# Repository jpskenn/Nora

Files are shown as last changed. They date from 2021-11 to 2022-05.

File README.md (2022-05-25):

# Nora（ノラ）

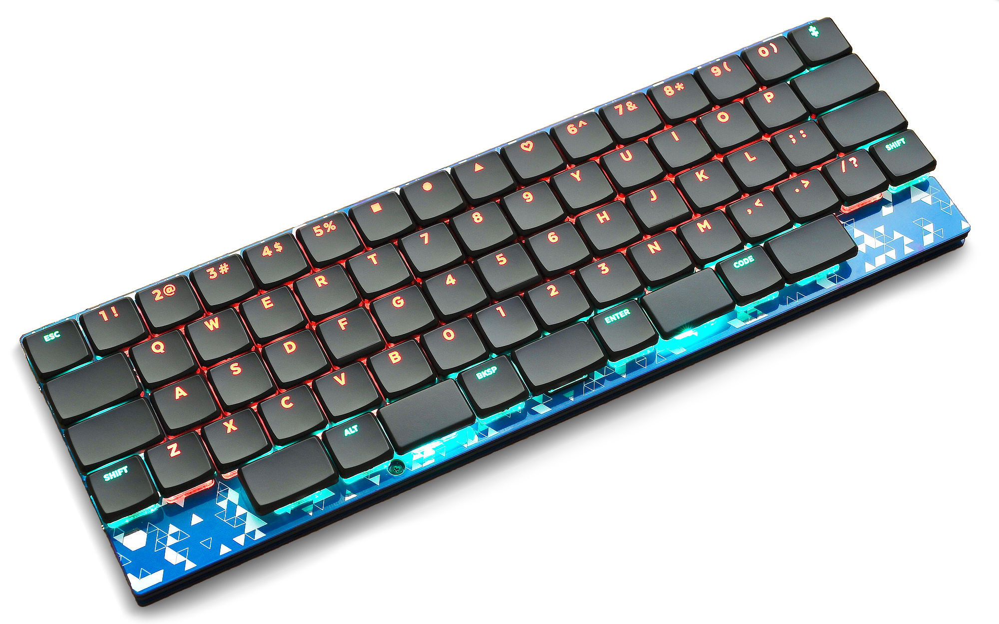
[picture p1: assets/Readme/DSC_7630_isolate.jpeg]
Nora Keyboard


Nora（ノラ）は、Choc v1 ロープロファイルスイッチを使用する、狭ピッチの一体型キーボードです。  
姉妹機[Jones（ジョーンズ）](https://github.com/jpskenn/Jones)と同様の、2行目と3行目にずれのない左右対称の配列が特徴です。  
専用のボトムプレートや、GH60型，Poker型のロープロファイルケースと組み合わせて使用できます。

名前の由来は、”狭ピッチのJonesキーボード”からの連想で…

``` text
狭ピッチのJones → ナロー・ジョーンズ → ノラ・ジョーンズ → ノラ

Narrow Jones --> Norah Jones --> Norah --> Nora
```

という具合の言葉遊びで、Nora（ノラ）に決まりました。

Nora is a narrow pitch keyboard with Choc v1 low profile switches.  
It has symmetrical gapless R2-R3 row, like [Jones](https://github.com/jpskenn/Jones).  
Original bottom plate and GH60/Poker compatible low profile cases are supported.

---

<!-- @import "[TOC]" {cmd="toc" depthFrom=2 depthTo=2 orderedList=false} -->

<!-- code_chunk_output -->

- [対象とするユーザー](#対象とするユーザー)
- [コンセプト](#コンセプト)
- [特徴](#特徴)
- [機能](#機能)
- [ビルドガイド](#ビルドガイド)
- [ビルド例](#ビルド例)
- [製作歴](#製作歴)

<!-- /code_chunk_output -->

---

## 対象とするユーザー

このNoraキーボードは、  
*”一般的なキーボードのキー配列に不満があり、より良いタイピングポジションを求めている方”*  
を対象に作られています。

特に、  
*”一般的なキーボードと違いすぎないキーボードを求めている方”*  
におすすめします。

## コンセプト

- 「Chocスイッチの狭ピッチを60%ケースに入れたら、1列増えて65%キーボードができちゃうのでは？」という思いつき。
- 一般的なキーピッチの19.05mmで打鍵がつらいのを、狭ピッチで楽にしたい。
- 「狭ピッチは浅いストロークの方が打鍵しやすい」という経験から、Chocスイッチを採用。
- MBKキーキャップって格好良いじゃんか。
- Jonesの横方向（行方向）のずれかたや、左右対称のアルファ部に満足している。
- 一般的なキーボードのレイアウトから大きく変えずに、打鍵しやすくする。
- キー数は60%くらいで、数字行がついているものが使いたい。
- GH60型のケースに対応させ、ケース設計をメイン作業に含めない。
- これくらいの狭ピッチなら、通常のキーボードと何ら変わらず打鍵できることを伝えたい。

## 特徴

### 狭ピッチ

Kailh Chocスイッチとそれに対応するキーキャップを使用することで、一般的なキーボードよりもキーピッチが狭くなっています。

60%キーボードのサイズに16列を配置するため、Choc用キーキャップのキーピッチ（たて17mm×よこ18mm）よりも横方向を少し狭く（たて17mm×よこ約17.86mm）しています。  
横方向のキーピッチは、MBKまたはそれ以下のサイズのChoc用キーキャップの使用を前提とした設計です。

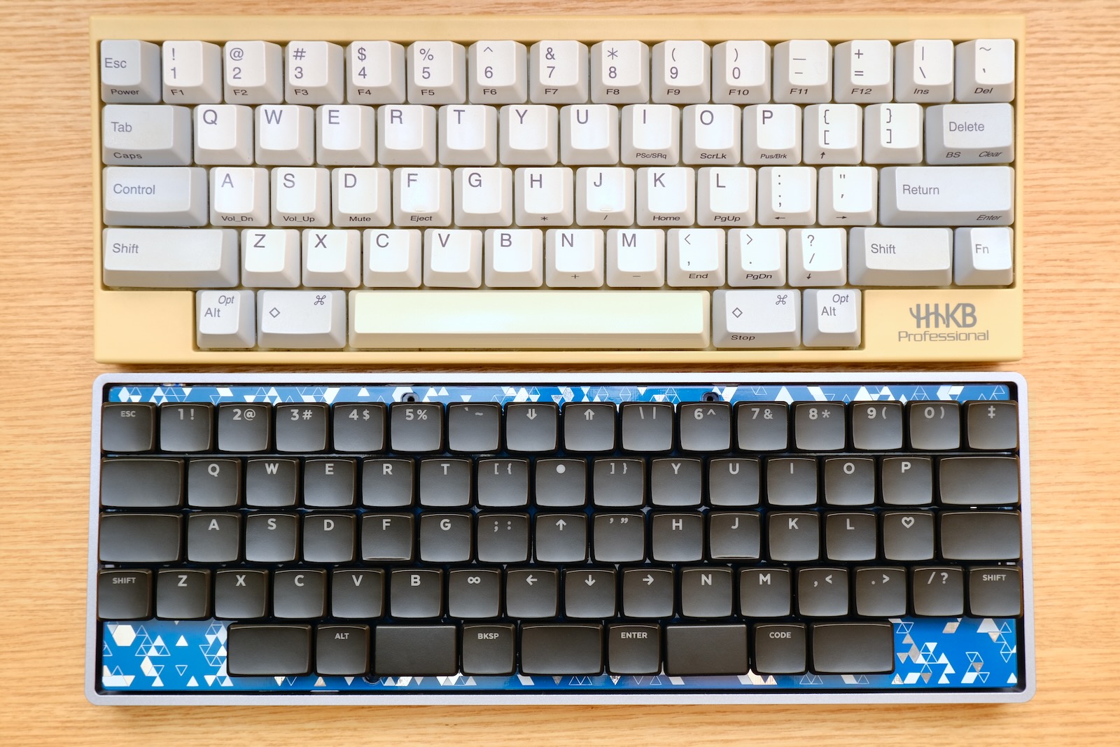
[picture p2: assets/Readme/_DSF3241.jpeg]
Comparison of key pitch
  
キーピッチの比較  
上：一般的なキーピッチの60%キーボード、HHKB Professional。5行15列。  
下：狭ピッチ設計のNora。5行**16列**（1列多い）。

### 左右対称のキーレイアウト

キーレイアウトは[Jones](https://github.com/jpskenn/Jones)のレイアウトを元に設計しており、2行目と3行目にずれのない左右対称のキーレイアウトです。  

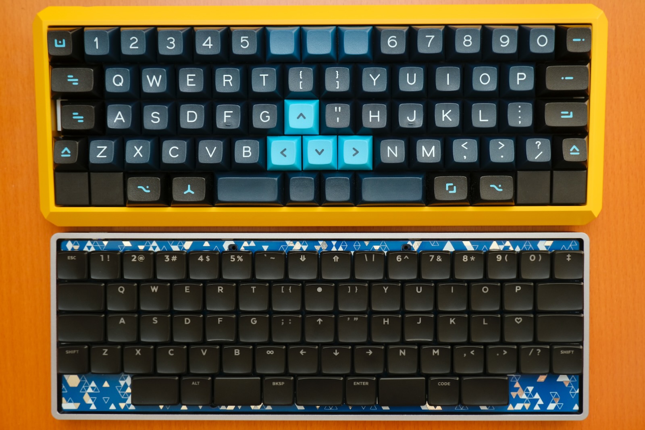
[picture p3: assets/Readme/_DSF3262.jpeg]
gapless R2-R3 row
  
Jones（上）とNora（下）。  
どちらも2行目と3行目にずれがなく、左右対称。

詳しくは次の項目を参照してください。

- [Jones#独自のずれ幅をもつ左右対象のアルファ部](https://github.com/jpskenn/Jones#独自のずれ幅をもつ左右対象のアルファ部)

### レイアウトのスタイル、バリエーション

狭ピッチの一体型キーボードというコンセプトを元に、ふたつのレイアウトスタイルを作成しました。

- Nora, Fearless Wings
- Nora, 1.8k

各スタイルの特徴は以下の通りです。

#### Nora, Fearless Wings

左右に大きく離れたアルファ部が特徴のレイアウトスタイルです。  
[Keyboard Layout Editor: Nora, Fearless Wings family](http://www.keyboard-layout-editor.com/#/gists/568990362f215776aa93e3b90064f241)

アルファ部を左右へ大きく離すことで打鍵時の肘・腕・手首・指先の位置を最適化し、快適な運指と、肩や腕への負担軽減を目指しています。  
手首をあまり持ち上げないスタイルでも快適に打鍵できるように、最下行の左右の端にはキーを配置せず、手のひらにキーが当たる不快感を無くしています。  
`Z`キーを外側へずらして、[SemiErgo](https://github.com/mtei/SemiErgo_Layout)のような完全に左右対称のレイアウトも構成できます。

キー配置とロータリーエンコーダの有無により、3つのバリエーションがあります。

- Fullレイアウト

    左右に離れたアルファ部の間を、すべて埋めたレイアウトです。  
    65〜70%キーボードに相当する71個のキーは、多くのキーを必要とする方に適しています。  
    中央部に記号キーやカーソルを配置したり、テンキーやマクロキーを配置したりできます。

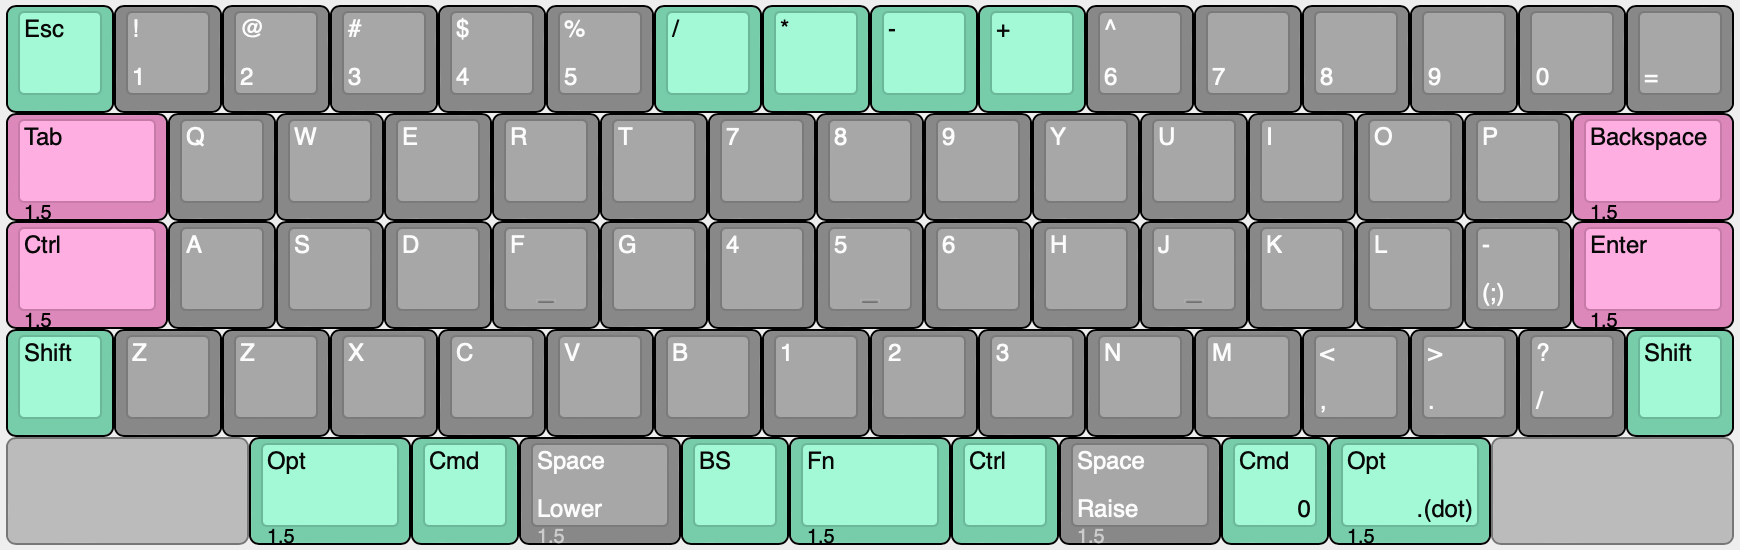
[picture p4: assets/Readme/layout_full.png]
Layout, Nora, Full
    

- FWレイアウト

    Fullレイアウトから中央部の7キーを取り除き、真ん中に隙間のあるレイアウトです。  
    60%キーボードに相当する64キーをもち、必要十分なキー数を確保しています。  
    ホームポジションから手を移動させず、レイヤー内のキーを打鍵するのが快適な方に適しています。  

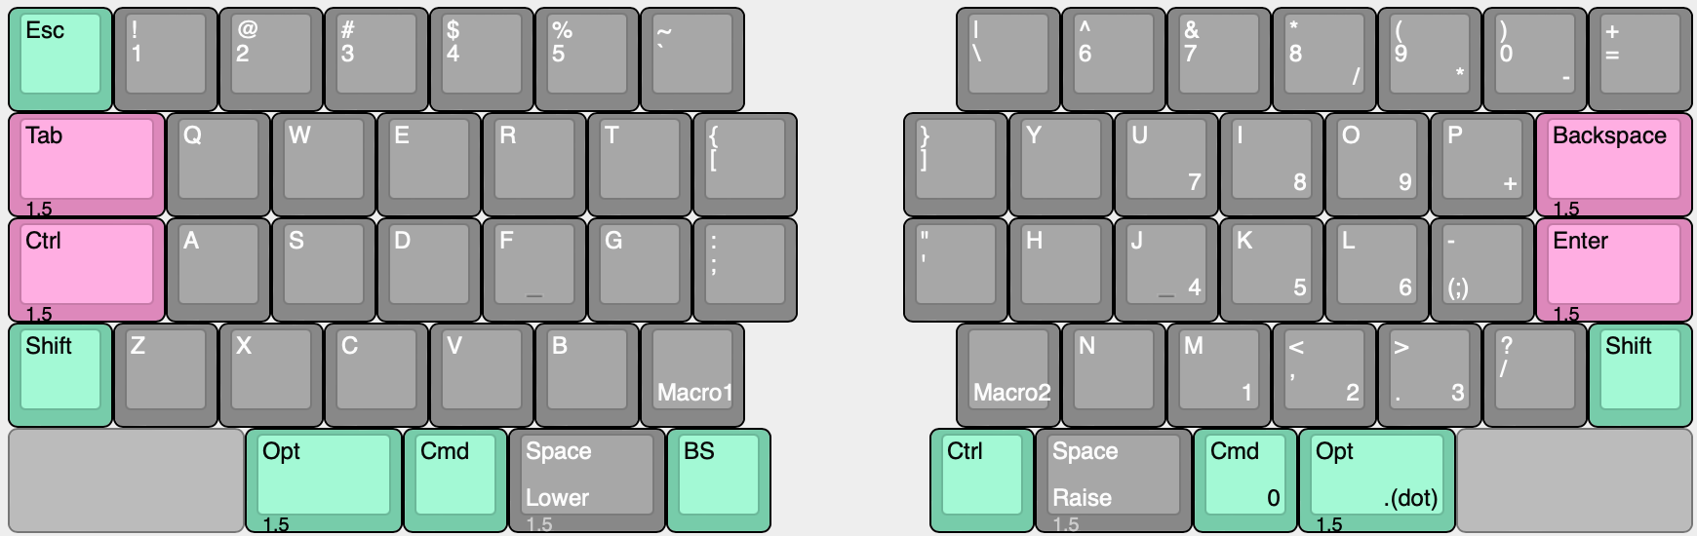
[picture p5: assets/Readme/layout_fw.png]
Layout, Nora, FW
    

- REレイアウト

    FWレイアウトの中央にロータリーエンコーダを配置したレイアウトです。  
    4行目の中央をFWレイアウトから2キー減らし、直径35ｍｍまでのノブに対応しています。

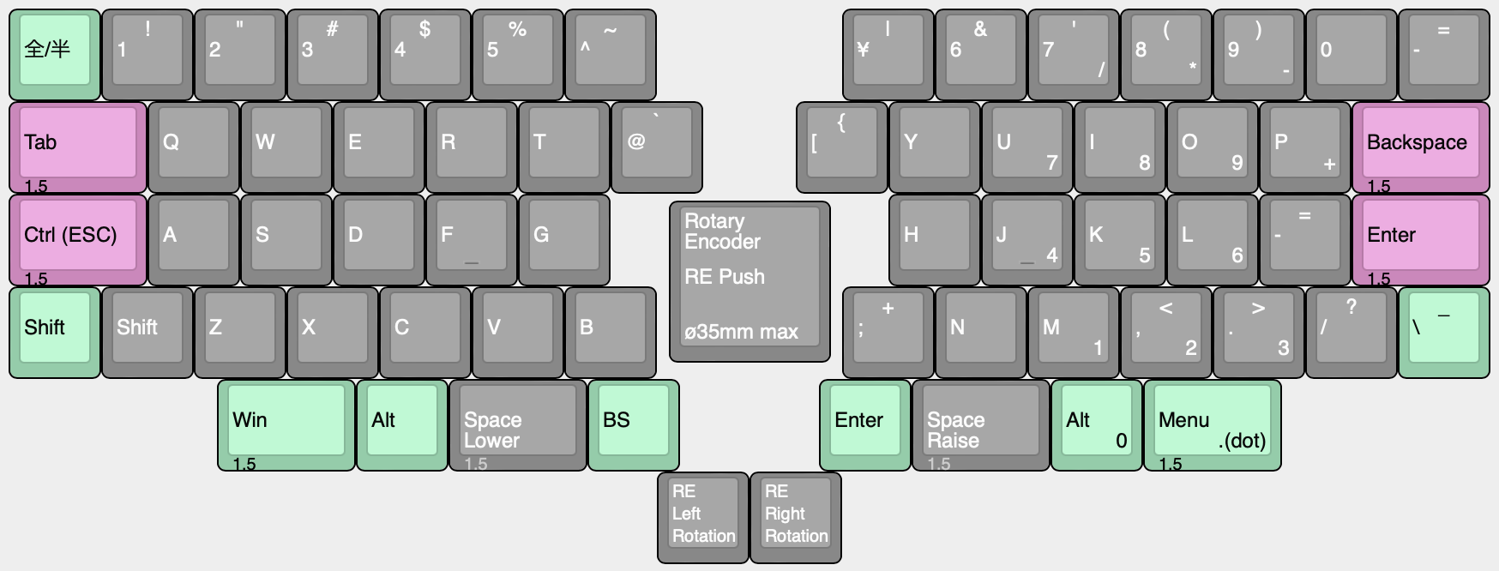
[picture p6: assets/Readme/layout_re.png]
Layout, Nora, RE
    

#### Nora, 1.8k

アルファ部の右側にテンキーを配置し、少し下へ飛びだしたカーソルキーが特徴のレイアウトスタイルです。  
[Keyboard Layout Editor: Nora](http://www.keyboard-layout-editor.com/#/gists/f8d08df6aa77dcdd6d3cb7350a545df7)

一般的なキーボードをコンパクトにまとめたようなキー配置になっています。  
キー数が多く、記号やカーソルなどを物理的に配置することができます。

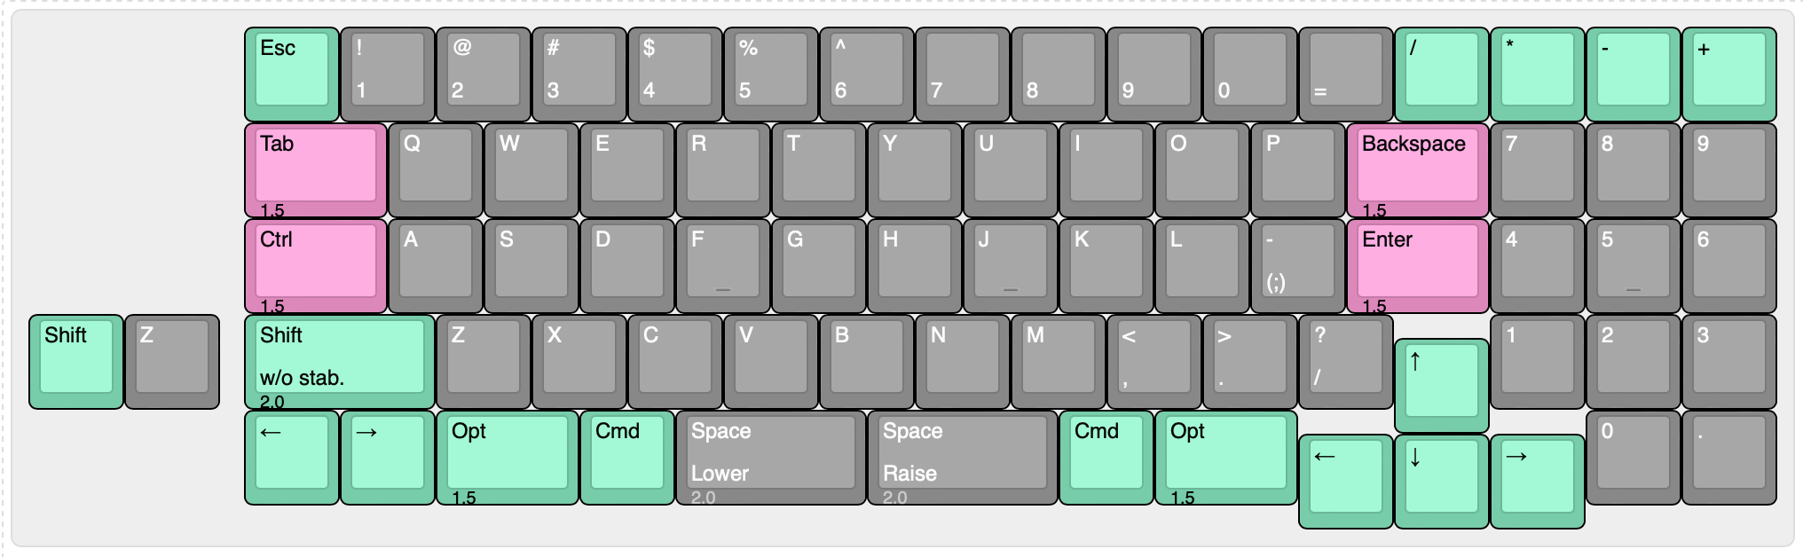
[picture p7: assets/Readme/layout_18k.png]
Layout, Nora, 1.8k


試作版でロードテストをおこなった結果、狭ピッチで左右の手が中央へ近づいて肩や腕、親指まわりが窮屈になり、長時間の使用には向かないことがわかりました。  
日常的に使用する上での快適さを満たせないため、1.8kは開発を停止しています。

## 機能

### QMKファームウェアによる動作

MCUにATmega32u4を採用し、[QMKファームウェア](https://github.com/qmk/qmk_firmware)によって動作します。

### RemapやVIAなどのキーマップ書き換えツールに対応

[Remap](https://remap-keys.app)や[VIA](https://caniusevia.com)などのキーマップ書き換えツールに対応しており、ファームウェアを書き換えることなく、キーの割り当てを変更することができます。  

### EEPROM搭載により、多くのレイヤーを使用可能

外部EEPROMを搭載したことで、RemapやVIA使用時にも多くのレイヤーを使用することができます。  
出荷時に書き込まれている初期ファームウェアでは、10個のレイヤーを使用可能です。  

### ケース

キット同梱のボトムプレートと組み合わせれば、ケースレスで使用できます。  
ケースを使用する場合に比べてキーボードの高さを低く抑えることができ、手首の負担軽減などに有効です。

また、GH60型やPoker型に互換性のある、ロープロファイルケースと組み合わせて使用することもできます。  
→[ビルド例](#ビルド例)  

### フルキーバックライトLED

レイヤーの状態を表示するインジケータや、イルミネーションとして使用できるキーバックライトLEDを、すべてのキーへ取り付けできます。

### Raspberry Pi PICOによる動作（実験的機能）

実験的機能として、Raspberry Pi PICOで動作させることができます。  
キーマトリクス、LED、I2Cに配線をつないであるので、DIYで楽しんでください。

[PRK Firmware](https://github.com/picoruby/prk_firmware)を使用して、キー入力とLEDの点灯を確認済みです。

## ビルドガイド

- 最新版
  - [Nora, Fearless Wings v.1(DN0032) ビルドガイド](./docs/BuildGuide_DN0032_JA.md)

- 過去版
  - [Nora, Fearless Wings DN0031 ビルドガイド](./docs/BuildGuide_DN0031_JA.md)
  - [Nora, Fearless Wings DN0030 ビルドガイド](./docs/BuildGuide_DN0030_JA.md)
  - [Nora, 1.8k v.0.1 ビルドガイド](./docs/BuildGuide_v.0.1_JA.md)

</details>

## ビルド例

| ビルド例 | 詳細 |
| --- | :-- |
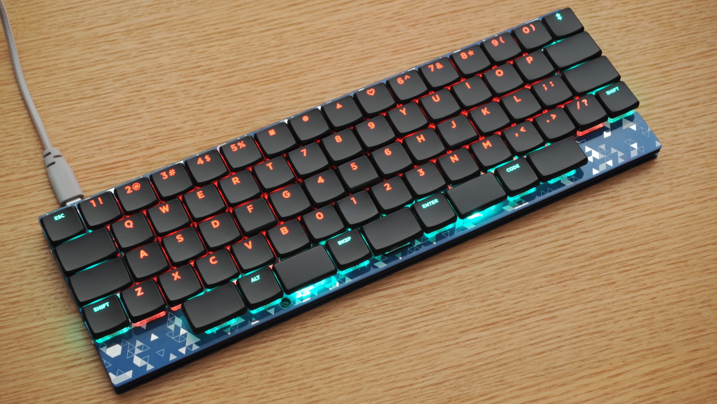
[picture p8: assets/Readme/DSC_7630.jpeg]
| [](./assets/Readme/DSC_7630.jpeg) | v.1(DN0032)<br>layout: Full<br>keycaps: MBK Legend‡ Glow<br>case: Bottom plate |
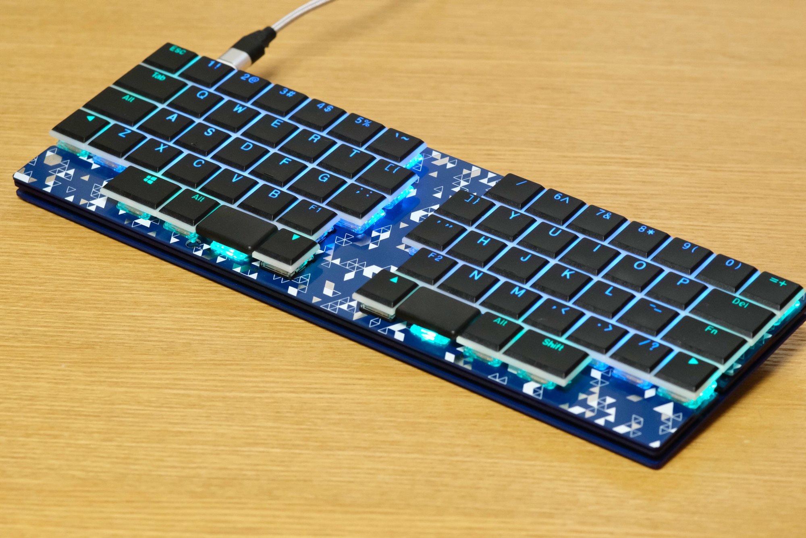
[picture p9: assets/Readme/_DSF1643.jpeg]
| [](./assets/Readme/_DSF1643.jpeg) | DN0031<br>layout: FW<br>keycaps: Kailh low profile + MBK<br>case: Bottom plate |
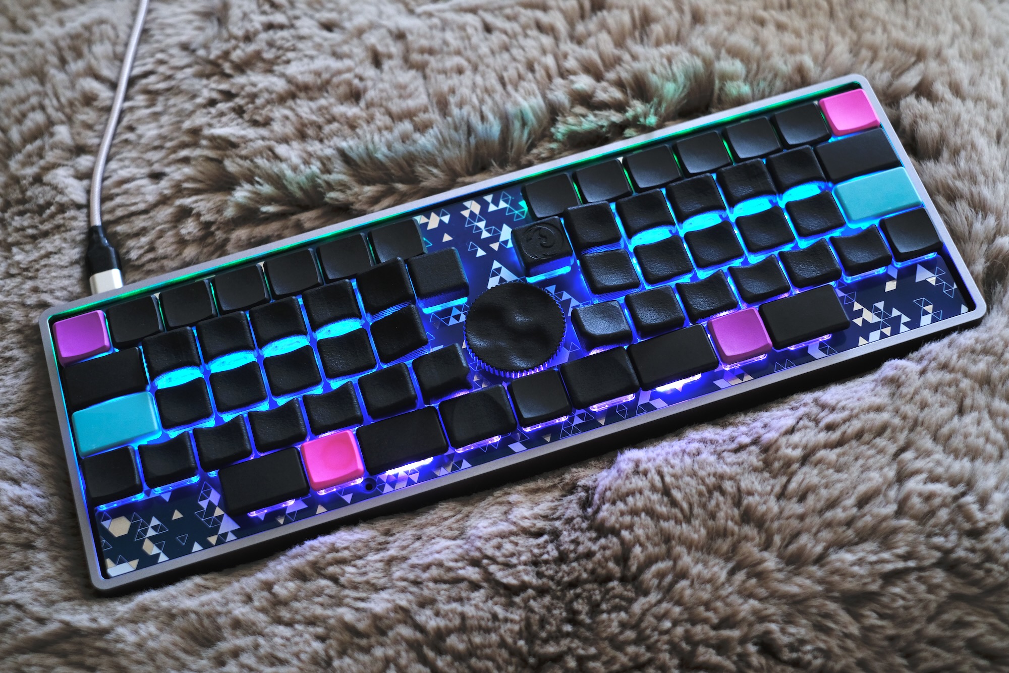
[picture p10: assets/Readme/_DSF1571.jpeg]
| [](./assets/Readme/_DSF1571.jpeg) | DN0031<br>layout: RE<br>keycaps: Gravity Keycaps + MBK<br>case: KBDfans 60% Aluminum Low Profile, Gray |
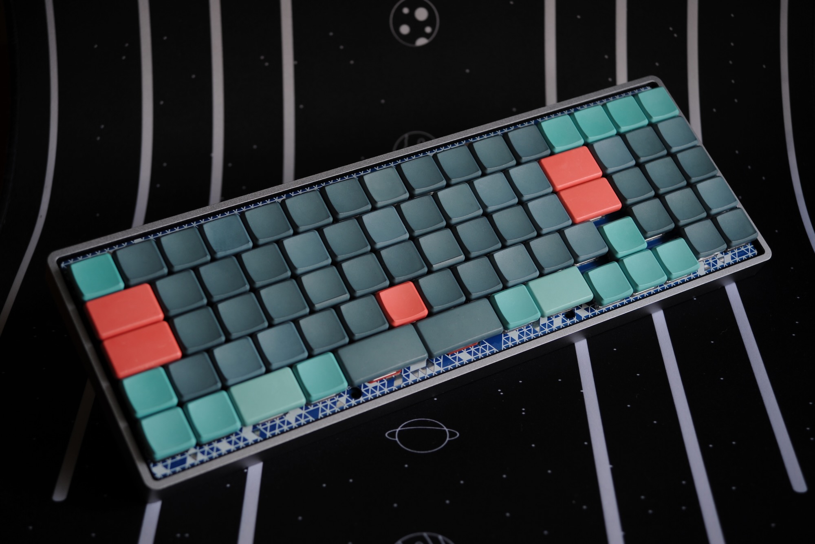
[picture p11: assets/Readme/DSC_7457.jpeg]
| [](./assets/Readme/DSC_7457.jpeg) | DN0020<br>layout: 1.8k<br>keycaps: MBK Colors & Self Dye<br>case: KBDfans 60% Aluminum Low Profile, Gray |
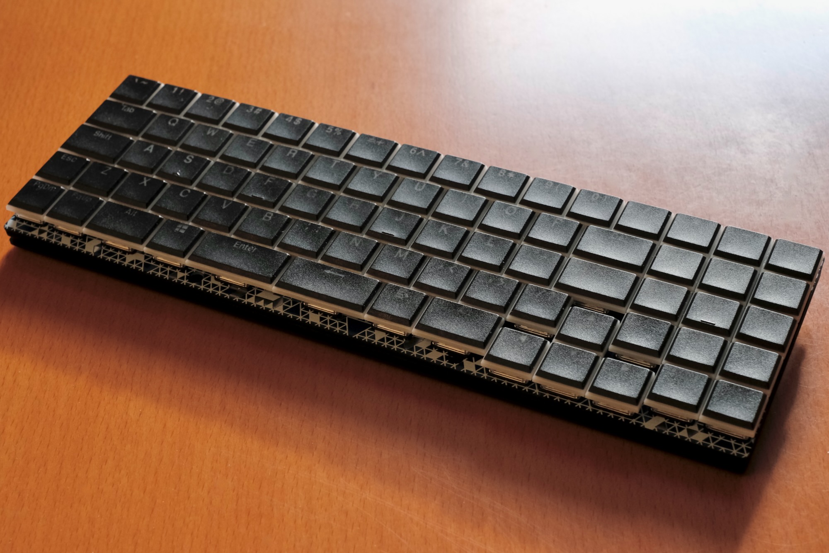
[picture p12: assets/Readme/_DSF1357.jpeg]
| [](./assets/Readme/_DSF1357.jpeg) | DN0010<br>layout: 1.8k<br>keycaps: Kailh low profile<br>case: Bottom plate |

## 製作歴

- Fearless Wings v.1(DN0032), 2022年3月中旬

    組み立てやすさを向上。  
    ロータリーエンコーダのノブサイズ拡大のため、REレイアウトの最下行中央のキーを削除。  
    細部を調整。  
    DN0031組み立てアンケートの内容を反映。

- Fearless Wings DN0031, 2022年1月下旬

    スペースキーより内側のキーに親指が届きやすいように、最下行を外側へ0.25u移動。  
    ロータリーエンコーダ付きのレイアウトを追加。  
    組み立てやすさを向上。
    少数頒布。

- Fearless Wings DN0030, 2022年1月上旬

    DN0020を元にレイアウトを変更。  
    全キーへLEDを配置。  
    Jonesとの共用ボトムプレートを、PICOの取り付けに対応する切り欠きをつけて更新。

- 1.8k DN0020, 2021年12月中旬

    1.8k v.0.1の試作結果を反映。  
    全キーをKailhソケットに変更。  
    現在のところ基板設計のみ。未製造。

- 1.8k v.0.1, 2021年12月上旬

    試作1号機、完成。

- 1.8k v.0, 2021年11月上旬

    60%ケースにChocスイッチを配置して、65%キーボードにするアイデアを思いつく。

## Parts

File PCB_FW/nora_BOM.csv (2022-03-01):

Comment | Designator | Footprint | LCSC
10uF | C1 | Capacitor_SMD:C_0805_2012Metric_Pad1.18x1.45mm_HandSolder | C15850
22pF | C2,C3 | Capacitor_SMD:C_0805_2012Metric_Pad1.18x1.45mm_HandSolder | C1804
0.1uF | C4,C5,C7 | Capacitor_SMD:C_0805_2012Metric_Pad1.18x1.45mm_HandSolder | C49678
1uF | C6 | Capacitor_SMD:C_0805_2012Metric_Pad1.18x1.45mm_HandSolder | C28323
D_Small | D1,D2,D4,D5,D6,D7,D9,D11,D12,D13,D14,D15,D16,D17,D18,D19,D20,D21,D22,D23,D25,D26,D27,D28,D29,D30,D31,D32,D33,D35,D36,D37,D38,D39,D40,D41,D42,D43,D44,D45,D46,D47,D48,D49,D50,D51,D52,D53,D54,D55,D56,D57,D58,D59,D60,D61,D62,D63,D64,D65,D66,D67,D68,D70,D71,D72,D73,D75,D76,D77,D78,D99 | locallib:D_SOD-123-Pretty_No_Reference | C81598
PRTR5V0U2X | D10 | Package_TO_SOT_SMD:SOT-143 | C12333
Conn_01x01 | EXT_C0,EXT_R0,EXT_C1,EXT_R1,EXT_C2,EXT_R2,EXT_C3,EXT_R3,EXT_C4,EXT_R4,EXT_C5,EXT_R5,EXT_C6,EXT_R6,EXT_C7,EXT_R7,EXT_R8,EXT_R9 | TestPoint:TestPoint_THTPad_D1.5mm_Drill0.7mm
Conn_01x01 | Ext_AUDIO_PC6 | TestPoint:TestPoint_THTPad_D1.0mm_Drill0.5mm
500mA | F1 | Fuse:Fuse_1206_3216Metric_Pad1.42x1.75mm_HandSolder | C70076
MountingHole | H1,H2,H3 | MountingHole:MountingHole_2.2mm_M2
USB_C_Receptacle_USB2.0 | J1 | Connector_USB:USB_C_Receptacle_GCT_USB4085
Conn_01x04 | J2 | Connector_PinHeader_2.54mm:PinHeader_1x04_P2.54mm_Vertical
Conn_01x02 | J3,J4 | Connector_PinHeader_2.54mm:PinHeader_1x02_P2.54mm_Vertical
Conn_02x03_Odd_Even | J5 | Connector_PinHeader_2.54mm:PinHeader_2x03_P2.54mm_Vertical
SolderJumper_2_Open | JP1,JP2,JP4,JP5,JP6,JP7,JP8,JP9 | Jumper:SolderJumper-2_P1.3mm_Open_RoundedPad1.0x1.5mm
SolderJumper_3_Open | JP3 | Jumper:SolderJumper-3_P1.3mm_Open_RoundedPad1.0x1.5mm
SK6812MINI-E | L1,L2,L3,L4,L5,L6,L7,L10,L11,L12,L13,L14,L15,L16,L17,L18,L19,L20,L21,L22,L23,L25,L26,L27,L28,L29,L30,L31,L32,L33,L34,L35,L36,L37,L41,L42,L43,L44,L45,L46,L47,L48,L49,L50,L51,L52,L53,L56,L57,L58,L59,L60,L61,L62,L63,L64,L65,L66,L68,L69,L70,L71 | Jones.local:YS-SK6812MINI-E_middle_hole_with_small_pad
SK6812MINI-E | L8,L9,L24,L38,L39,L40,L54,L55,L67 | Jones.local:YS-SK6812MINI-E_middle_hole_with_small_pad_reserved
Speaker | LS1 | Buzzer_Beeper:Buzzer_Murata_PKMCS0909E4000-R1
5.1k | R1,R2 | Resistor_SMD:R_0805_2012Metric_Pad1.20x1.40mm_HandSolder | C27834
22 | R3,R4 | Resistor_SMD:R_0805_2012Metric_Pad1.20x1.40mm_HandSolder | C17561
10k | R5,R6 | Resistor_SMD:R_0805_2012Metric_Pad1.20x1.40mm_HandSolder | C17414
1k | R7 | Resistor_SMD:R_0805_2012Metric_Pad1.20x1.40mm_HandSolder | C17513
4.7k | R8,R9 | Resistor_SMD:R_0805_2012Metric_Pad1.20x1.40mm_HandSolder | C17673
RotaryEncoder_Switch | RE_42 | Rotary_Encoder:RotaryEncoder_Alps_EC11E-Switch_Vertical_H20mm
5.2x5.2mm | ResetSW1 | Button_Switch_SMD:SW_SPST_TL3342
ESC | SW_1 | Keebio-Parts:Kailh-PG1350-1u-MBK-WithKeyName-Socket-ForLeftEdge-1.8mm-hole-reflection
2 | SW_10 | Keebio-Parts:Kailh-PG1350-1u-MBK-WithKeyName-Socket-1.8mm-hole-reflection
Q | SW_11 | Keebio-Parts:Kailh-PG1350-1u-MBK-WithKeyName-Socket-1.8mm-hole-reflection
A | SW_12 | Keebio-Parts:Kailh-PG1350-1u-MBK-WithKeyName-Socket-1.8mm-hole-reflection
X | SW_13 | Keebio-Parts:Kailh-PG1350-1u-MBK-WithKeyName-Socket-1.8mm-hole-reflection
3 | SW_15 | Keebio-Parts:Kailh-PG1350-1u-MBK-WithKeyName-Socket-1.8mm-hole-reflection
W | SW_16 | Keebio-Parts:Kailh-PG1350-1u-MBK-WithKeyName-Socket-1.8mm-hole-reflection
S | SW_17 | Keebio-Parts:Kailh-PG1350-1u-MBK-WithKeyName-Socket-1.8mm-hole-reflection
C | SW_18 | Keebio-Parts:Kailh-PG1350-1u-MBK-WithKeyName-Socket-1.8mm-hole-reflection
LGUI 1.5u | SW_19 | Keebio-Parts:Kailh-PG1350-1.5u-MBK-WithKeyName-Socket-1.8mm-hole-reflection
4 | SW_20 | Keebio-Parts:Kailh-PG1350-1u-MBK-WithKeyName-Socket-1.8mm-hole-reflection
E | SW_21 | Keebio-Parts:Kailh-PG1350-1u-MBK-WithKeyName-Socket-1.8mm-hole-reflection
D | SW_22 | Keebio-Parts:Kailh-PG1350-1u-MBK-WithKeyName-Socket-1.8mm-hole-reflection
V | SW_23 | Keebio-Parts:Kailh-PG1350-1u-MBK-WithKeyName-Socket-1.8mm-hole-reflection
LALT | SW_24 | Keebio-Parts:Kailh-PG1350-1u-MBK-WithKeyName-Socket-1.8mm-hole-reflection
5 | SW_25 | Keebio-Parts:Kailh-PG1350-1u-MBK-WithKeyName-Socket-1.8mm-hole-reflection
R | SW_26 | Keebio-Parts:Kailh-PG1350-1u-MBK-WithKeyName-Socket-1.8mm-hole-reflection
F | SW_27 | Keebio-Parts:Kailh-PG1350-1u-MBK-WithKeyName-Socket-1.8mm-hole-reflection
B | SW_28 | Keebio-Parts:Kailh-PG1350-1u-MBK-WithKeyName-Socket-1.8mm-hole-reflection
LSPC 1.5u | SW_29 | Keebio-Parts:Kailh-PG1350-1.5u-MBK-WithKeyName-Socket-1.8mm-hole-reflection
LSFT | SW_3 | Keebio-Parts:Kailh-PG1350-1u-MBK-WithKeyName-Socket-ForLeftEdge-1.8mm-hole-reflection
`~ | SW_30 | Keebio-Parts:Kailh-PG1350-1u-MBK-WithKeyName-Socket-1.8mm-hole-reflection
T | SW_31 | Keebio-Parts:Kailh-PG1350-1u-MBK-WithKeyName-Socket-1.8mm-hole-reflection
G | SW_32 | Keebio-Parts:Kailh-PG1350-1u-MBK-WithKeyName-Socket-1.8mm-hole-reflection
L-Macro | SW_33 | Keebio-Parts:Kailh-PG1350-1u-MBK-WithKeyName-Socket-1.8mm-hole-reflection
R1L | SW_35 | Keebio-Parts:Kailh-PG1350-1u-MBK-WithKeyName-Socket-1.8mm-hole-reflection-frame-only
[{ | SW_36 | Keebio-Parts:Kailh-PG1350-1u-MBK-WithKeyName-Socket-1.8mm-hole-reflection
;: | SW_37 | Keebio-Parts:Kailh-PG1350-1u-MBK-WithKeyName-Socket-1.8mm-hole-reflection-cross-paint
R4L | SW_38 | Keebio-Parts:Kailh-PG1350-1u-MBK-WithKeyName-Socket-1.8mm-hole-reflection-frame-only
Center L | SW_39 | Keebio-Parts:Kailh-PG1350-1u-MBK-WithKeyName-Socket-1.8mm-hole-reflection
R1R | SW_40 | Keebio-Parts:Kailh-PG1350-1u-MBK-WithKeyName-Socket-1.8mm-hole-reflection-frame-only
R2C | SW_41 | Keebio-Parts:Kailh-PG1350-1u-MBK-WithKeyName-Socket-1.8mm-hole-reflection-frame-only
R3C | SW_42 | Keebio-Parts:Kailh-PG1350-1u-MBK-WithKeyName-Socket-1.8mm-hole-reflection-frame-only
R4R | SW_43 | Keebio-Parts:Kailh-PG1350-1u-MBK-WithKeyName-Socket-1.8mm-hole-reflection-frame-only
Center 1.5u | SW_44 | Keebio-Parts:Kailh-PG1350-1.5u-MBK-WithKeyName-Socket-1.8mm-hole-reflection-frame-only
\| | SW_45 | Keebio-Parts:Kailh-PG1350-1u-MBK-WithKeyName-Socket-1.8mm-hole-reflection
]} | SW_46 | Keebio-Parts:Kailh-PG1350-1u-MBK-WithKeyName-Socket-1.8mm-hole-reflection
'",SW_47" | Keebio-Parts:Kailh-PG1350-1u-MBK-WithKeyName-Socket-1.8mm-hole-reflection-cross-paint
R-Macro | SW_48 | Keebio-Parts:Kailh-PG1350-1u-MBK-WithKeyName-Socket-1.8mm-hole-reflection
Center R | SW_49 | Keebio-Parts:Kailh-PG1350-1u-MBK-WithKeyName-Socket-1.8mm-hole-reflection
1 | SW_5 | Keebio-Parts:Kailh-PG1350-1u-MBK-WithKeyName-Socket-1.8mm-hole-reflection
6 | SW_50 | Keebio-Parts:Kailh-PG1350-1u-MBK-WithKeyName-Socket-1.8mm-hole-reflection
Y | SW_51 | Keebio-Parts:Kailh-PG1350-1u-MBK-WithKeyName-Socket-1.8mm-hole-reflection
H | SW_52 | Keebio-Parts:Kailh-PG1350-1u-MBK-WithKeyName-Socket-1.8mm-hole-reflection
N | SW_53 | Keebio-Parts:Kailh-PG1350-1u-MBK-WithKeyName-Socket-1.8mm-hole-reflection
RSPC 1.5u | SW_54 | Keebio-Parts:Kailh-PG1350-1.5u-MBK-WithKeyName-Socket-1.8mm-hole-reflection
7 | SW_55 | Keebio-Parts:Kailh-PG1350-1u-MBK-WithKeyName-Socket-1.8mm-hole-reflection
U | SW_56 | Keebio-Parts:Kailh-PG1350-1u-MBK-WithKeyName-Socket-1.8mm-hole-reflection
J | SW_57 | Keebio-Parts:Kailh-PG1350-1u-MBK-WithKeyName-Socket-1.8mm-hole-reflection
M | SW_58 | Keebio-Parts:Kailh-PG1350-1u-MBK-WithKeyName-Socket-1.8mm-hole-reflection
RALT | SW_59 | Keebio-Parts:Kailh-PG1350-1u-MBK-WithKeyName-Socket-1.8mm-hole-reflection
TAB 1.5u | SW_6 | Keebio-Parts:Kailh-PG1350-1.5u-MBK-WithKeyName-Socket-1.8mm-hole-reflection
8 | SW_60 | Keebio-Parts:Kailh-PG1350-1u-MBK-WithKeyName-Socket-1.8mm-hole-reflection
I | SW_61 | Keebio-Parts:Kailh-PG1350-1u-MBK-WithKeyName-Socket-1.8mm-hole-reflection
K | SW_62 | Keebio-Parts:Kailh-PG1350-1u-MBK-WithKeyName-Socket-1.8mm-hole-reflection
< | SW_63 | Keebio-Parts:Kailh-PG1350-1u-MBK-WithKeyName-Socket-1.8mm-hole-reflection
RGUI 1.5u | SW_64 | Keebio-Parts:Kailh-PG1350-1.5u-MBK-WithKeyName-Socket-1.8mm-hole-reflection
9 | SW_65 | Keebio-Parts:Kailh-PG1350-1u-MBK-WithKeyName-Socket-1.8mm-hole-reflection
O | SW_66 | Keebio-Parts:Kailh-PG1350-1u-MBK-WithKeyName-Socket-1.8mm-hole-reflection
L | SW_67 | Keebio-Parts:Kailh-PG1350-1u-MBK-WithKeyName-Socket-1.8mm-hole-reflection
> | SW_68 | Keebio-Parts:Kailh-PG1350-1u-MBK-WithKeyName-Socket-1.8mm-hole-reflection
LCTL 1.5u | SW_7 | Keebio-Parts:Kailh-PG1350-1.5u-MBK-WithKeyName-Socket-1.8mm-hole-reflection
0 | SW_70 | Keebio-Parts:Kailh-PG1350-1u-MBK-WithKeyName-Socket-1.8mm-hole-reflection
P | SW_71 | Keebio-Parts:Kailh-PG1350-1u-MBK-WithKeyName-Socket-1.8mm-hole-reflection
- | SW_72 | Keebio-Parts:Kailh-PG1350-1u-MBK-WithKeyName-Socket-1.8mm-hole-reflection
/ | SW_73 | Keebio-Parts:Kailh-PG1350-1u-MBK-WithKeyName-Socket-1.8mm-hole-reflection
= | SW_75 | Keebio-Parts:Kailh-PG1350-1u-MBK-WithKeyName-Socket-1.8mm-hole-reflection
BS 1.5u | SW_76 | Keebio-Parts:Kailh-PG1350-1.5u-MBK-WithKeyName-Socket-1.8mm-hole-reflection
Enter 1.5u | SW_77 | Keebio-Parts:Kailh-PG1350-1.5u-MBK-WithKeyName-Socket-1.8mm-hole-reflection
RSFT | SW_78 | Keebio-Parts:Kailh-PG1350-1u-MBK-WithKeyName-Socket-1.8mm-hole-reflection
Z | SW_8 | Keebio-Parts:Kailh-PG1350-1u-MBK-WithKeyName-Socket-1.8mm-hole-reflection
ATmega32U4-MU | U1 | Package_DFN_QFN:QFN-44-1EP_7x7mm_P0.5mm_EP5.15x5.15mm | C112161
24LC64 | U2 | Package_SO:SO-8_3.9x4.9mm_P1.27mm | C79988
Pico | U4 | MCU_RaspberryPi_and_Boards:RPi_Pico_TH_no_NPTH_SWD_less_Silk_NoCrtYd
16MHz | Y1 | Crystal:Crystal_SMD_3225-4Pin_3.2x2.5mm_HandSoldering | C13738

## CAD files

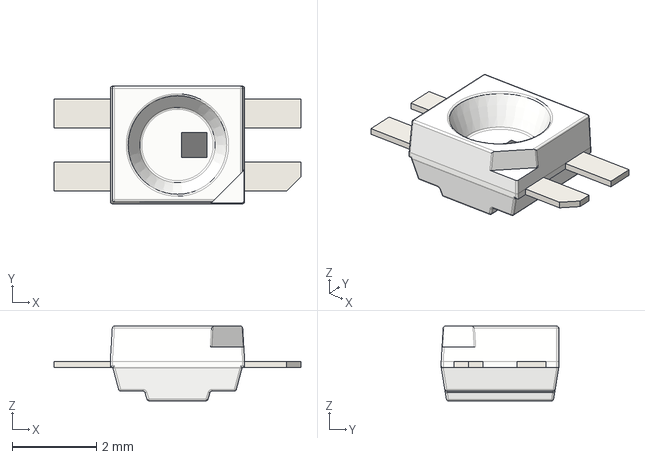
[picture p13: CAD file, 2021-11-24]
PCB_FW/lib_LED/LED_SK6812MINI-E.step
5.88 x 2.80 x 1.78 mm

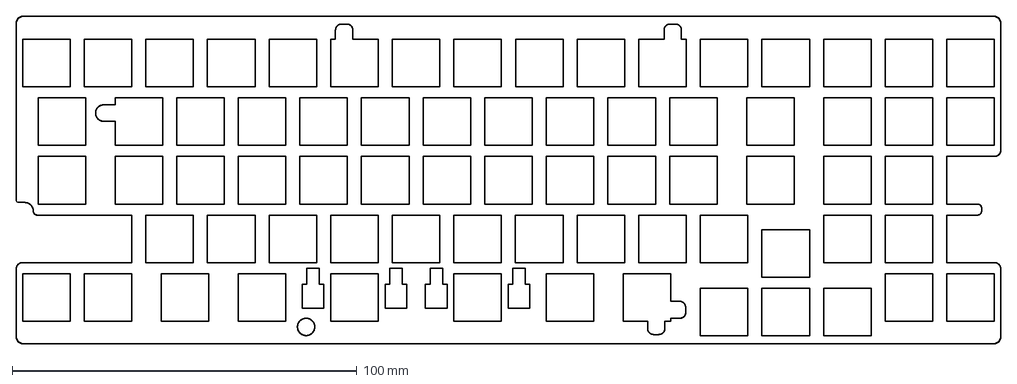
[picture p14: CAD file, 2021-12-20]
Plate/plate.dxf
285.4 x 94.9 mm

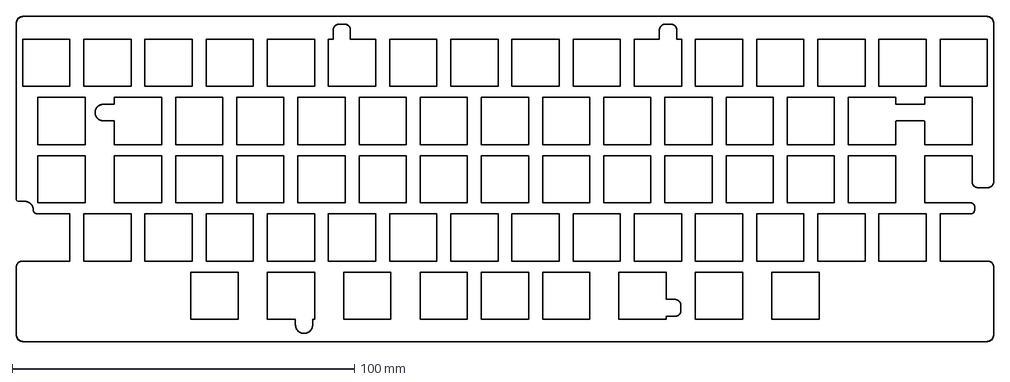
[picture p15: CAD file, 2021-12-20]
Plate_FW/plate.dxf
285.4 x 94.9 mm

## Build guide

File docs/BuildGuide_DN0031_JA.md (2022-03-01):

# ”Nora, Fearless Wings (DN0031) 試作版”ビルドガイド

購入していただいた方、リポジトリから製造していただいた方、その他の皆様、Noraに興味を持っていただきありがとうございます。

このドキュメントは、”Nora, Fearless Wings (DN0031) 試作版”を組み立てるためのビルドガイドです。  
以下に示す、ふたつレイアウトの組み立て方法について説明します。  
参考： [Nora, Kyboard Layout Editor](http://www.keyboard-layout-editor.com/#/gists/568990362f215776aa93e3b90064f241)

- `FWレイアウト`

  ロータリーエンコーダを配置せず、中央部分に隙間のあるレイアウト
  
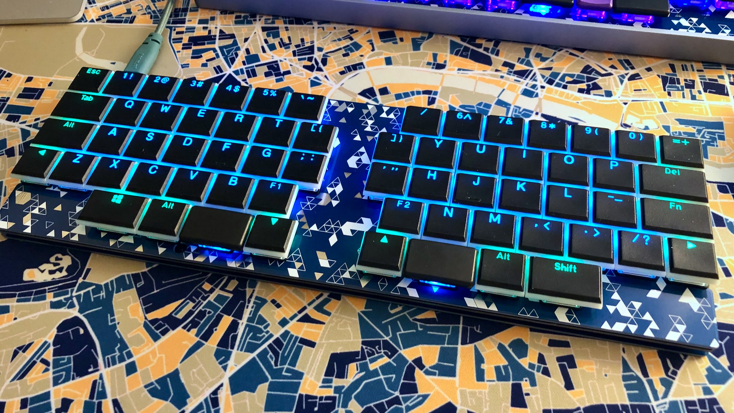
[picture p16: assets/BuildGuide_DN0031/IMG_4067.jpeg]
FWレイアウト
    
  Keycaps: Kailhロープロファイルキーキャップ  
  Case: 専用ボトムプレート

- `REレイアウト`

  中央にロータリーエンコーダを配置したレイアウト
  
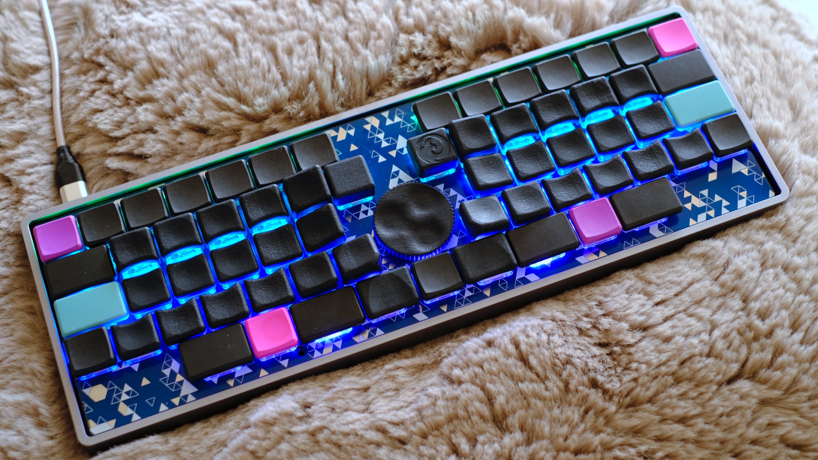
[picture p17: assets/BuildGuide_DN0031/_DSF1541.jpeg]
REレイアウト
    
  Keycaps: Gravity Keycaps + MBK  
  Case: KBDfans 60% ALUMINUM LOW PROFILE CASE, Gray  
  Rotary Encoder: ALPS EC12E2440301（貫通軸タイプ）  
  Knob: Daily Craft Keyboard ロープロ FLAT 33mm

Noraのコンセプトや特徴、ビルド例などについては、[README](https://github.com/jpskenn/Nora/blob/main/README.md)をご覧ください。

ビルドガイド全体に目を通して作業手順を把握しておくとミスの防止につながりますので、ぜひ、一度お読みになってから組み立て作業を始めてください。

作業手順をしっかりと確認しながら組み立てたい方は、

<details>
<summary>《詳しい説明》</summary>

ここに追加の説明を表示します。
</details>

と書かれたところをクリックすると、追加の説明が表示されます。

---

## 目次

<!-- @import "[TOC]" {cmd="toc" depthFrom=2 depthTo=3 orderedList=false} -->

<!-- code_chunk_output -->

- [目次](#目次)
- [Nora, Fearless Wings (DN0031)の特徴, 機能](#nora-fearless-wings-dn0031の特徴-機能)
- [注意事項、制限など](#注意事項-制限など)
- [試作版，試作版キットに関する注意事項](#試作版試作版キットに関する注意事項)
- [部品リスト](#部品リスト)
  - [キット内容](#キット内容)
  - [別途用意が必要な部品](#別途用意が必要な部品)
  - [オプション部品](#オプション部品)
- [組み立てに必要な工具](#組み立てに必要な工具)
- [組み立て前の確認](#組み立て前の確認)
  - [同梱物の確認](#同梱物の確認)
  - [接続の確認](#接続の確認)
  - [ソケット用パッドの確認](#ソケット用パッドの確認)
- [組み立て手順](#組み立て手順)
  - [組み立てるレイアウトを決める](#組み立てるレイアウトを決める)
  - [（該当者のみ）`REレイアウト`用ファームウェアへの書き換え](#該当者のみreレイアウト用ファームウェアへの書き換え)
  - [（オプション）基板、スイッチプレート、ボトムプレートの側面を塗る](#オプション基板-スイッチプレート-ボトムプレートの側面を塗る)
  - [（オプション）LEDを取り付ける](#オプションledを取り付ける)
  - [Kailh Choc用ソケットを取り付ける](#kailh-choc用ソケットを取り付ける)
  - [（該当者のみ）ロータリーエンコーダを取り付ける](#該当者のみロータリーエンコーダを取り付ける)
  - [スイッチプレートにスペーサーシートを貼り付ける](#スイッチプレートにスペーサーシートを貼り付ける)
  - [スイッチとスイッチプレートを基板へ取り付ける](#スイッチとスイッチプレートを基板へ取り付ける)
  - [スイッチの動作確認をおこなう](#スイッチの動作確認をおこなう)
  - [基板をケース、またはボトムプレートへ取り付ける](#基板をケース-またはボトムプレートへ取り付ける)
  - [スイッチの最終動作確認をおこなう](#スイッチの最終動作確認をおこなう)
  - [仕上げ](#仕上げ)
- [参考](#参考)
  - [打鍵感向上：ケース内部の制振と静音化](#打鍵感向上ケース内部の制振と静音化)
  - [トラブル対応：正常に入力できないスイッチの原因調査](#トラブル対応正常に入力できないスイッチの原因調査)
  - [トラブル対応：LEDの取り付け不良調査](#トラブル対応ledの取り付け不良調査)
  - [資料：ファームウェアの書き込み方法](#資料ファームウェアの書き込み方法)
  - [資料：初期ファームウェアの機能と設定値](#資料初期ファームウェアの機能と設定値)
  - [資料：EEPROMを消去して、初期状態に戻す方法](#資料eepromを消去して-初期状態に戻す方法)
  - [資料：Nora, Fearless Wings (DN0031)関連ファイル](#資料nora-fearless-wings-dn0031関連ファイル)
  - [資料：Raspberry Pi PICOによる動作（実験的機能）](#資料raspberry-pi-picoによる動作実験的機能)
- [サービスマニュアル](#サービスマニュアル)
  - [パーツリスト](#パーツリスト)
  - [基板セットアップ](#基板セットアップ)

<!-- /code_chunk_output -->

---

## Nora, Fearless Wings (DN0031)の特徴, 機能

- 狭ピッチ
- Jonesゆずりのキーレイアウト
- 左右に離れたアルファ部
- Choc v1スイッチと、MBK以下のサイズのキーキャップに合わせた専用設計
- RemapやVIAなどのキーマップ書き換えツールに対応
- 外部EEPROM（8KB）を搭載し、十分な数のレイヤーを使用できる
- 専用ボトムプレート以外にも、GH60型，Poker型のロープロファイルケースに取り付けできる
- ファームウェア書き込み済み  
  試作版では、`REレイアウト`を使用する場合はファームウェアの書き換えが必要です。
- 細かな部品を実装済み
- オプションとして、以下のハードウェア機能を使用可能
  - レイヤーインジケータ／イルミネーションLED（全キー）
  - Raspberry Pi PICOによる動作（実験的機能）

## 注意事項、制限など

- キーキャップ

  MBK以下のサイズのキーキャップに合わせて設計されており、Choc用のキーピッチよりも横方向がほんの少し狭くなっています。  
  17 × 17.8594mm（[基板上の寸法図](../assets/BuildGuide_DN0031/PCB_key_pitch.png)）

  - 取り付け確認済みキーキャップ

    - MBK

    - MCC

    - Gravity Keycaps

    - Kailh製のロープロファイルキーキャップ（※注意）  

      ※注意  
      Kailh製のロープロファイルキーキャップは、MBKなどに比べてキーの寸法が少し大きいため、隣同士のキーが当たる場合があります。  
      ソケットを傾かないように取り付けたり、キーキャップの成形バリを取り除いたり、干渉する箇所を少し削る必要があるかもしれません。  

  - 取り付けできないキーキャップ

    - WRK

      MXスイッチ用のキーピッチ（19.05 × 19.05mm）のため

- スイッチの取り付け

  最下行の親指部分、左右のスペースキーとして使用するスイッチは、上下逆向きに取り付けます。  
  キーキャップは特に問題なく取り付けることができます。  
  透過タイプのキーキャップを使用する場合は、LEDも上下逆向きに取り付けるため、光がほとんど透過しません。

  スイッチの手前側が眩しく感じられる場合は、スイッチのLED穴側面にマスキングテープなどを貼るなどして減光してください。

- スイッチの加工

  `FWレイアウト`をGH60型，Poker型ケースへ取り付ける場合は、ケース中央のネジ穴に重なるスイッチの足を加工（切断）して取り付けます。

- ソケットの取り付け

  1行目と4行目の左端のソケット2個は、ソケットの端子部分が基板から約0.5mm飛び出した状態で取り付けます。

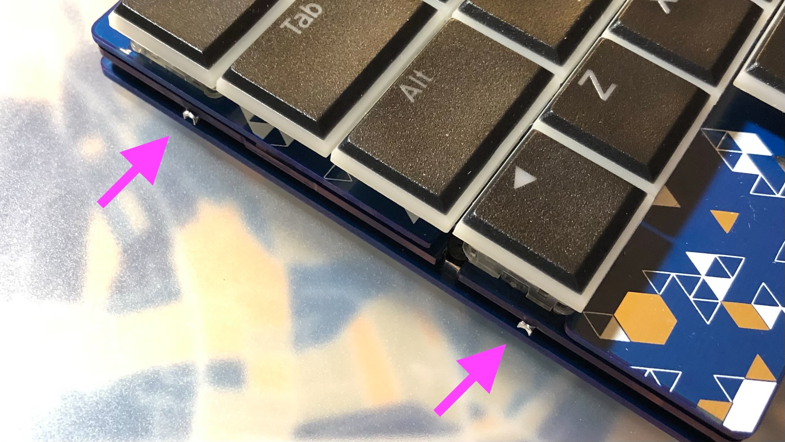
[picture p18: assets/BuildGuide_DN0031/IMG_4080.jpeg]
飛び出したソケット端子
  

  GH60型，Poker型のロープロファイルケースへの取り付けなども含め、実用上の問題がないことを確認していますが、怪我などしないようご留意ください。

- GH60型，Poker型のロープロファイルケースへの取り付け

  ケースの構造によっては、取り付けが難しかったり取り付けできない場合があるかもしれません。  
  ここに記載していないケースへの取り付けの成功／失敗の報告を、随時募集しています。

  取り付け確認済みのケースは次の通りです。  
  - [KBDfans 60% ALUMINUM LOW PROFILE CASE](https://kbdfans.com/collections/60-layout-case/products/customized-gh60-aluminum-case)

  ”TOFU”や”60%プラスチックケース”などのハイプロファイルタイプのケースにも取り付けできますが、キーキャップの天面がケースのフレームよりも低くなるため、実用に向きません。  
  よって、取り付けの対象外としています。  
  参考：[TOFUケースへの装着例](https://twitter.com/jpskenn/status/1466729696713142277)

## 試作版，試作版キットに関する注意事項

- ファームウェア

  試作版の提供形態（`FWレイアウト`と`REレイアアウト`の両方のスイッチプレートを同梱し、どちらでも製作できるキット内容）の都合上、`REレイアウト`を使用する場合はファームウェアを書き換える必要があります。  
  正式版では、`FWレイアウト`と`REレイアアウト`をそれぞれ別のキットとして提供する予定で、その際はファームウェアの書き換えは不要となります。

  ビルド済みのファームウェアを用意していますので、[QMK Toolbox](https://github.com/qmk/qmk_toolbox)などを使用して、書き換えてください。  
  詳しくは、組み立て手順の[（該当者のみ）`REレイアウト`用ファームウェアへの書き換え](#該当者のみreレイアウト用ファームウェアへの書き換え)をご覧ください。

## 部品リスト

このキットを組み立てるためには、”キット内容”に加え、”別途用意が必要な部品”が必要です。  
好みに合わせて、必要な数をお買い求めください。

”オプション部品”は、使いたい機能などに応じて用意してください。  

部品の購入先は、Self-Made Keyboards in Japanの[ショップリスト](https://scrapbox.io/self-made-kbds-ja/ショップリスト)などを参考にしてください。

### キット内容

| 部品名 | 個数 | 備考 |
| ----- | :-----: | ----- |
| ご案内リーフレット | 1 | |
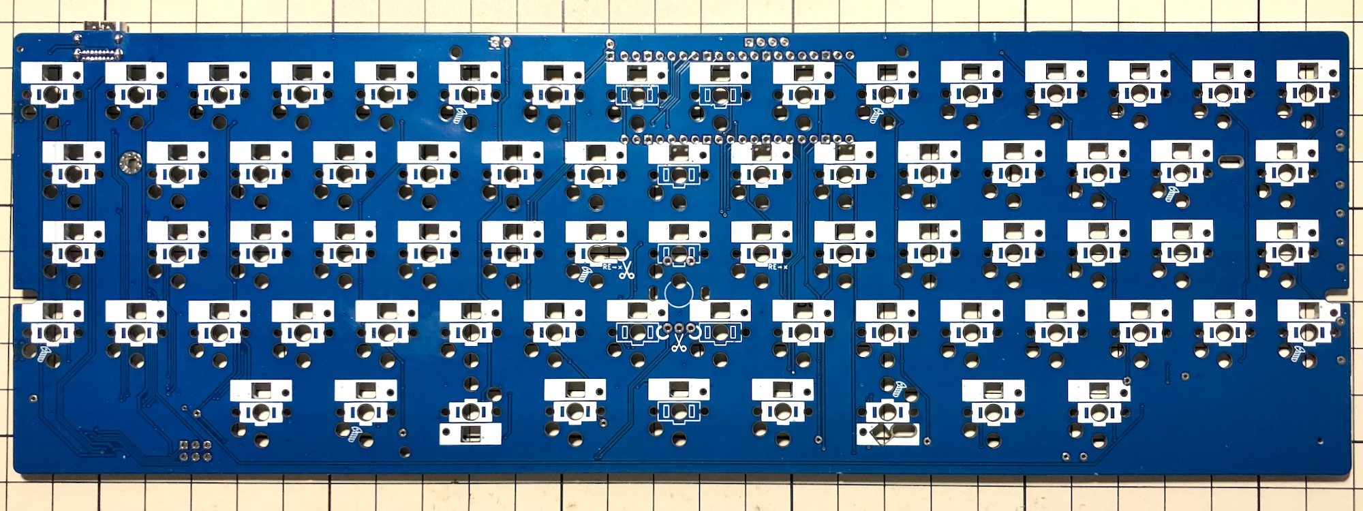
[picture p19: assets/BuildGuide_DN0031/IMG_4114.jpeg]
基板おもて側
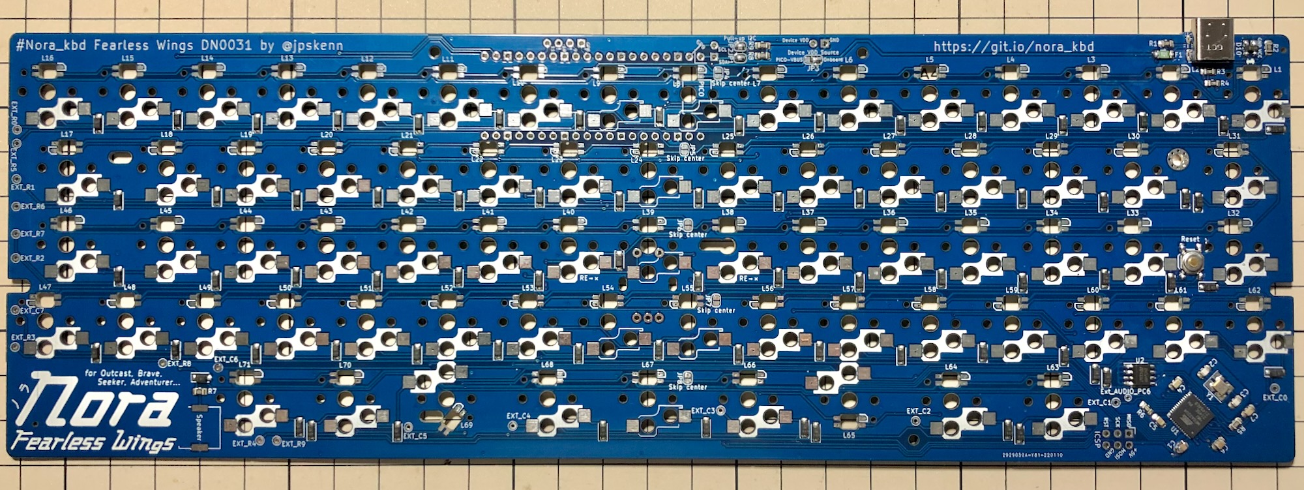
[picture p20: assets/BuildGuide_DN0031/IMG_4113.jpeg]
基板裏側
| 基板 | 1 | [おもて側<br>](../assets/BuildGuide_DN0031/IMG_4114.jpeg)<br>[裏側<br>](../assets/BuildGuide_DN0031/IMG_4113.jpeg) |
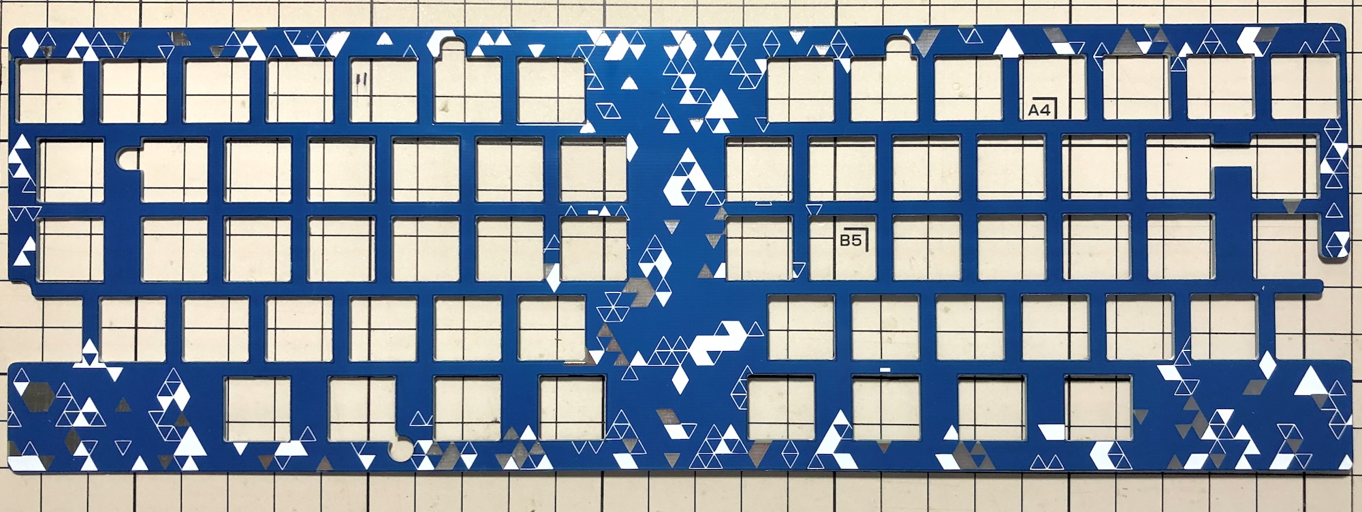
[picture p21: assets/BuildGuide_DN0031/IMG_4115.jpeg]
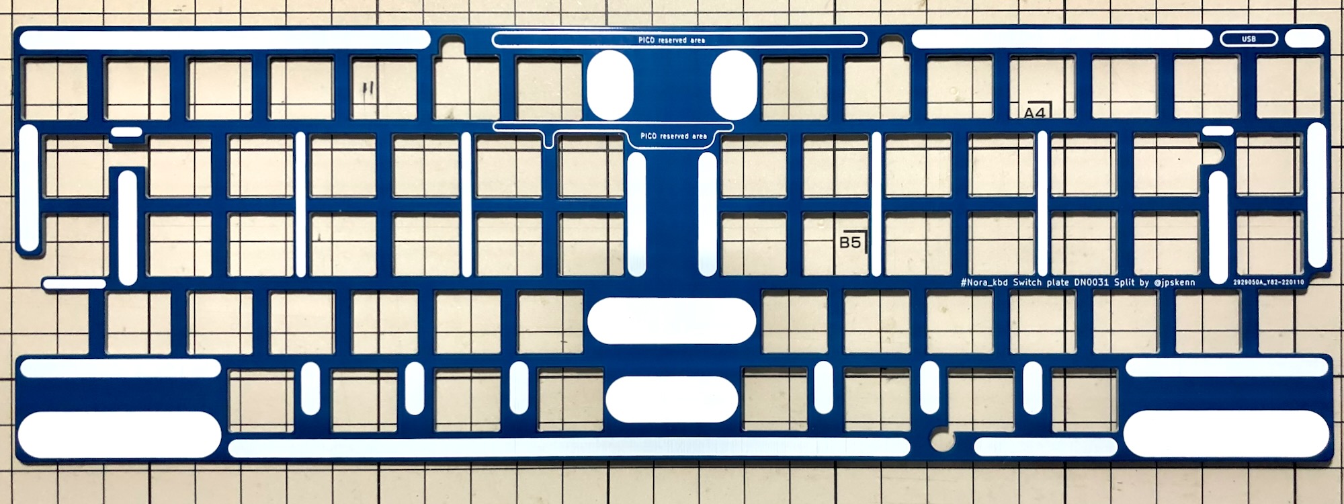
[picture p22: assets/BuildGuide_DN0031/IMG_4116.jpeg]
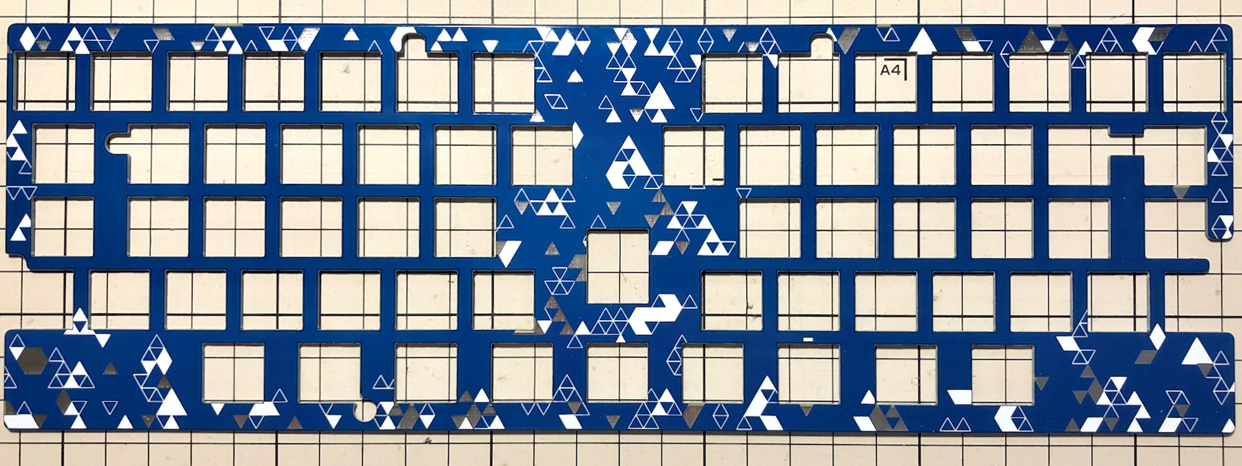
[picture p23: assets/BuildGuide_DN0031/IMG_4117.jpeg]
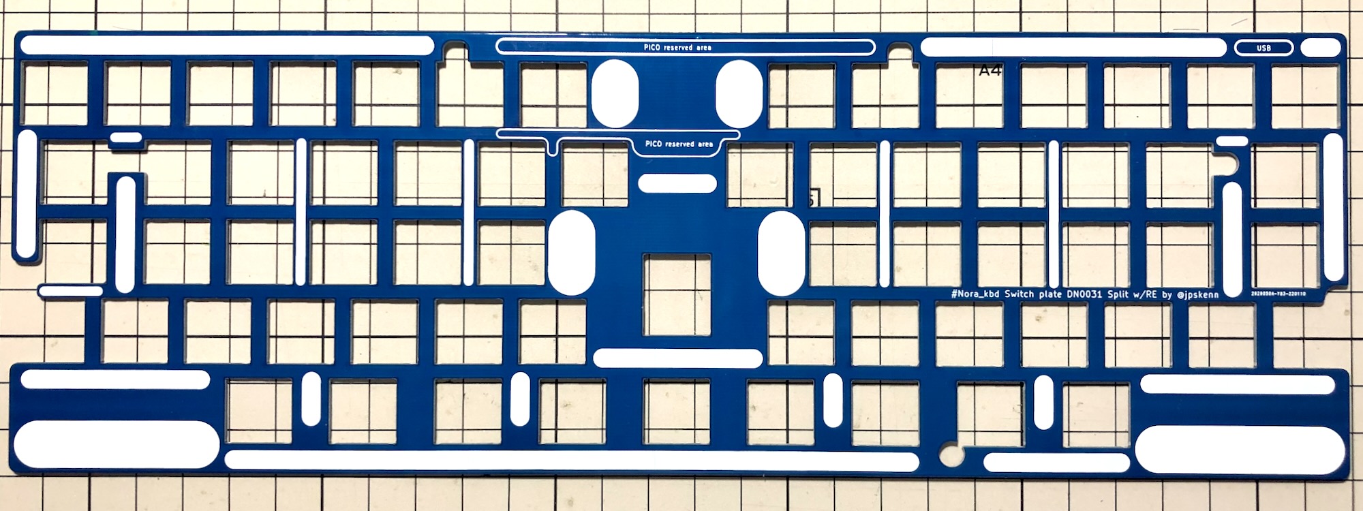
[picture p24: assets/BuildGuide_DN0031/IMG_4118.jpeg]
| スイッチプレート<br>`FWレイアウト`と`REレイアウト` | 各1 | `FWレイアウト`<br>[おもて側<br>](../assets/BuildGuide_DN0031/IMG_4115.jpeg)<br>[裏側<br>](../assets/BuildGuide_DN0031/IMG_4116.jpeg)<br>`REレイアウト`<br>[おもて側<br>](../assets/BuildGuide_DN0031/IMG_4117.jpeg)<br>[裏側<br>](../assets/BuildGuide_DN0031/IMG_4118.jpeg) |
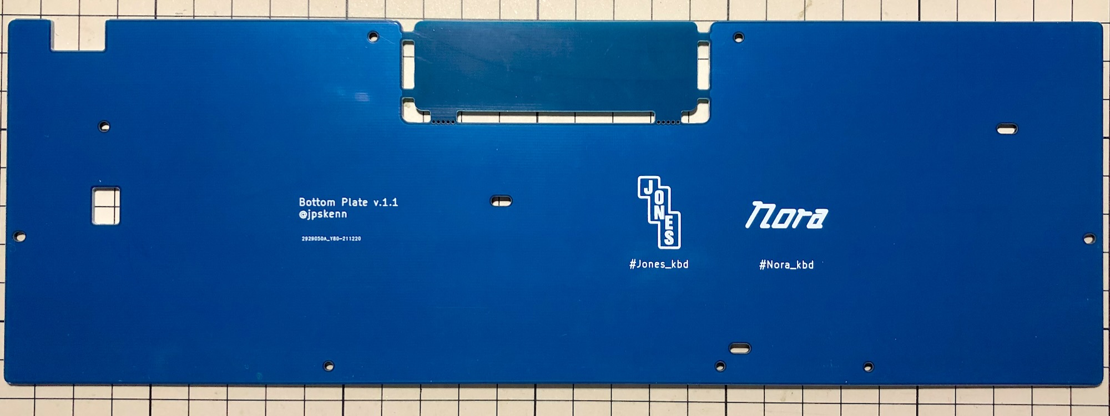
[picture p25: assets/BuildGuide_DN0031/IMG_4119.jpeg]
ボトムプレートおもて側
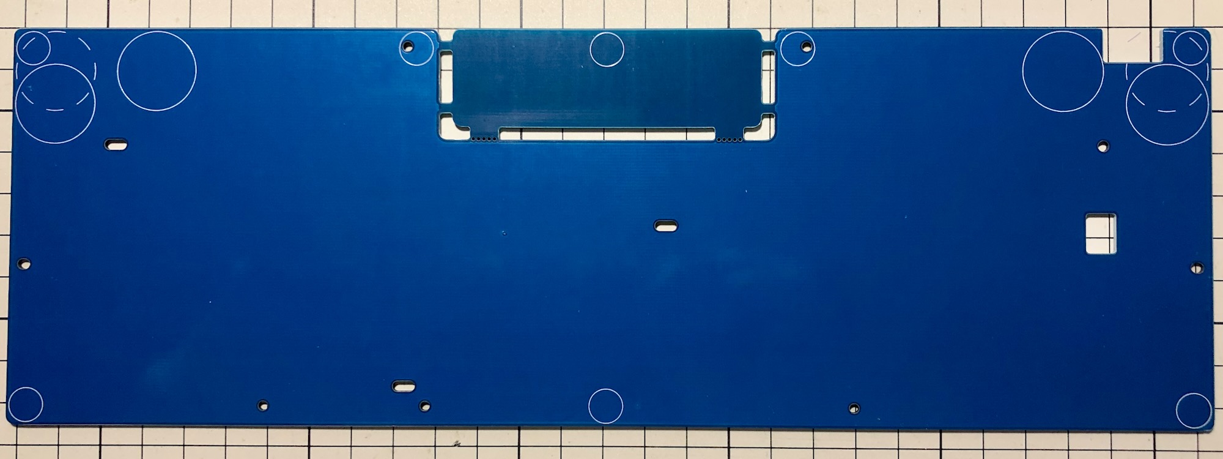
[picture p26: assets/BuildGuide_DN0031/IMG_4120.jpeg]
ボトムプレート裏側
| ボトムプレート | 1 | [おもて側<br>](../assets/BuildGuide_DN0031/IMG_4119.jpeg)<br>[裏側<br>](../assets/BuildGuide_DN0031/IMG_4120.jpeg) |
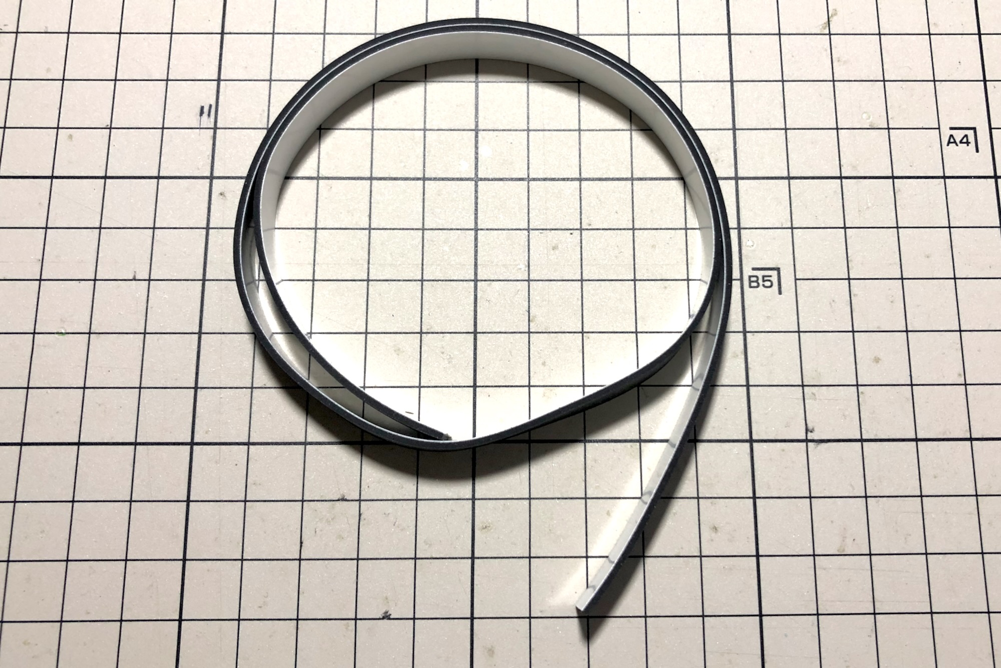
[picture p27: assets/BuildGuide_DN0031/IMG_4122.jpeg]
| スペーサーシート<br> シール付き, 1mm厚, 500mm * 10mm<br>[低弾性ゴムシート－ハネナイトＲ－ (UNLEA1-10)](https://jp.misumi-ec.com/vona2/detail/110300277050/?HissuCode=UNLEA1-10) | 1 | [](../assets/BuildGuide_DN0031/IMG_4122.jpeg) |
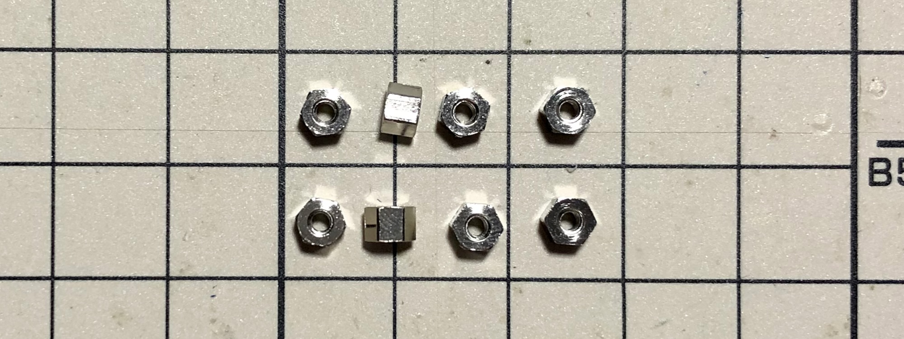
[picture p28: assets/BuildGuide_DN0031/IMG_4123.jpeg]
| スペーサー, M2 3mm<br>[黄銅 スペーサー(六角) / ASB-E](https://hirosugi.co.jp/products/B/ASB-E.html) | 8 | [](../assets/BuildGuide_DN0031/IMG_4123.jpeg) |
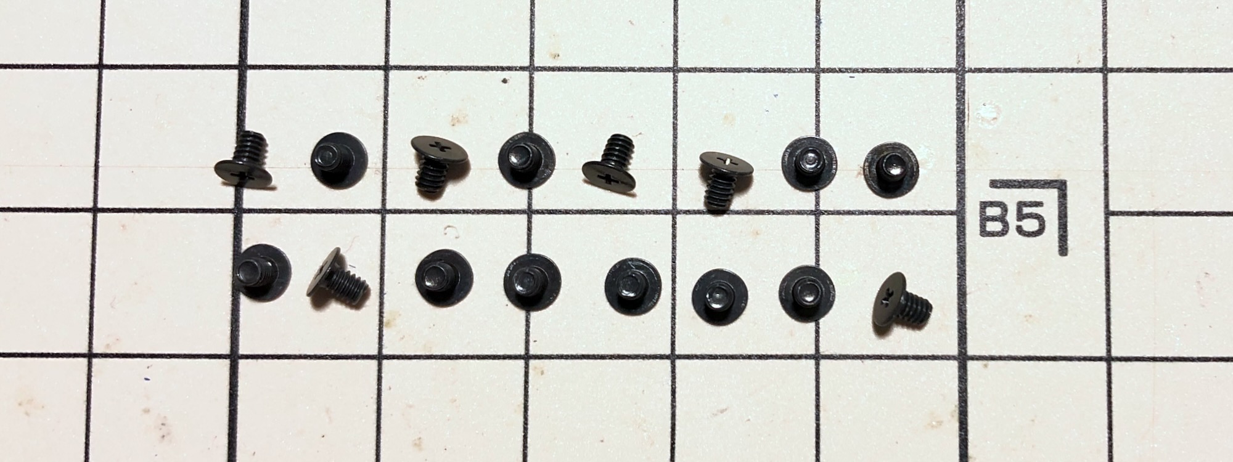
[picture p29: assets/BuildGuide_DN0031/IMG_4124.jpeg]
| ネジ, M2 3mm, 低頭<br>[低頭精密小ねじ(ラミクス)](https://wilco.jp/products/F/FX-EB.html) | 16 | [](../assets/BuildGuide_DN0031/IMG_4124.jpeg) |
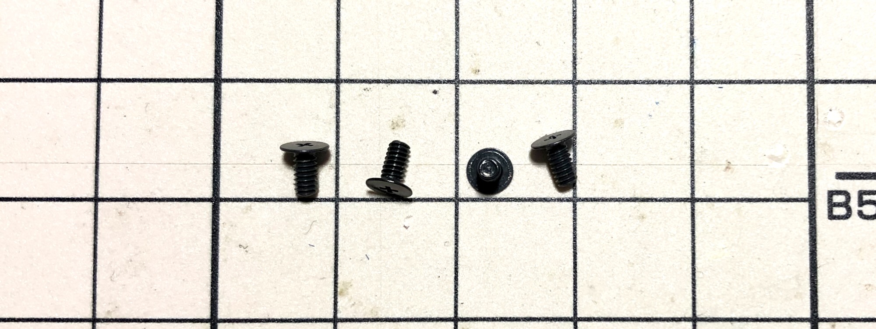
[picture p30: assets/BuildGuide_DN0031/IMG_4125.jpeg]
| ネジ, M2 4mm, 低頭<br>[低頭精密小ねじ(ラミクス)](https://wilco.jp/products/F/FX-EB.html) | 4 | [](../assets/BuildGuide_DN0031/IMG_4125.jpeg) |
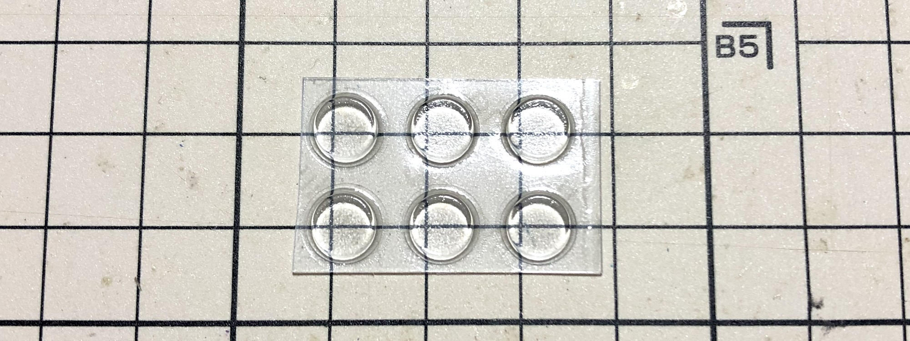
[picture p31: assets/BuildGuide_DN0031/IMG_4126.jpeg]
| ゴム足 小<br>[しっかりつくクッションゴム CS-102, 透明, 8 φ x 2 mm](https://www.3mcompany.jp/3M/ja_JP/p/d/v000453068/) | 6 | [](../assets/BuildGuide_DN0031/IMG_4126.jpeg) |

※出荷時期によってメーカーや品番などが変わることがあります

### 別途用意が必要な部品

| 部品名 | 個数 | 備考 |
| ----- | :-----: | ----- |
| ソケット<br>Kailh Chocロープロファイル用 | 63〜64 | `FWレイアウト`：64個<br>`REレイアウト`：63個 |
| スイッチ<br>Kailh Choc v1 | 63〜64 | `FWレイアウト`：64個<br>`REレイアウト`：63個 |
| キーキャップ<br>Choc用<br>17mm × 17.8594mm以下のサイズのもの<br>おおむねMBK以下のサイズ | 63〜64 | `FWレイアウト`：64個<br>1u × 56個<br>1.5u × 8個<br>`REレイアウト`：63個<br>1u × 54個<br>1.5u × 8個<br>1u, 1.25u, 1.5uのうち、いずれか1個 |
| ロータリーエンコーダ<br>ALPS EC11, EC12または同等品 | 1 | `REレイアウト`を組み立てる場合のみ必要 |
| ロータリーエンコーダ用ノブ<br>（つまみ） | 1 | `REレイアウト`を組み立てる場合のみ必要<br>ロータリーエンコーダの軸の形状に合ったもの。<br>最大径33mm（使用するキーキャップのサイズによる） |
| USBケーブル （Type-C） | 1 | |

### オプション部品

| 部品名 | 個数 | 備考 |
| ----- | :-----: | ----- |
| LED<br>SK6812MINI-E | 64〜65 | LEDを取り付ける場合<br>`FWレイアウト`：64個<br>`REレイアウト`：65個<br>（試作版`REレイアウト`では見えない箇所にもLEDを取り付けます） |
| GH60型，Poker型ロープロファイルケース | 1 | ケースへ取り付ける場合 |
| Raspberry Pi PICO | 1 | 実験的機能をDIYで楽しむ場合 |
| ゴム足 | 必要数 | ボトムプレート裏側へ貼り付け、角度を変えたりする場合<br>例：[大きなゴム足](https://www.yodobashi.com/product/100000001001980663/) |

## 組み立てに必要な工具

- 先の細いドライバー（M2ネジに対応するもの）
- ピンセット
- はんだ付け関連用品
- はさみ
- ニッパー

フラックスやハンダ吸い取り線を用意しておくと、ちょっとした修正などがやりやすくなります。
[遊舎工房の工具セット](https://yushakobo.jp/shop/a9900to/)を参考に用意してください。

なお、無くても組み立てはできますが、何か不具合があった場合の原因調査ではテスターがあると便利です。

## 組み立て前の確認

組み立てを開始する前に、同梱物と基板についての基本的な確認をおこないます。  

**何か問題があった場合は作業を中止し、リーフレットに記載された連絡先へ問い合わせてください。**  
**組み立ての開始後は、初期不良として対応できかねる場合があります。**

### 同梱物の確認

リーフレットに記載された部品が、不足なく入っていることを確認します。

### 接続の確認

基板をUSBケーブルでMacやPCに接続して、キーボードとして認識されることを確認します。

充電用ではないUSBケーブルを使用します。
他の機器を接続して使用した実績のあるケーブルを使うと、無用のトラブルを防げます。

下記のOS別の確認方法を参考に、確認してください。

<details>
<summary>確認方法：《Mac, macOS Monterey 12.0.1》</summary>

1. 基板とMacをUSBケーブルで接続します。

    接続した際に`キーボード設定アシスタント`が表示された場合は、`終了`ボタンを押して閉じます。

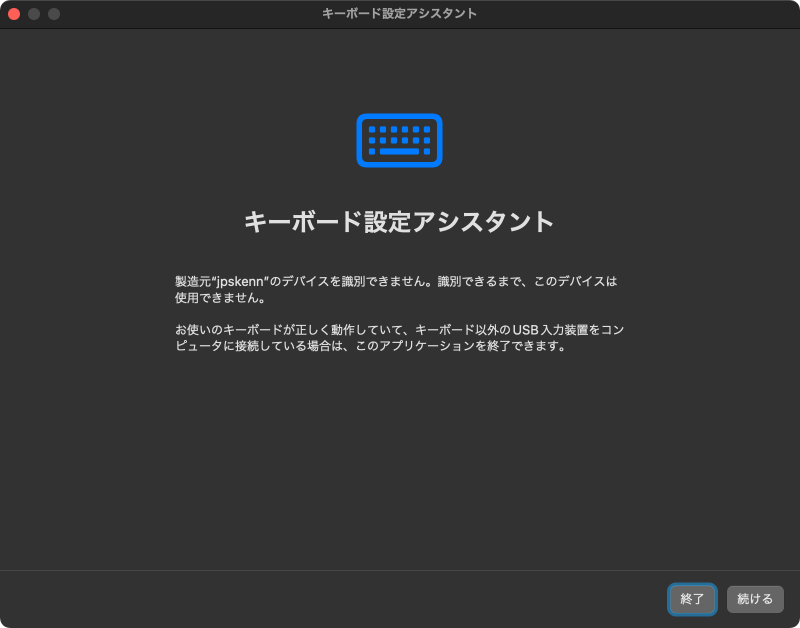
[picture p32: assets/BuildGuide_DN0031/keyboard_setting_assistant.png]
キーボード設定アシスタント
      

    なお、キーボード設定アシスタントは、次の操作でいつでも呼び出すことができます。  
    `システム環境設定`から、`キーボード` → `キーボード`タブ → `キーボードの種類を変更…`ボタンを押す。

1. システム情報を表示します。

    メニューバーの``マークから、`このMacについて`を選び、表示された画面で`システムレポート…`をクリックします。  

1. USBデバイスを表示します。

    `システム情報`画面で、左側の`ハードウェア`から`USB`を選択します。

1. `Nora`が接続されていることを確認します。

    右側上部の`USB装置ツリー`で、`Nora`を探します。  
    どこかに`Nora`と表示されていれば、正しく接続されています。  

    `USB装置ツリー`の下の方が見切れている場合があるため、スクロールして探してください。

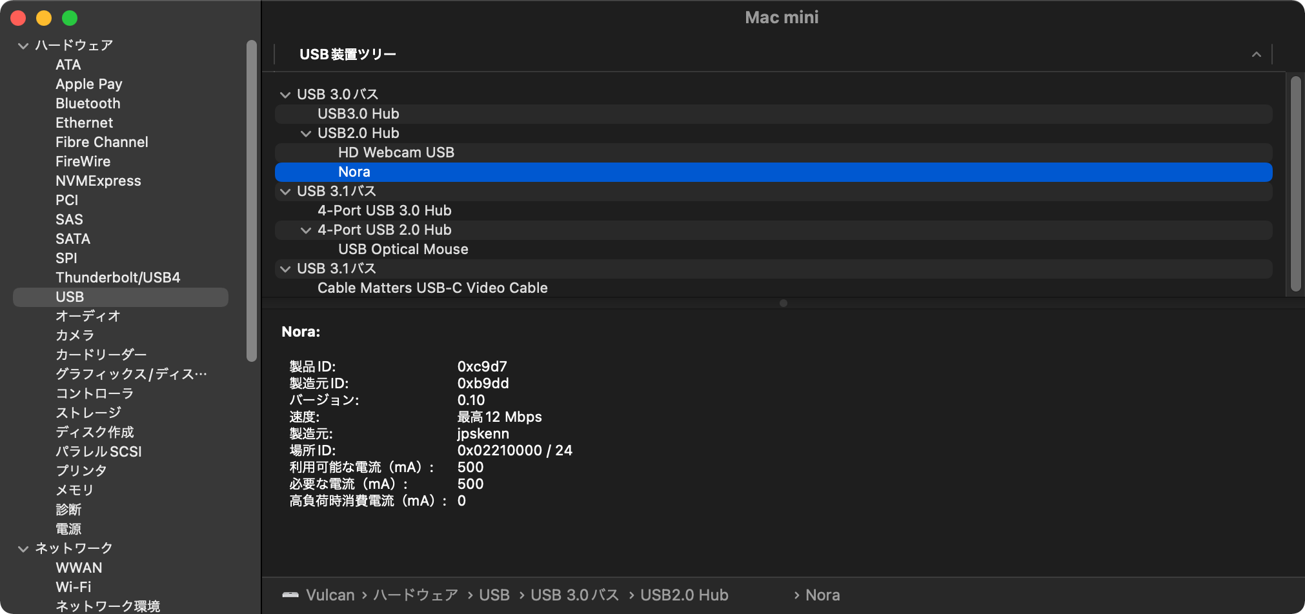
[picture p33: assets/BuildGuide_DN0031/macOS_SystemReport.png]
Mac System Report
      
    システム情報の表示

</details>

<details>
<summary>確認方法：《Windows, 10 Pro 1909(18363.1082)》</summary>

1. 基板とPCをUSBケーブルで接続します。

1. `デバイス`を表示します。

    `スタートボタン`から`設定`を開いて`デバイス`を選択します。

1. `Nora`が接続されていることを確認します。

    `マウス、キーボード、ペン`の項目に`Nora`が表示されていれば、正しく認識されています。

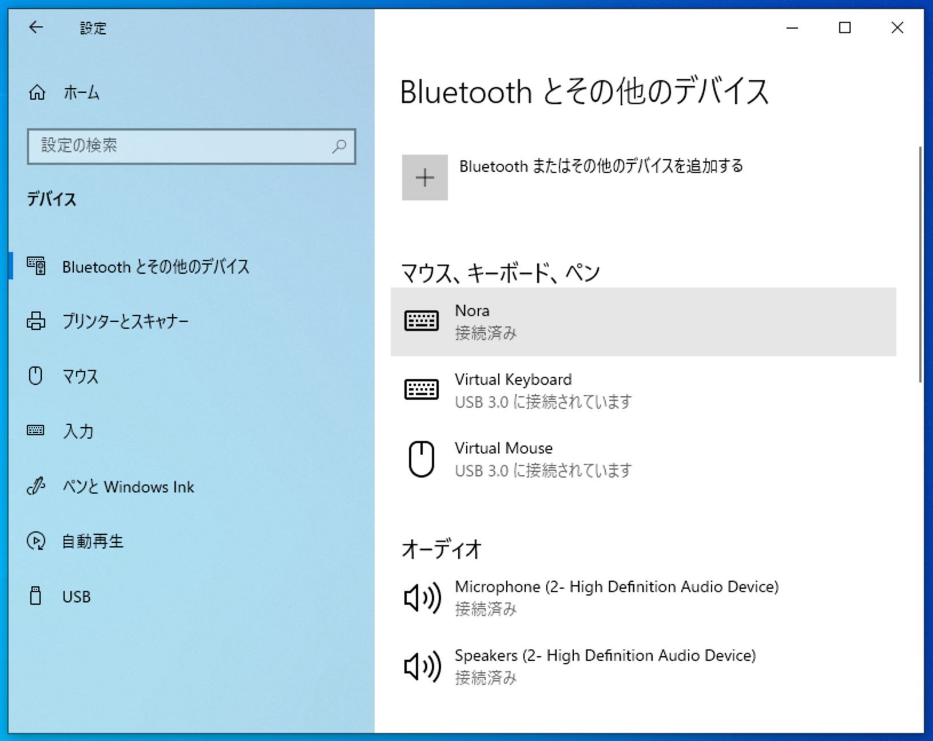
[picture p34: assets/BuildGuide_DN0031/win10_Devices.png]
Windows Devices
      
    デバイスの表示

</details>

### ソケット用パッドの確認

[Remap](https://remap-keys.app/)のテスト機能を使用し、Kailh Chocソケット用のパッド（※）が、電気的に正しく反応することを確認します。  
※ソケットをはんだ付けする、基板上の四角い銀色の部分

<details>
<summary>《詳しい説明》</summary>

キーマップ書き換えツール[Remap](https://remap-keys.app/)のテスト機能を使って確認をおこないます。

1. 基板の裏側が上になるように置きます。

1. 基板をPCやMacとUSBケーブルで接続します。

    USBコネクタ部分に無理な力がかからないように気をつけます。

1. Google Chromeブラウザで、[Remap](https://remap-keys.app/)のページを開きます。

    Chromeブラウザは、Web HID対応のバージョン89以降を使用します。

1. `START REMAP FOR YOUR KEYBOARD`をクリックして始めます。

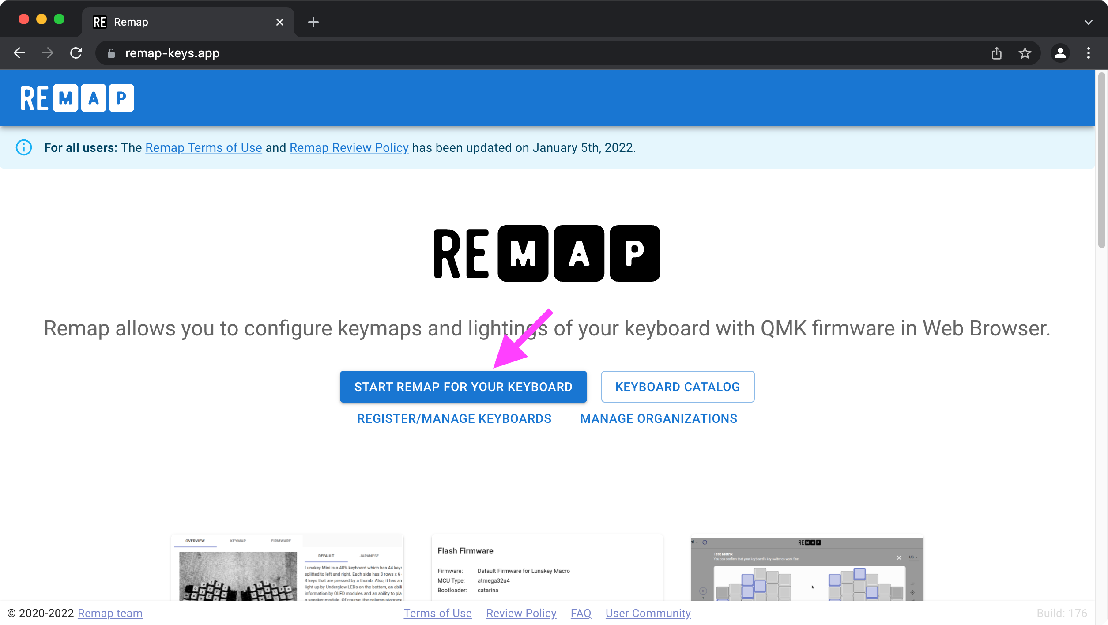
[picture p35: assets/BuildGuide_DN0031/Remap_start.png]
START REMAP FOR YOUR KEYBOARD
    

1. `+ KEYBOARD`をクリックして、キーボードをRemapに接続する画面を表示します。

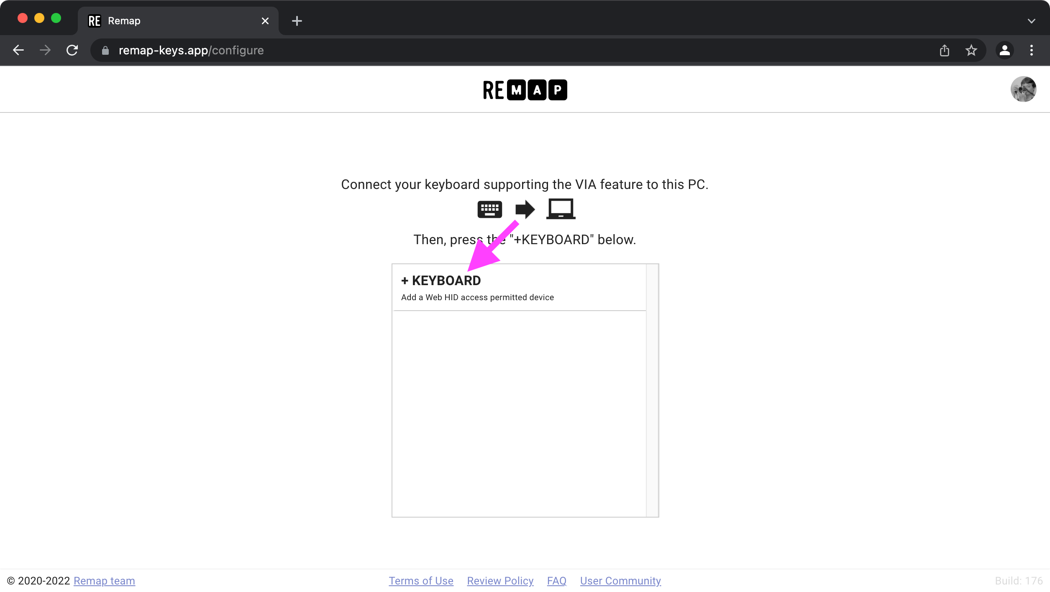
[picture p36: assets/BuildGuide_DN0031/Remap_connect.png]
+ KEYBOARD
    

1. デバイスへの接続要求画面で`Nora`を選択し、`接続`をクリックしてキーボードをRemapに接続します。

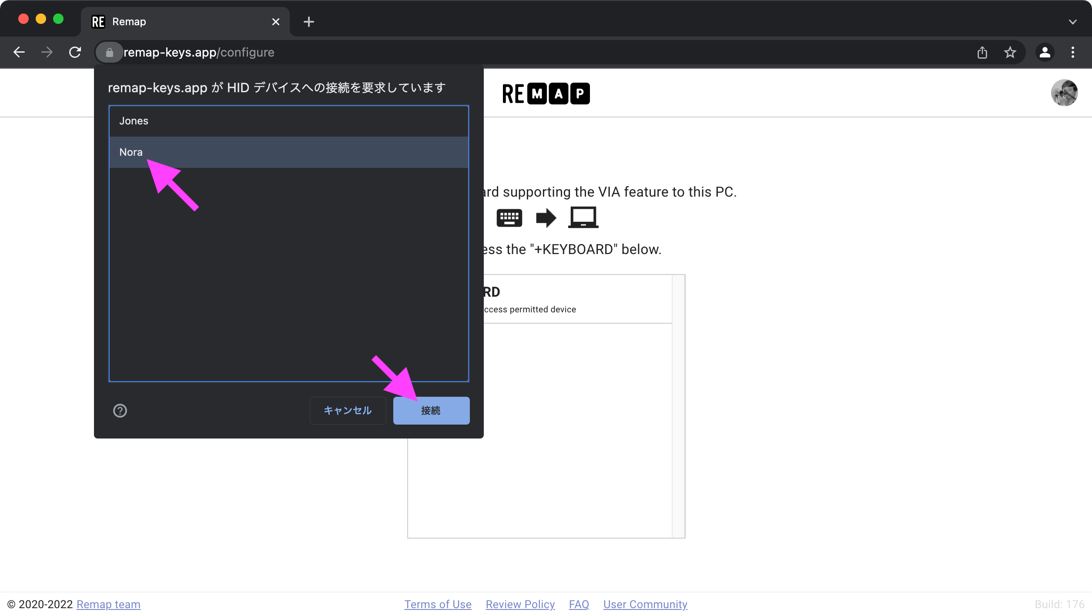
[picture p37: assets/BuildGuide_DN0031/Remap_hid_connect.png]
デバイスへの接続要求
    

1. 右側のアイコンから`Layout Option`をクリックし、使用するレイアウトを選択します。

    `FWレイアウト`： Fearless Wings  
    `REレイアウト`： FW + Rotary Encoder

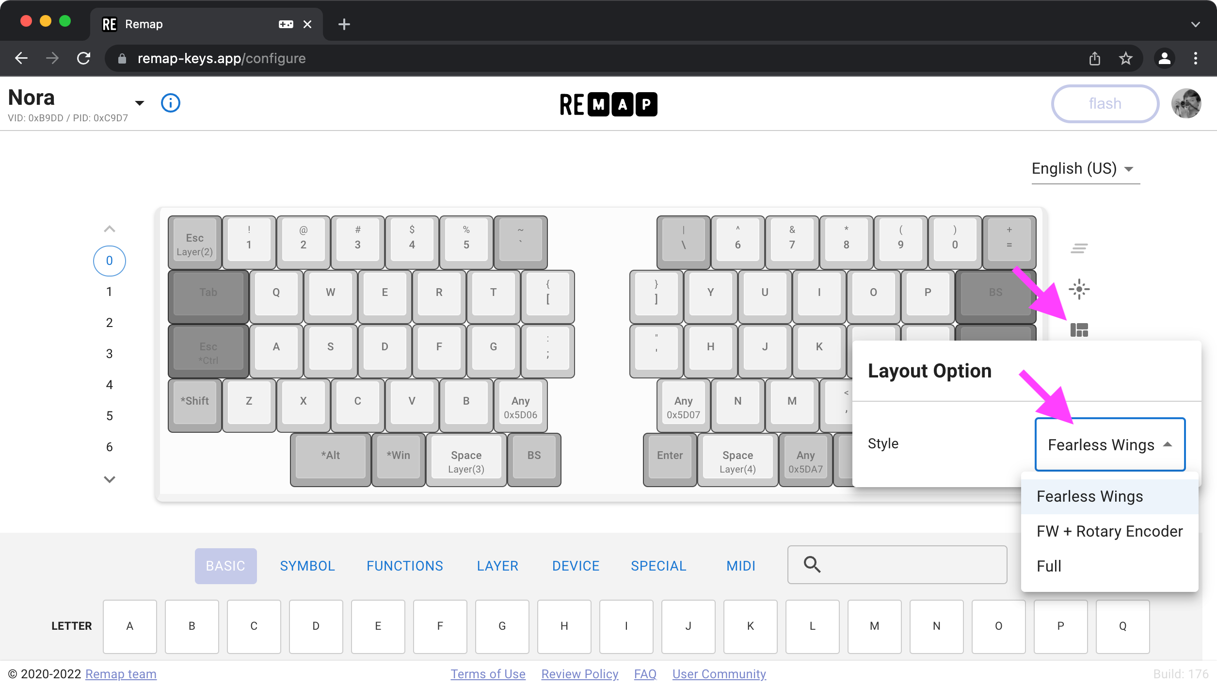
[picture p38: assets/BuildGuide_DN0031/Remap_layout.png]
Test Matrix Mode
    

1. 右側のアイコンから`…`をクリックし、`Test Matrix mode`を選択します。

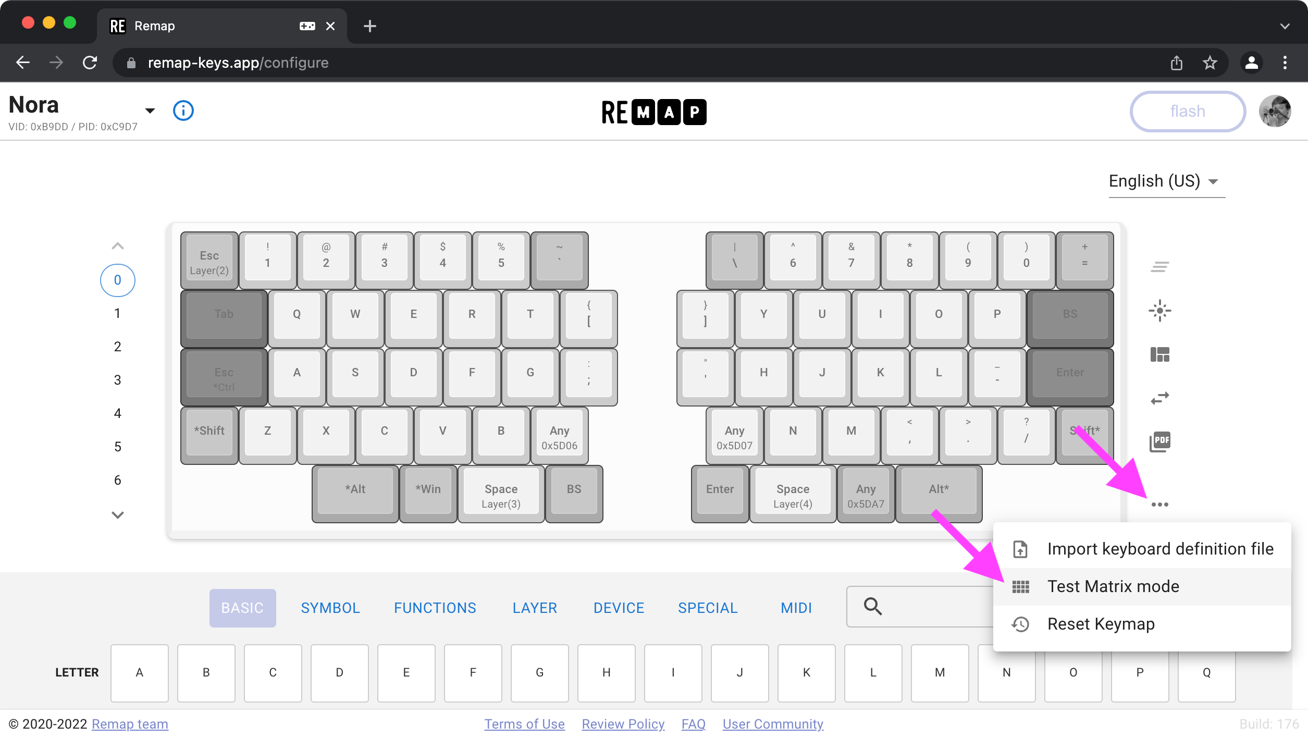
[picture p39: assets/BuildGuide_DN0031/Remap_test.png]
… menu
    

1. ピンセットなどの電気を通すものを使い、基板裏側のソケット用パッドをショートさせます。

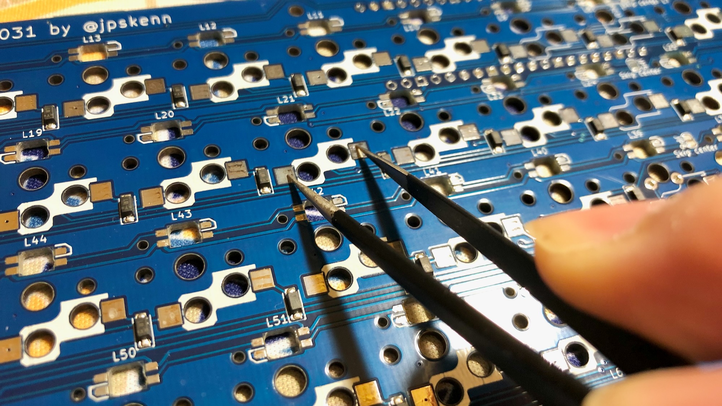
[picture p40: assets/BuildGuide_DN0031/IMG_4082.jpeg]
ピンセットを使ってショートさせる様子
      
    ピンセットを使ってショートさせる様子

1. Remapの画面で、ショートさせた箇所に対応するキーの色が変わることを確認します。

    *基板が裏側になっているので、画面ではキーの位置が左右反対になります。*

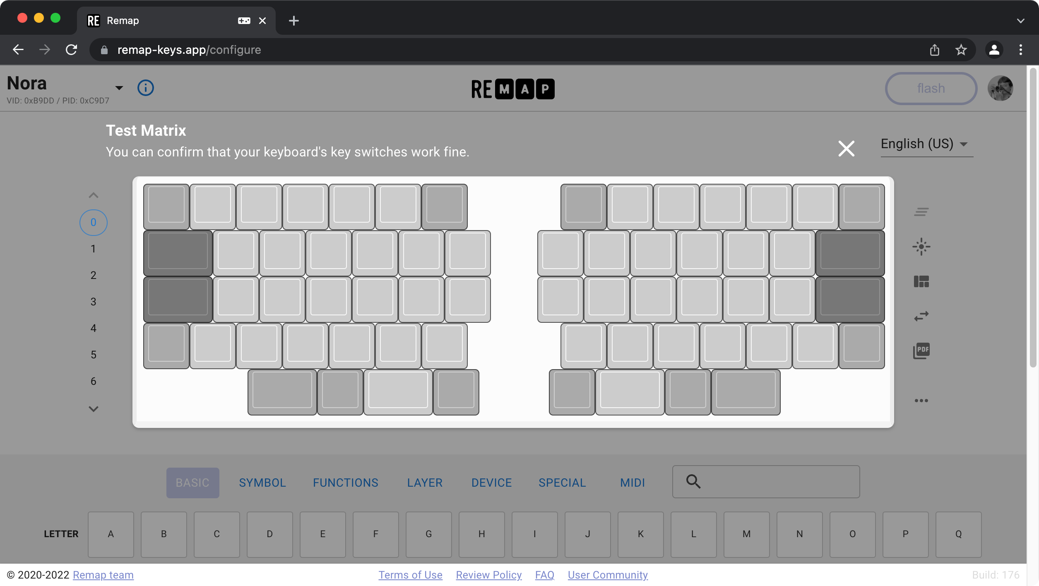
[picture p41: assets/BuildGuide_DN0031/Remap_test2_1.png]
Test Matrix mode
    
    ショートさせる前

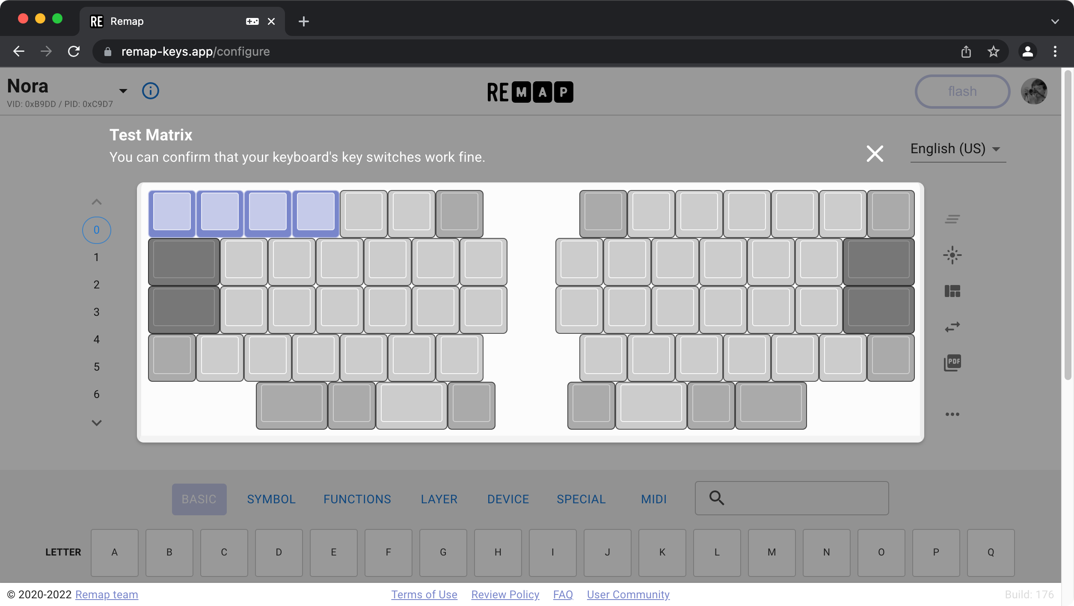
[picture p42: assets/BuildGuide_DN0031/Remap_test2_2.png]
キーの色が変わる
    
    ショートさせた後（キーの色が変わる）

    パッドをショートしても反応がない場合は、基板に実装された部品が外れたり、配線がダメージを受けている可能性があります。  
    この確認作業をすべてのパッドでおこなった後、どのパッドが反応しなかったかわかるようにスクリーンショットなどを残してください。  
    撮影したスクリーンショットと合わせて、リーフレットに記載された連絡先へ問い合わせてください。

1. 同様の作業を繰り返し、全てのキーの色が変わることを確認します。

    なお、`REレイアウト`でロータリーエンコーダの回転に割り当てた箇所は、この手順では確認しません。  
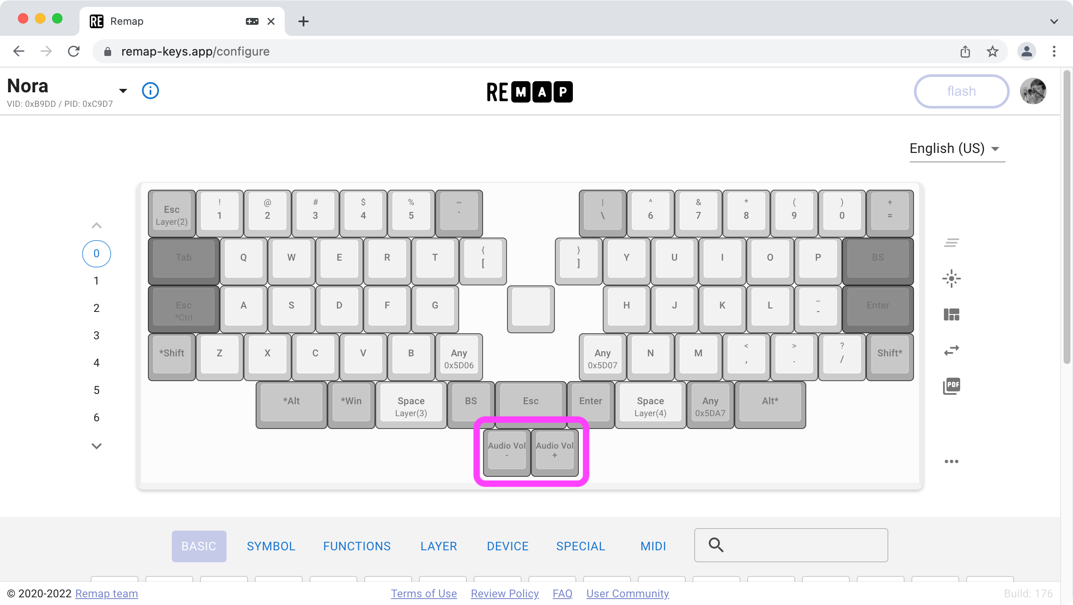
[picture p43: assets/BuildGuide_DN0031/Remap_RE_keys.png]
RE assigned keys
    
    ロータリーエンコーダの回転に割り当てた箇所

1. 確認が終わったら、USBケーブルを抜きます。

</details>

## 組み立て手順

以下の手順に沿って組み立てます。  
`（オプション）`と書かれた項目は、不要であれば作業をとばしてもかまいせん。  
`（該当者のみ）`と書かれた項目は、条件に該当する場合のみ作業をおこないます。

怪我などに気をつけて作業してください。  

### 組み立てるレイアウトを決める

この試作版では、`FWレイアウト`と`REレイアウト`のどちらかひとつを組み立てることができます。

レイアウトは、ほぼ同じです。  
ロータリーエンコーダと、中央部分のキーのあり／なしで少し違いがあります。

こちらのレイアウト図も参考にしてください。  
[Nora, Fearless Wings family](http://www.keyboard-layout-editor.com/#/gists/568990362f215776aa93e3b90064f241)

その他の機能に違いはありません。

### （該当者のみ）`REレイアウト`用ファームウェアへの書き換え

*`REレイアウト`を使用する場合のみ、この手順をおこないます。*

Remapを使用して、[Noraのファームウェアページ](https://remap-keys.app/catalog/E014O2hP6X5DeDQCdhmA/firmware)から、`Nora DN0031, VIA + RE`のファームウェアに書き換えます。

QMK Toolboxで書き換える場合は、[資料：ファームウェアの書き込み方法](#資料ファームウェアの書き込み方法)を参考にしてください。

<details>
<summary>《詳しい説明》</summary>

Remapを使用して書き込む手順を説明します。

1. 基板の裏側が上になるように置きます。

1. 基板をPCやMacとUSBケーブルで接続します。

1. Google Chromeブラウザで、Remapの[Noraのファームウェアページ](https://remap-keys.app/catalog/E014O2hP6X5DeDQCdhmA/firmware)を開きます。

1. リストから`REレイアウト`用のファームウェア`Nora DN0031, VIA + RE`を探し、`FLASH`を押します。

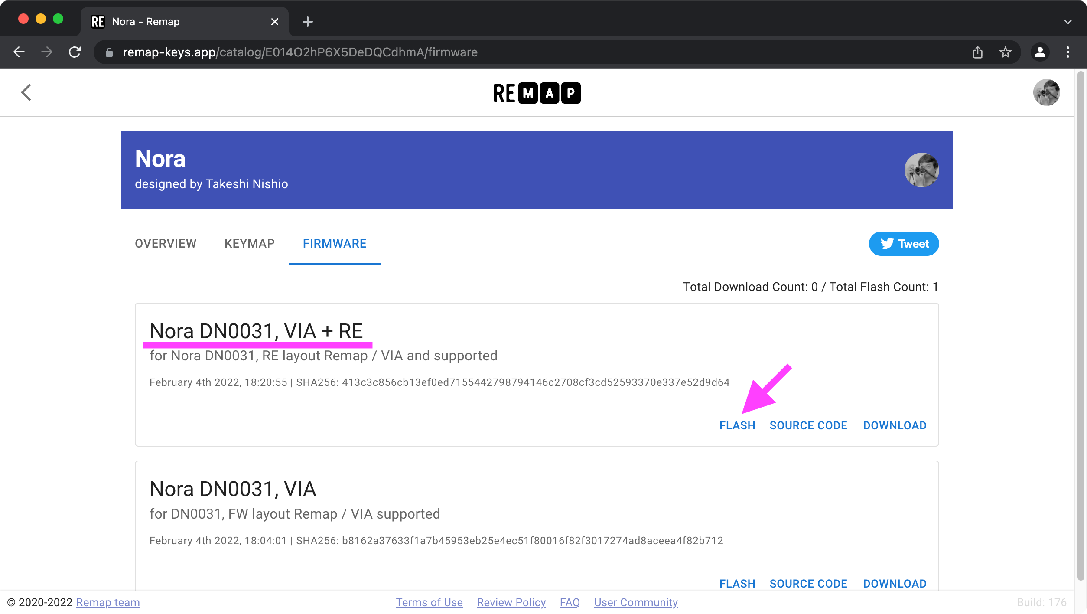
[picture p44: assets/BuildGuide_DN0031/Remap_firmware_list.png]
Firmware list
    

1. Flash Firmwareの画面で、Bootloaderに`dfu`を選択し、右下の`FLASH`を押します。

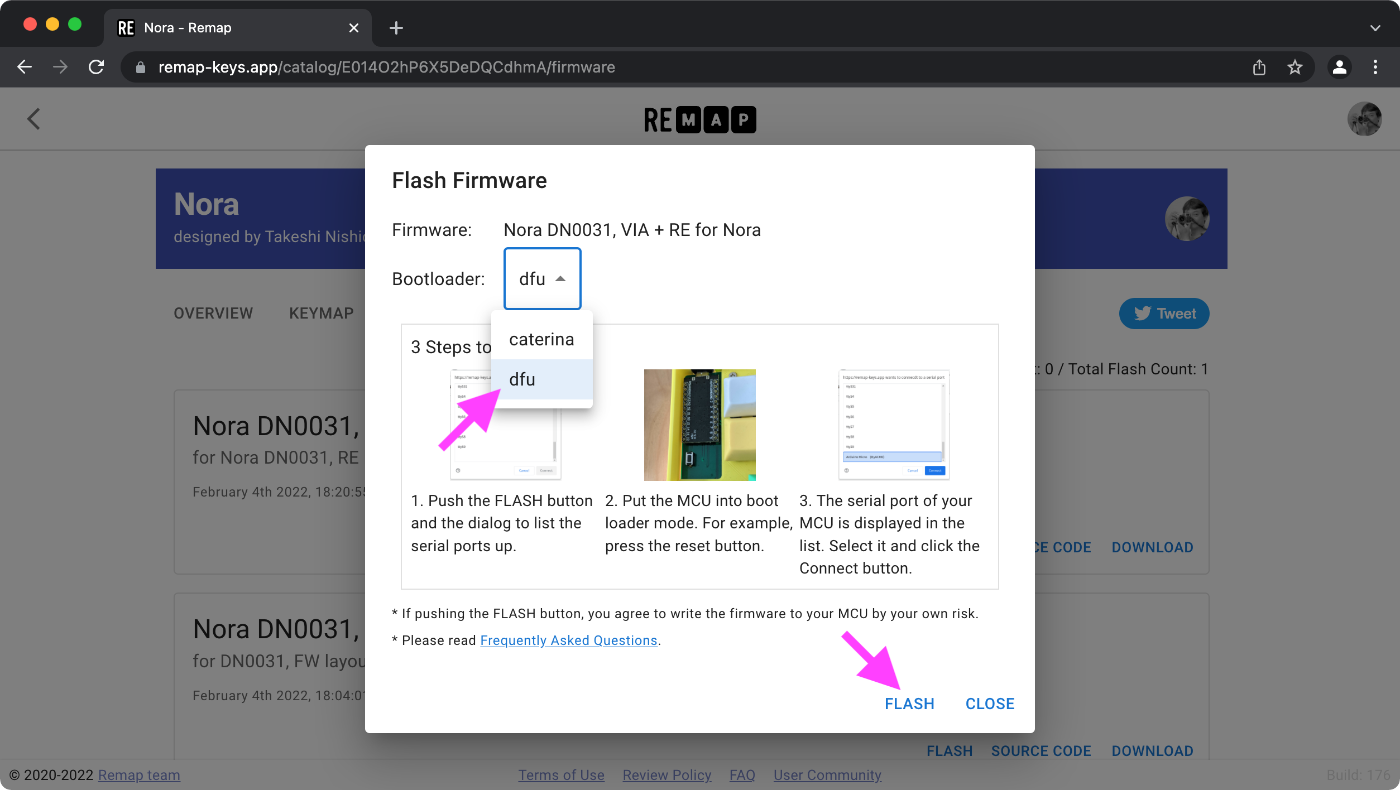
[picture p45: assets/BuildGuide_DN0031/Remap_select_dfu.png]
Select dfu
    

1. 接続要求画面が表示されたら、基板裏側の`Reset`と書かれたスイッチを押します。

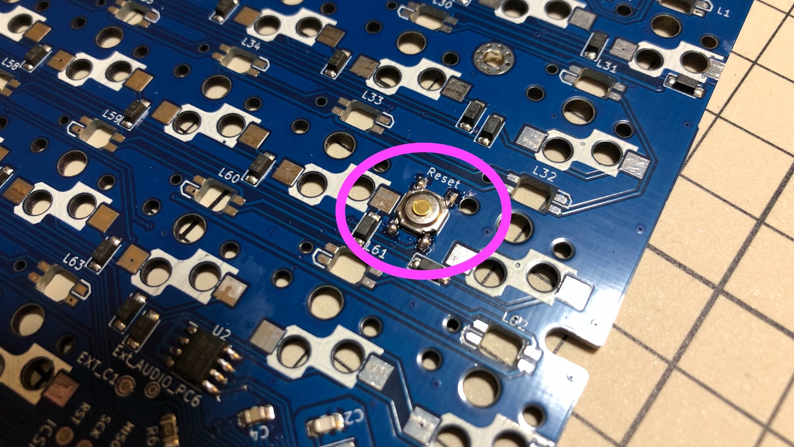
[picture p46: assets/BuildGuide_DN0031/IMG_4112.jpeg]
Reset switch
    

1. 接続要求画面に`ATm32U4DFU`が表示されるので、これを選択して`接続`ボタンを押します。

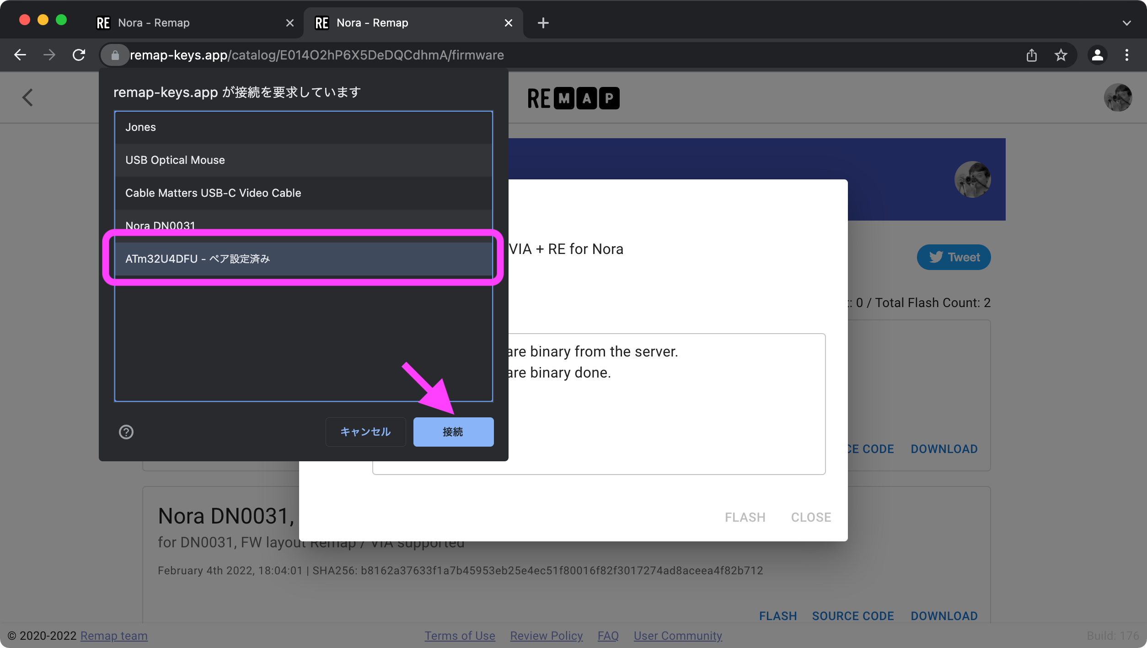
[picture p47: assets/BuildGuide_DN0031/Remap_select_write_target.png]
Select dfu
    

1. ファームウェアの書き込みが始まり、メッセージがずらずらっと表示され、10秒程度で書き込みが完了します。

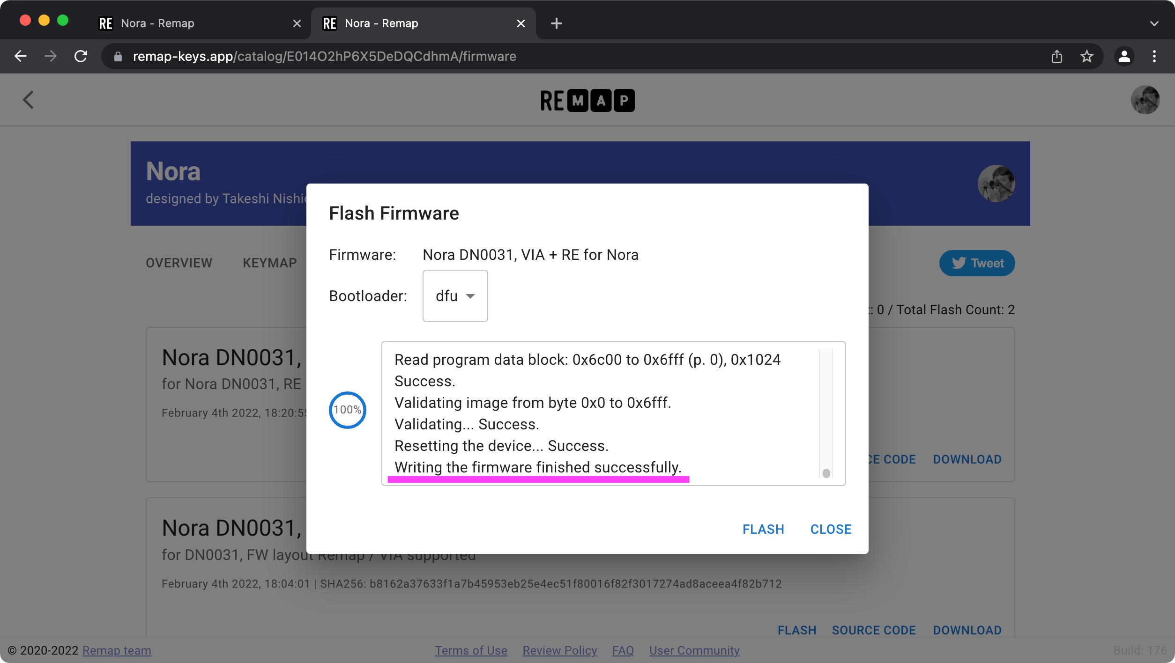
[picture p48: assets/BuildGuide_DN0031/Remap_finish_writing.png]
    

    メッセージの最後に、

    ```text
    Writing the firmware finished successfully.
    ```

    と表示されていれば、書き込み成功です。

これでファームウェアの書き換えは完了です。

**ファームウェアを書き込んで初めてRemapに接続した際、キーボードレイアウト画面が表示されるまで30秒〜1分ほどかかる場合があります。**  
EEPROMの初期化処理がおこなわれていますので、キーボードの準備が整うまでしばらくお待ちください。  
2回目以降の接続では、すぐに接続されます。

</details>

### （オプション）基板、スイッチプレート、ボトムプレートの側面を塗る

*少し塗りにくくなりますが、組み立て後におこなうこともできます。*

見栄えを良くするため、基板、スイッチプレート、ボトムプレートの側面を塗ります。

はみ出さないように気をつけて、水性顔料や油性のマーカーなどを使って好きな色に塗ります。

### （オプション）LEDを取り付ける

基板裏側のLED配線経路をジャンパします。  
基板裏側からLEDを取り付けます。  
**行ごとにLEDを取り付ける方向が異なるため、気をつけてください。**

| レイアウト | 配線経路ジャンパ位置 | LEDを取り付けない位置 |
| :--: | :-- | :-- |
| FWレイアウト | `JP4`<br>`JP5`<br>`JP6`<br>`JP7`<br>**`JP8`** | `L8` `L9`<br>`L24`<br>`L39`<br>`L54` `L55`<br>**`L67`** |
| REレイアウト | `JP4`<br>`JP5`<br>`JP6`<br>`JP7` | `L8` `L9`<br>`L24`<br>`L39`<br>`L54` `L55` |

<details>
<summary>《詳しい説明》</summary>

#### LEDの配線経路をジャンパする

基板裏側の配線経路ジャンパを、レイアウトに応じてジャンパ（※）します。  
※隣同士のパッド（基板上の小さな四角の銀色部分）にはんだをつけてつなげること

レイアウトと配線経路に対応するジャンパ位置は次の通りです。

| レイアウト | 配線経路ジャンパ位置 |
| :--: | :-- |
| FWレイアウト | `JP4` `JP5` `JP6` `JP7` **`JP8`** |
| REレイアウト | `JP4` `JP5` `JP6` `JP7` |

1. 基板を裏側が上になるように置きます。

1. はんだごてを用意します。  
  こて先の温度は320℃程度にします。  

1. 2個並んだパッドにまたがるように、こて先をあてます。  
  そのまま、3秒ほど温めます。

1. こて先にはんだを押し付けて、少したっぷり目に溶かします。

1. こて先で基板をなでるように、横へスッとずらしてパッドから離します。  
  2個のパッドが、はんだでつながっていれば完了です。  

なかなか上手くジャンパできないのですが、何度かトライすればそのうちできます。  
こて先でパッドをグリグリいじるとパッドが剥がれて大変なことになるため、  
「はんだをたっぷりつけて、横へスッ」  
の動きを守って作業します。

<!-- 〓DN0032写真　パッドをFullにジャンパした例 -->

#### LEDを取り付ける

基板裏側の`L1`から`L71`へ、レイアウトに応じてLEDを取り付けます。

レイアウトによって、LEDを取り付けない位置は次の通りです。

| レイアウト | LEDを取り付けない位置 |
| :--: | :-- |
| FW | `L8` `L9`<br>`L24`<br>`L39`<br>`L54` `L55`<br>**`L67`** |
| FW+RE | `L8` `L9`<br>`L24`<br>`L39`<br>`L54` `L55` |

```aside
REレイアウトでは、スイッチを取り付けない位置のLED `L38` `L40` にも、LEDを取り付けます。  
これは、Nora Fearless Wings (DN0031)の設計ミスによるものです。
```

1. 基板を裏側が上になるように置きます。

1. LEDを1個用意して、LEDの発光部分（透明な窓がある部分）が下側になるように持ちます。

1. LEDから出ている4本の端子のうち、角が斜めになっている1本が基板に描かれた印に合うようにして、基板の穴にはめこみます。  
    **注意：行ごとに、LEDを取り付ける方向が異なります。**  
    <!-- 〓DN0032写真　はめこんだようす   -->

    4本の端子が基板に接した状態にします。  
    <!-- 〓DN0032写真　浮いてるNG、ぴったりOK -->

1. はんだごてを用意します。  
  LEDは高温ではんだ付けすると壊れやすいため、こて先温度を少し低めの220-270℃に設定します。

1. 次の手順を「1、2、3、4、5」と数える間におこないます。  

    - 1、2：  
      4本の端子のどれかひとつにこて先をあてて押さえ、端子とパッドを温めます。  

    - 3、4：  
      はんだを端子（またはパッド）に当てて溶かし、端子とパッドにはんだを行き渡らせて、はんだを離します。  
      こて先はグリグリ動かしません。はんだ溶けて、自然に濡れ広がっていくような具合です。  

    - 5：  
      こて先を離します。
      はんだが、端子とパッド全体に行き渡っていれば良い仕上がりです。  

1. LEDが傾いてしまった場合は、ピンセットでLEDをつまみ、はんだ付けした端子をこて先で温めながら傾きを修正します。  
  端子とパッドがずれたりしていなければ、少しくらい傾いていてもLEDの光り具合に大差はありません。

1. 最初にはんだ付けした端子とLED本体を挟んだ反対側の端子2本を、同様の手順ではんだ付けします。

1. 残った1本の端子をはんだ付けします。  
  これで、LED1個の取り付けが完了です。

1. 作業を繰り返し、必要な数のLEDを取り付けます。

<!-- 〓DN0032写真更新
![取り付けたLED](../assets/BuildGuide_DN0031/_DSF0159.jpeg)
取り付けたLED -->

#### LEDの動作確認をおこなう

LEDの点灯状態を見て、正しく取り付けられているか確認します。

1. PCやMacにUSBケーブルで接続します。

1. すべてのLEDが、赤色に点灯することを確認します。

  点灯しないLEDがあったり、色がおかしかったりする場合は、[トラブル対応：LEDの取り付け不良調査](#トラブル対応LEDの取り付け不良調査)を参考にして調査します。

</details>

<!-- 〓DN0032写真　LED取り付け完了（テスト時に光ってるやつ） -->

### Kailh Choc用ソケットを取り付ける

基板裏側へKailh Choc用ソケットを取り付けます。

#### ヒント

- ソケットには正しい取り付け方向があります。  
  基板に描かれた枠をよく見て、正しい方向に取り付けます。

- 基板の左右中央部分、ソケットの外枠だけ描かれ、白く塗られていない箇所には取り付けません。  
  `REレイアウト`では、3行目の中央の左右各1個、基板に`RE → ×`と描かれた2箇所にも取り付けません。

  もし間違って取り付けてしまっても単に使わないだけなので、機能的な問題はありません。

- 1行目と4行目の左端のソケット2個は、ソケットの端子部分が基板から約0.5mm飛び出した状態で取り付けます。

<details>
<summary>《詳しい説明》</summary>

#### ソケット用パッドの片方へ予備はんだする

1個のソケットに対応する2箇所のパッドのうち、どちらか*片方だけ*に予備はんだ（部品の取り付け前にはんだをつけておく）します。

1. 基板を裏側が上になるように置きます。

1. はんだごてを用意します。  
  こて先の温度は320℃程度にします。

1. 次の手順を「1、2、3、4、5」と数える間におこないます。

    - 1、2：  
      予備はんだするパッドにこて先をあてて、温めます。

    - 3：  
      こて先にはんだをあてて溶かします。

    - 4：  
      溶けたはんだがパッド全体に広がったら、はんだを離します。

    - 5：  
      こて先をパッドから離します。

<!-- 〓DN0032写真　予備はんだ -->

#### ソケットの仮置き

ソケットを基板に描かれた枠に合わせ、プラスチックの突起が穴にはまるように仮置きします。  
ソケットを取り付ける方向に決まりがあるので、正しい方向になっているかよく確認します。

<!-- 〓DN0032写真　ソケット方向 -->

1. 基板を裏側が上になるように置きます。

1. ソケットを1個用意し、方向を確認します。

1. 予備はんだしておいた箇所へ、穴に合わせてソケットを置きます。  
  この段階では、ソケットの片方の端子が予備はんだの上に乗り、基板から少し浮いて傾いた状態になります。

    ```aside
    基板の製造ロットによっては、穴が小さい（狭い）ことがあります。
    その場合は、プラスチックの突起を穴に合わせて、ソケットを指で押し込むようにしてはめ込みます。
    ```

#### 予備はんだした端子をはんだ付けする

予備はんだしてある方の端子を、はんだ付けします。

1. はんだごてを用意します。  
  こて先の温度は320℃程度にします。

1. 利き手にはんだごて、もう一方の手にピンセットを持ちます。

1. ピンセットでソケット中央のプラ部分を押さえて動かないようにします。

1. 端子の隙間にこて先を差し込みます。

    <!-- 〓DN0032写真　こて先差し込み -->

1. 次の手順を「1、2、3、4、5、6」と数える間におこないます。

    - 1、2：  
      予備はんだが溶け始めます。  
      ピンセットで押さえていたソケットを軽く押し込むと、ソケットのプラスチックの突起が基板の穴にはまり、浮いていた端子が基板に接します。  

    - 3：  
      こて先をあてたまま、加熱を続けます。  

    - 4：  
      こて先を離します。  

    - 5：  
      ピンセットでソケットを押さえ続けます。  

    - 6：  
      はんだが冷えて固まるのを待ってから、ピンセットを離します。

1. ソケットが基板に描かれた枠に沿ってまっすぐに取り付けられ、傾いていないことを確認します。
  傾いている場合は端子部分を再度加熱し、こて先とピンセットで傾きを修正します。

#### 残りの端子のはんだ付け

残りのもう一方の端子をはんだ付けします。

1. はんだごてを用意します。  
  こて先の温度は320℃程度にします。

1. 残りの端子の隙間にこて先を差し込みます。

1. 次の手順を「1、2、3、4、5、6」と数える間におこないます。

    - 1、2：  
      こて先を差し込んだまま、端子とパッドを加熱します。  

    - 3：  
      パッドと端子の隙間あたりへ、はんだを押し付けて溶かします。  

    - 4：  
      はんだを溶かしながら、端子とパッドの隙間へ流し込みます。  

    - 5：  
      溶けたはんだがパッド全体に広がる程度まで流し込んだら、はんだを離します。  

    - 6：  
      ソケットを動かしてしまわないよう、静かにこて先を離します。

1. はんだ付けした状態を確認します。  
    はんだがパッド全体に広がり、端子の間にポコっと盛り上がって固まっているのが良好な状態です。  

    はんだのパッドへの広がりが足りない場合は、再加熱して、はんだを少し足して塗り広げます。

1. ソケットが枠に沿ってまっすぐに取り付けられていることを確認します。  
    また、ソケットが基板から浮いていないことも確認します。  

    傾いたり浮いたりしている場合は、端子部分を再加熱し、こて先とピンセットで修正します。

    ```aside
    Kailh製のロープロファイルキーキャップを使用する場合は、
    隣同士のキーが当たるのを防ぐため、より一層、ソケットの傾きに注意して取り付けます。
    ```

<!-- 〓DN0032写真　浮いたソケット -->

#### すべてのソケットの取り付け

1. 作業を繰り返して、すべてのソケットを取り付けます。

1. 取り付けが終わったら、**はんだ付けし忘れた箇所がないか、十分確認します**。

</details>

<!-- 〓DN0032写真　ソケット取り付け、できあがり -->

### （該当者のみ）ロータリーエンコーダを取り付ける

*`REレイアウト`を組み立てる場合のみ、この手順を行います。*

基板おもて側の中央へ、ロータリーエンコーダを取り付けます。

#### ヒント

- ロータリーエンコーダの端子や取り付け足が基板裏側から3mm以上飛び出す場合は、3mm以内にカットしてボトムプレートに当たらないようにします。  
  なお、日本国内のキーボード関連ショップで販売されているロータリーエンコーダは3mm以内に収まるものがほとんであり、あまり気にしなくても大丈夫です。  

- ノブ（つまみ）は、スイッチプレートを基板に取り付けた後に取り付けます。

<details>
<summary>《詳しい説明》</summary>

#### ロータリーエンコーダの取り付け

1. 基板をおもて側が上になるように置きます。

1. ロータリーエンコーダのピン（下3本、または上2本と下3本）と、左右の固定足を、基板の取り付け位置に合わせて差し込みます。  
  ピンを曲げないように注意します。

1. ロータリーエンコーダのピンが正しく差し込まれ、傾いていないことを確認します。

1. ロータリーエンコーダが傾かないように注意しながら、基板の裏側が上になるように置き直します。

1. はんだごてを用意します。  
  こて先の温度は320℃程度にします。

1. 次の手順を「1、2、3、4、5、6」と数える間におこないます。

    - 1、2：  
      いずれかのピンにこて先をあてて、温めます。  

      ```aside
      ロータリーエンコーダ左右の固定足は、はんだ付けしません。
      ```

    - 3：  
      こて先にはんだをあてて溶かします。

    - 4：  
      ピンと穴にはんだが流れ込んだら、はんだを離します。

    - 5：  
      こて先を当てたままにします。

    - 6：  
      こて先を離します。

1. はんだ付けした状態を確認します。  
    ピンに沿って、はんだが富士山型に盛り上がっていれば良い状態です。  
    ピンと穴の間に隙間が空いている場合は、再加熱してはんだを足します。

    ロータリーエンコーダが基板にぴったりとくっついて取り付けられていることを確認します。  
    隙間が空いていたり、傾いている場合は、はんだ付けをやり直します。

1. ロータリーエンコーダが基板から浮かないように気をつけながら、残りのピンをはんだ付けします。

<!-- 〓DN0032写真：RE取り付け完了 -->

#### ロータリーエンコーダの動作確認

1. PCやMacにUSBケーブルで接続します。

1. ロータリーエンコーダのつまみを左右に回して、OSの音声出力ボリュームが変化することを確認します。  

1. プッシュボタンスイッチ付きのロータリーエンコーダは、スイッチを押すとOSの音声出力がミュートされることを確認します。  
  プッシュボタンは、組み立て前の確認でおこなった[ソケット用パッドの確認](#ソケット用パッドの確認)と同様に、Remapを使って確認することもできます。

何か問題があった場合は、正しくはんだ付けされているかを確認します。

</details>

### スイッチプレートにスペーサーシートを貼り付ける

基板とスイッチプレートの隙間を埋めるため、スペーサーシートをはさみなどで切り離し、スイッチプレート裏側へ貼り付けます。  

#### ヒント

- スペーサーシートの長さに余裕がないため、無駄のないように貼り付けます。

<details>
<summary>《詳しい説明》</summary>

#### スペーサーシートの貼り付け

1. スイッチプレートを、裏側が上になるように置きます。

1. スイッチプレート裏側に白い線で描かれた貼り付け位置へ、スペーサーシートを貼り付けます。

    シートをはさみなどで切り離し、以下の優先順に貼り付けます。  

    1. 幅が広い箇所  
        シート幅そのままの、10mm幅を貼り付けます。

    1. 幅が中くらいの箇所  
        シートを縦半分に切り、5mm幅を貼り付けます。  
        `USB`と書かれた箇所を避けます。

    1. 幅が狭い箇所のうち、貼り付けサイズが長い箇所  
        シートを縦1/3に切り、約3mm幅を貼り付けます。

    1. 幅が狭い箇所の、残りの箇所  
        すべての位置へ貼り付けできなくでも問題ありません。  
        ひとつ飛ばし（2列に1個、飛び飛び）に貼り付けたりして、バランスよく貼り付けます。

    ```aside
    Raspberry Pi PICOを使用する場合は、`PICO reserved area`と書かれた箇所を避けて貼り付けます。
    ```

</details>

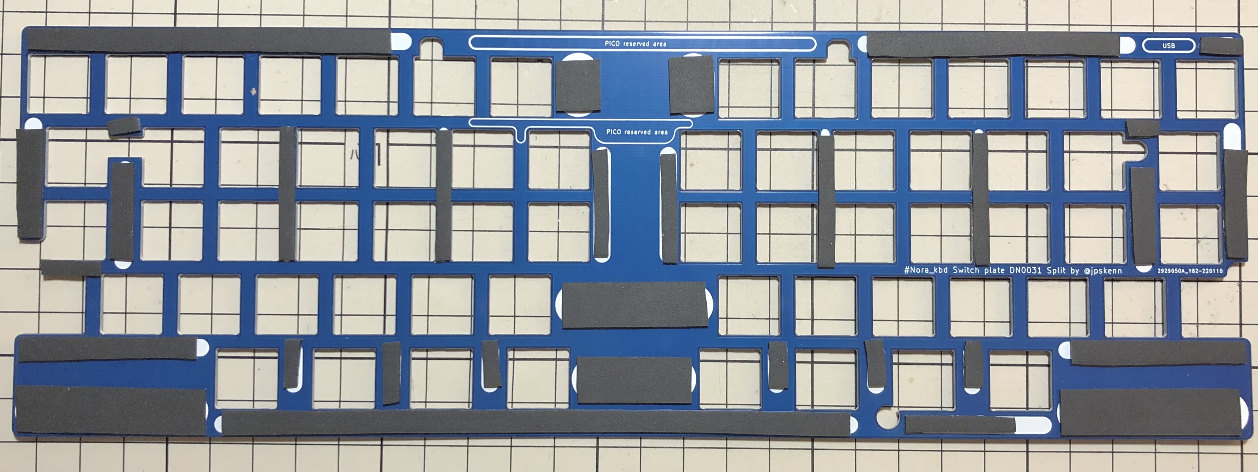
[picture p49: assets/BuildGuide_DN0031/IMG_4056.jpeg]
Put sheet pieces to switch plate

`FWレイアウト`のスイッチプレートへ、スペーサーシートを貼り付けたようす

### スイッチとスイッチプレートを基板へ取り付ける

スイッチプレートをはさむようにして、スイッチを基板に取り付けます。  

#### ヒント

- 最下行の親指部分、左右のスペースキーとして使用するスイッチは、上下逆向きに取り付けます。

- 基板おもて側にネジのアイコンが描かれたスイッチは、この手順では取り付けません。  
  ボトムプレート、またはケースにねじ止めした後に取り付けます。

<details>
<summary>《詳しい説明》</summary>

#### スイッチプレートを仮固定する

スイッチプレートのおもて側から、1・3・5行目の左右の端へ6個のスイッチをはめ込み、スイッチの端子を基板のソケットへはめ込んで仮固定します。

1. スイッチを6個用意します。  
  端子が折れたものは使用できません。曲がっているものは、まっすぐにしておきます。

1. スイッチプレートをおもて側が上になるように置きます。

1. プレートのおもて側から、1・3・5行目の左右の端6箇所に、スイッチをパチンとはめ込みます。  
    スイッチをソケットの方向に合わせるため、スイッチの端子が手前側になるようにします。

    <!-- 〓DN0032写真更新![スイッチプレート取り付けたスイッチ](../assets/BuildGuide_DN0031/_DSF0205.jpeg)
    スイッチプレートに取り付けたスイッチ -->

1. スイッチがプレートの枠から浮いておらず、ぴったり密着してはまっていることを確認します。  
    浮いている場合は、スイッチを押し込んで密着させます。

    <!-- 〓DN0032写真　スイッチとプレートの密着OK NG -->

1. 基板をおもて側が上になるようにして、プレートの隣に置きます。

1. スイッチ6個を取り付けたプレートを、スイッチ端子と基板のソケットの位置が合うようにして、基板に乗せて重ねます。  

1. プレートと基板がずれないように持ち上げます。

1. 基板の裏側を支えながら、どれかひとつのスイッチをまっすぐに押し込んでソケットへ差し込みます。  

    <!-- 〓DN0032写真　スイッチを押し込む様子 -->

1. スイッチがしっかりと差し込まれ、基板にほぼくっついた状態になっていることを確認します。  
    5ピンのスイッチを取り付ける場合は固定用のプラスチックピン2本が根元まで刺さりきっていない場合があるため、よく確認しておきます。

    <!-- 〓DN0032写真　スイッチの押し込まれ具合 -->

1. 同様の手順で、残り5個のスイッチをソケットへ差し込みます。

<!-- 〓DN0032写真更新![基板に取り付けられたスイッチプレート](../assets/BuildGuide_DN0031/_DSF0444.jpeg)  
基板に取り付けられたスイッチプレート -->

#### 残りのスイッチを取り付ける

ケースネジに重なるスイッチを除いて、残りのスイッチをすべて取り付けます。

1. スイッチを用意します。  
    端子が折れたものは使用できません。曲がっているものは、まっすぐにしておきます。

1. プレートにスイッチをはめ込みつつ、そのまま基板のソケットへスイッチ端子を差し込んで、スイッチを取り付けます。
    スイッチを斜めに押し込むと端子が曲がりやすいため、プレート面に対してまっすぐ押し込むようにします。

    最下行の親指部分、左右のスペースキーとして使用するキーは、上下逆向きに取り付けます。

1. ケースネジに重なるスイッチ（基板にネジのアイコンが描かれた箇所）を除き、残りのスイッチをすべて取り付けます。

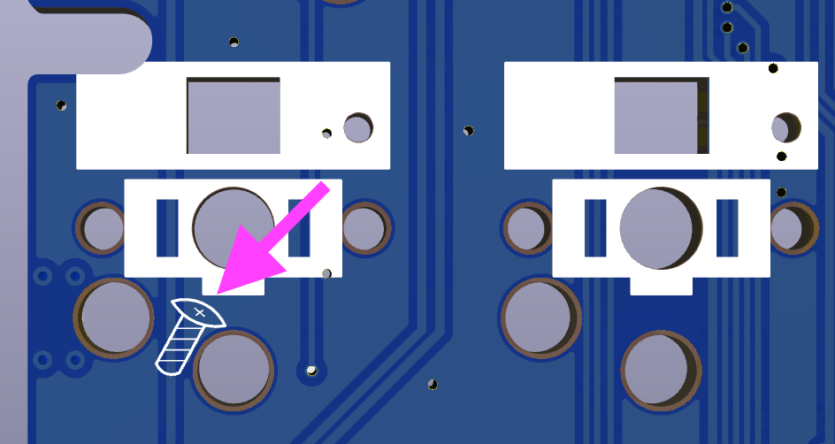
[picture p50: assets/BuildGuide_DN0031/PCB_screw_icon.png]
基板に描かれたネジアイコン
    

</details>

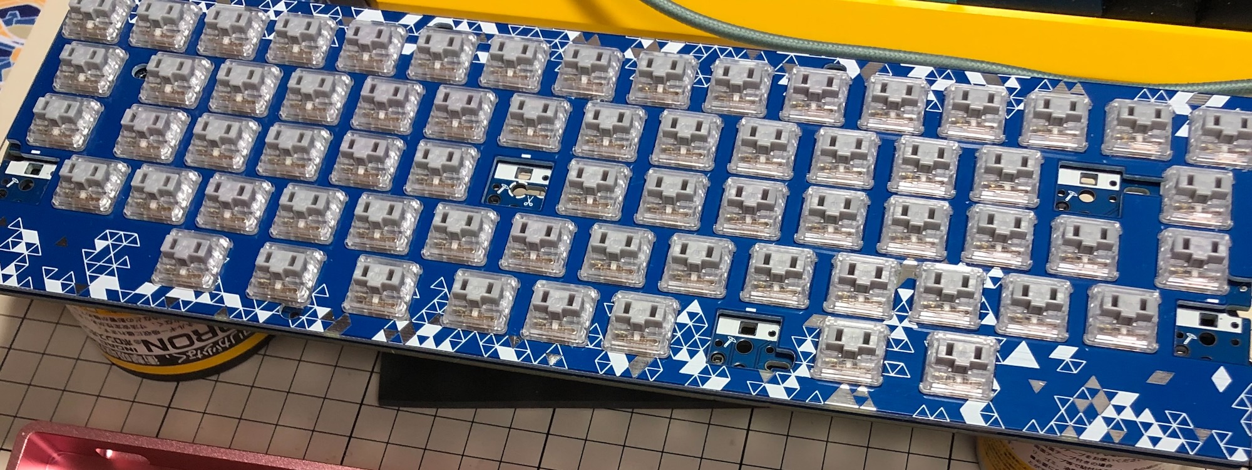
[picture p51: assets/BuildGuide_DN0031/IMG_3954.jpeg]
基板に取り付けられたスイッチとスイッチプレート

基板に取り付けられたスイッチとスイッチプレート

### スイッチの動作確認をおこなう

組み立て前におこなった[ソケット用パッドの確認](#ソケット用パッドの確認)と同様の手順で、ソケットに取り付けたスイッチが正しく動作するか確認します。  
この手順では、取り付けたスイッチを押して確認します。

正常に入力できないスイッチがあった場合は、[トラブル対応：正常に入力できないスイッチの原因調査](#トラブル対応正常に入力できないスイッチの原因調査)の手順に沿って調査します。

### 基板をケース、またはボトムプレートへ取り付ける

スイッチとプレートが組み合わされた基板を、ボトムプレート、またはGH60型, Poker型ロープロファイルケースへ取り付けます。

打鍵感向上に興味のある方は、次の項目をお読みになると何かヒントがあるかもしれません。

- [打鍵感向上：ケース内部の制振と静音化](打鍵感向上：ケース内部の制振と静音化)

#### （該当者のみ）基板をボトムプレートへ取り付ける

*ボトムプレートを使用する場合のみ、この手順をおこないます。*

ネジとスペーサーを使い、ボトムプレートに基板を取り付けます。

<details>
<summary>《詳しい説明》</summary>

1. 以下の写真に示す○印をつけた8箇所に、ボトムプレート裏側からネジ（M2 3mm 低頭）を差し込み、ボトムプレートおもて側へスペーサー（M2 3mm）をねじ止めします。  

    ◎印をつけた右上と中央下の2箇所は、スイッチとの干渉を減らすため、スペーサーを右側へ寄せてねじ止めします。  

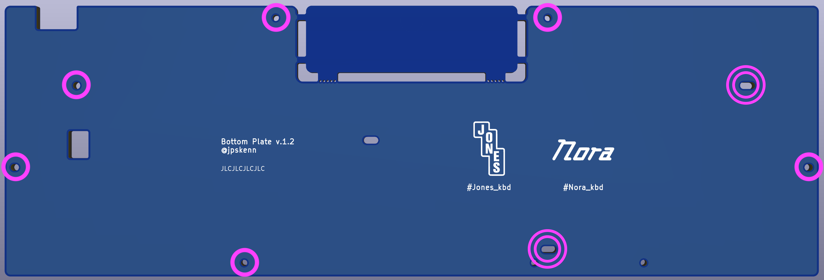
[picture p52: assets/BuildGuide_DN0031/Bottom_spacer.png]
スペーサー取り付け箇所
      
    スペーサー取り付け箇所

1. ボトムプレートをおもて側が上になるように置きます。

1. 基板を、ボトムプレートに取り付けたスペーサーの位置に合わせて乗せます。  
  基板裏側の部品がスペーサーにぶつからないように注意します。

1. （該当者のみ）ロータリーエンコーダの端子や取り付け足が長すぎて、ボトムプレートと干渉していないことを確認します。

  `REレイアウト`を組み立てる場合のみ、この確認を行います。

  干渉している場合、基板裏側からの飛び出しが3mm以下になるように曲げたり、ニッパーなどで切断したりします。

1. 基板おもて側から、ネジ（M2 3mm 低頭）を使い、基板とスペーサーをねじ止めします。  

    <!-- 〓DN0032写真更新![基板とボトムプレートをねじ止めした状態](../assets/BuildGuide_DN0031/_DSF0228.jpeg)  
    基板とボトムプレートをねじ止めした状態 -->

1. まだ取り付けていないスイッチを、すべて取り付けます。

1. ボトムプレート底面に、滑り止めのゴム足を貼り付けます。

</details>

<!-- 〓DN0032写真![ボトムプレート取り付け完了](../assets/BuildGuide_DN0031/DSCF0464.jpeg)  
ボトムプレート取り付け完了 -->

#### （該当者のみ）GH60型, Poker型ケースへ取り付ける

*GH60型, Poker型ケースを使用する場合のみ、この手順をおこないます。*

ケースに基板をねじ止めして取り付けます。

<details>
<summary>《詳しい説明》</summary>

1. ケース付属のネジ止め式の足を使用する場合は、最初に取り付けておきます。

1. ケースを安定したところへ置きます。

1. スイッチとスイッチプレートが組み合わされた基板を手に持ちます。

1. 基板を水平から30度くらいの角度に持ち、奥側から斜めにケース内へ入れていきます。  
  斜めに差し込んでいくと、USBコネクタがケースの穴にスッとはまります。

1. USBコネクタがはまった状態で基板の手前側を静かに下ろして水平にします。  
    力をかけることなく、基板全体がストンとケースに入ります。  
    力を入れてグリグリとこじったりググググッと押し込むようなことはせず、斜めに差し込んで、水平にするだけです。

    <!-- 〓DN0032写真更新![30度で差し込む](../assets/BuildGuide_DN0031/_DSF0241.jpeg)  
    30度で差し込む -->

1. ケース付属のネジで、左上と右上の2箇所を仮固定します。

1. キット同梱のネジ（M2 4mm 低頭）で、左端、右端、中央、中央下の4箇所を仮固定します。

1. ケースに対して、基板の位置が上下左右の真ん中になるように調整します。

1. ネジが軽く止まる程度まで締めて基板を固定します。

1. （該当者のみ）ケース中央のネジ穴に重なるスイッチを、足を加工して取り付けます。  

    *`FWレイアウト`を組み立てる場合のみ、この作業を行います。*

    3ピンのスイッチは、加工不要で、そのまま取り付けできます。  
    5ピンのスイッチを使用する場合は、左右2本のプラスチックピンのうちネジ穴に干渉する方の足を、根本からニッパーなどで切断します。

    <!-- 〓DN0032写真　5ピンの片足をカット -->

    おそらく回避できるはずですが、もしスイッチの中央の足が干渉する場合は、中央の足も切断します。

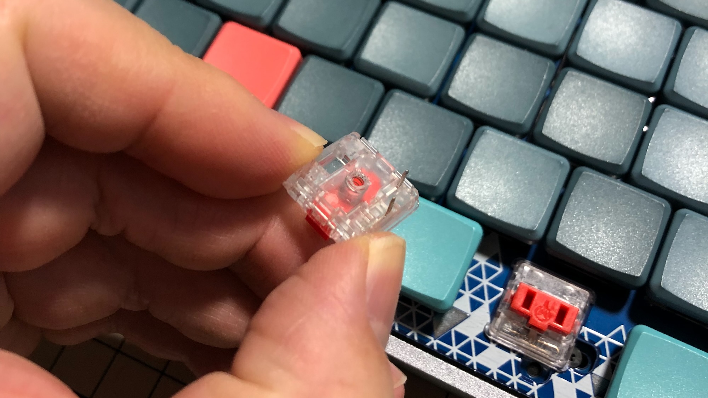
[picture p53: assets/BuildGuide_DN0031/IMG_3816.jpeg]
中央の足をカットしたスイッチ
      
    中央の足をカットしたスイッチ

1. 残りのスイッチを、すべて取り付けます。

1. ケース底面に、滑り止めのゴム足を貼り付けます。

</details>

<!-- 〓DN0032写真　ケース取り付け完了 -->

### スイッチの最終動作確認をおこなう

組み立て前におこなった[ソケット用パッドの確認](#ソケット用パッドの確認)と同様の手順で、すべてのスイッチが正しく動作するか最終確認します。  

### 仕上げ

1. キーキャップ、ロータリーエンコーダのノブを取り付けます。

1. Remapでキーマップを変更したり、ファームウェアをカスタマイズして、自分好みに仕上げます。

1. 完成です。

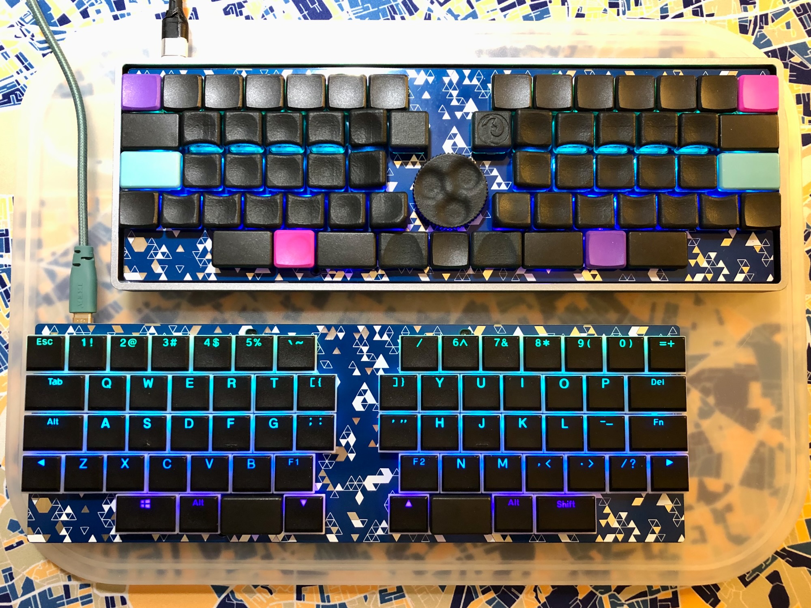
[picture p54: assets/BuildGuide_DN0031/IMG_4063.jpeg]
製作例
  
製作例  

- 上： `REレイアウト`  
  キーキャップ： Gravity Keycaps & MBK  
  ロータリーエンコーダ： ALPS EC12E2440301（貫通軸）  
  ロータリーエンコーダ ノブ： ロープロ用ノブ FLAT 33mm by Daily Craft Keyboard  
  ケース： KBDfans 60% ALUMINUM LOW PROFILE CASE, Gray  

- 下： `FWレイアウト`  
  キーキャップ： Kailh製のロープロファイルキーキャップ & MBK  
  ケース： 同梱ボトムプレート

写真を撮影し、`#Nora_kbd` のタグをつけてツイートすると設計者が喜んだりします。  
[Twitter: #Nora_kbd](https://twitter.com/search?q=(%23nora_kbd)&src=typed_query&f=live)

---

## 参考

打鍵感向上や機能追加についてのDIY情報や、トラブル調査方法などの参考資料です。  
必要に応じてお読みください。

### 打鍵感向上：ケース内部の制振と静音化

ケースやボトムプレートに工夫を施すことで、打鍵感を向上させる方法について説明します。

<details>
<summary>《詳しい説明》</summary>

- ケースの振動防止

    ケース内部におもりを入れておくと、ケースの共振が抑えられ、打鍵感の向上や、打鍵音の変化が期待できます。  
    おもりには、10円玉、真鍮板、自動車タイヤ用のホイールバランスウェイト、鉛シートなどを使用します。  
    また、スポンジ状の両面テープなどを使っておもりを貼り付けると、より高い防振効果を得ることができます。

    基板裏側の部品におもりの金属部分がふれてショートしないよう、スポンジシートを間に挟んだり、カプトンテープなどで保護します。

- 基板の振動防止

    基板とケース間をウレタンスポンジやシリコンシートなどで埋めると、基板の振動を抑えることができます。  
    また、ケース内部の空間を埋めることで、基板の振動音やスイッチの動作音がケース内で響くのを減らすことができます。

    ボトムプレートを使用する場合も、基板とボトムプレートの間に対策を施すことで、同様の効果が期待できます。

    スポンジなどを詰めすぎると、ネジや基板裏側の部品に力がかかるため、ほどよい程度に調節します。

これらの工夫をおこなう様子はこちら  
→[ケースが響いてうるさいのをなんとかしていく](https://twitter.com/jpskenn/status/1467010813773119490)

</details>

### トラブル対応：正常に入力できないスイッチの原因調査

正常に入力できないスイッチの原因調査と対応方法について説明します。  

<details>
<summary>《詳しい説明》</summary>

テスターをお持ちの方は、疑わしい箇所をテスターで調べるのが手っ取り早い方法ですので、積極的に使用してください。

#### スイッチのソケットへの取り付け不良

もっとも多い原因は、スイッチのソケットへの取り付け不良です。  

スイッチを取り外し、端子が曲がったり折れたりしていないか確認します。  
端子の曲がりを修復するか、新しいスイッチに交換して、もう一度キー入力を確認します。

#### ソケットの取り付け不良

次に多いのが、ソケットの取り付け不良です。  

ソケットのはんだ忘れや、はんだが適切に行われていないことが原因のため、ソケットのはんだ状態を確認します。  
溶けたはんだがパッド全体に広がっていること、はんだがソケットの端子の間にポコっと盛り上がって固まっていることも確認します。  

念のため、再度はんだ付けし直して、もう一度キー入力を確認します。

#### 原因箇所の特定

スイッチとソケットの取り付け不良を調査しても改善しなかった場合、原因箇所の特定をおこないます。

組み立て前におこなった[ソケット用パッドの確認](#ソケット用パッドの確認)と同様の手順で、基板のパッド部分をピンセットでショートさせ、キー入力できるか確認します。  
パッドをショートしてキー入力できた場合は、パッド自体は正常ですので、スイッチとソケットを再度調査します。

#### キー入力が確認できない場合

この場合は、ソケット用パッドや基板の配線、その他の基板に取り付けられた部品が、組み立て中にダメージを受けたことが原因と考えられます。

これ以降の調査と修復の難易度が高くなりますが、ソケット用パッドが剥がれてソケットが取り付けられないというような物理的に破壊された状態を除けば、修復できる可能性は残されています。  
（パッドが剥がれたとしても、ネジ穴に重なるスイッチでなければ、スイッチを固定してソケットを端子に差し込んで、ソケットから基板へ配線すればなんとかなります。）

電子工作に詳しい方であれば、[Nora, DN0031関連ファイル](https://github.com/jpskenn/Nora/releases/tag/DN0031)の`PCB_FW`フォルダ内のKiCadプロジェクトを参考にテスター等を用いて調査を進め、ジャンパ線などで配線を修復してください。

自分ではどうにもできない場合など、何らかのアドバイスを必要とされる方は、キット同梱のリーフレットに記載された連絡先へ問い合わせてください。  
状況に応じて、できる限りのサポートをいたします。  

</details>

### トラブル対応：LEDの取り付け不良調査

LEDが点灯しない場合など、LEDの取り付け不良を調査する方法について説明します。

<details>
<summary>《詳しい説明》</summary>

調査の前提として、LEDの点灯には、

```text
点灯しないLEDより後ろは、すべて点灯しない。
```

というルールがあります。

例えば、
`L1` `L2`が点灯し、`L3`が点灯しないとき、
`L4`より後ろは、正しく取り付けられていたとしても、点灯しません。

このルールをふまえ、点灯しない最初のLEDから順番に調査を進めていきます。

#### LEDがひとつも点灯しない場合

LEDがひとつも点灯しない場合は、LEDに電源が供給されていないことが原因のひとつと考えられます。

ジャンパ`JP3: Device VDD source`が、正しい位置（通常は`Onboard`）にジャンパされていることを確認します。  

ジャンパ位置が合っている場合も、念のため、ジャンパをやりなおしておきます。

正しい位置にジャンパしていても点灯しない場合は、1個目のLEDの取り付け不良が疑われます。  

MCUとジャンパの組み合わせは次の通り。

| MCU | ジャンパ位置 | 備考 |
| :--: | :--: | :-- |
| ATmega32u4 | `Onboard` | 通常の組み合わせ |
| Raspberry Pi PICO | `PICO VBUS` | Raspberry Pi PICO使用時 |

#### LEDの光り方がおかしい場合

LEDがちらついたり、色がおかしい場合は、LEDのはんだ不良が疑われます。

光り方がおかしいLEDのはんだ付けをやり直します。

フラックスがある場合は、LEDの端子に塗布しておくと、はんだがダマになりにくくなります。  
はんだ吸い取り線がある場合は、一旦はんだを除去しておきます。  
どちらもない場合は、はんだを足しながら、はんだ付けをやり直します。

#### LEDが点灯しない場合

正しくジャンパしていてもLEDが点灯しない場合は、LEDの取り付けまたはLED自体に原因があると考えられます。  
LEDの点灯に関するルールにしたがい、**光らないLEDの、番号が若いものから順番に**以下の対処を行います。

1. 光らないLEDのはんだ不良を修復する

    「光らないLEDが正しくはんだ付けされていない」と仮定した対処です。  
    光らないLEDのはんだ付けをやり直します。

1. 光らないLEDの*ひとつ前*のLEDのはんだ不良を修復する

    「光らないLEDは正常に取り付けられているが、*ひとつ前*のLEDのはんだ不良が原因で配線がつながっていない」と仮定した対処です。  
    光らないLEDの*ひとつ前*のLEDのはんだ付けをやり直します。

1. 光らないLEDを新しいものに交換する

    「光らないLEDが壊れてしまっている」と仮定した対処です。  
    これまでの対処をおこなっても点灯しない場合は、光らないLED自体が壊れていると判断して、新しいものに交換します。

    以下のような方法で、LEDを取り外すことができます。

    - 少しずつ持ち上げる方法
      強く持ち上げるとパッドが剥がれてひどいことになるので、力をかけずに少しずつ持ち上げます。

        1. こて先の温度を320℃程度にします。
        1. はんだ吸い取り線で、できる限りのハンダを除去しておきます。
        1. 片側2本の端子を同時に加熱しながら、ピンセットでLEDを少しだけ持ち上げます。
        1. 反対側の2本の端子も、同様にして、少しだけ持ち上げます。
        1. これを交互に繰り返し、じわりじわりと取り外していきます。

    - 熱々にして持ち上げる方法
      溶けたはんだで火傷しないように注意します。

        1. こて先の温度を320℃程度にします。
        1. LEDの端子部分を温め、はんだをたーーーーーーっぷりと溶かし、端子部分につけておきます。  
        （あずき〜大豆くらいの大きさの溶けたはんだ）
        1. 反対側の端子にも、同じようにはんだをたっぷりとつけます。
        1. LEDのプラ部分をピンセットつまみます。
        1. LEDの両側のはんだを交互に2秒ずつ温めるのを繰り返し、両側のはんだが溶けた状態にします。
        1. その状態でLEDをつまみ上げて、基板から取り外します。

</details>

### 資料：ファームウェアの書き込み方法

QMK ToolboxやRemapを使用して、ビルド済み（＝作成済み）のファームウェアを書き込みます。  

**ファームウェアを書き込んで初めてRemapに接続した際、キーボードレイアウト画面が表示されるまで30秒〜1分ほどかかる場合があります。**  
EEPROMの初期化処理がおこなわれていますので、キーボードの準備が整うまでしばらくお待ちください。  
2回目以降の接続では、すぐに接続されます。

#### QMK Toolboxを使用して書き込む方法

[QMK Toolbox](https://github.com/qmk/qmk_toolbox/releases)を使用してビルド済み（＝作成済み）のファームウェアを書き込む方法について説明します。

QMKファームウェアのドキュメント[ファームウェアを書き込む](https://docs.qmk.fm/#/ja/newbs_flashing?id=ファームウェアを書き込む)も、あわせてご覧ください。

<details>
<summary>《詳しい説明》</summary>

1. [資料：Nora, Fearless Wings (DN0031)関連ファイル](#資料nora-fearless-wings-dn0031関連ファイル)に記載のダウンロード先から、キーボードのレイアウトに応じたビルド済みのファームウェアをダウンロードします。

1. [QMK Toolbox](https://github.com/qmk/qmk_toolbox/releases)をダウンロードし、起動します。

1. `Open`ボタンを押し、QMK Toolboxで、ダウンロードしておいたファームウェアを開きます。

1. `Nora`キーボードをDFU (Bootloader)モードにします。
    1. USBケーブルが接続されている場合は、ケーブルを抜きます。
    1. キーボードの**左上**のキーを押したまま、USBケーブルを差し込みます。

1. QMK Toolboxの画面に、以下のメッセージが表示されます。  
    （もし表示されない場合は、USBケーブルを接続した状態で、基板裏側のリセットボタンを押します）

    ```text
    *** Atmel DFU device connected: ATMEL ATm32U4DFU (03EB:2FF4:0000)
    ```

1. QMK Toolboxの`Flash`ボタンを押すとファームウェアの書き込みが始まります。  
    5秒程度で書き込みが終わり、QMK Toolboxの画面に以下のような書き込み完了メッセージが表示されます。（サイズ表記などの、細かい部分は実際とは異なります）

    ```text
    *** Attempting to flash, please don't remove device
    >>> dfu-programmer atmega32u4 erase --force
        Erasing flash...  Success
        Checking memory from 0x0 to 0x6FFF...  Empty.
    >>> dfu-programmer atmega32u4 flash --force /Users/jpskenn/qmk_firmware/nora_v01_via.hex
        0%                            100%  Programming 0x5E80 bytes...
        [>>>>>>>>>>>>>>>>>>>>>>>>>>>>>>>>]  Success
        0%                            100%  Reading 0x7000 bytes...
        [>>>>>>>>>>>>>>>>>>>>>>>>>>>>>>>>]  Success
        Validating...  Success
        0x5E80 bytes written into 0x7000 bytes memory (84.38%).
    >>> dfu-programmer atmega32u4 reset
    *** Atmel DFU device disconnected: ATMEL ATm32U4DFU (03EB:2FF4:0000)
    ```

    書き込み完了メッセージが表示されたら、QMK Toolboxを終了してもかまいません。  

    これとは違うメッセージ（書き込み失敗など）が表示された場合は、スクリーンショットを撮ったり、メッセージをコピーしておくと、何らかのサポートを受ける場合にスムースに話が進みます。

1. 書き込みが終わってから10秒ほど待つと、キーボードが起動し、キー入力できるようになります。  
  ファームウェアを書き込んだ後、初回起動時に外部EEPROMの消去をおこなっています。  
  この消去処理に10秒ほどかかっています。

1. リセットボタンを使ってDFUモードにする操作をおこなった場合は、[資料：EEPROMを消去して、初期状態に戻す方法](#資料eepromを消去して-初期状態に戻す方法)を実施します。

以上でファームウェアの書き込み作業は完了です。

</details>

#### Remapを使用して書き込む方法

Remapを使用して書き込む手順を説明します。

<details>
<summary>《詳しい説明》</summary>

Remapを使用して書き込む手順を説明します。

1. 基板の裏側が上になるように置きます。

1. 基板をPCやMacとUSBケーブルで接続します。

1. Google Chromeブラウザで、[Remap](https://remap-keys.app/)のページを開きます。

1. `KEYBOARD CATALOG`をクリックし、`Nora`を検索して開きます。  

1. `FIRMWARE`と書かれたところをクリックして、ファームウェアのリストを表示します。

    Remap catalog, Nora

1. リストから`REレイアウト`用のファームウェア`Nora DN0031, VIA + RE`を探し、`FLASH`を押します。

    Firmware list

1. Flash Firmwareのポップアップ画面のBootloaderの項目で、`dfu`を選択し、右下の`FLASH`を押します。

    Select dfu

1. 接続要求画面が表示されたら、基板裏側の`Reset`と書かれたスイッチを押します。

    Reset switch

1. 接続要求画面に`ATm32U4DFU`が表示されるので、これを選択して`接続`ボタンを押します。

    Select dfu

1. ファームウェアの書き込みが始まり、10秒程度で書き込みが完了します。

    Select dfu

    メッセージの最後に、

    ```text
    Writing the firmware finished successfully.
    ```

    と表示されていれば、書き込み成功です。

以上でファームウェアの書き換えは完了です。

</details>

### 資料：初期ファームウェアの機能と設定値

出荷時に書き込まれている初期ファームウェアの機能と設定値を説明します。

<details>
<summary>《詳しい説明》</summary>

- キーマップ書き換えツール

    RemapやVIAに対応。

- レイヤー

    7個のレイヤーを使用できます。  
    レイヤー構成とレイヤーインジケータLEDの色は次の通りです。

    | No. | レイヤー名 | 主なキー割り当て | レイヤーインジケータLEDの色<br>左スペース, 右スペース |
    | :-: | :-- | :-- | :-: |
    | 0 | ベースレイヤー #1 | 英語配列<br>Macモディファイア | 未割り当て<br>（RGB Matrixのエフェクト色） |
    | 1 | ベースレイヤー #2 | 英語配列<br>Windowsモディファイア | 青, 青 |
    | 2 | ベースレイヤー #3 | ”SemiErgo”風<br>Macモディファイア | 黄, 黄 |
    | 3 | Lower | ファンクションキー, 記号, ボリューム | 緑, 緑 |
    | 4 | Raise | ファンクションキー, 数字, カーソル移動 | 水, 水 |
    | 5 | Func | （未設定） | 白, 白 |
    | 6 | Adjust | 各種設定, スクロールロックなど | 赤, 赤 |

    CapsLockがONのときは、左スペースのインジケータLEDが紫色になります。

- イルミネーションLED  

    全キーのLEDによる、RGB Matrix Lighting。  
    初期状態のエフェクトは、単色の赤色。  

- レイヤーインジケータLED  

    左スペースと右スペースの2個をLEDをレイヤーインジケータとして使用し、レイヤーの状態を表示します。  
    表示色はレイヤーの項目に記載しています。

- ロータリーエンコーダ

    `REレイアウト`はロータリーエンコーダを使用できます。

- 組み込み機能

    キーコード `KC_FNx` （xには数字が入ります）を使用することで、ファームウェア内の組み込み機能を使用できます。

    | キーコード | 機能 |
    | :-- | :-- |
    | `KC_FN0` | :information_source: ファームウェアのバージョン情報を文字列として出力します。 |
    | `KC_FN1` | レイヤー0をデフォルトレイヤーにします。<br>:floppy_disk: EEPROMにデフォルトレイヤーを保存します。 |
    | `KC_FN2` | レイヤー1をデフォルトレイヤーにします。<br>:floppy_disk: EEPROMにデフォルトレイヤーを保存します。 |
    | `KC_FN3` | レイヤー2をデフォルトレイヤーにします。<br>:floppy_disk: EEPROMにデフォルトレイヤーを保存します。 |
    | `KC_FN4` | レイヤーインジケータLEDのON/OFFを切り替えます。<br>全キーでRGB Matrixのエフェクトを楽しむことができます。 :smiley: |

    Remapでは、`SPECIAL`の`FUNC`がこれらのキーコードに該当します。  
    `KC_FN0`には`Func0`が対応します。

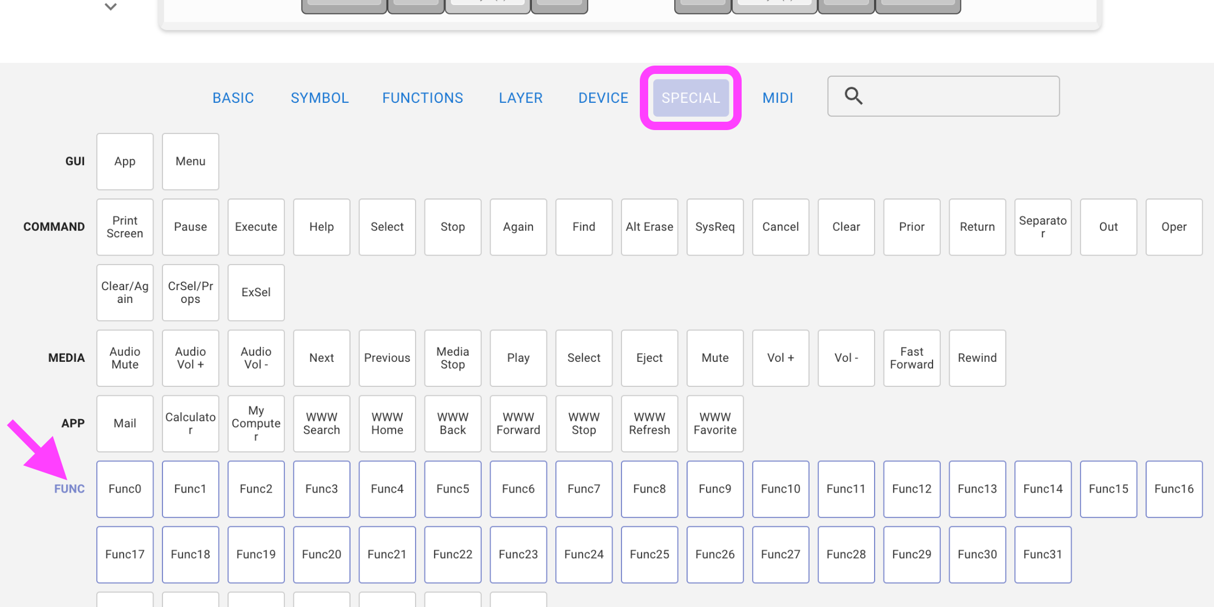
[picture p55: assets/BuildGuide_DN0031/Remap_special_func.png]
Remap, FUNC
    

</details>

### 資料：EEPROMを消去して、初期状態に戻す方法

キーマップやLEDの表示モードなどのEEPROMに記録されているデータを消去し、初期状態に戻すことができます。  

また、古いデータが残って動作がおかしくなるのを防止するため、リセットボタンを使用してファームウェアを書き込んだ際にもこの操作をおこないます。

<details>
<summary>《詳しい説明》</summary>

1. USBケーブルを接続している場合は、ケーブルを抜きます。

1. キーボードの左上のキーを押したまま、USBケーブルを差し込みます。

1. ケーブルを差し込んで、1、2と数えてから、USBケーブルを抜きます。

1. USBケーブルを差し込みます。

1. 10秒ほど待つとキーボードが起動します。

以上でEEPROMが消去され、初期状態に戻ります。

</details>

### 資料：Nora, Fearless Wings (DN0031)関連ファイル

キーボードに関連するファイルをまとめています。

<details>
<summary>《詳しい説明》</summary>

- ビルド済みのファームウェア

  - `FWレイアウト`用  
      [nora_v031_via.hex](https://gist.github.com/jpskenn/91e35665ae5ee15672c2e424c2413d76)

  - `REレイアウト`用  
      [nora_v031_via_re.hex](https://gist.github.com/jpskenn/382f63057c083185cbfafc225f198880)

- ファームウェアのソース

    私がQMKからフォークしたリポジトリ [https://github.com/jpskenn/qmk_firmware](https://github.com/jpskenn/qmk_firmware) に配置しています。  

    [develop_nora](https://github.com/jpskenn/qmk_firmware/tree/develop_Nora)ブランチの、`keyboards/nora/v031`に関連ファイルが格納されています。

- Remap / VIA用キーボード定義ファイル

    [nora_via_v031.json](https://gist.github.com/jpskenn/7fac7a9bc819f2d4a7f97086cdd32fdd)

- その他、基板等の設計ファイルなど

    [コミット：3f4362b](https://github.com/jpskenn/Nora/commit/3f4362bb6b757813834f63c2ab42a17b1bfa9681)の内容を、[DN0031タグ](https://github.com/jpskenn/Nora/releases/tag/DN0031)にまとめてあります。

</details>

### 資料：Raspberry Pi PICOによる動作（実験的機能）

DIYの実験的機能として、Raspberry Pi PICO（以下、PICOと呼びます）を使用して、キーボードを動作させることができます。

<details>
<summary>《詳しい説明》</summary>

#### PICOを使用して、できること

- キーマトリクスの駆動
- LEDの点灯（16個までの点灯を確認済み）

#### PICOを使用して、できるかもしれないこと

以下は、動作未確認の項目です。

- すべてのLEDの点灯
- EEPROMや、その他のI2C接続された機器との通信
- 未割り当てのGPIOピンの使用

#### 使用時の注意

- GH60型，Poker型ケースには、（たぶん）取り付けできません。  
  取り付けられたとしても、ケーブルの取り回しを工夫する必要があります。

- 基板のジャンパを変更して使用します。  
  [PICO使用時の設定](#PICO使用時の設定)を参照。

#### 接続図

PICOの接続図は以下の通り。

Pi PICO wiring

#### 取り付け

コンスルーを使用する場合、20ピン（高さ2mm以上）のものが使用できます。

基板とスイッチプレートの間隔が1mmしかないため、コンスルーが奥まで刺さり切らない場合があります。  

ボトムプレートに取り付ける場合は、プレート中央部を切り離します。  
L字型のコネクタをもつUSBケーブルを使用すると、すっきりとおさまります。

#### PICO使用時の設定

必要に応じて基板裏側のジャンパを設定してください。

- `JP3:Device +5 source`：LED, EEPROMへの電源供給元

    | ジャンパ設定 | LEDの電源供給元 | 備考 |
    | :-: | :-- | :-- |
    | PICO VBUS | PICOのVBUS ||
    | Onboard | 基板に接続したUSBのVCC | オンボードのMCU、ATmega32u4使用時のデフォルト設定|
    | オープン | 接続なし ||

- `JP1`,`JP2`：I2Cプルアップ抵抗（4.7KΩ）への接続

    | ジャンパ設定 | I2Cプルアップ抵抗への接続 | 備考 |
    | :-: | :-- | :-- |
    | ブリッジ | プルアップ抵抗へ接続 | オンボードのMCU、ATmega32u4使用時のデフォルト設定|
    | オープン | 接続なし ||

#### ファームウェア

- [PRK Firmware](https://github.com/picoruby/prk_firmware)

  以下の基本的な動作を確認済みです。

  - 全キーの入力
  - LED点灯（16個まで）

  動作確認に使用したファームウェアはこちら：[keymap.rb](../Firmware/prk_nora/)

</details>

## サービスマニュアル

基板の準備など、出荷前作業について。

### パーツリスト

| 部品名 | 個数 | 備考 |
| :---- | :-----: | :---- |
| USBコネクタ<br>USB4085-GF-A | 1 ||
| ESD<br>PRTR5V0U2X | 1 ||
| FUSE<br>0ZCJ0050AF2E | 1 ||

### 基板セットアップ

1. 部品取り付け

    1. 基板裏側からUSBコネクタを取り付ける

        テスターでピンを確認する。
        <!-- 〓更新![USBコネクタ接続図](../assets/BuildGuide_DN0031/USB_wireing.png)  
        USBコネクタ接続図 -->

    1. 基板裏側へESDを取り付ける

        <!-- 〓更新![ESD placement direction](../assets/BuildGuide_DN0031/IMG_3834.jpeg)
        ESD取り付け方向 -->

    1. 基板裏側へFUSEを取り付ける

    1. リセットスイッチを取り付ける

1. ジャンパ

    1. I2Cプルアップ抵抗、2箇所をジャンパする

    1. デバイス電源をジャンパする  
      `JP3: Device VDD source` → `Onboard`

1. 電源がショートしないことを確認

    1. `ICSP`ピンの`+5V`と`GND`が導通しないことをテスターで確認。

1. ファームウェア書き込み

    1. PC/Macへ接続し、デバイス`Nora`として認識されていることを確認する

    1. QMK Toolboxを起動してファームウェアをロード

    1. 基板のリセットスイッチを押す

    1. `Flash`で書き込む

    1. Remapで全キーのパッドを確認する

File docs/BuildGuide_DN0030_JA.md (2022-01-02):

# Nora, Fearless Wings (DN0030) ビルドガイド

購入していただいた方、リポジトリから製造していただいた方、その他の皆様、Noraに興味を持っていただきありがとうございます。

このドキュメントは、Nora, Fearless Wings (DN0030)を組み立てるためのビルドガイドです。  
Noraのコンセプトや特徴、ビルド例などについては、[README](https://github.com/jpskenn/Nora/README.md)をご覧ください。

ビルドガイド全体に目を通して作業手順を把握しておくとミスの防止につながりますので、ぜひ、一度お読みになってから組み立て作業を始めてください。

作業手順をしっかりと確認しながら組み立てたい方は、

<details>
<summary>《詳しい説明》</summary>

ここに追加の説明を表示します。
</details>

と書かれたところをクリックすると、追加の説明が表示されます。

---

## 目次

<!-- @import "[TOC]" {cmd="toc" depthFrom=2 depthTo=3 orderedList=false} -->

<!-- code_chunk_output -->

- [目次](#目次)
- [Nora, Fearless Wings (DN0030)の特徴, 機能](#nora-fearless-wings-dn0030の特徴-機能)
- [注意事項、制限など](#注意事項-制限など)
- [部品リスト](#部品リスト)
  - [キット内容](#キット内容)
  - [別途用意が必要な部品](#別途用意が必要な部品)
  - [オプション部品](#オプション部品)
- [組み立てに必要な工具](#組み立てに必要な工具)
- [組み立て前の確認](#組み立て前の確認)
  - [同梱物の確認](#同梱物の確認)
  - [接続の確認](#接続の確認)
  - [ソケット用パッドの確認](#ソケット用パッドの確認)
- [組み立て手順](#組み立て手順)
  - [（オプション）LEDを取り付ける](#オプションledを取り付ける)
  - [Kailh Choc用ソケットを取り付ける](#kailh-choc用ソケットを取り付ける)
  - [スイッチプレートにスペーサーシートを貼り付ける](#スイッチプレートにスペーサーシートを貼り付ける)
  - [スイッチとスイッチプレートを基板へ取り付ける](#スイッチとスイッチプレートを基板へ取り付ける)
  - [スイッチの動作確認をおこなう](#スイッチの動作確認をおこなう)
  - [基板をケース、またはボトムプレートへ取り付ける](#基板をケース-またはボトムプレートへ取り付ける)
  - [スイッチの最終動作確認をおこなう](#スイッチの最終動作確認をおこなう)
  - [仕上げ](#仕上げ)
- [参考](#参考)
  - [打鍵感向上：ケース内部の制振と静音化](#打鍵感向上ケース内部の制振と静音化)
  - [トラブル対応：正常に入力できないスイッチの原因調査](#トラブル対応正常に入力できないスイッチの原因調査)
  - [トラブル対応：LEDの取り付け不良調査](#トラブル対応ledの取り付け不良調査)
  - [資料：ファームウェアの書き込み方法](#資料ファームウェアの書き込み方法)
  - [資料：初期ファームウェアの機能と設定値](#資料初期ファームウェアの機能と設定値)
  - [資料：Noraキーボードのファームウェア](#資料noraキーボードのファームウェア)
  - [資料：EEPROMを消去して、初期状態に戻す方法](#資料eepromを消去して-初期状態に戻す方法)
  - [資料：Nora, Fearless Wings (DN0030)関連ファイル](#資料nora-fearless-wings-dn0030関連ファイル)
  - [資料：Raspberry Pi PICOによる動作（実験的機能）](#資料raspberry-pi-picoによる動作実験的機能)
- [サービスマニュアル](#サービスマニュアル)
  - [パーツリスト](#パーツリスト)
  - [基板セットアップ](#基板セットアップ)

<!-- /code_chunk_output -->

---

## Nora, Fearless Wings (DN0030)の特徴, 機能

- 狭ピッチ
- Jonesゆずりのキーレイアウト
- 左右に大きく離れたアルファ部
- Choc v1スイッチと、MBK、またはそれ以下のサイズのキーキャップに合わせた専用設計
- RemapやVIAなどのキーマップ書き換えツールに対応したファームウェアを書き込み済み
- 外部EEPROM（8KB）を搭載し、十分な数のレイヤーを使用可能
- GH60型やPoker型に互換性のあるロープロファイルケースに対応  
  専用ボトムプレートと組み合わせて、ケースレスで高さを抑えて使用することも可能。
- オプションとして、以下のハードウェア機能を使用可能
  - レイヤーインジケータ／イルミネーションLED
  - Raspberry Pi PICOによる動作（実験的機能）
- 細かな部品を実装済み

## 注意事項、制限など

- キーキャップ

  MBK、またはそれ以下のサイズのキーキャップに合わせて設計されています。  
  Kailh製のロープロファイルキーキャップ（[遊舎工房：Kailhロープロ刻印キーキャップ](https://shop.yushakobo.jp/collections/keycaps/products/pg1350cap-doubleshot)）は隣同士のキーが干渉する可能性があるため、ご自身の責任で使用してください。  
  （こちらで試した限りでは全てのキーが干渉せずに使用できましたが、ギリギリすぎるため保証できかねます。）

- スイッチの加工

  GH60型, Poker型ケースを使用する場合、ケース中央のネジ穴に重なるスイッチは、スイッチの足の加工（切断）が必要です。

- ケースへの取り付け

  GH60型, Poker型のネジ穴位置に対応するように設計していますが、もしかしたら取り付けできないケースがあるかもしれません。  
  ここに記載していないケースへの取り付けの成功／失敗の報告を、随時募集しています。

  取り付け確認済みのケースは次の通りです。  
  - [KBDfans 60% ALUMINUM LOW PROFILE CASE](https://kbdfans.com/collections/60-layout-case/products/customized-gh60-aluminum-case)
  - [Jones / Nora用ボトムプレート](https://booth.pm/ja/items/〓リンク更新)

  ハイプロファイルタイプのケースはキー天面がフレームよりも低くなり実用に向かないため、取り付け対象外とします。  
  参考：[TOFUケースへの装着例](https://twitter.com/jpskenn/status/1466729696713142277)

## 部品リスト

このキットを組み立てるためには、”キット内容”に加え、”別途用意が必要な部品”が必要です。  
好みに合わせて、必要な数をお買い求めください。

”オプション部品”は、使いたい機能などに応じて用意してください。  

部品の購入先は、Self-Made Keyboards in Japanの[ショップリスト](https://scrapbox.io/self-made-kbds-ja/ショップリスト)などを参考にしてください。

### キット内容

| 部品名 | 個数 | 備考 |
| ----- | :-----: | ----- |
| ご案内リーフレット | 1 | |
| 基板 | 1 | [おもて側<br>基板おもて側](../assets/BuildGuide_v.0.1/_DSF1269.jpeg)<br>[裏側<br>基板裏側](../assets/BuildGuide_v.0.1/_DSF1271.jpeg) |
| スイッチプレート | 1 | [おもて側<br>スイッチプレートおもて側](../assets/BuildGuide_v.0.1/_DSF1267.jpeg)<br>[裏側<br>スイッチプレート裏側](../assets/BuildGuide_v.0.1/_DSF1268.jpeg) |
| スペーサーシート（シール付き）, T1mm * 550mm * 1mm | 1 ||
| 低頭ネジ, M2 4mm | 5 | [](../assets/BuildGuide_v.0.4/_DSF0432_1.jpeg) |
| Jones / Nora用ボトムプレート | 1 | [おもて側<br>ボトムプレートおもて側](../assets/BuildGuide_v.0.1/_DSF0644.jpeg)<br>[裏側<br>ボトムプレート裏側](../assets/BuildGuide_v.0.1/_DSF0654.jpeg)<br>基本＋プレートキットのみ同梱 |
| スペーサー, M2 3mm | 8 | [](../assets/BuildGuide_v.0.1/_DSF0435_0.jpeg) <br>基本＋プレートキットのみ同梱|
| ネジ, M2 3mm, 低頭 | 16 | [](../assets/BuildGuide_v.0.1/_DSF0435_1.jpeg) <br>基本＋プレートキットのみ同梱|
| ゴム足 大 | 2 | [](../assets/BuildGuide_v.0.1/_DSF0435_3.jpeg) |
| ゴム足 小 | 6 | [](../assets/BuildGuide_v.0.1/_DSF0435_4.jpeg) |

〓写真入れ替え〓
※出荷時期によってメーカーや品番などが変わることがあります

### 別途用意が必要な部品

| 部品名 | 個数 | 備考 |
| ----- | :-----: | ----- |
| GH60型, Poker型ロープロファイルケース<br>または<br>Jones / Nora用ボトムプレートキット | 1 | 基本＋プレートキット購入時は不要 |
| ソケット, Kailh Chocロープロファイル用 | 71 | |
| スイッチ, Kailh Choc v1 | 71 | v1のみ対応 |
| キーキャップ, Choc用<br>MBKまたはそれ以下のサイズのもの | 71 | 1u 63個, 1.5u 8個 |
| USBケーブル （Type-C） | 1 | |

### オプション部品

| 部品名 | 個数 | 備考 |
| ----- | :-----: | ----- |
| LED<br>SK6812MINI-E | 最大71 | 全71個<br>1行目と5行目だけの、25個にすることも可能（要ファームウェア変更） |
| Raspberry Pi PICO | 1 | 実験的機能をDIYで楽しむ場合 |

## 組み立てに必要な工具

- 先の細いドライバー（M2ネジに対応するもの）
- ピンセット
- はんだ付け関連用品
- はさみ
- ニッパー

フラックスやハンダ吸い取り線を用意しておくと、ちょっとした修正などがやりやすくなります。
[遊舎工房の工具セット](https://yushakobo.jp/shop/a9900to/)を参考に用意してください。

なお、無くても組み立てはできますが、何か不具合があった場合の原因調査ではテスターがあると便利です。

## 組み立て前の確認

組み立てを開始する前に、同梱物と基板についての基本的な確認をおこないます。  

**何か問題があった場合は作業を中止し、リーフレットに記載された連絡先へ問い合わせてください。**  
**組み立ての開始後は、初期不良として対応できかねる場合があります。**

### 同梱物の確認

リーフレットに記載された部品が、不足なく入っていることを確認します。

### 接続の確認

基板をUSBケーブルでMacやPCに接続して、キーボードとして認識されることを確認します。

```text
充電用ではないUSBケーブルを使用してください。
他の機器を接続して使用した実績のあるケーブルを使うと、無用のトラブルを防げます。
```

下記のOS別の確認方法を参考に、確認してください。

<details>
<summary>確認方法：《Mac, macOS Monterey 12.0.1》</summary>

1. 基板とMacをUSBケーブルで接続します。

    接続した際に`キーボード設定アシスタント`が表示された場合は、`終了`ボタンを押して閉じます。  
    キーボード設定アシスタント  

    なお、キーボード設定アシスタントは、次の操作でいつでも呼び出すことができます。  
    `システム環境設定`から、`キーボード` → `キーボード`タブ → `キーボードの種類を変更…`ボタンを押す。

1. システム情報を表示します。

    メニューバーの``マークから、`このMacについて`を選び、表示された画面で`システムレポート…`をクリックします。  

1. USBデバイスを表示します。

    `システム情報`画面で、左側の`ハードウェア`から`USB`を選択します。

1. `Nora`が接続されていることを確認します。

    右側上部の`USB装置ツリー`で、`Nora`を探します。  
    どこかに`Nora`と表示されていれば、正しく接続されています。  

    `USB装置ツリー`の下の方が見切れている場合があるため、スクロールして探してください。

    Mac System Report
    システム情報の表示

</details>

<details>
<summary>確認方法：《Windows, 10 Pro 1909(18363.1082)》</summary>

1. 基板とPCをUSBケーブルで接続します。

1. `デバイス`を表示します。

    `スタートボタン`から`設定`を開いて`デバイス`を選択します。

1. `Nora`が接続されていることを確認します。

    `マウス、キーボード、ペン`の項目に`Nora`が表示されていれば、正しく認識されています。
    〓SS撮り直し  
    Windows Devices  
    デバイスの表示

</details>

### ソケット用パッドの確認

Kailh Chocソケット用のパッド（ソケットをはんだ付けする基板上の四角い銀色の部分）が、電気的に正しく反応することを確認します。

<details>
<summary>《詳しい説明》</summary>

ここでは、キーマップ書き換えツール[Remap](https://remap-keys.app/)のテスト機能を使って確認をおこないます。

キーの入力状態を確認することで、パッドの確認と合わせて、基板上の部品や配線が正常であることも確認できます。

1. 基板の裏側が上になるように置きます。

1. PCやMacとUSBケーブルで接続します。

1. Google Chromeブラウザで、[Remap](https://remap-keys.app/)のページを開きます。

    Chromeブラウザは、Web HID対応のバージョン89以降を使用します。
    〓Edgeどうなん？

1. `START REMAP FOR YOUR KEYBOARD`をクリックして始めます。

    START REMAP FOR YOUR KEYBOARD

1. `+ KEYBOARD`をクリックして、キーボードをRemapに接続する画面を表示します。

    + KEYBOARD〓画像

1. キーボード定義ファイルの読み込み画面が表示された場合は次のファイルを読み込みます。
    IMPORT
    1. [nora_via_v03.json](https://gist.github.com/jpskenn/8007f79157319fe32eac469df74d5b49)をダウンロードします。  
    1. ZIPファイルを展開して、`nora_via_v03.json`ファイルを取り出します。
    1. `IMPORT(.JSON)`を押すか、ファイルをドロップして読み込みます。

1. デバイスへの接続要求画面で`Nora`を選択し、`接続`をクリックしてキーボードをRemapに接続します。

    デバイスへの接続要求〓画像

1. 右側のアイコンから`…`をクリックし、`Test Matrix mode`を選択します。

    Test Matrix Mode〓画像

1. ピンセットなどの電気を通すものを使い、基板裏側のソケット用パッドをショートさせます。

    ピンセットを使ってショートさせる様子  
    ピンセットを使ってショートさせる様子〓画像更新

1. Remapの画面で、ショートさせた箇所に対応するキーの色が変わることを確認します。

    *基板が裏側になっているので、画面ではキーの位置が反対になります。*

    キーの色が変わる〓画像

    パッドをショートしても反応がない場合は、基板に実装された部品が外れたり、配線がダメージを受けている可能性があります。  
    この確認作業をすべてのパッドでおこなった後、リーフレットに記載された連絡先へ問い合わせてください。

1. 同様の作業を繰り返し、全てのキーの色が変わることを確認します。

1. 確認が終わったら、USBケーブルを抜きます。

</details>

## 組み立て手順

以下の手順に沿って組み立てます。  
`（オプション）`と書かれた項目は、不要であれば作業をとばしてもかまいせん。  
`（該当者のみ）`と書かれた項目は、条件に該当する場合のみ作業をおこないます。

怪我などに気をつけて作業してください。  

### （オプション）LEDを取り付ける

*LEDを使用しない場合、この手順は不要です。*

基板裏側の`JP4:LED install`を、LEDの取り付け箇所に応じてジャンパします。  
基板裏側からLEDを取り付けます。  
  **注意：行ごとに、LEDを取り付ける方向が異なります。**

<details>
<summary>《詳しい説明》</summary>

#### LEDの取り付け個数をジャンパする

基板裏側の`JP4:LED install`を、LEDの取り付け箇所に応じてジャンパ（隣同士のパッド（基板上の小さな四角の銀色部分）にはんだをつけてつなげること）します。

LEDの取り付け箇所に対応するジャンパ位置は次の通りです。

| LEDの取り付け箇所（個数） | ジャンパ位置 |
| :-- | :-- |
| 1行目のみ（最大16個） | ジャンパ不要 |
| 1行目と5行目（最大25個） | `Simple` |
| 全キー（最大71個） | `Full` |

1. 基板を裏側が上になるように置きます。

1. はんだごてを用意します。  
  こて先の温度は320℃程度にします。  

1. 3個並んだパッドのうち、`Simple`または`Full`のどちらかと中央の2個にまたがるようにこて先をあてます。  
  そのまま、3秒ほど温めます。

1. こて先にはんだを押し付けて、少したっぷり目に溶かします。

1. こて先で基板をなでるように、横へスッとずらしてパッドから離します。  
  2個のパッドが、はんだでつながっていれば完了です。  

なかなか上手くジャンパできないのですが、何度かトライすればそのうちできます。  
こて先でパッドをグリグリいじるとパッドが剥がれて大変なことになるため、「はんだをつけて横へスッ」の動きを守って作業します。

〓写真　パッドをFullにジャンパした例

#### LEDを取り付ける

基板裏側の`L1`から`L71`へLEDを取り付けます。

1. 基板を裏側が上になるように置きます。

1. LEDを1個用意して、LEDの発光部分（透明な窓がある部分）が下側になるように持ちます。

1. LEDから出ている4本の端子のうち、角が斜めになっている1本が基板に描かれた印に合うようにして、基板の穴にはめこみます。  
    **注意：行ごとに、LEDを取り付ける方向が異なります。**  
    〓写真　はめこんだようす  

    4本の端子が基板から浮いている場合は、LEDのプラ部分を軽く押し込んで密着させます。  
    〓写真　浮いてるNG、ぴったりOK

1. はんだごてを用意します。  
  LEDは高温ではんだ付けすると壊れやすいため、こて先温度を少し低めの220-270℃に設定します。

1. 1、2、3、4、5と数える間に次の手順をおこないます。  

    - 1、2：  
      4本の端子のどれかひとつにこて先をあてて押さえ、端子とパッドを温めます。  

    - 3、4：  
      はんだを端子（またはパッド）に当てて溶かし、端子とパッドにはんだを行き渡らせて、はんだを離します。  
      こて先はグリグリ動かしません。はんだ溶けて、自然に濡れ広がっていくような具合です。  

    - 5：  
      こて先を離します。
      はんだが、端子とパッド全体に行き渡っていれば良い仕上がりです。  

1. LEDが傾いてしまった場合は、ピンセットでLEDをつまみ、はんだ付けした端子をこて先で温めながら傾きを修正します。  
  端子とパッドがずれたりしていなければ、少しくらい傾いていてもLEDの光り具合に大差はありません。

1. 最初にはんだ付けした端子とLED本体を挟んだ反対側の端子2本を、1本ずつ、同様の手順ではんだ付けします。

1. 残った1本の端子をはんだ付けします。  
  これで、LED1個の取り付けが完了です。

1. 作業を繰り返し、必要な数のLEDを取り付けます。

〓写真更新
取り付けたLED
取り付けたLED

#### LEDの動作確認

〓最初のLEDパターンをテスト用のやつにしておく。その手順でビルドガイド書く
〓RGB Matrixでのデフォエフェクトは？

LEDの点灯状態を見て、正しく取り付けられているか確認します。

1. PCやMacにUSBケーブルで接続します。

1. すべてのLEDが、`赤 → 青 → 緑 → 赤…`という具合に繰り返して点灯することを確認します。

  点灯しないLEDがあったり、色がおかしかったりする場合は、[トラブル対応：LEDの取り付け不良調査](#トラブル対応LEDの取り付け不良調査)を参考にして調査します。

</details>

〓写真　LED取り付け完了（テスト時に光ってるやつ）

### Kailh Choc用ソケットを取り付ける

基板裏側へKailh Choc用ソケットを取り付けます。  
**注意：ソケットを取り付ける方向に決まっています。基板に描かれた枠をよく見て、正しい方向に取り付けます。**

<details>
<summary>《詳しい説明》</summary>

#### ソケット用パッドの片方へ予備はんだする

1個のソケットに対応する2箇所のパッドのうち、どちらか*片方だけ*に予備はんだ（部品の取り付け前にはんだをつけておく）します。

1. 基板を裏側が上になるように置きます。

1. はんだごてを用意します。  
  こて先の温度は320℃程度にします。

1. 1、2、3、4、5と数える間に次の手順をおこないます。

    - 1、2：  
      予備はんだするパッドにこて先をあてて、温めます。

    - 3：  
      こて先にはんだをあてて溶かします。

    - 4：  
      溶けたはんだがパッド全体に広がったら、はんだを離します。

    - 5：  
      こて先をパッドから離します。

〓写真　予備はんだ

#### ソケットの仮置き

ソケットを基板に描かれた枠に合わせ、プラスチックの突起が穴にはまるように仮置きします。  
ソケットを取り付ける方向に決まりがあるので、正しい方向になっているかよく確認します。

〓写真　ソケット方向

1. 基板を裏側が上になるように置きます。

1. ソケットを1個用意し、方向を確認します。

1. 予備はんだしておいた箇所へ、穴に合わせてソケットを置きます。  
  この段階では、ソケットの片方の端子が予備はんだの上に乗り、基板から少し浮いて傾いた状態になります。

```aside
基板の製造ロットによっては、穴が小さい（狭い）ことがあります。
その場合は、プラスチックの突起を穴に合わせて、ソケットを指で押し込むようにしてはめ込みます。
```

#### 予備はんだした端子をはんだ付けする

予備はんだしてある方の端子を、はんだ付けします。

1. はんだごてを用意します。  
  こて先の温度は320℃程度にします。

1. 利き手にはんだごて、もう一方の手にピンセットを持ちます。

1. ピンセットでソケット中央のプラ部分を抑えて動かないようにして、端子の隙間にこて先を差し込みます。

    〓写真　こて先差し込み

1. 1、2、3、4、5、6と数える間に次の手順をおこないます。

    - 1、2：  
      予備はんだが溶け始めます。  
      ピンセットで軽く追い込むと、ソケットのプラスチックの突起が基板の穴にはまり、浮いていた端子が基板に接します。  

    - 3：  
      こて先をあてたまま、加熱を続けます。  

    - 4：  
      こて先を離します。  

    - 5：  
      ピンセットでソケットを抑え続けます。  

    - 6：  
      はんだが冷えて固まるのを待ってから、ピンセットを離します。

1. ソケットが枠沿ってまっすぐに取り付けられ、傾いていないことを確認します。
  傾いている場合は端子部分を再度加熱し、こて先とピンセットで傾きを修正します。

#### 残りの端子のはんだ付け

残りのもう一方の端子をはんだ付けします。

1. はんだごてを用意します。  
  こて先の温度は320℃程度にします。

1. 残りの端子の隙間にこて先を差し込みます。

1. 1、2、3、4、5、6と数える間に次の手順をおこないます。

    - 1、2：  
      こて先を差し込んだまま、端子とパッドを加熱します。  

    - 3：  
      パッドと端子の隙間あたりへ、はんだを押し付けて溶かします。  

    - 4：  
      はんだを溶かしながら、端子とパッドの隙間へ流し込みます。  

    - 5：  
      溶けたはんだがパッド全体に広がる程度まで流し込んだら、はんだを離します。  

    - 6：  
      ソケットを動かしてしまわないよう、静かにこて先を離します。

1. はんだ付けした状態を確認します。  
    はんだがパッド全体に広がり、端子の間にポコっと盛り上がって固まっているのが良好な状態です。  

    広がりが足りない場合は、再加熱して、はんだを足して塗り広げます。

1. ソケットが枠に沿ってまっすぐに取り付けられていることを確認します。  
    また、ソケットが基板から浮いていないことも確認します。  

    傾いたり浮いたりしている場合は、端子部分を再加熱し、こて先とピンセットで修正します。

〓写真　浮いたソケット

#### すべてのソケットの取り付け

1. 作業を繰り返して、すべてのソケットを取り付けます。

1. 取り付けが終わったら、**はんだ付けし忘れた箇所がないか、十分確認します**。

</details>

〓写真　ソケット取り付け、できあがり

### スイッチプレートにスペーサーシートを貼り付ける

基板とスイッチプレートの隙間を埋めるスペーサーシートを、スイッチプレートの裏側へ貼り付けます。  

<details>
<summary>《詳しい説明》</summary>

1. スイッチプレートを、裏側が上になるように置きます。

1. スイッチプレート裏側の貼り付け位置へ、スペーサーシートを貼り付けます。

    シートをはさみなどで切り離し、以下の優先順に貼り付けます。  

    1. 幅が広い箇所（シート幅そのままの10mm）
    1. 幅が中くらいの箇所（シートを縦半分に切った5mm幅）
    1. 幅が狭い箇所のうち、貼り付けサイズが長い箇所（シートを縦1/3に切った約3mm幅）
    1. その他、残りの箇所  
      その他の箇所は、すべて貼り付けできなくでも問題ありません。  
      貼り付け箇所を、ひとつ飛ばし（2個に1個、飛び飛び）にして、バランスよく貼り付けます。

    Raspberry Pi PICOを使用する場合は、コンスルーの足がシートに当たってしまうため、中央上部には貼り付けません。

</details>

Put sheet pieces to switch plate
〓写真更新　スイッチプレートにスペーサーシートを貼り付けた状態  
（ほぼ透明のシートを使用したため、多少見づらくなっています）

### スイッチとスイッチプレートを基板へ取り付ける

スイッチを、スイッチプレートをはさむようにして基板に取り付けます。  
ケースネジに重なるスイッチ（※）は、この手順では取り付けません。  
※基板にネジのアイコンが描かれています。

<details>
<summary>《詳しい説明》</summary>

#### スイッチプレートを仮固定する

スイッチプレートのおもて側から6個のスイッチをはめ込み、スイッチの端子を基板のソケットへはめ込んで仮固定します。

1. スイッチを6個用意します。  
  端子が折れたものは使用できません。曲がっているものは、まっすぐにしておきます。

1. スイッチプレートをおもて側が上になるように置きます。

1. プレートのおもて側から、6箇所（1・3・5行目の左右の端）に、スイッチをパチンとはめ込みます。  
    スイッチをソケットの方向に合わせるため、スイッチの端子が手前側になるようにします。

    〓写真更新スイッチプレート取り付けたスイッチ
    スイッチプレートに取り付けたスイッチ

1. スイッチがプレートの枠から浮いておらず、ぴったり密着してはまっていることを確認します。  
    浮いている場合は、スイッチを押し込んで密着させます。

    〓写真　スイッチとプレートの密着OK NG

1. 基板をおもて側が上になるようにして、プレートの隣に置きます。

1. スイッチ6個を取り付けたプレートを、スイッチ端子と基板のソケットの位置が合うようにして、基板に乗せて重ねます。  

1. プレートと基板がずれないように持ち上げ、基板の裏側を支えながら、どれかひとつのスイッチを押し込み、しっかりとソケットへ差し込みます。  

    〓写真　スイッチを押し込む様子

1. スイッチがしっかりと差し込まれ、基板にほぼくっついた状態になっていることを確認します。  
    5ピンのスイッチを取り付ける場合は、スイッチ固定用のプラスチックピン2本が根元まで刺さりきっていない場合があるので、よく確認しておきます。

    〓写真　スイッチの押し込まれ具合

1. 同じようにして、6個のスイッチすべてをソケットへ差し込みます。

〓写真更新基板に取り付けられたスイッチとスイッチプレート
基板に取り付けられたスイッチとスイッチプレート

#### 残りのスイッチを取り付ける

ケースネジに重なるスイッチを除いて、残りのスイッチをすべて取り付けます。

1. スイッチを用意します。  
    端子が折れたものは使用できません。曲がっているものは、まっすぐにしておきます。

1. プレートにスイッチをはめ込みつつ、そのまま基板のソケットへスイッチ端子を差し込んで、スイッチを取り付けます。

1. ケースネジに重なるスイッチ（基板にネジのアイコンが描かれた箇所）を除き、残りのスイッチをすべて取り付けます。

    〓写真　ネジアイコン

</details>

〓写真更新基板に取り付けられたスイッチプレート  
基板に取り付けられたスイッチプレート

### スイッチの動作確認をおこなう

組み立て前におこなった[ソケット用パッドの確認](#ソケット用パッドの確認)と同様の手順で、ソケットに取り付けたスイッチが正しく動作するか確認します。  
この手順では、取り付けたスイッチを押して確認します。

正常に入力できないスイッチがあった場合は、[トラブル対応：正常に入力できないスイッチの原因調査](#トラブル対応正常に入力できないスイッチの原因調査)の手順に沿って調査します。

### 基板をケース、またはボトムプレートへ取り付ける

スイッチとプレートが組み合わされた基板を、ケース、またはボトムプレートへ取り付けます。

打鍵感向上に興味のある方は、次の項目をお読みになると何かヒントがあるかもしれません。

- [打鍵感向上：ケース内部の制振と静音化](打鍵感向上：ケース内部の制振と静音化)

#### （該当者のみ）基板をボトムプレートへ取り付ける

*ボトムプレートキットを使用する場合のみ、この手順をおこないます。*

ネジとスペーサーを使い、ボトムプレートに基板を取り付けます。

<details>
<summary>《詳しい説明》</summary>

1. ボトムプレート裏面から、以下の写真に示す○印をつけた8箇所に、ネジ（M2 3mm 低頭）を使い、スペーサー（M2 3mm）をねじ止めします。  

    ◎印をつけた右上と中央下の2箇所は、スイッチとの干渉を避けるため、スペーサーを右側へ寄せてねじ止めします。  

    〓写真更新
    スペーサー取り付け箇所  
    スペーサー取り付け箇所

1. ボトムプレートをおもて側が上になるように置きます。

1. 基板を、ボトムプレートに取り付けたスペーサーの位置に合わせて乗せます。  
  基板裏側の部品がスペーサーにぶつからないように注意します。

1. 基板おもて側から、ネジ（M2 3mm 低頭）を使い、基板とスペーサーをねじ止めします。  

    基板とボトムプレートをねじ止めした状態  
    基板とボトムプレートをねじ止めした状態

1. まだ取り付けていないスイッチを、すべて取り付けます。

1. ボトムプレート底面に、滑り止めのゴム足を貼り付けます。

    - キーボードに傾斜をつける場合  
      奥の左・右の2箇所：ゴム足 大  
      手前の左・中・右の3箇所：ゴム足 小

    - キーボードをフラットにする場合  
      手前と奥の左・中・右の6箇所：ゴム足 小

</details>

ボトムプレート取り付け完了  
ボトムプレート取り付け完了

#### （該当者のみ）GH60型, Poker型ケースへ取り付ける

*GH60型, Poker型ケースを使用する場合のみ、この手順をおこないます。*

ケースに基板をねじ止めして取り付けます。

<details>
<summary>《詳しい説明》</summary>

1. ケースにネジ留め式の足がある場合は、最初に取り付けておきます。

1. ケースを安定したところへ置き、スイッチとスイッチプレートが組み合わされた基板を手に持ちます。

1. 基板を水平から30度くらいの角度に持ち、奥側から斜めにケース内へ入れていきます。  
  斜めに差し込んでいくと、USBコネクタがケースの穴にスッとはまります。

1. USBコネクタがはまった状態で基板の手前側を静かに下ろして水平にします。  
    力をかけることなく、基板全体がストンとケースに入ります。  
    力を入れてグリグリとこじったりググググッと押し込むようなことはせず、角度を合わせて差し込んで、水平にするだけです。

    〓写真更新スペーサー取り付け箇所  
    30度で差し込む

1. ケース付属のネジで、左上と右上の2箇所を仮固定します。

1. キット同梱のネジ（M2 4mm 低頭）で、左端、右端、中央、中央下の4箇所を仮固定します。

1. ケースに対して、基板の位置が上下左右の真ん中になるように調整します。

1. ネジが軽く止まる程度まで締めて基板を固定します。

1. ケース中央のネジ穴に重なるスイッチを、足を加工して取り付けます。  
    3ピンのスイッチは、加工不要で、そのまま取り付けできます。  
    5ピンのスイッチを使用する場合は、左右2本のプラスチックピンのうちネジ穴に干渉する方の足を、根本からニッパーなどで切断します。

    〓写真　5ピンの片足をカット

    おそらく回避できるはずですが、もしスイッチの中央の足が干渉する場合は、中央の足も切断します。

    中央の足をカットしたスイッチ  
    中央の足をカットしたスイッチ

1. 残りのスイッチを、すべて取り付けます。

1. ケース底面に、滑り止めのゴム足を貼り付けます。

</details>

〓写真　ケース取り付け完了

### スイッチの最終動作確認をおこなう

組み立て前におこなった[ソケット用パッドの確認](#ソケット用パッドの確認)と同様の手順で、ソケットに取り付けたスイッチが正しく動作するか最終確認します。  
この手順では、取り付けたスイッチを押して確認します。

### 仕上げ

1. キーキャップを取り付けます。

1. Remapでキーマップを変更したり、ファームウェアをカスタマイズして、自分好みに仕上げます。

1. 完成です。

〓写真更新製作例  
製作例

写真を撮影し、`#Nora_kbd` のタグをつけてツイートすると設計者が喜んだりします。  
[Twitter: #Nora_kbd](https://twitter.com/search?q=(%23nora_kbd)&src=typed_query&f=live)

---

## 参考

打鍵感向上や機能追加についてのDIY情報や、トラブル調査方法などの参考資料です。  
必要に応じてお読みください。

### 打鍵感向上：ケース内部の制振と静音化

ケースやボトムプレートに工夫を施すことで、打鍵感を向上させる方法について説明します。

<details>
<summary>《詳しい説明》</summary>

- ケースの振動防止

    ケース内部におもりを入れておくと、ケースの共振が抑えられ、打鍵感の向上や、打鍵音の変化が期待できます。  
    おもりには、10円玉、真鍮板、自動車タイヤ用のホイールバランスウェイト、鉛シートなどを使用します。  
    また、スポンジ状の両面テープなどを使っておもりを貼り付けると、より高い防振効果を得ることができます。

    基板裏側の部品におもりの金属部分がふれてショートしないよう、スポンジシートを間に挟んだり、カプトンテープなどで保護します。

- 基板の振動防止

    基板とケース間をウレタンスポンジやシリコンシートなどで埋めると、基板の振動を抑えることができます。  
    また、ケース内部の空間を埋めることで、基板の振動音やスイッチの動作音がケース内で響くのを減らすことができます。

    ボトムプレートを使用する場合も、基板とボトムプレートの間に対策を施すことで、同様の効果が期待できます。

    スポンジなどを詰めすぎると、ネジや基板裏側の部品に力がかかるため、ほどよい程度に調節します。

これらの工夫をおこなう様子はこちら  
→[ケースが響いてうるさいのをなんとかしていく](https://twitter.com/jpskenn/status/1467010813773119490)

</details>

### トラブル対応：正常に入力できないスイッチの原因調査

正常に入力できないスイッチの原因調査と対応方法について説明します。  

<details>
<summary>《詳しい説明》</summary>

テスターをお持ちの方は、疑わしい箇所をテスターで調べるのが手っ取り早い方法ですので、積極的に使用してください。

〓リンクをDN0030タグとかに
電子工作に詳しい方であれば、[NoraのKiCadプロジェクト](https://github.com/jpskenn/Nora/tree/master/PCB)を参考にテスター等を用いて調査を進め、ジャンパ線などで配線を修復してください。

#### スイッチの取り付け不良

もっとも多い原因は、スイッチの取り付け不良です。  

スイッチを取り外し、端子が曲がったり折れたりしていないか確認します。  
端子の曲がりを修復するか、新しいスイッチに交換して、もう一度キー入力を確認します。

#### ソケットの取り付け不良

次に多いのが、ソケットの取り付け不良です。  

ソケットのはんだ忘れや、はんだが適切に行われていないことが原因のため、ソケットのはんだ状態を確認します。  
溶けたはんだがパッド全体に広がっていること、はんだがソケットの端子の間にポコっと盛り上がって固まっていることも確認します。  

念のため、再度はんだ付けし直して、もう一度キー入力を確認します。

#### 原因箇所の特定

スイッチとソケットの取り付け不良を調査しても改善しなかった場合、原因箇所の特定をおこないます。

組み立て前におこなった[ソケット用パッドの確認](#ソケット用パッドの確認)と同様の手順で、基板のパッド部分をピンセットでショートさせ、キー入力できるか確認します。  
パッドをショートしてキー入力できた場合は、パッド自体は正常ですので、スイッチとソケットを再度調査します。

#### キー入力が確認できない場合

この場合は、ソケット用パッドや基板の配線、その他の基板に取り付けられた部品が、組み立て中にダメージを受けたことが原因と考えられます。

これ以降の調査と修復の難易度が高くなりますが、ソケット用パッドが剥がれてソケットが取り付けられないというような物理的に破壊された状態を除けば、修復できる可能性は残されています。  
（パッドが剥がれたとしても、ネジ穴に重なるスイッチでなければ、スイッチを固定してソケットを端子に差し込んで、ソケットから基板へ配線すればなんとかなります。）

電子工作に詳しい方であれば、[NoraのKiCadプロジェクト](https://github.com/jpskenn/Nora/tree/master/PCB)を参考にテスター等を用いて調査を進め、ジャンパ線などで配線を修復してください。

自分ではどうにもできない場合など、何らかのアドバイスを必要とされる方は、キット同梱のリーフレットに記載された連絡先へ問い合わせてください。  
状況に応じて、できる限りのサポートをいたします。  

</details>

### トラブル対応：LEDの取り付け不良調査

LEDが点灯しない場合など、LEDの取り付け不良を調査する方法について説明します。

<details>
<summary>《詳しい説明》</summary>

調査の前提として、LEDの点灯には、

```text
点灯しないLEDより後ろは、すべて点灯しない。
```

というルールがあります。

例えば、
`L1` `L2`が点灯し、`L3`が点灯しないとき、
`4`より後ろは、正しく取り付けられていたとしても、点灯しません。

このルールをふまえ、点灯しない最初のLEDから順番に調査を進めていきます。

#### LEDがひとつも点灯しない場合

LEDがひとつも点灯しない場合は、LEDに電源が供給されていないことが原因のひとつと考えられます。

ジャンパ`JP3: Device VDD source`が、正しい位置（通常は`Onboard`）にジャンパされていることを確認します。  

ジャンパ位置が合っている場合も、念のため、ジャンパをやりなおしておきます。

正しい位置にジャンパしていても点灯しない場合は、LED点灯状態に応じた確認をおこないます。

MCUとジャンパの組み合わせは次の通り。

| MCU | ジャンパ位置 | 備考 |
| :--: | :--: | :-- |
| ATmega32u4 | `Onboard` | 通常の組み合わせ |
| Raspberry Pi PICO | `PICO VBUS` | Raspberry Pi PICO使用時 |

#### 2行目以降のLEDが点灯しない場合

2行目以降のLEDが点灯しない場合は、LEDの信号伝達経路が正しく指定されていないことが原因のひとつと考えられます。

全キーにLEDを取り付けた場合は、ジャンパ`JP4: LED install`が、`Full`にジャンパされていることを確認します。  
また、R1とR5だけにLEDを取り付けた場合は、`Simple`にジャンパされていることを確認します。

正しい位置にジャンパしていても点灯しない場合は、LED点灯状態に応じた確認をおこないます。

#### LEDの光り方がおかしい場合

LEDがちらついたり、色がおかしい場合は、LEDのはんだ不良が疑われます。

光り方がおかしいLEDのはんだ付けをやり直します。

フラックスがある場合は、LEDの端子に塗布しておくと、はんだがダマになりにくくなります。  
はんだ吸い取り線がある場合は、一旦はんだを除去しておきます。  
どちらもない場合は、はんだを足しながら、はんだ付けをやり直します。

#### LEDが点灯しない場合

正しくジャンパしていてもLEDが点灯しない場合は、LEDの取り付けまたはLED自体に原因があると考えられます。  
LEDの点灯に関するルールにしたがい、**光らないLEDの、番号が若いものから順番に**以下の対処を行います。

1. 光らないLEDのはんだ不良を修復する

    「光らないLEDが正しくはんだ付けされていない」と仮定した対処です。  
    光らないLEDのはんだ付けをやり直します。

1. 光らないLEDの*ひとつ前*のLEDのはんだ不良を修復する

    「光らないLEDは正常に取り付けられているが、*ひとつ前*のLEDのはんだ不良が原因で配線がつながっていない」と仮定した対処です。  
    光らないLEDの*ひとつ前*のLEDのはんだ付けをやり直します。

1. 光らないLEDを新しいものに交換する

    「光らないLEDが壊れてしまっている」と仮定した対処です。  
    これまでの対処をおこなっても点灯しない場合は、光らないLED自体が壊れていると判断して、新しいものに交換します。

    以下のような方法で、LEDを取り外すことができます。

    - 少しずつ持ち上げる方法
      強く持ち上げるとパッドが剥がれてひどいことになるので、力をかけずに少しずつ持ち上げます。

        1. こて先の温度を320℃程度にします。
        1. はんだ吸い取り線で、できる限りのハンダを除去しておきます。
        1. 片側2本の端子を同時に加熱しながら、ピンセットでLEDを少しだけ持ち上げます。
        1. 反対側の2本の端子も、同様にして、少しだけ持ち上げます。
        1. これを交互に繰り返し、じわりじわりと取り外していきます。

    - 熱々にして持ち上げる方法
      溶けたはんだで火傷しないように注意します。

        1. こて先の温度を320℃程度にします。
        1. LEDの端子部分を温め、はんだをたーーーーーーっぷりと溶かし、端子部分につけておきます。  
        （あずき〜大豆くらいの大きさの溶けたはんだ）
        1. 反対側の端子にも、同じようにはんだをたっぷりとつけます。
        1. LEDのプラ部分をピンセットつまみます。
        1. LEDの両側のはんだを交互に2秒ずつ温めるのを繰り返し、両側のはんだが溶けた状態にします。
        1. その状態でLEDを引き上げて、基板から取り外します。

</details>

### 資料：ファームウェアの書き込み方法

[QMK Toolbox](https://github.com/qmk/qmk_toolbox/releases)を使用してビルド済み（＝作成済み）のファームウェアを書き込む方法について説明します。

QMKファームウェアのドキュメント[ファームウェアを書き込む](https://docs.qmk.fm/#/ja/newbs_flashing?id=ファームウェアを書き込む)も、あわせてご覧ください。

<details>
<summary>《詳しい説明》</summary>

1. [資料：Noraキーボードのファームウェア](〓リンク)に記載のダウンロード先から、ビルド済みのファームウェアをダウンロードします。

1. [QMK Toolbox](https://github.com/qmk/qmk_toolbox/releases)をダウンロードし、起動します。

1. QMK Toolboxに、ダウンロードしておいたファームウェアをロードします。

1. `Nora`キーボードをDFU (Bootloader)モードにします。
    1. USBケーブルが接続されている場合は、ケーブルを抜きます。
    1. キーボードの**左上**のキーを押したまま、USBケーブルを差し込みます。

1. QMK Toolboxの画面に、以下のメッセージが表示されます。  
    （もし表示されない場合は、USBケーブルを接続した状態で、基板裏側のリセットボタンを押します）

    ```text
    *** Atmel DFU device connected: ATMEL ATm32U4DFU (03EB:2FF4:0000)
    ```

1. QMK Toolboxの`Flash`ボタンを押すとファームウェアの書き込みが始まります。  
    5秒程度で書き込みが終わり、QMK Toolboxの画面に以下のような書き込み完了メッセージが表示されます。（サイズ表記などの、細かい部分は実際とは異なります）

    ```text
    *** Attempting to flash, please don't remove device
    >>> dfu-programmer atmega32u4 erase --force
        Erasing flash...  Success
        Checking memory from 0x0 to 0x6FFF...  Empty.
    >>> dfu-programmer atmega32u4 flash --force /Users/jpskenn/qmk_firmware/nora_v01_via.hex
        0%                            100%  Programming 0x5E80 bytes...
        [>>>>>>>>>>>>>>>>>>>>>>>>>>>>>>>>]  Success
        0%                            100%  Reading 0x7000 bytes...
        [>>>>>>>>>>>>>>>>>>>>>>>>>>>>>>>>]  Success
        Validating...  Success
        0x5E80 bytes written into 0x7000 bytes memory (84.38%).
    >>> dfu-programmer atmega32u4 reset
    *** Atmel DFU device disconnected: ATMEL ATm32U4DFU (03EB:2FF4:0000)
    ```

    書き込み完了メッセージが表示されたら、QMK Toolboxを終了してもかまいません。  

    これとは違うメッセージ（書き込み失敗など）が表示された場合は、スクリーンショットを撮ったり、メッセージをコピーしておくと、何らかのサポートを受ける場合にスムースに話が進みます。

1. 書き込みが終わってから10秒ほど待つと、キーボードが起動し、キー入力できるようになります。  
  ファームウェアを書き込んだ後、初回起動時に外部EEPROMの消去をおこなっています。  
  この消去処理に10秒ほどかかっています。

1. リセットボタンを使ってDFUモードにする操作をおこなった場合は、[資料：EEPROMを消去して、初期状態に戻す方法](#資料eepromを消去して-初期状態に戻す方法)を実施します。

以上でファームウェアの書き込み作業は完了です。

</details>

### 資料：初期ファームウェアの機能と設定値

出荷時に書き込まれている初期ファームウェアの機能と設定値を説明します。

<details>
<summary>《詳しい説明》</summary>

- キーマップ書き換えツール
  RemapやVIAに対応。

- レイヤー

    7個のレイヤー。  
    レイヤー構成とLEDインジケータの色は次の通りです。

    〓変更

    | No. | レイヤー名 | 機能 | LEDインジケータ色<br>手前, 奥 |
    | :-: | :-- | :-- | :-: |
    | 0 | ベースレイヤー #1 | 日本語配列 | 白, 白 |
    | 1 | ベースレイヤー #2 | テンキー | 青, 青 |
    | 2 | ベースレイヤー #3 | （未設定） | 黄, 黄 |
    | 3 | Lower | 記号, ボリューム, ファンクションキー | －, 緑 |
    | 4 | Raise | カーソル移動, 数字, ファンクションキー | －, 水 |
    | 5 | Adjust | 各種設定, スクロールロックなど | －, 赤 |

- イルミネーションLED  

    〓何がデフォ？
    全キー71個のLEDによる、RGB Matrix Lightingに対応。  
    初期状態のエフェクトは〓  
    エフェクトのモードは`RGB_MOD`, `RGB_RMOD`で変更でき、EEPROMにモードが保存されます。

- レイヤーインジケータLED  

    左上2個（1行目の左から2個）のLEDをレイヤーインジケータLEDとして使用し、レイヤーの状態を表示します。

</details>

### 資料：Noraキーボードのファームウェア

ビルド済みファームウェアと、ソースファイルを用意しています。

#### ビルド済みのファームウェア

- [Nora v1 ファームウェア, VIA対応デフォルト](https://gist.github.com/jpskenn/3fcebf6a7c17f1a8433a8d954e05206f)

R1,R5のみLED

#### ファームウェアのソース

私がQMKからフォークしたリポジトリ  
[https://github.com/jpskenn/qmk_firmware](https://github.com/jpskenn/qmk_firmware)  
を使用してください。  

[develop_nora](https://github.com/jpskenn/qmk_firmware/tree/develop_Nora)ブランチの、`keyboards/nora/v01`に関連ファイルが格納されています。

### 資料：EEPROMを消去して、初期状態に戻す方法

キーマップやLEDの表示モードなどのEEPROMに記録されているデータを消去し、初期状態に戻すことができます。  

また、古いデータが残って動作がおかしくなるのを防止するため、リセットボタンを使用してファームウェアを書き込んだ際にもこの操作をおこないます。

<details>
<summary>《詳しい説明》</summary>

1. USBケーブルを接続している場合は、ケーブルを抜きます。

1. キーボードの左上のキーを押したまま、USBケーブルを差し込みます。

1. ケーブルを差し込んで、1、2と数えてから、USBケーブルを抜きます。

1. USBケーブルを差し込みます。

1. 10秒ほど待つとキーボードが起動します。

以上でEEPROMが消去され、初期状態に戻ります。

</details>

### 資料：Nora, Fearless Wings (DN0030)関連ファイル

〓リンク更新
関連ファイルは、  
[コミット：718199fba41e841ba6e2f60da43260c8e984e9b2](https://github.com/jpskenn/Nora/tree/718199fba41e841ba6e2f60da43260c8e984e9b2)の内容を、  
[Nora v01_PCBタグ](https://github.com/jpskenn/Nora/releases/tag/v01_PCB)にまとめてあります。

〓via json

### 資料：Raspberry Pi PICOによる動作（実験的機能）

DIYの実験的機能として、Raspberry Pi PICO（以下、PICOと呼びます）を使用して、キーボードを動作させることができます。

<details>
<summary>《詳しい説明》</summary>

#### PICOを使用して、できること

- キーマトリクスの駆動
- LEDの点灯

#### PICOを使用して、できるかもしれないこと

以下は、動作未確認の項目です。

- EEPROMや、その他のI2C接続された機器との通信
- 未割り当てのGPIOピンの使用

#### 使用時の注意

- GH60型，Poker型ケースには、（たぶん）取り付けできません。  
  取り付けられたとしても、ケーブルの取り回しを工夫する必要があります。

- 基板のジャンパを変更して使用します。  
  [PICO使用時の設定](#PICO使用時の設定)を参照。

#### 接続図

PICOの接続図は以下の通り。

〓写真　回路図

#### 取り付け

コンスルーを使用する場合、20ピン（高さ2mm以上）のものが使用できます。

基板とスイッチプレートの間隔が1mmしかないため、コンスルーが奥まで刺さり切らない場合があります。  

ボトムプレートに取り付ける場合は、プレート中央部を切り離します。  
L字型のコネクタをもつUSBケーブルを使用すると、すっきりとおさまります。

#### PICO使用時の設定

必要に応じて基板裏側のジャンパを設定してください。

- `JP3:Device +5 source`：LEDの電源供給元

    | ジャンパ設定 | LEDの電源供給元 | 備考 |
    | :-: | :-- | :-- |
    | PICO VBUS | PICOのVBUS ||
    | Onboard | 基板に接続したUSBのVCC | オンボードのMCU、ATmega32u4使用時のデフォルト設定|
    | オープン | 接続なし ||

- `JP1`,`JP2`：I2Cプルアップ抵抗（4.7KΩ）への接続

    | ジャンパ設定 | I2Cプルアップ抵抗への接続 | 備考 |
    | :-: | :-- | :-- |
    | ブリッジ | プルアップ抵抗へ接続 | オンボードのMCU、ATmega32u4使用時のデフォルト設定|
    | オープン | 接続なし ||

#### ファームウェア

- [PRK Firmware](https://github.com/picoruby/prk_firmware)

  以下の基本的な動作を確認済みです。

  - 全キーの入力
  - LED点灯

  動作確認に使用したファームウェアはこちら：[keymap.rb](../Firmware/prk_nora/)

</details>

## サービスマニュアル

基板の準備など、出荷前作業について。

### パーツリスト

| 部品名 | 個数 | 備考 |
| :---- | :-----: | :---- |
| USBコネクタ<br>USB4085-GF-A | 1 ||
| ESD<br>PRTR5V0U2X | 1 ||
| FUSE<br>0ZCJ0050AF2E | 1 ||

### 基板セットアップ

1. 部品取り付け

    1. 基板裏側からUSBコネクタを取り付ける

        テスターでピンを確認する。
        〓更新USBコネクタ接続図  
        USBコネクタ接続図

    1. 基板裏側へESDを取り付ける

        〓更新ESD placement direction
        ESD取り付け方向

    1. 基板裏側へFUSEを取り付ける

    1. リセットスイッチを取り付ける

    1. `ICSP`ピンの`+5V`と`GND`が導通しないことをテスターで確認。

1. ジャンパ

    1. I2Cプルアップ抵抗、2箇所をジャンパする

    1. デバイス電源をジャンパする  
      `JP3: Device VDD source` → `Onboard`

1. ファームウェア書き込み

    1. PC/Macへ接続し、デバイス`Nora`として認識されていることを確認する

    1. QMK Toolboxを起動してファームウェアをロード

    1. 基板のリセットスイッチを押す

    1. `Flash`で書き込む

    1. Remapで全キーのパッドを確認する

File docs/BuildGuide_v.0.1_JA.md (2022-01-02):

# Nora, 1.8k (v.0.1) ビルドガイド

購入していただいた方、リポジトリから製造していただいた方、その他の皆様、Noraに興味を持っていただきありがとうございます。

このドキュメントは、Nora v.0.1を組み立てるためのビルドガイドです。  
Noraのコンセプトや特徴、ビルド例などについては、[README](https://github.com/jpskenn/Nora/README.md)をご覧ください。

ビルドガイド全体に目を通して作業手順を把握しておくとミスの防止につながりますので、ぜひ、一度お読みになってから組み立て作業を始めてください。

組み立て初心者の方や、しっかりと確認しながら組み立てたい方は、

<details>
<summary>《詳しい説明》</summary>

ここに追加の説明を表示します。
</details>

と書かれたところをクリックすると、追加の説明が表示されます。

---

## 目次

<!-- @import "[TOC]" {cmd="toc" depthFrom=2 depthTo=3 orderedList=false} -->

<!-- code_chunk_output -->

- [目次](#目次)
- [Nora v.0.1の特徴, 機能](#nora-v01の特徴-機能)
- [注意事項、制限など](#注意事項-制限など)
- [部品リスト](#部品リスト)
  - [キット内容](#キット内容)
  - [別途用意が必要な部品](#別途用意が必要な部品)
  - [オプション部品](#オプション部品)
- [組み立てに必要な工具](#組み立てに必要な工具)
- [組み立て手順](#組み立て手順)
  - [同梱物の確認](#同梱物の確認)
  - [基板にMCUやUSBコネクタなどのパーツを取り付ける](#基板にmcuやusbコネクタなどのパーツを取り付ける)
  - [基板回路の確認](#基板回路の確認)
  - [左シフトキーの構成を決める](#左シフトキーの構成を決める)
  - [Mill-Maxソケットを取り付ける](#mill-maxソケットを取り付ける)
  - [（オプション）LEDを取り付ける](#オプションledを取り付ける)
  - [（オプション）スタビライザーを取り付ける](#オプションスタビライザーを取り付ける)
  - [スイッチプレートにシートを貼り付ける](#スイッチプレートにシートを貼り付ける)
  - [スイッチとスイッチプレートを基板へ取り付ける](#スイッチとスイッチプレートを基板へ取り付ける)
  - [基板をケース、またはボトムプレートへ取り付ける](#基板をケース-またはボトムプレートへ取り付ける)
  - [スイッチをソケットに取り付ける](#スイッチをソケットに取り付ける)
  - [仕上げ](#仕上げ)
- [参考](#参考)
  - [打鍵感向上：ケース内部の制振と静音化](#打鍵感向上ケース内部の制振と静音化)
  - [トラブル対応：正常に入力できないスイッチの原因調査](#トラブル対応正常に入力できないスイッチの原因調査)
  - [トラブル対応：LEDの取り付け不良調査](#トラブル対応ledの取り付け不良調査)
  - [トラブル対応：Mill-Maxソケットの取り外し方](#トラブル対応mill-maxソケットの取り外し方)
  - [資料：ファームウェアの書き込み方法](#資料ファームウェアの書き込み方法)
  - [資料：Noraキーボードのファームウェア](#資料noraキーボードのファームウェア)
  - [資料：EEPROMを消去して、初期状態に戻す方法](#資料eepromを消去して-初期状態に戻す方法)
  - [資料：Nora v.0.1関連ファイル](#資料nora-v01関連ファイル)
  - [資料：Raspberry Pi PICOによる動作（実験的機能）](#資料raspberry-pi-picoによる動作実験的機能)

<!-- /code_chunk_output -->

---

## Nora v.0.1の特徴, 機能

- 狭ピッチ
- Jonesゆずりのキーレイアウト
- テンキーと飛び出したカーソルキーをもつレイアウト
- Choc v1スイッチと、MBK、またはそれ以下のサイズのキーキャップに合わせた専用設計
- RemapやVIAなどのキーマップ書き換えツールに対応したファームウェアを書き込み済み  
- 外部EEPROM（8KB）を搭載し、十分な数のレイヤーを使用可能
- GH60型やPoker型に互換性のあるロープロファイルケースに対応  
  ボトムプレートと組み合わせて、ケースレスで高さを抑えて使用することも可能。
- オプションとして、以下のハードウェア機能を使用可能
  - レイヤーインジケータ／イルミネーションLED
  - Raspberry Pi PICOによる動作（実験的機能）
- 細かな部品を実装済み

---

## 注意事項、制限など

- 試作版のため、未知の不具合がある場合があります

- MBK、またはそれ以下のサイズのキーキャップに合わせて設計されています。  
  Kailh製のロープロファイルキーキャップ（[遊舎工房：Kailhロープロ刻印キーキャップ](https://shop.yushakobo.jp/collections/keycaps/products/pg1350cap-doubleshot)）は隣同士のキーが干渉する可能性があるため、ご自身の責任で使用してください。  
  （こちらで試した限りでは全てのキーが干渉せずに使用できましたが、ギリギリすぎるため保証できかねます。）

- 左シフトキーの2uスタビライザーは取り付けできません。

- 左コントロールキーに、クリックバー付きのスイッチは使用できません。

- 一部のスイッチはネジ穴の上に取り付けるため、Mill-Maxソケットを使用して取り付けます。

- GH60型, Poker型ケースを使用する場合、スイッチとケースのネジ穴との干渉を避けるため、一部のスイッチの足の加工が必要です。

- GH60型, Poker型ケースを使用する場合、中央下側のネジは使用しません。

- ケースへの取り付け

  GH60型, Poker型のネジ穴位置に対応するように設計していますが、もしかしたら取り付けできないケースがあるかもしれません。  
  ケース内にリブのあるもの（60%プラスチックケースや木製ケースなど）は、基板裏側の部品が干渉することが予想され、DIYによる加工が必要となります。
  ここに記載していないケースへの取り付けの成功／失敗の報告を、随時募集しています。

  取り付け確認済みのケースは次の通りです。  
  - [KBDfans 60% ALUMINUM LOW PROFILE CASE](https://kbdfans.com/collections/60-layout-case/products/customized-gh60-aluminum-case)
  - [Jones用ボトムプレート](https://jpskenn.booth.pm/items/3266269)

  ハイプロファイルタイプのケースはキー天面がフレームよりも低くなり実用に向かないため、取り付け対象外とします。  
  参考：[TOFUケースへの装着例](https://twitter.com/jpskenn/status/1466729696713142277)

---

## 部品リスト

このキットを組み立てるためには、”キット内容”に加え、”別途用意が必要な部品”が必要です。  
好みに合わせて必要な数をお買い求めください。

”オプション部品”は使いたい機能などに合わせて用意してください。  

部品の購入先は、Self-Made Keyboards in Japanの[ショップリスト](https://scrapbox.io/self-made-kbds-ja/ショップリスト)などを参考にしてください。

### キット内容

| 部品名 | 個数 | 備考 |
| ----- | :-----: | ----- |
| ご案内リーフレット | 1 | |
| 基板 | 1 | [おもて側<br>基板おもて側](../assets/BuildGuide_v.0.1/_DSF1269.jpeg)<br>[裏側<br>基板裏側](../assets/BuildGuide_v.0.1/_DSF1271.jpeg)<br>（※LEDは取り付けられていません） |
| スイッチプレート | 1 | [おもて側<br>スイッチプレートおもて側](../assets/BuildGuide_v.0.1/_DSF1267.jpeg)<br>[裏側<br>スイッチプレート裏側](../assets/BuildGuide_v.0.1/_DSF1268.jpeg) |
| Choc用スタビライザー<br>2uサイズ | 2 | [](../assets/BuildGuide_v.0.1/IMG_3852.jpeg) |
| スペーサーシート（シール付き）, T1mm * 500mm * 10mm | 1 ||
| 低頭ネジ, M2 4mm | 5 | 主にGH60型ケースとの組み合わせ用 |
| 低頭ネジ, M2 3mm | 8 | 主にJones用ボトムプレートとの組み合わせ用 |
| Mill-Maxソケット 金色<br>7305-0-15-15-47-27-10-0 | 12 | 鍔が薄い |
| Mill-Maxソケット 銀色<br>0305-2-15-80-47-80-10-0 | 2 | 鍔が厚い<br>はんだ付け練習用または予備用 |
| MCU<br>ATmega32u4-AU | 1 ||
| USBコネクタ<br>USB4085-GF-A | 1 ||
| ESD<br>PRTR5V0U2X | 1 ||
| FUSE<br>0ZCJ0050AF2E | 1 ||

※出荷時期により同等品に変更になる場合があります。

### 別途用意が必要な部品

| 部品名 | 個数 | 備考 |
| ----- | :-----: | ----- |
| Choc v1 スイッチ | 74〜75 | v1のみ対応 |
| キーキャップ<br>MBK、またはそれ以下のサイズのもの | 74〜75 | 左シフトが2uの構成：1u 65個, 1.5u 6個, 2u 3個<br>左シフトが1u+1uの構成：1u 67個, 1.5u 6個, 2u 2個 |
| GH60型, Poker型ロープロファイルケース<br>または<br>Jones用ボトムプレートキット(\*) | 1 | ボトムプレートはJones用を流用して使用 |
| USBケーブル （Type-C） | 1 | |

\* Jones用ボトムプレートキットの内容は次の通り
| 部品名 | 個数 | 備考 |
| ----- | :-----: | ----- |
| ご案内リーフレット | 1 ||
| Jones用ボトムプレート v.1 | 1 | [おもて側<br>ボトムプレートおもて側](../assets/BuildGuide_v.0.1/_DSF0644.jpeg)<br>[裏側<br>ボトムプレート裏側](../assets/BuildGuide_v.0.1/_DSF0654.jpeg) |
| スペーサー, M2 3mm | 8 | [](../assets/BuildGuide_v.0.1/_DSF0435_0.jpeg) |
| ネジ, M2 3mm | 16 | [](../assets/BuildGuide_v.0.1/_DSF0435_1.jpeg) |
| ネジ, M2 3mm, 低頭 | 1 | [](../assets/BuildGuide_v.0.1/_DSF0435_2.jpeg) |
| ゴム足 大 | 2 | [](../assets/BuildGuide_v.0.1/_DSF0435_3.jpeg) |
| ゴム足 小 | 6 | [](../assets/BuildGuide_v.0.1/_DSF0435_4.jpeg) |

### オプション部品

| 部品名 | 個数 | 備考 |
| ----- | :-----: | ----- |
| LED<br>SK6812MINI-E | 最大16 | 左上のキーから順番に、取り付けた数だけ点灯。 |
| Raspberry Pi PICO | 1 | 実験的機能をDIYで楽しむ場合 |

---

## 組み立てに必要な工具

M2ネジに対応する先の細いドライバー、ピンセット、はんだ付け関連用品など、一般的な電子工作向け工具を使用します。  
また、MCUやUSBコネクタを取り付けた後の確認に、テスターが必要です。  
[遊舎工房の工具セット](https://yushakobo.jp/shop/a9900to/)を参考に用意してください。

キースイッチの取り外し用の工具があると作業がはかどります。  
[TALP KEYBOARDで売っているこのタイプ](https://talpkeyboard.net/items/601362fe2438601925ad0692)は、1本でキースイッチとキーキャップの両方に使えるので便利です。

また、マスキングテープが1巻あると、基板や部品の仮固定などに使えて便利です。

---

## 組み立て手順

以下の手順に沿って組み立てます。  
`（オプション）`と書かれた項目は、不要であれば作業をとばしてもかまいせん。  
`（該当者のみ）`と書かれた項目は、条件に該当する場合のみ作業をおこないます。

工具類や部品による怪我や、はんだ作業での火傷などに気をつけてください。  

### 同梱物の確認

リーフレットに記載された部品が、不足なく入っていることを確認します。

何か問題があった場合は作業を中止し、リーフレットに記載された連絡先へ問い合わせてください。  

*組み立ての開始後は初期不良として対応できかねる場合があります。*

### 基板にMCUやUSBコネクタなどのパーツを取り付ける

以下の簡単な説明を読み、どうにかして必要なパーツを取り付けます。

<details>
<summary>《詳しい説明》</summary>

#### MCUを取り付ける

基板裏側、`U3`へ取り付けます。  
2種類のMCUが取り付けられるようになっていますが、ATmega32u4-AUは外側の大きい方のパッドへ取り付けます。

いずれかの角、1箇所だけに予備はんだします。  
MCUを基板のマークに合わせて置き、予備はんだした箇所をはんだ付けします。  
ずれ、傾きがないように調整します。

MCU placement direction
MCU取り付け方向

対角上の角を1ピンだけはんだ付けします。

はんだ付けされていない辺のうち、どちらかの辺のピンを、すべてはんだ付けします。  
フラックスを塗り、ハンダの量をこて先に少しつけるくらいから始め、なんとかします。

同様の手順で、反対側の辺、残ったうちのどちらかの辺、最後に残った辺のピンをはんだ付けします。

フラックスを拭き取り、テスターで隣同士のピンがショートしていないか確認します。

また、MCUのピン割り当てを参考に、以下の3点を確認します。

- +5V同士が導通すること
- GND同士が同通すること
- +5VとGNDが導通*しない*こと

MCU Pin assign
基板裏側から見た、MCUのピン割り当て

#### USBコネクタを取り付ける

基板裏側`J1`の`INSTALL HERE`と書かれたところへコネクタを取り付け、基板おもて側からはんだ付けします。  
コネクタはマスキングテープなどで仮固定しておくと作業しやすくなります。

以下の接続図を参考に、テスターでピンを確認します。

USB Connector
基板おもて側から見た、USBコネクタのピン割り当て

#### ESDを取り付ける

基板裏側`D10`へ、GNDに太い足がくるように取り付けます。

ESD placement direction
ESD取り付け方向

#### FUSEを取り付ける

基板裏側`F1`へ取り付けます。（USBコネクタの左隣）  
どちら向きに取り付けてもかまいません。

#### リセットスイッチを取り付ける

基板裏側`Reset SW`へ取り付けます。  
どちら向きに取り付けてもかまいません。

#### I2Cプルアップ抵抗をジャンパする

基板裏側`JP1`と`JP2`をジャンパします。  
ジャンパすると、I2Cのプルアップ抵抗へ接続されます。

#### ファームウェアを書き込む

基板上のMCUにファームウェアを書き込みます。

ここでは、QMK Toolboxを使用して書き込む手順を説明します。

いずれかの方法でファームウェアを用意します。

- Remap / VIA対応のビルド済みファームウェアをダウンロードする。
  [Nora v.0.1 ビルド済みファームウェア](https://gist.github.com/jpskenn/a2b5fe920d72f23244ac4f5b38f8a0d8)

- ソースからビルドする
  [keyboards/nora/v01](https://github.com/jpskenn/qmk_firmware/tree/develop_Nora/keyboards/nora/v01)

QMK Toolboxでファームウェアを開きます。

基板のコネクタにUSBケーブルを差し込み、PCやMacへ接続します。

基板裏側のリセットスイッチを押します。  
QMK Toolboxの画面に、次のようなメッセージが表示されます。

```text
*** Atmel DFU device connected: ATMEL ATm32U4DFU (03EB:2FF4:0000)
```

QMK Toolboxの`Flash`ボタンを押し、書き込みを始めます。  
5秒ほどすると以下のようなメッセージが表示され、書き込みが終了します。
```text
*** Attempting to flash, please don't remove device
>>> dfu-programmer atmega32u4 erase --force
    Erasing flash...  Success
    Checking memory from 0x0 to 0x6FFF...  Empty.
>>> dfu-programmer atmega32u4 flash --force /Users/jpskenn/qmk_firmware/nora_v01_via.hex
    0%                            100%  Programming 0x5E80 bytes...
    [>>>>>>>>>>>>>>>>>>>>>>>>>>>>>>>>]  Success
    0%                            100%  Reading 0x7000 bytes...
    [>>>>>>>>>>>>>>>>>>>>>>>>>>>>>>>>]  Success
    Validating...  Success
    0x5E80 bytes written into 0x7000 bytes memory (84.38%).
>>> dfu-programmer atmega32u4 reset
*** Atmel DFU device disconnected: ATMEL ATm32U4DFU (03EB:2FF4:0000)
```

ファームウェアの書き込みが終わってから、そのまま、さらに15秒ほど待ちます。  
外部EEPROMの消去処理がおこなわれ、キーボードが起動します。  
※メッセージなどは表示されません

**ファームウェアの書き込み後、初めてRemapに接続した際、10秒ほど固まる場合があります。**  
**キーボードが整うまで、ほんの少しお待ちください。**

</details>

### 基板回路の確認

キースイッチまたはMill-Maxソケットを取り付ける箇所（スルーホール）をショートさせて、基板回路が電気的に正しく反応することを確認します。  

レイアウトを画面見ながら確認できるので、キーマップ書き換えツール[Remap](https://remap-keys.app/)のテスト機能を使う方法がおすすめです。  

<details>
<summary>《詳しい説明》</summary>

その他の方法として、OSのキーボードビューアや[Keyboard Checker](https://keyboardchecker.com)、[QMK Configurator](https://config.qmk.fm/)のキーボード入力テストを使用して確認することもできます。  
[VIA](https://caniusevia.com)を使用する際は、この定義ファイル（[nora_v01.json](https://github.com/jpskenn/Nora/blob/main/VIA/nora_via_v01.json)）を読み込ませてください。

ここでは、キーマップ書き換えツール[Remap](https://remap-keys.app/)のテスト機能を使い、確認を行います。

基板の裏面が上側になるように置き、PCやMacとUSBケーブルで接続します。

Google Chromeブラウザ（Web HID対応のバージョン89以降）で、[Remap](https://remap-keys.app/)を開きます。

`START REMAP FOR YOUR KEYBOARD`をクリックしてキーボード接続画面に進みます。

`+ KEYBOARD`をクリックしてデバイスへの接続要求画面を開きます。

デバイスへの接続要求画面で`Nora`を選択して`接続`をクリックすると、画面にキーボードのレイアウトが表示されます。

レイアウト右側の`Layout Option`で、組み立てようとしているレイアウトに設定します。  
キーマップは組み立て完了後に変更するため、ここではレイアウトだけ設定して先へ進みます。

Layout Option

レイアウト右側の`…`をクリックし、`Test Matrix mode`を選択します。

ピンセットなどの電気を通すものを使い、スルーホールをショートさせます。

Remapの画面で、ショートさせた箇所に対応するキーの色が変わることを確認します。  

同様の作業を繰り返し、全てのキーの色が変わることを確認します。  

確認が終わったら、USBケーブルを抜きます。

</details>

### 左シフトキーの構成を決める

左シフトキーの構成を、2u 1個、または1u 2個のどちらかに決めます。  
なお、スイッチ配置の都合により、左シフトキーにスタビライザーは取り付けできません。

レイアウトをまとめた[Keyboard Layout Editor: Nora v.0.1](http://www.keyboard-layout-editor.com/#/gists/33874da3b7be015c26f7f6f09a010688)も参考にしてください。

### Mill-Maxソケットを取り付ける

ケースネジの上に取り付けるスイッチが取り外せるように、Mill-Maxソケットを取り付けます。  

スイッチ端子のスルーホールに`Socket`と書かれた6箇所へ、基板おもて側からMill-Maxソケットを差し込み、基板裏側からはんだ付けします。  

ソケット取り付け箇所
ソケット取り付け箇所

左端の転線で囲った箇所は、左シフトキーを1u 2個の構成にした場合のみソケットを取り付けます。

基板の中央下部に、ソケットのはんだ付け練習場所があります。  
はんだ付けに不安がある場合は、キット同梱の練習用Mill-Maxソケット（銀色）を使って練習できます。

```aside
練習用Mill-maxソケット（銀色）はソケットの鍔（つば）が厚いため、実際に使用するスイッチの取り付けには適しません。
```

<details>
<summary>《詳しい説明》</summary>

基板裏側の`Socket`と書かれた箇所のスルーホールへ、基板おもて側からソケットを差し込みます。  
基板を裏返したときにポロッと外れてしまうようなら、マスキングテープでとめておきます。

基板の裏側が上になるように置きます。

はんだごてを用意します。  
こて先の温度を320℃程度にします。  

ここからは、1、2、3、4、5、6、7と数える間に次の手順をおこないます。  
時間をオーバーしてもソケットは壊れませんので、ゆっくりと落ち着いて、ソケットの中にハンダが入ってしまわないよう、慎重に作業してください。

1、2、3：
基板の裏側から、こて先を基板から飛び出しているソケットの側面とスルーホールの両方にあて、十分温めます。  
こて先をソケットの端の方まで当ててしまうと、ソケットの内側にはんだが流れ込みやすいため、当て方を工夫します。

4、5、6：
ソケットとスルーホールの間あたりへ、はんだをチョンと押し付けて離します。  
溶けたはんだをソケットとスルーホールの隙間に流し込みます。  
はんだが隙間から少しだけ出て盛り上がる程度まで、何度か繰り返します。  
**ソケットの内側にはんだが入ってしまわないよう、少しずつ、慎重におこないます。**

7：
こて先を離します。

ソケットの全周にわたってはんだが流し込まれ、スルーホールとの隙間が埋まっていれば良い仕上がりです。

同様の手順で、必要な数のソケットを取り付けます。

ソケットの内側にはんだが入ってしまったりして取り外す必要がある場合は、[参考：トラブル対応：Mill-Maxソケットの取り外し方](#トラブル対応mill-maxソケットの取り外し方)を参照してください。

</details>

### （オプション）LEDを取り付ける

*LEDを使用しない場合、この手順は不要です。*

基板裏側から、16個のLEDを取り付けます。

<details>
<summary>《詳しい説明》</summary>

#### LEDを取り付ける

基板を裏側が上になるように置きます。

はんだごてを用意します。  
こて先の温度は320℃程度にします。  

基板裏側のジャンパ`JP3:LED +5V source`を`Onboard`にジャンパ（隣同士のパッド（基板上の小さな四角の銀色部分）にはんだをつけてつなげること）します。  
3個並んだパッドのうち、中央と`Onboard`の2個にまたがるようにこて先を当てて温めます。  
こて先にはんだを押し付け、少したっぷり目に溶かし、こて先で基板をなでるように横へスッとずらしてパッドから離し、2個のパッドをはんだでつなぎます。  
なかなか上手くジャンパできないのですが、何度かトライすればそのうちできます。  
こて先でパッドをグリグリいじるとパッドが剥がれて大変なことになるため、「はんだをつけて横へスッ」の動きを守って作業します。

LED（SK6812MINI-E）を1個、手元に用意します。

LEDの発光部分（透明な窓があるところ）が下側になるように持ちます。  
LEDから出ている4本の端子のうち、角が斜めになっている1本が、基板に描かれた印に合うようにして、基板の穴にはめこみます。  
4本の端子が基板にぴったりくっついていない場合は、軽く押し込みます。

はんだごてを用意します。  
LEDは高温ではんだ付けすると壊れやすいため、こて先温度を少し低めの220-270℃に設定します。  
温度の設定ができない場合は、以下の手順で数える時間を半分にして試します。（はんだの溶け具合が悪ければ時間を伸ばします）

ここからは、1、2、3、4、5と数える間に次の手順をおこないます。

1、2：  
4本の端子のどれかひとつにこて先をあてて押さえ、端子とパッドを温めます。  

3、4：  
はんだを端子（またはパッド）に当てて溶かし、端子とパッドにはんだを行き渡らせて、はんだを離します。  
こて先はグリグリ動かしません。はんだ溶けて、自然に濡れ広がっていくような具合です。

5：  
こて先を離します。

はんだが、端子とパッド全体に行き渡っていれば良い仕上がりです。  
LEDが傾いてしまった場合は、ピンセットでLEDをつまみ、はんだ付けした端子をこて先で温めながら傾きを修正します。  

続いて、最初にはんだ付けした端子とLED本体を挟んだ反対側の端子2本を、1本ずつ、同様の手順ではんだ付けします。

最後に、残った1本の端子をはんだ付けして、LED1個の取り付け完了です。

この作業を繰り返し、必要な数のLEDを取り付けます。

#### LEDの動作確認

LEDが正しく取り付けられているか、動作確認をおこないます。

USBケーブルを接続します。

左端のLED1個が白色、残りのLED15個が赤色に点灯していれば正常です。  
点灯しいないLEDがある場合は、[トラブル対応：LEDの取り付け不良調査](#トラブル対応LEDの取り付け不良調査)を参考にして調査します。

</details>

### （オプション）スタビライザーを取り付ける

*スタビライザーを使用しない場合、この手順は不要です。*

親指の2uキーに使用するスタビライザーを、スイッチプレートに取り付けます。

スタビライザーは、キーの左右の端を押したときでも、スイッチの軸をまっすぐに押し込むための部品です。
取り付けは必須ではありませんので、使用スタイルに合わせて取り付けるか決めてください

- 取り付ける場合

  キーのどこを押してもまっすぐに押し込むことができますが、スタビライザーのカチャカチャという動作音が気になることがあります。

  →打鍵の安定性を優先する方に最適。  
  →指のポジションや打鍵スタイル的に、キーの左右の端を押しがちな方にもおすすめ。  
  →多少の動作音は気にならない方、または、ルブやModで動作音を低減すれば十分な方にもおすすめ。

- 取り付けない場合

  キーの端を押すと少し引っかかりがあって押し込みにくくなりますが、動作音が無くなり静かになります。  

  →静かさを優先する方に最適。  
  →おもにキーの中央部分を打鍵するスタイルで、スタビライザーがなくても特に影響のない方はこちら。

<details>
<summary>《詳しい説明》</summary>

#### スタビライザーを組み立てる

プラスチックパーツと金属の棒を組み合わせて、スタビライザーを2個組み立てます。

大きいプラパーツと小さいプラパーツを、それぞれ1個用意します。  
小さいパーツの`＋`部分がセンターから少しずれている方向を、大きいパーツのワイヤーがはまる方向に合わせます。

大きいパーツと小さいパーツを並べる
大きいパーツと小さいパーツを並べる

大きいパーツの下側から、小さいパーツをはめこみます。  
途中に引っ掛かりがあるので、指でパチンと押し込みます。

大きいパーツの下側から、小さいパーツをはめる。
大きいパーツの下側から、小さいパーツをはめる。

小さいパーツがはめこまれた状態
小さいパーツがはめこまれた状態

同じようにして、もう1組のプラパーツをはめこんでおきます。

ワイヤーとはめこんだパーツを1個用意します。  
小さいパーツの穴にワイヤーを差し込み、大きいパーツにワイヤーをはめます。  
ワイヤーは、大きいパーツにパチンとはまわるわけではなく、ふわっと乗っているだけで固定されません。  
（ワイヤーは、スイッチプレートにスタビライザーを取り付けた際に固定されます）

プラパーツ1個にワイヤーをはめた状態
プラパーツ1個にワイヤーをはめた状態

プラパーツをもう1個用意し、ワイヤーをはめます。  
ワイヤーはプラパーツに乗っているだけで、パチンとはまったりしません。
ワイヤーが固定されないので、こっちをはめたらあっちが外れたりして、すこしイライラする作業になります。

プラパーツ2個にワイヤーをはめた状態
プラパーツ2個にワイヤーをはめた状態

同様に、もう1個組み立てます。

#### スイッチプレートにスタビライザーを取り付ける

スイッチプレートの裏側からスタビライザーをはめて取り付けます。

組み立てたスタビライザーを1個用意し、キーキャップにはまる`＋`の部分を上にして、金属の棒の中央部が奥になるような方向で置きます。

プレートを、スタビライザーがはまるスペースキー部分が手前で、おもて側が上になるように持ちます。  
左右どちらかの取り付け穴に合わせるようにして、スタビライザーの上にプレートを置きます。  
小さい四角と大きい四角にスタビライザーのプラ部分が入るように、位置を合わせます。

プレートとスタビライザーの位置を合わせる様子
プレートとスタビライザーの位置を合わせる様子

位置を合わせた状態でスタビライザーをプレートの穴に押し込み、持ち上げても外れない程度にはめ込みます。  

スタビライザーをプレートに軽くはめる
スタビライザーをプレートに軽くはめる

プレートを持ち上げ、プラパーツをうしろから指で押し込んでパチンとはめ、奥まで押し込んでおきます。

うしろから押し込んだスタビライザー
うしろから押し込んだスタビライザー

もう1個のスタビライザーも、同じように取り付けます。

スタビライザーを取り付けた状態
スタビライザーを取り付けた状態

</details>

### スイッチプレートにシートを貼り付ける

基板とスイッチプレートの隙間を埋めるシートを、スイッチプレート裏側へ貼り付けます。  
以下の写真に示すような位置へ、ちょうど良い長さにシートをはさみなどで切り離してください。  
USBコネクタの位置には、貼り付けません。

Put sheet pieces to switch plate
スイッチプレートにシートを貼り付けた状態  
（ほぼ透明のシートを使用したため、多少見づらくなっています）

Raspberry Pi PICOを使用する場合は、コンスルーの足がシートに当たってしまうため、中央上部には貼り付けません。

### スイッチとスイッチプレートを基板へ取り付ける

スイッチを、スイッチプレートをはさむようにして基板に取り付けます。  

**スイッチとスイッチプレートを取り付けた後は、それらを取り外さない限り、スタビライザーの取り付け・取り外しができなくなります。**  
スイッチのはんだを除去して、スイッチとスイッチプレートを取り外すことは可能ですが、そこそこ面倒な作業になります。

#### スイッチ取り付け前の確認

スイッチの端子を見て、折れたり、曲がったりしていないことを確認します。  
少しだけ曲がっているものは、まっすぐにしておきます。

```aside
折れてしまっているものは使用できません。
また、大きく曲がっているものは強度が落ちて折れやすいため、なるべく使用しないようにします
```

<details>
<summary>《詳しい説明》</summary>

折れてしまっているものは使用できません。  
また、大きく曲がっているものは、まっすぐに戻しても折れやすくなっているため、使用を避けた方がよいでしょう。

</details>

#### スイッチプレートを仮固定する

スイッチプレートの4隅にスイッチをはめ込み、基板へはんだ付けして仮固定します。  

<details>
<summary>《詳しい説明》</summary>

スイッチプレートをおもて側が上になるように置きます。

プレートの4隅に、スイッチの方向を基板のスイッチ端子のスルーホールの方向に合わせて、パチンとはめ込みます。  
プレートに対し、スイッチ端子が手前側になるのが正しい方向です。

スイッチがプレートの枠にぴったり密着してはまっていることを確認します。

プレートの隣に、基板をおもて側が上になるように置きます。

スイッチ4個を取り付けたプレートを持ち上げ、スイッチ端子と基板のスルーホールの位置を合わせながら、基板に乗せて重ねます。  
スイッチ端子がスルーホールに入った状態にします。

プレートと基板を重ねたまま持ち上げ、基板の裏側を支えながら、スイッチを押し込みます。  
5ピンのスイッチを取り付ける場合は、スイッチ固定用のプラスチックピン2本が根元まで刺さり、スイッチが基板にほぼくっついた状態にします。

基板の裏側が上になるように置きなおします。

はんだごてを用意します。  
こて先の温度は320℃程度にします。  

ここからは、1、2、3、4、5、6と数える間に次の手順をおこないます。  
多少時間をオーバーしても壊れませんので、焦ることはありません。  
しかし、あまり時間をかけるとはんだ内のフラックスが蒸発して仕上がりが悪くなるため、オーバータイムで8くらいまでには終わるようにします。

1、2：
スルーホールから飛び出したスイッチ端子とスルーホールの両方に当たるように、こて先をあてて温めます。

3、4、5：  
はんだをスイッチ端子（またはスルーホール）に当てて溶かし、端子とスルーホールにはんだを行き渡らせて、はんだを離します。  
スイッチ端子の先の方だけでなく、スルーホール内部にもはんだが入っていくようにします。

6：  
こて先を離します。

スイッチ端子とスルーホールがはんだで覆われ、はんだが富士山型に盛り上がったようになっていれば良い仕上がりです。

作業を繰り返し、4個のスイッチ（＝8本のスイッチ端子）を、すべてはんだ付けします。

</details>

#### 残りのスイッチを取り付ける

ソケットを使用するスイッチを除いて、残りのスイッチをすべて取り付けます。  
**左コントロールに、クリックバー付きのスイッチは使用できません**

スイッチプレートの仮固定でおこなった作業と同様に、プレートにスイッチをはめ込み、基板裏側からはんだ付けする作業を繰り返します。  
左シフトキーは、自分で決めた構成（2u 1個、または、1u 2個）になるように取り付けるます。

#### スイッチの動作確認

組み立て前におこなった[基板回路の確認](#基板回路の確認)と同様の手順で、スイッチのはんだ付けが正しく行われているか確認します。  
この手順ではスイッチを押して正しく反応することを確認します。

正常に入力できないスイッチがあった場合は、[トラブル対応：正常に入力できないスイッチの原因調査](#トラブル対応正常に入力できないスイッチの原因調査)の手順に沿って調査します。

### 基板をケース、またはボトムプレートへ取り付ける

スイッチとプレートが組み合わされた基板を、ケース、またはボトムプレートへ取り付けます。

#### （該当者のみ）GH60型, Poker型ケースへ取り付ける

*GH60型, Poker型ケースを使用する場合のみ、この手順をおこないます。*

ケースに基板をねじ止めして取り付けます。

打鍵感向上に興味のある方は、次の項目をお読みになると何かヒントがあるかもしれません。

- [打鍵感向上：ケース内部の制振と静音化](打鍵感向上：ケース内部の制振と静音化)

<details>
<summary>《詳しい説明》</summary>

ケースを安定したところへ置き、スイッチとスイッチプレートが組み合わされた基板を手に持ちます。

基板を水平から30度くらいの角度に持ち、奥側（USBコネクタ）から斜めにケース内へ入れていきます。  
斜めに差し込んでいくと、USBコネクタがケースの穴にスッとはまります。

USBコネクタがはまった状態で基板の手前側を静かに下ろして水平にすると、力をかけることなく、基板全体がストンとケースに入ります。  
力を入れてグリグリとこじったりググググッと押し込むようなことはせず、角度を合わせて差し込んで、水平にするだけです。

ケースネジ穴と基板のネジ穴の位置を合わせ、ネジで仮止めします。  
左上の1箇所のみ、ケース付属のネジを使用します。  
それ以外の、左端、右端、右上、中央、中央下の5箇所は、ネジ穴とスイッチが重なるため、キット同梱の低頭ネジ（M2 4mm）を使用します。  

ケースに対して基板の位置が上下左右の真ん中になるように調整し、ネジが軽く止まる程度まで締めて基板を固定します。

ケース底面に、滑り止めのゴム足を貼り付けます。

</details>

#### （該当者のみ）ボトムプレートへ取り付ける

*ボトムプレートキットを使用する場合のみ、この手順をおこないます。*

ネジとスペーサーを使い、ボトムプレートに基板を取り付けます。

<details>
<summary>《詳しい説明》</summary>

*Jones用ボトムプレートキットに同梱されているネジ（M2 3mm）16個のうち、半分の8個は使用しません。*  
*かわりに、Noraキット同梱の低頭ネジ（M2 3mm）8個を使用します。*

ボトムプレート裏側から、以下の写真に示す○印をつけた8箇所に、ボトムプレートキットに同梱のネジ（M2 3mm）を使い、スペーサー（M2 3mm）をねじ止めします。  
右上の◎印をつけた箇所は、スイッチとの干渉を避けるため、スペーサーを右側へ寄せてねじ止めします。  

スペーサー取り付け箇所
スペーサー取り付け箇所

基板を、ボトムプレートに取り付けたスペーサーの位置に合わせて乗せます。  
基板裏側の部品がスペーサーにぶつからないように気をつけてください。

基板おもて側から、Noraキット同梱の低頭ネジ（M2 3mm）を使い、基板とスペーサーをねじ止めします。  

ボトムプレート底面に、滑り止めのゴム足を貼り付けます。  

- キーボードに傾斜をつける場合
    奥の左・右の2箇所：ゴム足 大
    手前の左・中・右の3箇所：ゴム足 小

- キーボードをフラットにする場合
    手前と奥の左・中・右の6箇所：ゴム足 小

見た目を良くしたい場合は、スイッチプレート, 基板, ボトムプレートの側面を、水性顔料インクのポスターカラーや油性マジックなどを使って塗ります。  
また、スイッチプレートと基板の周りにマスキングテープなどを貼り付けて、見た目の印象を変えることもできます。

</details>

### スイッチをソケットに取り付ける

基板のねじ止めが終わったので、ネジに重なるスイッチをソケットに取り付けます。  
GH60型, Poker型ケースを使用する場合は、ケースのネジ穴に干渉するスイッチの足を加工して取り付けます。

#### （該当者のみ）ケースのネジ穴に干渉するスイッチの足を加工する

*GH60型, Poker型ケースを使用する場合のみ、この手順をおこないます。*

<details>
<summary>《詳しい説明》</summary>

中央と右上のケースのネジ穴に干渉する、スイッチ2個の足を加工します。  


スイッチの足を加工して取り付ける箇所

- 中央のネジ穴に重なるスイッチ  
  3ピンのスイッチは加工不要で取り付けできます。
  5ピンのスイッチを使用する場合は、ネジ穴に干渉する片方の足を切断します。  
  おそらく回避できると思いますが、もしスイッチの中央の足が干渉する場合は、中央の足も切断します。

- 右上のネジ穴に重なるスイッチ  
  スイッチ中央の足（出っ張り）を、ネジ穴に当たらない程度に一部切断して取り付けます。  
  ケースによってスイッチとの干渉具合が変わってくるため、現物合わせでどれくらい切断するかを判断します。

  中央の足をカットしたスイッチ
  中央の足をカットしたスイッチ

  また、押下時にスイッチの軸がネジに当たる場合は、軸の下端を切断したりして調整します。

  軸の下端を切断した状態
  軸の下端を切断した状態

</details>

#### スイッチをスイッチプレートにはめ込む

スイッチの端子がソケットへまっすぐ刺さるようにして、スイッチプレートにはめ込みます。

#### ソケットへ取り付けたスイッチの動作確認

[基板回路の確認](#基板回路の確認)と同様の手順で、ソケットへ取り付けたスイッチが正しく反応することを確認します。

正常に入力できないスイッチがあった場合は、[トラブル対応：正常に入力できないスイッチの原因調査](#トラブル対応正常に入力できないスイッチの原因調査)の手順に沿って調査します。

### 仕上げ

キーキャップを取り付けます。

Remapで自分好みのキーマップに変更します。

完成です。

製作例
製作例

写真を撮影し、`#Nora_kbd` のタグをつけてツイートすると設計者が喜んだりします。  
[Twitter: #Nora_kbd](https://twitter.com/search?q=(%23nora_kbd)&src=typed_query&f=live)

---

## 参考

打鍵感向上や機能追加についてのDIY情報や、トラブル調査方法などの参考資料です。  
必要に応じてお読みください。

### 打鍵感向上：ケース内部の制振と静音化

ケースやボトムプレートに工夫を施すことで、打鍵感を向上させる方法について説明します。

<details>
<summary>《詳しい説明》</summary>

- ケースの振動防止

    ケース内部におもりを入れておくと、ケースの共振が抑えられ、打鍵感の向上や、打鍵音の変化が期待できます。  
    おもりには、10円玉、真鍮板、自動車タイヤ用のホイールバランスウェイト、鉛シートなどを使用します。  
    また、スポンジ状の両面テープなどを使っておもりを貼り付けると、より高い防振効果を得ることができます。

    基板裏側の部品におもりの金属部分がふれてショートしないよう、スポンジシートを間に挟んだり、カプトンテープなどで保護します。

- 基板の振動防止

    基板とケース間をウレタンスポンジやシリコンシートなどで埋めると、基板の振動を抑えることができます。  
    また、ケース内部の空間を埋めることで、基板の振動音やスイッチの動作音がケース内で響くのを減らすことができます。

    ボトムプレートを使用する場合も、基板とボトムプレートの間に対策を施すことで、同様の効果が期待できます。

    スポンジなどを詰めすぎると、ネジや基板裏側の部品に力がかかるため、ほどよい程度に調節します。

これらの工夫をおこなう様子はこちら  
→[ケースが響いてうるさいのをなんとかしていく](https://twitter.com/jpskenn/status/1467010813773119490)

</details>

### トラブル対応：正常に入力できないスイッチの原因調査

正常に入力できないスイッチの原因調査と対応方法について説明します。  

スイッチの取り付け方法に該当する項目を参照してください。

<details>
<summary>《詳しい説明》</summary>

テスターをお持ちの方は、疑わしい箇所をテスターで調べるのが手っ取り早い方法ですので、積極的に使用してください。

#### Mill-Maxソケットを使用して取り付けるスイッチ

ほとんどの原因は、スイッチのソケットへの取り付け不良です。  
スイッチを取り外し、端子が曲がったり折れたりしていないことを確認します。  
端子の曲がりを修復するか、新しいスイッチに交換して、もう一度キー入力を確認します。

ごくまれにソケットのはんだ不良が原因の場合があります。  
ソケットのはんだ忘れや、はんだが適切に行われていないことが原因のため、ソケットのはんだ状態を確認します。  
必要であれば再度はんだ付けし直して、もう一度キー入力を確認します。

上記で解決できなかった場合は、基板にはんだ付けされたMill-Maxソケットをピンセットなどを使ってショートさせ、キー入力を確認します。  
キー入力が確認できた場合は、ソケット自体は正しく取り付けられているので、スイッチを再度調査します。

#### はんだ付けして取り付けるスイッチ

ほとんどの場合、スイッチのはんだ不良が原因です。  
スイッチの端子にはんだがついているように見えて、実はスルーホールの中がスカスカという場合もあります。  
一旦、はんだ吸い取り線（ソルダーウィッグ）などではんだを除去し、はんだ付けをやり直してから、もう一度キー入力を確認します。

また、かなりレアなケースですがスイッチ自体が壊れている場合もあるため、別のスイッチに交換して試してみます。

#### それでも解決しない場合

組み立て前におこなった[基板回路の確認](#基板回路の確認)でおこなったように、基板のスルーホール部分をピンセットなどでショートさせ、正しく反応するか確認します。

この作業でキー入力が確認できない場合は、組み立て途中に基板の配線や部品がダメージを受けたことが原因と考えられます、これ以降の調査と修復の難易度が高くなります。

電子工作に詳しい方であれば、[NoraのKiCadプロジェクト](https://github.com/jpskenn/Nora/tree/master/PCB)を参考にテスター等を用いて調査を進め、ジャンパ線などで配線を修復してください。

自分ではどうにもできない方は、キット同梱のリーフレットに記載された連絡先へ問い合わせてください。  
状況に応じて、できる限りのサポートをいたします。  

</details>

### トラブル対応：LEDの取り付け不良調査

LEDが点灯しない場合など、LEDの取り付け不良を調査する方法について説明します。

<details>
<summary>《詳しい説明》</summary>

#### ジャンパの確認

ジャンパ`JP3: LED +5V source`が、正しくジャンパされていることを確認します。  
使用するMCUに合わせてジャンパする位置の組み合わせが異なりますが、通常は`Onboard`へジャンパします。

MCUとジャンパの組み合わせは次の通り。

| MCU | ジャンパ位置 | 備考 |
| :--: | :--: | :-- |
| ATmega32u4 | `Onboard` | 通常の組み合わせ |
| Raspberry Pi PICO | `PICO VBUS` | |

#### LEDの確認

ジャンパが正しく行われても点灯しない場合は、LEDに原因があると考えられますので、以下の順に対処します。  

```aside
なお、基板の配線へのダメージなど、他の要因も考えられますが、確率はかなり低いです。  
「組み立て中に工具で基板をガリっとやってしまった…」などの心当たりがあれば、また別ですが…
```

1. 光らないLEDのはんだ不良を修復する
    光らないLEDが正しくはんだ付けされていない、と仮定した対処です。
    光らないLEDの側面の端子部分にフラックスを塗り、こて先につけたはんだを押しあてて、はんだ付けをやり直します。

1. 光らないLEDの*ひとつ前*のLEDのはんだ不良を修復する
    光らないLEDのはんだは正常だが、ひとつ前のLEDのはんだ不良が原因で配線がつながっていない、と仮定した対処です。
    LEDは組み合わせによって、以下に示す順番で並んでいます。
    ひとつ前のLEDのはんだ付けをやり直します。
    | 組み合わせ | LEDの並び |
    | :--: | :-- |
    | 左側のみ | 左上（LED1） → 左下（LED2） |
    | 右側のみ | 右上（LED3） → 右下（LED4） |
    | 左右両方 | 左上（LED1） → 左下（LED2） → 右上（LED3） → 右下（LED4） |

1. 光らないLEDを新しいものに交換する
    220-270℃で1、2と数える程の加熱ではそう簡単にはLEDは壊れないと考えますが、何度かはんだをやり直しても点灯しない場合は、LEDが壊れていると判断して新しいものに交換します。

</details>

### トラブル対応：Mill-Maxソケットの取り外し方

Mill-Maxソケットを取り外すヒントです。  
「温めながら、押し出す」という方針でおこないます。

#### 用意するもの

- 竹串や爪楊枝など
  先の尖った、木製の棒状のもの。  
  金属製のものは、はんだがくっついて作業しにくい場合があります。
- はんだごて

#### 取り外し方法

この手順では竹串を使って説明します。

基板の裏側から、ソケットの穴へ竹串の尖った方の先端を、軽く差し込みます。  
グリグリと押し込む必要はなく、少しテンションがかかる程度でかまいません。

竹串の先端が差し込まれた状態のまま、基板のおもて側が上になるように置きます。  
この状態を作るのが難しいですが、竹串をいい具合の長さに折ったり、利き手とは逆の手で竹串と基板をつかんだりして、なんとかします。

はんだごてを用意します。  
こて先の温度を320℃程度にします。  

基板のおもて側から、ソケットの鍔（つば）部分にこて先を当てて温めます。

温まってはんだが溶ければ、竹串にかかっているテンションに押され、ソケットが基板から押し出されてきます。  
（このタイミングで、ソケットがポロッと外れることもあります）

基板をおもて側が上になるように置きます。

ソケットが基板から半分ほど出た状態で、ソケット側面にはんだごてを当てて温め、ソケットの鍔に竹串を引っ掛けたり、ピンセットでつまんだりして取り外します。

### 資料：ファームウェアの書き込み方法

ファームウェアの書き込み方法について説明します。

<details>
<summary>《詳しい説明》</summary>

#### QMK Toolboxの使用

ビルド済み（≒作成済み）のキーボード用ファームウェアを書き込むには、[QMK Toolbox](https://github.com/qmk/qmk_toolbox/releases)を使用します。

QMKファームウェアに関するドキュメントの、[ファームウェアを書き込む](https://docs.qmk.fm/#/ja/newbs_flashing?id=ファームウェアを書き込む)を参考に、QMK Toolboxを使ってキーボードに書き込みます。

#### キーボードを DFU (Bootloader) モードにする方法

NoraキーボードでDFU (Bootloader)モードにするには、次のように操作します。

1. USBケーブルを抜く

1. キーボードの左上のキーを押したまま、USBケーブルを差し込む

この操作によってEEPROMも消去されるので、古いデータが残って動作がおかしくなるのを防止できます。  
ファームウェアの書き込みが終わった後に外部EEPROMの消去がおこなわれるため、**キーボードの起動まで5〜10秒ほどかかります**。（書き込み直後の初回起動のみ）

**何らかの理由で上記の操作でモードが変わらない場合は、次のように操作します。**

1. USBケーブルを差し込みます。（キーボードが普通に使える状態）

1. 基板裏側のリセットボタン`Reset SW`を押します。

この操作をおこなった場合は、ファームウェアの書き込み後に[資料：EEPROMを消去して、初期状態に戻す方法](#資料eepromを消去して-初期状態に戻す方法)を実施して、EEPROMを初期状態に戻す必要があります。

</details>

### 資料：Noraキーボードのファームウェア

ビルド済みファームウェアと、ソースファイルを用意しています。

#### ビルド済みのファームウェア

- [Nora v1 ファームウェア, VIA対応デフォルト](https://gist.github.com/jpskenn/a2b5fe920d72f23244ac4f5b38f8a0d8)

#### ファームウェアのソース

プルリクエストが取り込まれるまでは、私がQMKからフォークしたリポジトリ  
[https://github.com/jpskenn/qmk_firmware](https://github.com/jpskenn/qmk_firmware)  
を使用してください。  

[develop_nora](https://github.com/jpskenn/qmk_firmware/tree/develop_Nora)ブランチの、`keyboards/nora/v01`に関連ファイルが格納されています。

### 資料：EEPROMを消去して、初期状態に戻す方法

キーマップやLEDの表示モードなどのEEPROMに記録されているデータを消去し、初期状態に戻すことができます。  

また、古いデータが残って動作がおかしくなるのを防止するため、ファームウェアを書き換える際にもこの操作をおこないます。

<details>
<summary>《詳しい説明》</summary>

USBケーブルを抜きます。

キーボードの左上のキーを押したまま、USBケーブルを差し込みます。

差し込んで1,2と数えてから、USBケーブルを抜きます。

USBケーブルを差し込みます。

5〜10秒ほどで外部EEPROMが消去され、キーボードが動作するようになります。  

これで設定が初期状態に戻ります。

</details>

### 資料：Nora v.0.1関連ファイル

Nora v.0.1関連ファイルは、  
[コミット：718199fba41e841ba6e2f60da43260c8e984e9b2](https://github.com/jpskenn/Nora/tree/718199fba41e841ba6e2f60da43260c8e984e9b2)の内容を、  
[Nora v01_PCBタグ](https://github.com/jpskenn/Nora/releases/tag/v01_PCB)にまとめてあります。

### 資料：Raspberry Pi PICOによる動作（実験的機能）

DIYの実験的機能として、Raspberry Pi PICO（以下、PICOと呼びます）を使用して、キーボードを動作させることができます。

<details>
<summary>《詳しい説明》</summary>

#### PICOを使用してできること

- キーマトリクスの駆動
- LEDの点灯
- I2C接続されたEEPROMとの通信
- その他のI2C接続された機器との通信（オプション）
- 未割り当てのGPIOピンの使用（オプション）

#### 使用時の注意

- GH60型，Poker型ケースには、（たぶん）取り付けできません。
  取り付けられたとしても、ケーブルの取り回しを工夫する必要があります。

- ボトムプレートにも、そのままでは取り付けできません。
  PICOやケーブルに干渉する部分を切り取れば、取付可能です。

- 基板のジャンパを変更して使用します。
  [PICO使用時の設定](#PICO使用時の設定)を参照。

#### 接続図

KiCadの回路図を参照。

#### 取り付け

コンスルーを使用する場合、20ピンで、高さ2mm以上のものが使用できます。

基板とスイッチプレートの感覚が1mmしかないため、コンスルーが奥まで刺さり切らない場合があります。  

#### PICO使用時の設定

必要に応じて基板裏側のジャンパを設定してください。

- `JP3:LED +5 source`：LEDの電源供給元

| ジャンパ設定 | LEDの電源供給元 | 備考 |
| :-: | :-- | :-- |
| PICO VBUS | PICOのVBUS ||
| Onboard | 基板に接続したUSBのVCC | オンボードのMCU、ATmega32u4使用時のデフォルト設定|
| オープン | 接続なし ||

- `JP1`,`JP2`：I2Cプルアップ抵抗（4.7KΩ）への接続

| ジャンパ設定 | I2Cプルアップ抵抗への接続 | 備考 |
| :-: | :-- | :-- |
| ブリッジ | プルアップ抵抗へ接続 | オンボードのMCU、ATmega32u4使用時のデフォルト設定|
| オープン | 接続なし ||

#### ファームウェア

- [PRK Firmware](https://github.com/picoruby/prk_firmware)

  以下の基本的な動作を確認済みです。

  - 全キーの入力
  - LED点灯

  動作確認に使用したファームウェアはこちら：[keymap.rb](../Firmware/prk_nora/)

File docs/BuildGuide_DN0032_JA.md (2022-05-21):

# Nora, Fearless Wings v.1(DN0032) ビルドガイド

購入していただいた方、リポジトリから製造していただいた方、その他の皆様、Noraに興味を持っていただきありがとうございます。

このドキュメントは、”Nora, Fearless Wings”を組み立てるためのビルドガイドです。  
`Fullレイアウト`，`FWレイアウト`， `REレイアウト`の、三つのレイアウトの組み立て方法について説明します。  
参考： [Keyboard Layout Editor: Nora, Fearless Wings family](http://www.keyboard-layout-editor.com/#/gists/568990362f215776aa93e3b90064f241)

- `Fullレイアウト`

  すべてのキーを配置したレイアウト。  
  65%キーボード相当のキー数。

  [Fullレイアウト](../assets/BuildGuide_DN0032/DSC_7625.jpeg)

- `FWレイアウト`

  Fullレイアウトからホームポジション以外のキーを取り除き、中央部分に隙間のあるレイアウト。  
  60%キーボード相当のキー数。

  [FWレイアウト](../assets/BuildGuide_DN0032/DSC_7641.jpeg)

- `REレイアウト`

  FWレイアウトの中央にロータリーエンコーダを配置したレイアウト。

  [REレイアウト](../assets/BuildGuide_DN0032/DSC_7675.jpeg)

Noraのコンセプトや特徴、ビルド例などについては、[README](https://github.com/jpskenn/Nora/blob/main/README.md)をご覧ください。

ビルドガイド全体に目を通して作業手順を把握しておくとミスの防止につながりますので、ぜひ、一度お読みになってから組み立て作業を始めてください。

作業手順をしっかりと確認しながら組み立てたい方は、

<details>
<summary>《《《 詳しい説明 》》》</summary>

ここに追加の説明を表示します。
</details>

と書かれたところをクリックすると、追加の説明が表示されます。

---

<!-- @import "[TOC]" {cmd="toc" depthFrom=2 depthTo=3 orderedList=false} -->

<!-- code_chunk_output -->

- [Nora, Fearless Wings の特徴, 機能](#nora-fearless-wings-の特徴-機能)
- [注意事項、制限など](#注意事項-制限など)
- [部品リスト](#部品リスト)
  - [キット内容](#キット内容)
  - [別途用意が必要な部品](#別途用意が必要な部品)
  - [オプション部品](#オプション部品)
- [組み立てに必要な工具](#組み立てに必要な工具)
- [組み立て前の確認](#組み立て前の確認)
  - [同梱物の確認](#同梱物の確認)
  - [接続の確認](#接続の確認)
  - [ソケット用パッドの確認](#ソケット用パッドの確認)
- [組み立て手順](#組み立て手順)
  - [（オプション）基板、スイッチプレート、ボトムプレートの側面を塗る](#オプション基板-スイッチプレート-ボトムプレートの側面を塗る)
  - [（オプション）LEDを取り付ける](#オプションledを取り付ける)
  - [Kailh Choc用ソケットを取り付ける](#kailh-choc用ソケットを取り付ける)
  - [（該当者のみ）ロータリーエンコーダを取り付ける](#該当者のみロータリーエンコーダを取り付ける)
  - [スイッチプレートにスペーサーシートを貼り付ける](#スイッチプレートにスペーサーシートを貼り付ける)
  - [スイッチとスイッチプレートを基板へ取り付ける](#スイッチとスイッチプレートを基板へ取り付ける)
  - [スイッチの動作確認をおこなう](#スイッチの動作確認をおこなう)
  - [基板をケース、またはボトムプレートへ取り付ける](#基板をケース-またはボトムプレートへ取り付ける)
  - [スイッチの最終動作確認をおこなう](#スイッチの最終動作確認をおこなう)
  - [仕上げ](#仕上げ)
- [参考](#参考)
  - [打鍵感向上：ケース内部の制振と静音化](#打鍵感向上ケース内部の制振と静音化)
  - [トラブル対応：正常に入力できないスイッチの原因調査](#トラブル対応正常に入力できないスイッチの原因調査)
  - [トラブル対応：LEDの取り付け不良調査](#トラブル対応ledの取り付け不良調査)
  - [資料：キーキャップ選び方ガイド](#資料キーキャップ選び方ガイド)
  - [資料：初期ファームウェアの機能と設定値](#資料初期ファームウェアの機能と設定値)
  - [資料：ファームウェアの書き込み方法](#資料ファームウェアの書き込み方法)
  - [資料：EEPROMを消去して、初期状態に戻す方法](#資料eepromを消去して-初期状態に戻す方法)
  - [資料：Nora, Fearless Wings 関連ファイル](#資料nora-fearless-wings-関連ファイル)
  - [資料：レイアウトを変更する方法](#資料レイアウトを変更する方法)
  - [資料：Raspberry Pi PICOによる動作（実験的機能）](#資料raspberry-pi-picoによる動作実験的機能)
  - [サービスマニュアル](#サービスマニュアル)

<!-- /code_chunk_output -->

---

## Nora, Fearless Wings の特徴, 機能

- 狭ピッチ
- 左右対称のキーレイアウト
- QMKファームウェアによる動作
- RemapやVIAなどのキーマップ書き換えツールに対応
- EEPROM搭載で、多くのレイヤーを使用できる
- ボトムプレート以外にも、GH60型，Poker型のロープロファイルケースに取り付けできる
- キーバックライトLED（オプション）
- Raspberry Pi PICOによる動作（実験的機能）

## 注意事項、制限など

- 使用できるキーキャップ

  Choc V1用として販売されているキーキャップのうち、Choc用のキーピッチ（17 × 18mm）に対応したキーキャップを取り付けることができます。  

  Choc V1用として販売されているキーキャップでも、サイズが大きく取り付けできないものがあるため、詳しくは以下の資料をご覧ください。  
  →[資料：キーキャップ選び方ガイド](#資料キーキャップ選び方ガイド)

- スイッチの取り付け

  最下行の親指部分、左右のスペースキーとして使用するスイッチ（2個）は、上下逆向きに取り付けます。  
  （キーキャップは、通常の方向に問題なく取り付けることができます。）  

  LEDも上下逆向きとなるため、レジェンド付き透過タイプのキーキャップでは文字部分が暗くなります。

- ソケットの取り付け

  1行目と4行目の左端のソケット2個は、ソケットの端子部分が基板から約0.5mmはみ出した状態で取り付けます。
  GH60型，Poker型のロープロファイルケースへの取り付けなども含め、実用上の問題がないことを確認済みです。  

  はみ出したソケット端子  
  はみ出したソケット端子

- GH60型，Poker型のロープロファイルケースへの取り付け

  ケース内部の構造などによっては、取り付けが難しかったり取り付けできない場合があるかもしれません。  
  取り付け確認済みケースを参考に、ご自身の判断で取り付けを行なってください。

  ここに記載していないケースへの取り付けの成功／失敗の報告を、随時募集しています。

  取り付け確認済みのケースは次の通りです。  
  - [KBDfans 60% ALUMINUM LOW PROFILE CASE](https://kbdfans.com/collections/60-layout-case/products/customized-gh60-aluminum-case)

  ”TOFU”などのハイプロファイルタイプのケースにも取り付けできますが、キーキャップの天面がケースのフレームよりも低くなって実用に向かないため、ハイプロファイルタイプのケースは取り付けの対象外としています。  
  参考：[TOFUケースへの装着例](https://twitter.com/jpskenn/status/1466729696713142277)

- スイッチの加工

  `Fullレイアウト`または`FWレイアウト`をGH60型，Poker型ケースへ取り付ける場合は、ケース中央のネジ穴に重なるスイッチの足を加工（切断）して取り付けます。

## 部品リスト

このキットを組み立てるためには、[キット内容](#キット内容)に加え、[別途用意が必要な部品](#別途用意が必要な部品)が必要です。  
好みに合わせて、必要な数をお買い求めください。

[オプション部品](#オプション部品)は、使いたい機能などに応じて用意してください。  

部品の購入先は、[Self-Made Keyboards in Japan：ショップリスト](https://scrapbox.io/self-made-kbds-ja/ショップリスト)などを参考にしてください。

### キット内容

| 部品名 | 個数 | 備考 |
| :-- | :-- | :-- |
| ご案内リーフレット | 1 | |
| 基板（＝PCB） | 1 | [おもて側<br>基板おもて側](../assets/BuildGuide_DN0032/DSC_7493.jpeg)<br>[裏側<br>基板裏側](../assets/BuildGuide_DN0032/DSC_7491.jpeg) |
| スイッチプレート<br>`Fullレイアウト`, `FWレイアウト`, `REレイアウト`のいずれか | 1 | `Fullレイアウト`<br>[おもて側<br>スイッチプレートおもて側](../assets/BuildGuide_DN0032/DSC_7500.jpeg)<br>[裏側<br>スイッチプレート裏側](../assets/BuildGuide_DN0032/DSC_7504.jpeg)<br>`FWレイアウト`<br>[おもて側<br>スイッチプレートおもて側](../assets/BuildGuide_DN0032/DSC_7497.jpeg)<br>[裏側<br>スイッチプレート裏側](../assets/BuildGuide_DN0032/DSC_7498.jpeg)<br>`REレイアウト`<br>[おもて側<br>スイッチプレートおもて側](../assets/BuildGuide_DN0032/DSC_7711.jpeg)<br>[裏側<br>スイッチプレート裏側](../assets/BuildGuide_DN0032/DSC_7718.jpeg) |
| ボトムプレート | 1 | [おもて側<br>ボトムプレートおもて側](../assets/BuildGuide_DN0032/DSC_7505.jpeg)<br>[裏側<br>ボトムプレート裏側](../assets/BuildGuide_DN0032/DSC_7514.jpeg) |
| スペーサーシート<br> シール付き, 1mm厚, 10mm * 500mm<br>[低弾性ゴムシート－ハネナイトＲ－ (UNLEA1-10)](https://jp.misumi-ec.com/vona2/detail/110300277050/?HissuCode=UNLEA1-10) | 1 | [](../assets/BuildGuide_DN0032/DSC_7568.jpeg) <br>（長い方） |
| スペーサーシート<br> シール付き, 1mm厚, 10mm * 約150mm <br>[低弾性ゴムシート－ハネナイトＲ－ (UNLEA1-10)](https://jp.misumi-ec.com/vona2/detail/110300277050/?HissuCode=UNLEA1-10) | 1 | [](../assets/BuildGuide_DN0032/DSC_7568.jpeg)<br>（短い方） |
| ネジ, M2 3mm, 低頭<br>[低頭精密小ねじ(ラミクス)](https://wilco.jp/products/F/FX-EB.html) | 16 | [](../assets/BuildGuide_DN0032/IMG_4124.jpeg) |
| ネジ, M2 4mm, 低頭<br>[低頭精密小ねじ(ラミクス)](https://wilco.jp/products/F/FX-EB.html) | 4 | [](../assets/BuildGuide_DN0032/IMG_4125.jpeg) |
| スペーサー, M2 3mm<br>[黄銅スペーサー（Ni）ASB-2003E](https://www.hirosugi-net.co.jp/shop/g/g57/) | 8 | [](../assets/BuildGuide_DN0032/IMG_4123.jpeg) |
| ゴム足 小<br>[しっかりつくクッションゴム CS-102, 透明, 8 φ x 2 mm](https://www.3mcompany.jp/3M/ja_JP/p/d/v000453068/) | 6 | [](../assets/BuildGuide_DN0032/DSC_7764.jpeg)<br>（左） |
| ゴム足 大<br>[KKU-190 [ウレタンクッション19丸 透明]](https://www.yodobashi.com/product/100000001001980663/) | 2 | [](../assets/BuildGuide_DN0032/DSC_7764.jpeg)<br>（右） |

※出荷時期によって、基板やプレート類の仕様や、部品のメーカーや品番などを変更することがあります。

### 別途用意が必要な部品

| 部品名 | 個数 | 備考 |
| :-- | :-- | :-- |
| ソケット<br>Kailh Chocロープロファイル用 | `Fullレイアウト`：71個<br>`FWレイアウト`：64個<br>`REレイアウト`：62個 | [](../assets/BuildGuide_DN0032/DSC_7770.jpeg) |
| スイッチ<br>Kailh Choc V1 | `Fullレイアウト`：71個<br>`FWレイアウト`：64個<br>`REレイアウト`：62個 | 3ピン・5ピン、どちらも使用可能<br>[](../assets/BuildGuide_DN0032/DSC_7736.jpeg) <br>左：5ピン，右：3ピン|
| キーキャップ<br>Choc用 | `Fullレイアウト`：<br>1u × 62個<br>1.5u × 9個<br>`FWレイアウト`：<br>1u × 56個<br>1.5u × 8個<br>`REレイアウト`：<br>1u × 54個<br>1.5u × 8個　| 詳しくはこちらを参照<br>→[資料：キーキャップ選び方ガイド](#資料キーキャップ選び方ガイド) |
| USBケーブル （Type-C） | 1 | |
| ロータリーエンコーダ<br>ALPS EC11, EC12または同等品 | 1 | `REレイアウト`を組み立てる場合のみ必要<br>[](../assets/BuildGuide_DN0032/DSC_7749.jpeg) |
| ロータリーエンコーダ用ノブ<br>（つまみ） | 1 | `REレイアウト`を組み立てる場合のみ必要<br>最大径35mm（キーキャップのサイズによる）<br>[](../assets/BuildGuide_DN0032/DSC_7751.jpeg) |

### オプション部品

| 部品名 | 個数 | 備考 |
| :-- | :-- | :-- |
| LED<br>SK6812MINI-E | `Fullレイアウト`：71個<br>`FWレイアウト`：64個<br>`REレイアウト`：62個　| LEDを取り付ける場合<br>[](../assets/BuildGuide_DN0032/DSC_7753.jpeg) |
| GH60型，Poker型<br>ロープロファイルケース | 1 | ケースへ取り付ける場合<br>[](../assets/BuildGuide_DN0032/DSC_7763.jpeg) |
| Raspberry Pi PICO | 1 | 実験的機能をDIYで楽しむ場合<br>ピンヘッダ または コンスルーなどで取り付け |

## 組み立てに必要な工具

- 先の細いドライバー（M2ネジに対応するもの）
- ピンセット
- はんだ付け関連用品
- はさみ

フラックスやハンダ吸い取り線を用意しておくと、ちょっとした修正などがやりやすくなります。  
[遊舎工房の工具セット](https://yushakobo.jp/shop/a9900to/)を参考に用意してください。

なお、無くても組み立てはできますが、何か不具合があった場合の原因調査ではテスターがあると便利です。

## 組み立て前の確認

組み立てを開始する前に、同梱物と基板についての基本的な確認をおこないます。  

**組み立て前の確認で何か問題があった場合は作業を中止し、リーフレットに記載された連絡先へ問い合わせてください。**  
**組み立ての開始後は、初期不良として対応できかねる場合があります。**

### 同梱物の確認

キット内容に記載された部品が、不足なく入っていることを確認します。

### 接続の確認

基板をUSBケーブルでMacやPCに接続して、キーボードとして認識されることを確認します。

*充電用ではないUSBケーブルを使用します。*  
*他の機器を接続して使用した実績のあるケーブルを使うと、無用のトラブルを防げます。*

下記のOS別の確認方法を参考に、確認してください。

<details>
<summary>確認方法：《Mac, macOS Monterey 12.0.1》</summary>

1. 基板とMacをUSBケーブルで接続します。

    接続した際に`キーボード設定アシスタント`が表示された場合は、`終了`ボタンを押して閉じます。

    キーボード設定アシスタント  

    なお、キーボード設定アシスタントは、次の操作でいつでも呼び出すことができます。  
    `システム環境設定`から、`キーボード` → `キーボード`タブ → `キーボードの種類を変更…`ボタンを押す。

1. システム情報を表示します。

    メニューバーの``マークから、`このMacについて`を選び、表示された画面で`システムレポート…`をクリックします。  

1. USBデバイスを表示します。

    `システム情報`画面で、左側の`ハードウェア`から`USB`を選択します。

1. `Nora`が接続されていることを確認します。

    右側上部の`USB装置ツリー`で、`Nora`を探します。  
    どこかに`Nora`と表示されていれば、正しく接続されています。  

    `USB装置ツリー`の下の方が見切れている場合があるため、スクロールして探してください。

    Mac System Report  
    システム情報の表示

</details>

<details>
<summary>確認方法：《Windows, 10 Pro 1909(18363.1082)》</summary>

1. 基板とPCをUSBケーブルで接続します。

1. `デバイス`を表示します。

    `スタートボタン`から`設定`を開いて`デバイス`を選択します。

1. `Nora`が接続されていることを確認します。

    `マウス、キーボード、ペン`の項目に`Nora`が表示されていれば、正しく認識されています。

    Windows Devices  
    デバイスの表示

</details>

### ソケット用パッドの確認

[Remap](https://remap-keys.app/)のテスト機能を使用し、Kailh Chocソケット用のパッド（※）が、電気的に正しく反応することを確認します。  
※ソケットをはんだ付けする、基板上の四角い金色や銀色の部分

<details>
<summary>《《《 詳しい説明 》》》</summary>

キーマップ書き換えツール[Remap](https://remap-keys.app/)のテスト機能を使って確認をおこないます。

1. 基板の裏側が上になるように置きます。

1. 基板をPCやMacとUSBケーブルで接続します。

    USBコネクタ部分に無理な力がかからないように気をつけます。

1. Google Chromeブラウザで、[Remap](https://remap-keys.app/)のページを開きます。

    Chromeブラウザは、Web HID対応のバージョン89以降を使用します。

1. `START REMAP FOR YOUR KEYBOARD`をクリックして始めます。

    START REMAP FOR YOUR KEYBOARD

1. `+ KEYBOARD`をクリックして、キーボードをRemapに接続する画面を表示します。

    + KEYBOARD

1. デバイスへの接続要求画面で`Nora`を選択し、`接続`をクリックしてキーボードをRemapに接続します。

    デバイスへの接続要求

1. 右側のアイコンから`Layout Option`をクリックし、使用するレイアウトを選択します。

    初回の接続時は`Fullレイアウト`が選択されています。  
    例として、`FWレイアウト`を選択したとして以降の手順を説明します。

    Test Matrix Mode

1. 右側のアイコンから`…`をクリックし、`Test Matrix mode`を選択します。

    … menu

1. ピンセットなどの電気を通すものを使い、基板裏側のソケット用パッドをショートさせます。

    ピンセットを使ってショートさせる様子  
    ピンセットを使ってショートさせる様子

1. Remapの画面で、ショートさせた箇所に対応するキーの色が変わることを確認します。

    *基板が裏側になっているので、画面ではキーの位置が左右反対になります。*

    Test Matrix mode
    ショートさせる前

    キーの色が変わる
    ショートさせた後（キーの色が変わる）

    :exclamation:  
    パッドをショートしても反応がない場合は、基板に実装された部品が外れたり、配線がダメージを受けている可能性があります。  
    この確認作業をすべてのパッドでおこなった後、どこが反応しなかったかわかるようにスクリーンショットなどを残してください。  
    撮影したスクリーンショットと合わせて、リーフレットに記載された連絡先へ問い合わせてください。

1. 同様の作業を繰り返し、全てのキーの色が変わることを確認します。

    なお、`REレイアウト`でロータリーエンコーダの回転に割り当てた箇所は、この手順では確認しません。  
    ロータリーエンコーダを取り付けた後に確認します。

    RE assigned keys

1. 確認が終わったら、USBケーブルを抜きます。

</details>

## 組み立て手順

以降の手順に沿って組み立てます。  
`（オプション）`と書かれた項目は、不要であれば作業をとばしてもかまいせん。  
`（該当者のみ）`と書かれた項目は、条件に該当する場合のみ作業をおこないます。

怪我などに気をつけて作業してください。  

### （オプション）基板、スイッチプレート、ボトムプレートの側面を塗る

*少し塗りにくくなりますが、組み立て後におこなうこともできます。*

ボトムプレートに取り付けて使用する際の見栄えを良くするため、基板、スイッチプレート、ボトムプレートの側面を塗ります。

はみ出さないように気をつけて、水性顔料や油性のマーカーなどを使って好きな色に塗ります。

基板側面を塗る様子  
基板側面を塗る様子

### （オプション）LEDを取り付ける

レイアウトに応じて、基板裏側のLED配線経路をジャンパします。  
スイッチを取り付ける位置に合わせて、基板裏側からLEDを取り付けます。  

| レイアウト | 配線経路ジャンパ位置 | LEDを取り付ける位置 |
| :-: | :-- | :-- |
| Full | なし | すべて |
| FW | `JP4`<br>`JP5`<br>`JP7`<br>`JP8`<br>`JP9`| 以下の点線で囲まれた箇所を除く<br>`L8` `L9`<br>`L24`<br>`L39`<br>`L54` `L55`<br>`L67` |
| RE | `JP4`<br>`JP5`<br>`JP6`<br>`JP8`<br>`JP9` | 以下の点線または実線で囲まれた箇所を除く<br>`L8` `L9`<br>`L24`<br>`L38` `L39` `L40`<br>`L54` `L55`<br>`L67` |



LEDを取り付けない箇所（左：実線で囲まれた箇所，右：点線で囲まれた箇所）

#### :bulb:ヒント

- **行ごとにLEDを取り付ける方向が異なるため、注意して取り付けます。**

- レイアウトに応じたマークがついているところへ、ジャンパとLEDの取り付けを行います。

<details>
<summary>《《《 詳しい説明 》》》</summary>

#### LEDの配線経路をジャンパする

基板裏側の配線経路ジャンパ`JP4`から`JP9`を、レイアウトに応じてジャンパ（※）します。  
※隣同士のパッド（基板上の小さな四角の金色や銀色の部分）にはんだをつけてつなげること

ジャンパの位置
ジャンパ`JP4`から`JP9`の位置

レイアウトと配線経路に対応するジャンパ位置は次の通りです。  
各ジャンパ位置に描かれたマーキングを参考にします。

| レイアウト | 配線経路ジャンパ位置 | 基板のマーキング |
| :--: | :--: | :--: |
| Full | なし<br>（ジャンパ不要） | なし |
| FW | `JP4`<br>`JP5`<br>`JP7`<br>`JP8`<br>`JP9`| mark:Full |
| RE | `JP4`<br>`JP5`<br>`JP6`<br>`JP8`<br>`JP9` | mark:Full |

1. 基板を裏側が上になるように置きます。

1. はんだごてを用意します。  
  こて先の温度は270〜℃程度にします。  

1. 2個並んだパッドにまたがるように、こて先をあてます。  
  そのまま、3秒ほど温めます。

1. こて先にはんだを押し付けて、少したっぷり目に溶かします。

1. こて先で基板をなでるように、横へスッとずらしてパッドから離します。  
  2個のパッドが、はんだでつながっていれば完了です。  

なかなか上手くジャンパできないのですが、何度かトライすればそのうちできます。  
こて先でパッドをグリグリいじるとパッドが剥がれて大変なことになるため、  
「はんだをたっぷりつけて、横へスッ」  
の動きを守って作業します。

JP9をFWにジャンパした例  
JP9をFWにジャンパした例

#### LEDを取り付ける

基板裏側のLED`L1`から`L71`へ、スイッチを取り付ける位置に合わせてLEDを取り付けます。

レイアウトによって、LEDを取り付ける位置は次の通りです。

| レイアウト | LEDを取り付ける位置 |
| :--: | :--: |
| Full | すべて |
| FW | 以下の点線で囲まれた箇所を除く<br>`L8` `L9`<br>`L24`<br>`L39`<br>`L54` `L55`<br>`L67` |
| RE | 以下の点線または実線で囲まれた箇所を除く<br>`L8` `L9`<br>`L24`<br>`L38` `L39` `L40`<br>`L54` `L55`<br>`L67` |



LEDを取り付けない箇所（左：実線で囲まれた箇所，右：点線で囲まれた箇所）

1. 基板を裏側が上になるように置きます。

1. LEDを1個用意して、LEDの発光部分（透明な窓がある部分）が下側になるように持ちます。

    LEDの取り付け方向  
    LEDの取り付け方向

1. LEDから出ている4本の端子のうち、角が斜めになっている1本が基板に描かれた印に合うようにして、基板の穴にはめこみます。  
    **:exclamation: 注意：行ごとに、LEDを取り付ける方向が異なります。**  

    LEDをはめ込んだ様子  
    LEDをはめ込んだ様子

1. LEDの4本の端子が、基板に接した状態にします。

    4本の端子が基板に接した状態→OK  
    4本の端子が基板に接した状態→OK

    端子が浮いた状態→NG  
    端子が浮いた状態→NG

1. はんだごてを用意します。  
  LEDは高温ではんだ付けすると壊れやすいため、こて先温度を少し低めの220-270℃に設定します。

1. 次の手順を「1、2、3、4、5」と数える間におこないます。  

    - 1、2：  
      4本の端子のどれかひとつにこて先をあてて押さえ、端子とパッドを温めます。  

    - 3、4：  
      はんだを端子（またはパッド）に当てて溶かし、端子とパッドにはんだを行き渡らせて、はんだを離します。  
      こて先はグリグリ動かしません。はんだ溶けて、自然に濡れ広がっていくような具合です。  

    - 5：  
      こて先を離します。
      はんだが、端子とパッド全体に行き渡っていれば良い仕上がりです。  

1. LEDが傾いてしまった場合は、ピンセットでLEDをつまみ、はんだ付けした端子をこて先で温めながら傾きを修正します。  
  端子とパッドがずれたりしていなければ、少しくらい傾いていてもLEDの光り具合に大差はありません。

1. 最初にはんだ付けした端子とLED本体を挟んだ反対側の端子2本を、同様の手順ではんだ付けします。

1. 残った1本の端子をはんだ付けします。  
  これで、LED1個の取り付けが完了です。

    取り付けたLED  
    取り付けたLED

1. 作業を繰り返し、必要な数のLEDを取り付けます。

#### LEDの動作確認をおこなう

LEDの点灯状態を見て、正しく取り付けられているか確認します。

1. PCやMacにUSBケーブルで接続します。

1. すべてのLEDが、赤色に点灯することを確認します。

  点灯しないLEDがあったり、色がおかしかったりする場合は、[トラブル対応：LEDの取り付け不良調査](#トラブル対応LEDの取り付け不良調査)を参考にして調査します。

</details>

  LEDを取り付け、すべて点灯した状態  
  LEDを取り付け、すべて点灯した状態

### Kailh Choc用ソケットを取り付ける

スイッチを取り付ける位置に合わせて、基板裏側へKailh Choc用ソケットを取り付けます。

| レイアウト | ソケットを取り付ける位置 |
| :--: | :-- |
| Full | すべて |
| FW | ソケット外枠だけが描かれ、白く塗られていない箇所へは取り付けない。 |
| RE | ソケット外枠だけが描かれ、白く塗られていない箇所へは取り付けない。<br>格子状に塗られた箇所にも取り付けない。 |



ソケット取り付け指標（白く塗られた箇所）



ソケット取り付け指標（外枠のみ描かれた箇所）



ソケット取り付け指標（格子状に塗られた箇所）

#### :bulb:ヒント

- ソケットには正しい取り付け方向があります。  
  基板に描かれた枠をよく見て、正しい方向に取り付けます。

- 1行目と4行目の左端のソケット2個は、ソケットの端子部分が基板から約0.5mm飛び出した状態で取り付けます。  

  飛び出したソケット端子

- ソケットを取り付けない箇所へ取り付けてしまっても、単に使わないだけで、機能的な問題はありません。

<details>
<summary>《《《 詳しい説明 》》》</summary>

#### ソケット用パッドの片方へ予備はんだする

1個のソケットに対応する2箇所のパッドのうち、どちらか*片方だけ*に予備はんだ（※）します。  
※部品を取り付ける前に、基板のパッドや部品の端子にはんだをつけておくこと。

基板の中央部分は、スイッチを取り付ける位置に合わせて予備はんだします。

1. 基板を裏側が上になるように置きます。

1. はんだごてを用意します。  
  こて先の温度は270〜320℃程度にします。

1. 次の手順を「1、2、3、4、5」と数える間におこないます。

    - 1、2：  
      予備はんだするパッドにこて先をあてて、温めます。

    - 3：  
      こて先にはんだをあてて溶かします。

    - 4：  
      溶けたはんだがパッド全体に広がったら、はんだを離します。

    - 5：  
      こて先をパッドから離します。

    ソケットの取り付け方向と、予備はんだした状態  
    ソケットの取り付け方向と、予備はんだした状態

#### ソケットの仮置き

ソケットを基板に描かれた枠に合わせ、プラスチックの突起が穴にはまるように仮置きします。  
ソケットを取り付ける方向に決まりがあるので、正しい方向になっているかよく確認します。

1. 基板を裏側が上になるように置きます。

1. ソケットを1個用意し、方向を確認します。

1. 予備はんだしておいた箇所へ、基板の穴に合わせてソケットを置きます。  
    この段階では、ソケットの片方の端子が予備はんだの上に乗り、基板から少し浮いて傾いた状態になります。

    基板の製造ロットによっては、基板の穴が小さい（狭い）ことがあります。
    その場合は、プラスチックの突起を穴に合わせて、ソケットを指で押し込むようにしてはめ込みます。

#### 予備はんだした端子をはんだ付けする

予備はんだしてある方の端子を、はんだ付けします。

1. はんだごてを用意します。  
  こて先の温度は270〜320℃程度にします。

1. 利き手にはんだごて、もう一方の手にピンセットを持ちます。

1. ピンセットでソケット中央のプラ部分を押さえて動かないようにします。

1. 端子の隙間にこて先を差し込みます。

    端子の隙間に、こて先を差し込んだ様子  
    端子の隙間に、こて先を差し込んだ様子

1. 次の手順を「1、2、3、4、5、6」と数える間におこないます。

    - 1、2：  
      予備はんだが溶け始めます。  
      ピンセットで押さえていたソケットを軽く押し込むと、ソケットのプラスチックの突起が基板の穴にはまり、浮いていた端子が基板に接します。  

    - 3：  
      こて先をあてたまま、加熱を続けます。  

    - 4：  
      こて先を離します。  

    - 5：  
      ピンセットでソケットを押さえ続けます。  

    - 6：  
      はんだが冷えて固まるのを待ってから、ピンセットを離します。

1. ソケットが基板に描かれた枠に沿ってまっすぐに取り付けられ、傾いていないことを確認します。
  傾いている場合は端子部分を再度加熱し、こて先とピンセットで傾きを修正します。

#### 残りの端子のはんだ付け

残りのもう一方の端子をはんだ付けします。

1. はんだごてを用意します。  
  こて先の温度は270〜320℃程度にします。

1. 残りの端子の隙間にこて先を差し込みます。

1. 次の手順を「1、2、3、4、5、6」と数える間におこないます。

    - 1、2：  
      こて先を差し込んだまま、端子とパッドを加熱します。  

    - 3：  
      パッドと端子の隙間あたりへ、はんだを押し付けて溶かします。  

    - 4：  
      はんだを溶かしながら、端子とパッドの隙間へ流し込みます。  

    - 5：  
      溶けたはんだがパッド全体に広がる程度まで流し込んだら、はんだを離します。  

    - 6：  
      ソケットを動かしてしまわないよう、静かにこて先を離します。

1. はんだ付けした状態を確認します。  
    はんだがパッド全体に広がり、端子の間にポコっと盛り上がって固まっているのが良好な状態です。  

    はんだのパッドへの広がりが足りない場合は、再加熱して、はんだを少し足して塗り広げます。

    ソケットをはんだ付けした状態  
    ソケットをはんだ付けした状態

1. ソケットが枠に沿ってまっすぐに取り付けられていることを確認します。  
    また、ソケットが基板から浮いていないことも確認します。  

    傾いたり浮いたりしている場合は、端子部分を再加熱し、こて先とピンセットで修正します。

    Kailh製のロープロファイルキーキャップを使用する場合は、
    隣同士のキーが当たるのを防ぐため、より一層、ソケットの傾きに注意して取り付けます。

    まっすぐに取り付けられたソケット→OK  
    まっすぐに取り付けられたソケット→OK

    浮いた状態のソケット  
    浮いた状態のソケット→NG

#### すべてのソケットの取り付け

1. 作業を繰り返して、すべてのソケットを取り付けます。

1. 取り付けが終わったら、**はんだ付けし忘れた箇所がないか、十分確認します**。

</details>

Fullレイアウトに、すべて取り付けたソケット  
`Fullレイアウト`に、すべて取り付けたソケット

### （該当者のみ）ロータリーエンコーダを取り付ける

*`REレイアウト`を組み立てる場合のみ、この手順を行います。*

基板おもて側の中央へ、ロータリーエンコーダを取り付けます。

#### :bulb:ヒント

- ロータリーエンコーダの端子や取り付け足が基板裏側から3mm以上飛び出す場合は、3mm以内にカットしてボトムプレートに当たらないようにします。  
  なお、日本国内のキーボード関連ショップで販売されているロータリーエンコーダは3mm以内に収まるものがほとんであり、あまり気にしなくても大丈夫です。  

- ノブ（つまみ）は、スイッチプレートを基板に取り付けた後に取り付けます。

<details>
<summary>《《《 詳しい説明 》》》</summary>

#### ロータリーエンコーダの取り付け

1. 基板をおもて側が上になるように置きます。

1. ロータリーエンコーダのピン（下3本、または上2本と下3本）と、左右の固定足を、基板の取り付け位置に合わせて差し込みます。  
  ピンを曲げないように注意します。

    <!-- 〓DN0032写真：RE仮取付 -->

1. ロータリーエンコーダのピンが正しく差し込まれ、傾いていないことを確認します。

1. ロータリーエンコーダが傾かないように注意しながら、基板の裏側が上になるように置き直します。

1. はんだごてを用意します。  
  こて先の温度は270〜320℃程度にします。

1. 次の手順を「1、2、3、4、5、6」と数える間におこないます。

    - 1、2：  
      いずれかのピンにこて先をあてて、温めます。  

      ```aside
      ロータリーエンコーダ左右の固定足は、はんだ付けしません。
      ```

    - 3：  
      こて先にはんだをあてて溶かします。

    - 4：  
      ピンと穴にはんだが流れ込んだら、はんだを離します。

    - 5：  
      こて先を当てたままにします。

    - 6：  
      こて先を離します。

1. はんだ付けした状態を確認します。  
    ピンに沿って、はんだが富士山型に盛り上がっていれば良い状態です。  
    ピンと穴の間に隙間が空いている場合は、再加熱してはんだを足します。

    ロータリーエンコーダが基板にぴったりとくっついて取り付けられていることを確認します。  
    隙間が空いていたり、傾いている場合は、はんだ付けをやり直します。

    <!-- 〓DN0032写真：REはんだ -->

1. ロータリーエンコーダが基板から浮かないように気をつけながら、残りのピンをはんだ付けします。

<!-- 〓DN0032写真：RE取り付け完了 -->

#### ロータリーエンコーダの動作確認

1. PCやMacにUSBケーブルで接続します。

1. ロータリーエンコーダのつまみを左右に回して、OSの音声出力ボリュームが変化することを確認します。  

1. ロータリーエンコーダのプッシュボタンスイッチを押して、OSの音声出力がミュート／ミュート解除されることを確認します。  

何か問題があった場合は、正しくはんだ付けされているかを確認します。

</details>

### スイッチプレートにスペーサーシートを貼り付ける

基板とスイッチプレートの隙間を埋めるため、スペーサーシートをはさみなどで切り離し、スイッチプレート裏側へ貼り付けます。  

#### :bulb:ヒント

- シートを縦半分や縦1/3に切るのが少し難しいため、最初は練習のつもりで、短い長さの箇所から始めましょう。  
  切るのに慣れてコツをつかんでから、長いものを切るとよいでしょう。

- 白い線で描かれた貼り付け位置が埋まる程度に貼り付けてあれば、シートが多少余っていても問題ありません。  
  余ったシートは空いている箇所に追加で貼り付けたり、ボトムプレートへ貼り付けて基板の振動を低減したりするのもよいでしょう。  
  →[打鍵感向上：ケース内部の制振と静音化](#打鍵感向上ケース内部の制振と静音化)

<details>
<summary>《《《 詳しい説明 》》》</summary>

#### スペーサーシートの貼り付け

1. スイッチプレートを、裏側が上になるように置きます。

1. スイッチプレート裏側に白い線で描かれた貼り付け位置へ、スペーサーシートを貼り付けます。

    シートをはさみなどで切り離し、以下の優先順に貼り付けます。  

    1. 幅が広い箇所  
        シート幅そのままの、10mm幅を貼り付けます。

    1. 幅が中くらいの箇所  
        シートを縦半分に切り、5mm幅を貼り付けます。  
        `USB`と書かれた箇所を避けて貼り付けます。
        Raspberry Pi PICOを使用する場合は、`PICO reserved area`と書かれた箇所を避けて貼り付けます。

    1. 幅が狭い箇所  
        シートを縦1/3に切り、約3mm幅を貼り付けます。

    シートが余った場合は、空いている箇所へバランスよく貼り付けます。

    シートを切り取る  
    シートを貼り付ける長さに合わせて切り取る

    シートを縦半分に切る  
    シートを縦半分に切る

    縦半分に切ったシートを貼り付ける  
    縦半分に切ったシートを貼り付ける

</details>

スペーサーシートを貼り付けた状態
`Fullレイアウト`のスイッチプレートへ、スペーサーシートを貼り付けたようす

### スイッチとスイッチプレートを基板へ取り付ける

スイッチプレートをはさむようにして、スイッチを基板に取り付けます。  

#### :bulb:ヒント

- :exclamation: 最下行の親指部分、左右のスペースキーとして使用するスイッチ（2個）は、**上下逆向き**に取り付けます。  
  LEDが眩しく感じる場合は、スイッチのLED窓内側へマスキングテープなどを貼ったり、黒マジックで塗ったりして減光します。

- スイッチのスイッチプレートへのはめ込み具合が、きつい・ゆるいスイッチがあります。  
  Choc 赤、茶は、きつめかもしれません。  
  Red Crystalは少し緩めです。

- 基板おもて側にネジのアイコンが描かれたスイッチは、この手順では取り付けません。  
  ボトムプレート、またはケースにねじ止めした後に取り付けます。

<details>
<summary>《《《 詳しい説明 》》》</summary>

#### スイッチプレートを仮固定する

スイッチプレートのおもて側から、1・3・5行目の左右の端へ6個のスイッチをはめ込み、スイッチの端子を基板のソケットへはめ込んで仮固定します。

1. スイッチを6個用意します。  
  端子が折れたものは使用できません。曲がっているものは、まっすぐにしておきます。

1. スイッチプレートをおもて側が上になるように置きます。

1. プレートのおもて側から、1・3・5行目の左右の端6箇所に、スイッチをパチンとはめ込みます。  
    スイッチをソケットの方向に合わせるため、スイッチの端子が手前側になるようにします。

    スイッチによってはめ込み具合に差がありますが、少しゆるめの固定でも問題ありません。

    スイッチプレートに取り付けたスイッチ  
    スイッチプレートに取り付けたスイッチ

1. 基板をおもて側が上になるようにして、プレートの隣に置きます。

1. スイッチ6個を取り付けたプレートを、スイッチ端子と基板のソケットの位置が合うようにして、基板に乗せて重ねます。  

1. プレートと基板がずれないように持ち上げます。

1. 基板の裏側からソケットを押さえながら、どれかひとつのスイッチをまっすぐに押し込んでソケットへ差し込みます。  

    スイッチをソケットに差し込む  
    基板の裏側からソケットを押さえながら、スイッチを差し込む

1. スイッチがしっかりと差し込まれ、基板にほぼくっついた状態になっていることを確認します。  
    5ピンのスイッチを取り付ける場合は固定用のプラスチックピン2本が根元まで刺さりきっていない場合があるため、よく確認しておきます。

1. 同様の手順で、残り5個のスイッチをソケットへ差し込みます。

    基板に仮固定されたスイッチプレート  
    基板に仮固定されたスイッチプレート

#### 残りのスイッチを取り付ける

ケースネジに重なるスイッチを除いて、残りのスイッチをすべて取り付けます。

1. スイッチを用意します。  
    端子が折れたものは使用できません。曲がっているものは、まっすぐにしておきます。

1. プレートにスイッチをはめ込みつつ、そのまま基板のソケットへスイッチ端子を差し込んで、スイッチを取り付けます。
    スイッチを斜めに押し込むと端子が曲がりやすいため、プレート面に対してまっすぐ押し込むようにします。

    最下行の親指部分、左右のスペースキーとして使用するキーは、上下逆向きに取り付けます。

1. ケースネジに重なるスイッチ（基板にネジのアイコンが描かれた箇所）を除き、残りのスイッチをすべて取り付けます。

    基板に描かれたネジアイコン
    基板に描かれたネジアイコン

</details>

基板に取り付けられたスイッチとスイッチプレート  
基板に取り付けられたスイッチとスイッチプレート  
（ネジ穴に重なる箇所のスイッチは、まだ取り付けない）

### スイッチの動作確認をおこなう

組み立て前におこなった[ソケット用パッドの確認](#ソケット用パッドの確認)と同様の手順で、ソケットに取り付けたスイッチが正しく動作するか確認します。  
この手順では、取り付けたスイッチを押して確認します。

正常に入力できないスイッチがあった場合は、[トラブル対応：正常に入力できないスイッチの原因調査](#トラブル対応正常に入力できないスイッチの原因調査)の手順に沿って調査します。

### 基板をケース、またはボトムプレートへ取り付ける

スイッチとプレートが組み合わされた基板を、ボトムプレート、またはGH60型, Poker型ロープロファイルケースへ取り付けます。

打鍵感向上に興味のある方は、次の項目をお読みになると何かヒントがあるかもしれません。

- [打鍵感向上：ケース内部の制振と静音化](打鍵感向上：ケース内部の制振と静音化)

#### （該当者のみ）基板をボトムプレートへ取り付ける

*ボトムプレートを使用する場合のみ、この手順をおこないます。*

ネジとスペーサーを使い、ボトムプレートに基板を取り付けます。

:exclamation: 最下行の親指部分、左右のスペースキーとして使用するスイッチ（2個）は、**上下逆向き**に取り付けます。

<details>
<summary>《《《 詳しい説明 》》》</summary>

1. 以下の写真に示す○印をつけた8箇所に、ボトムプレート裏側からネジ（M2 3mm 低頭）を差し込み、ボトムプレートおもて側へスペーサー（M2 3mm）をねじ止めします。  

    ◎印をつけた右上と中央下の2箇所は、スイッチとの干渉を減らすため、スペーサーを右側へ寄せてねじ止めします。  

    スペーサー取り付け箇所  
    スペーサー取り付け箇所

    ボトムプレートへねじ止めしたスペーサー  
    ボトムプレートへねじ止めしたスペーサー（ひとつは右側へ寄せてねじ止めしている）

1. ボトムプレートをおもて側が上になるように置きます。

    ボトムプレートを置いた状態  
    ボトムプレートを置いた状態

1. 基板を、ボトムプレートに取り付けたスペーサーの位置に合わせて乗せます。  
  基板裏側の部品がスペーサーにぶつからないように注意します。

1. （該当者のみ）ロータリーエンコーダの端子や取り付け足が長すぎて、ボトムプレートと干渉していないことを確認します。

    *`REレイアウト`を組み立てる場合のみ、この確認を行います。*

    干渉している場合、基板裏側からの飛び出しが3mm以下になるように、曲げたり、ニッパーなどで切断したりします。

1. 基板おもて側から、ネジ（M2 3mm 低頭）を使い、基板とスペーサーをねじ止めします。  

    基板とボトムプレートをねじ止めした状態  
    基板とボトムプレートをねじ止めした状態

1. まだ取り付けていないスイッチを、すべて取り付けます。

1. ボトムプレート底面に、滑り止めのゴム足を貼り付けます。

</details>

基板をボトムプレートを取り付けた状態  
基板をボトムプレートを取り付けた状態

#### （該当者のみ）GH60型, Poker型ケースへ取り付ける

*GH60型, Poker型ケースを使用する場合のみ、この手順をおこないます。*

ケースに基板をねじ止めして取り付けます。

:exclamation: 最下行の親指部分、左右のスペースキーとして使用するスイッチ（2個）は、**上下逆向き**に取り付けます。

<details>
<summary>《《《 詳しい説明 》》》</summary>

1. ケース付属のネジ止め式の足を使用する場合は、最初に取り付けておきます。

1. ケースを安定したところへ置きます。

1. スイッチとスイッチプレートが組み合わされた基板を手に持ちます。

1. 基板を水平から30度くらいの角度に持ち、奥側から斜めにケース内へ入れていきます。  
  斜めに差し込んでいくと、USBコネクタがケースの穴にスッとはまります。

    基板を30度で差し込む様子  
    基板を30度で差し込む様子

1. USBコネクタがはまった状態で基板の手前側を静かに下ろして水平にします。  
    力をかけることなく、基板全体がストンとケースに入ります。  
    力を入れてグリグリとこじったりググググッと押し込むようなことはせず、斜めに差し込んで、水平にするだけです。

1. ケース付属のネジで、左上と右上の2箇所を仮固定します。

1. キット同梱のネジ（M2 4mm 低頭）で、左端、右端、中央、中央下の4箇所を仮固定します。

1. ケースに対して、基板の位置が上下左右の真ん中になるように調整します。

1. ネジが軽く止まる程度まで締めて基板を固定します。

1. （該当者のみ）ケース中央のネジ穴に重なるスイッチを、足を加工して取り付けます。  

    *`Fullレイアウト`または`FWレイアウト`を組み立てる場合のみ、この作業を行います。*

    3ピンのスイッチは、加工不要で、そのまま取り付けできます。  
    5ピンのスイッチを使用する場合は、左右2本のプラスチックピンのうちネジ穴に干渉する方の足を、根本からニッパーなどで切断します。

    5ピンスイッチの片方の足をカットした状態  
    5ピンスイッチの片方の足をカットした状態（左：カット前，右：カット後）

    おそらく回避できるはずですが、もしスイッチの中央の足が干渉する場合は、中央の足も切断します。

    中央の足をカットしたスイッチ  
    中央の足をカットしたスイッチ

1. 残りのスイッチを、すべて取り付けます。

1. ケース底面に、滑り止めのゴム足を貼り付けます。

</details>

基板をケースに取り付けた状態  
基板をケースに取り付けた状態（スイッチ取り付け前）

### スイッチの最終動作確認をおこなう

組み立て前におこなった[ソケット用パッドの確認](#ソケット用パッドの確認)と同様の手順で、すべてのスイッチが正しく動作するか最終確認します。  

### 仕上げ

1. キーキャップ、ロータリーエンコーダのノブを取り付けます。

    キーの配置は、[KLE: Nora, Fearless Wings family](http://www.keyboard-layout-editor.com/#/gists/568990362f215776aa93e3b90064f241)を参考に、好みに合わせて取り付けてください。

1. Remapでキーマップを変更したり、ファームウェアをカスタマイズして、自分好みに仕上げます。

1. 完成です。

    写真を撮影し、`#Nora_kbd` のタグをつけてツイートすると設計者が喜んだりします。  
    [Twitter: #Nora_kbd](https://twitter.com/search?q=(%23nora_kbd)&src=typed_query&f=live)

    - Fullレイアウト製作例

      Fullレイアウト製作例  
      キーキャップ： MBK Legend Glow

    - FWレイアウト製作例

      FWレイアウト製作例  
      キーキャップ： MBK, Kailhロープロファイル無刻印（無塗装）
      ケース： KBDfans 60% ALUMINUM LOW PROFILE CASE, Gray  

---

## 参考

打鍵感向上や機能追加についてのDIY情報や、トラブル調査方法などの参考資料です。  
必要に応じてお読みください。

### 打鍵感向上：ケース内部の制振と静音化

ケースやボトムプレートに工夫を施すことで、打鍵感を向上させる方法について説明します。

<details>
<summary>《《《 詳しい説明 》》》</summary>

- ケースの振動防止

    ケース内部におもりを入れておくと、ケースの共振が抑えられ、打鍵感の向上や、打鍵音の変化が期待できます。  
    おもりには、10円玉、真鍮板、自動車タイヤ用のホイールバランスウェイト、鉛シートなどを使用します。  
    また、スポンジ状の両面テープなどを使っておもりを貼り付けると、より高い防振効果を得ることができます。

    基板裏側の部品におもりの金属部分がふれてショートしないよう、スポンジシートを間に挟んだり、カプトンテープなどで保護します。

- 基板の振動防止

    基板とケース間をウレタンスポンジやシリコンシートなどで埋めると、基板の振動を抑えることができます。  
    また、ケース内部の空間を埋めることで、基板の振動音やスイッチの動作音がケース内で響くのを減らすことができます。

    スポンジなどを詰めすぎると、ネジや基板裏側の部品に力がかかるため、ほどよい程度に調節します。

    ボトムプレートを使用する場合も、基板とボトムプレートの間に対策を施すことで、同様の効果が期待できます。  
    スペーサーシート貼り付け位置  
    ボトムプレートへ、余ったスペーサーシートを貼り付けた例  
    （Pi PICO取り付け用に、ボトムプレートの一部を切り取っています）

これらの工夫をおこなう様子はこちら  
→[ケースが響いてうるさいのをなんとかしていく](https://twitter.com/jpskenn/status/1467010813773119490)

</details>

### トラブル対応：正常に入力できないスイッチの原因調査

正常に入力できないスイッチの原因調査と対応方法について説明します。  

<details>
<summary>《《《 詳しい説明 》》》</summary>

テスターをお持ちの方は、疑わしい箇所をテスターで調べるのが手っ取り早い方法ですので、積極的に使用してください。

#### スイッチのソケットへの取り付け不良

もっとも多い原因は、スイッチのソケットへの取り付け不良です。  

スイッチを取り外し、端子が曲がったり折れたりしていないか確認します。  
端子の曲がりを修復するか、新しいスイッチに交換して、もう一度キー入力を確認します。

#### ソケットの基板への取り付け不良

次に多いのが、ソケットの基板への取り付け不良です。  

ソケットのはんだ忘れや、はんだが適切に行われていないことが原因のため、ソケットのはんだ状態を確認します。  
溶けたはんだがパッド全体に広がっていること、はんだがソケットの端子の間にポコっと盛り上がって固まっていることも確認します。  

念のため、再度はんだ付けし直して、もう一度キー入力を確認します。

#### 原因箇所の特定

スイッチとソケットの取り付け不良を調査しても改善しなかった場合、原因箇所の特定をおこないます。

組み立て前におこなった[ソケット用パッドの確認](#ソケット用パッドの確認)と同様の手順で、基板のパッド部分をピンセットでショートさせ、キー入力できるか確認します。  
パッドをショートしてキー入力できた場合は、パッド自体は正常ですので、スイッチとソケットを再度調査します。

#### キー入力が確認できない場合

この場合は、ソケット用パッドや基板の配線、その他の基板に取り付けられた部品が、組み立て中にダメージを受けたことが原因と考えられます。
同じ列や行のスイッチが連続して反応しない場合は、特にこの原因が疑われます。

これ以降の調査と修復の難易度が高くなりますが、ソケット用パッドが剥がれてソケットが取り付けられないというような物理的に破壊された状態を除けば、修復できる可能性は残されています。  
（パッドが剥がれたとしても、ネジ穴に重なるスイッチでなければ、スイッチを固定してソケットを端子に差し込んで、ソケットから基板へ配線すればなんとかなります。）

電子工作に詳しい方であれば、[Nora, DN0032関連ファイル](https://github.com/jpskenn/Nora/releases/tag/DN0032)の`PCB_FW`フォルダ内のKiCadプロジェクトを参考にテスター等を用いて調査を進め、ジャンパ線などで配線を修復してください。

自分ではどうにもできない場合など、何らかのアドバイスを必要とされる方は、キット同梱のリーフレットに記載された連絡先へ問い合わせてください。  
状況に応じて、できる限りのサポートをいたします。  

</details>

### トラブル対応：LEDの取り付け不良調査

LEDが点灯しない場合など、LEDの取り付け不良を調査する方法について説明します。

<details>
<summary>《《《 詳しい説明 》》》</summary>

調査の前提として、LEDの点灯には、

```text
点灯しないLEDより後ろは、すべて点灯しない。
```

というルールがあります。

例えば、
`L1` `L2`が点灯し、`L3`が点灯しないとき、
`L4`より後ろは、正しく取り付けられていたとしても、点灯しません。

このルールをふまえ、点灯しない最初のLEDから順番に調査を進めていきます。

#### LEDが途中から点灯しない場合

ジャンパし忘れや、ジャンパする箇所を間違えていることが原因のひとつと考えられます。

[LEDの配線経路をジャンパする](#ledの配線経路をジャンパする)の通りにジャンパされているか確認します。

#### LEDの光り方がおかしい場合

LEDがちらついたり、色がおかしい場合は、LEDのはんだ不良が疑われます。

光り方がおかしいLEDのはんだ付けをやり直します。

フラックスがある場合は、LEDの端子に塗布しておくと、はんだがダマになりにくくなります。  
はんだ吸い取り線がある場合は、一旦はんだを除去しておきます。  
どちらもない場合は、はんだを足しながら、はんだ付けをやり直します。

#### LEDが点灯しない場合

正しくジャンパしていてもLEDが点灯しない場合は、LEDの取り付けまたはLED自体に原因があると考えられます。  
LEDの点灯に関するルールにしたがい、**光らないLEDの、番号が若いものから順番に**以下の対処を行います。

1. 光らないLEDのはんだ不良を修復する

    「光らないLEDが正しくはんだ付けされていない」と仮定した対処です。  
    光らないLEDのはんだ付けをやり直します。

1. 光らないLEDの*ひとつ前*のLEDのはんだ不良を修復する

    「光らないLEDは正常に取り付けられているが、*ひとつ前*のLEDのはんだ不良が原因で配線がつながっていない」と仮定した対処です。  
    光らないLEDの*ひとつ前*のLEDのはんだ付けをやり直します。

1. 光らないLEDを新しいものに交換する

    「光らないLEDが壊れてしまっている」と仮定した対処です。  
    これまでの対処をおこなっても点灯しない場合は、光らないLED自体が壊れていると判断して、新しいものに交換します。

    以下のような方法で、LEDを取り外すことができます。

    - 少しずつ持ち上げる方法
      強く持ち上げるとパッドが剥がれてひどいことになるので、力をかけずに少しずつ持ち上げます。

        1. こて先の温度を270〜320℃程度にします。
        1. はんだ吸い取り線で、できる限りのハンダを除去しておきます。
        1. 片側2本の端子を同時に加熱しながら、ピンセットでLEDを少しだけ持ち上げます。
        1. 反対側の2本の端子も、同様にして、少しだけ持ち上げます。
        1. これを交互に繰り返し、じわりじわりと取り外していきます。

    - 熱々にして持ち上げる方法
      溶けたはんだで火傷しないように注意します。

        1. こて先の温度を270〜320℃程度にします。
        1. LEDの端子部分を温め、はんだをたーーーーーーっぷりと溶かし、端子部分につけておきます。  
        （あずき〜大豆くらいの大きさの溶けたはんだ）
        1. 反対側の端子にも、同じようにはんだをたっぷりとつけます。
        1. LEDのプラ部分をピンセットつまみます。
        1. LEDの両側のはんだを交互に2秒ずつ温めるのを繰り返し、両側のはんだが溶けた状態にします。
        1. その状態でLEDをつまみ上げて、基板から取り外します。

</details>

### 資料：キーキャップ選び方ガイド

以下のリンク先をご覧ください。  
各レイアウトに対応するChoc V1用キーキャップと、使用感などをまとめまています。

[資料：Nora用キーキャップ選び方ガイド](KeycapsGuide.md)

### 資料：初期ファームウェアの機能と設定値

出荷時に書き込まれている初期ファームウェアの機能と設定値を説明します。

<details>
<summary>《《《 詳しい説明 》》》</summary>

- キーマップ書き換えツール

    RemapやVIAに対応。

- レイヤー

    10個のレイヤーを使用できます。  
    レイヤー構成とレイヤーインジケータLEDの色は次の通りです。

    | No. | レイヤー名 | 主なキー割り当て | レイヤーインジケータLEDの色<br>左スペース, 右スペース |
    | :-: | :-- | :-- | :-: |
    | 0 | ベースレイヤー #1 | 日本語配列 | 未割り当て<br>（RGB Matrixのエフェクト色） |
    | 1 | ベースレイヤー #2 | 英語配列 | 青, 青 |
    | 2 | ベースレイヤー #3 | テンキー | 黄, 黄 |
    | 3 | Lower #1 | ファンクションキー<br>記号（日本語配列用）<br>オーディオコントロール | 緑, 緑 |
    | 4 | Lower #2 | ファンクションキー<br>記号（英語配列用）<br>ボリューム | 明るい緑, 明るい緑 |
    | 5 | Lower #3 | 未設定 | 未割り当て<br>（RGB Matrixのエフェクト色） |
    | 6 | Raise #1 | ファンクションキー<br>数字<br>カーソル移動 | 明るい青, 明るい青 |
    | 7 | Raise #2 | ファンクションキー<br>数字<br>カーソル移動 | シアン, シアン |
    | 8 | Raise #3 | 未設定 | 未割り当て<br>（RGB Matrixのエフェクト色） |
    | 9 | Adjust | ベースレイヤー切り替え<br>LED等の設定<br>スクロールロックなど | 赤, 赤 |

    CapsLockがONのときは、左スペースのインジケータLEDが紫色になります。

- イルミネーションLED  

    全キーのLEDによる、RGB Matrix Lightingを使用したイルミネーションを表示します。  
    初期状態のエフェクトは単色の赤色で、組み立て時にLEDの点灯を確認できます。

- レイヤーインジケータLED  

    左スペースと右スペースの2個をLEDをレイヤーインジケータとして使用し、レイヤーの状態を表示します。  
    表示色はレイヤーの項目に記載しています。

- ロータリーエンコーダ

    `REレイアウト`はロータリーエンコーダを使用できます。

- その他

  - ベースレイヤーを保存する方法

    キーボードの電源を切ってもベースレイヤーが記憶されるようにするには、  
    デフォルトレイヤー切り替えのキー `DF(0)`, `DF(1)`, `DF(2)` を `Shift` と組み合わせて押します。

    例えば、`Shift + DF(1)` を押すと `レイヤー1` へ切り替わると同時に、EEPROMへその情報が保存されます。
    EEPROMへ保存されているので、キーボードの電源を切っても、次回接続した際に`レイヤー1`の状態で起動します。

</details>

### 資料：ファームウェアの書き込み方法

RemapやQMK Toolboxを使用して、ビルド済み（＝作成済み）のファームウェアを書き込む方法について説明します。  

<details>
<summary>《《《 詳しい説明 》》》</summary>

**ファームウェアを書き込んだ後に初めてRemapに接続した際、キーボードレイアウト画面が表示されるまで30秒〜1分ほどかかる場合があります。**  
EEPROMの初期化処理がおこなわれていますので、キーボードの準備が整うまでしばらくお待ちください。  
2回目以降の接続では、すぐに接続されます。

#### Remapを使用して書き込む方法

Remapを使用して書き込む手順を説明します。

1. キーボードをPCやMacとUSBケーブルで接続します。

1. Google Chromeブラウザで、[Remap](https://remap-keys.app/)のページを開きます。

1. `KEYBOARD CATALOG`をクリックし、左上の`Keyboard Name`に`Nora`を入力して`SEARCH`ボタンを押して検索します。

1. 検索結果から`Nora`を開きます。  
    ※検索結果には`Nora`の試作版を含めて表示されます。  
    Fullレイアウトの写真の方がv1です。  
    とりあえずどちらかを開いて、カタログページ先頭に`for Nora v1`と書かれていれば正解です。  
    Remap catalog, Nora, V1

1. `FIRMWARE`と書かれたところをクリックして、ファームウェアのリストを表示します。
    Firmware button

1. 書き込みたいファームウェアの`FLASH`を押します。
    Firmware list

1. Flash Firmwareのポップアップ画面のBootloaderの項目で、`dfu`を選択し、右下の`FLASH`を押します。

    Select dfu

1. 接続要求画面が表示されたら **そのまま放っておいて** 、基板裏側の`Reset`と書かれたスイッチを押します。

    Connect request

    Reset switch

1. 接続要求画面に`ATm32U4DFU - ペア設定済み`が表示されるので、これを選択して`接続`ボタンを押します。

    Select dfu

1. ファームウェアの書き込みが始まり、10秒程度で書き込みが完了します。

    Select dfu

    メッセージの最後に、

    ```text
    Writing the firmware finished successfully.
    ```

    と表示されていれば、書き込み成功です。  

以上でRemapを使用したファームウェアの書き込み作業は完了です。

書き込みが完了したら、Remapへ接続してキーマップをリセットします。

Reset keymap

#### QMK Toolboxを使用して書き込む方法

[QMK Toolbox](https://github.com/qmk/qmk_toolbox/releases)を使用してビルド済み（＝作成済み）のファームウェアを書き込む方法について説明します。

QMKファームウェアのドキュメント[ファームウェアを書き込む](https://docs.qmk.fm/#/ja/newbs_flashing?id=ファームウェアを書き込む)も、あわせてご覧ください。

1. [資料：Nora, Fearless Wings 関連ファイル](#資料nora-fearless-wings-関連ファイル)に記載のダウンロード先から、キーボードのレイアウトに応じたビルド済みのファームウェアをダウンロードします。

1. [QMK Toolbox](https://github.com/qmk/qmk_toolbox/releases)をダウンロードし、起動します。

1. `Open`ボタンを押し、QMK Toolboxで、ダウンロードしておいたファームウェアを開きます。

1. `Nora`キーボードをDFU (Bootloader)モードにします。
    1. USBケーブルが接続されている場合は、ケーブルを抜きます。
    1. キーボードの**左上**のキーを押したまま、USBケーブルを差し込みます。

1. QMK Toolboxの画面に、以下のメッセージが表示されます。  
    （もし表示されない場合は、USBケーブルを接続した状態で、基板裏側のリセットボタンを押します）

    ```text
    *** Atmel DFU device connected: ATMEL ATm32U4DFU (03EB:2FF4:0000)
    ```

1. QMK Toolboxの`Flash`ボタンを押すとファームウェアの書き込みが始まります。  
    5秒程度で書き込みが終わり、QMK Toolboxの画面に以下のような書き込み完了メッセージが表示されます。（サイズ表記などの、細かい部分は実際とは異なります）

    ```text
    *** Attempting to flash, please don't remove device
    >>> dfu-programmer atmega32u4 erase --force
        Erasing flash...  Success
        Checking memory from 0x0 to 0x6FFF...  Empty.
    >>> dfu-programmer atmega32u4 flash --force /Users/jpskenn/qmk_firmware/nora_v01_via.hex
        0%                            100%  Programming 0x5E80 bytes...
        [>>>>>>>>>>>>>>>>>>>>>>>>>>>>>>>>]  Success
        0%                            100%  Reading 0x7000 bytes...
        [>>>>>>>>>>>>>>>>>>>>>>>>>>>>>>>>]  Success
        Validating...  Success
        0x5E80 bytes written into 0x7000 bytes memory (84.38%).
    >>> dfu-programmer atmega32u4 reset
    *** Atmel DFU device disconnected: ATMEL ATm32U4DFU (03EB:2FF4:0000)
    ```

    書き込み完了メッセージが表示されたら、QMK Toolboxを終了してもかまいません。  

    これとは違うメッセージ（書き込み失敗など）が表示された場合は、スクリーンショットを撮ったり、メッセージをコピーしておくと、何らかのサポートを受ける場合にスムースに話が進みます。

1. 書き込みが終わってから10秒ほど待つと、キーボードが起動し、キー入力できるようになります。  
  ファームウェアを書き込んだ後、初回起動時に外部EEPROMの消去をおこなっています。  
  この消去処理に10秒ほどかかっています。

1. リセットボタンを使ってDFUモードにする操作をおこなった場合は、[資料：EEPROMを消去して、初期状態に戻す方法](#資料eepromを消去して-初期状態に戻す方法)をおこないます。

以上でQMK Toolboxを使用したファームウェアの書き込み作業は完了です。

</details>

### 資料：EEPROMを消去して、初期状態に戻す方法

EEPROMに記録されているデータを消去し、初期状態に戻す方法について説明します。  

<details>
<summary>《《《 詳しい説明 》》》</summary>

キーマップやLEDの表示モードなどのEEPROMに記録されているデータを消去し、初期状態に戻すことができます。  

また、古いデータが残って動作がおかしくなるのを防止するため、リセットボタンを使用してファームウェアを書き込んだ際にもこの操作をおこないます。

1. USBケーブルを接続している場合は、ケーブルを抜きます。

1. キーボードの左上のキーを押したまま、USBケーブルを差し込みます。

1. ケーブルを差し込んで、1、2と数えてから、USBケーブルを抜きます。

1. USBケーブルを差し込みます。

1. 10秒ほど待つとキーボードが起動します。

以上でEEPROMが消去され、初期状態に戻ります。

</details>

### 資料：Nora, Fearless Wings 関連ファイル

このキーボードに関連するファイルです。  
必要に応じて使用します。

<details>
<summary>《《《 詳しい説明 》》》</summary>

以下のファイルを [Nora v1 files](https://gist.github.com/jpskenn/268cb107aca291d79856a0f6653eed7c) にまとめてあります。  
ZIPファイルをダウンロードし、展開して使用します。

- Remap / VIA用キーボード定義ファイル： nora_via_v1(DN0032).json

- ビルド済みファームウェア

  - `Fullレイアウト`： nora_v1_via.hex

  - `FWレイアウト`： nora_v1_via_fw.hex

  - `REレイアウト`： nora_v1_via_re.hex

ファームウェアのソースは、私がQMKからフォークしたリポジトリ [https://github.com/jpskenn/qmk_firmware](https://github.com/jpskenn/qmk_firmware) に配置しています。  
[develop_nora](https://github.com/jpskenn/qmk_firmware/tree/develop_Nora)ブランチの、`keyboards/nora/v1`に関連ファイルが格納されています。  
v.1(DN0032)販売開始時のファームウェアは、[nora_v1タグ](https://github.com/jpskenn/qmk_firmware/releases/tag/nora_v1)を参照してください。

また、その他の基板等の設計ファイルなどは、Noraリポジトリの[DN0032タグ](https://github.com/jpskenn/Nora/releases/tag/DN0032)にまとめてあります。

</details>

### 資料：レイアウトを変更する方法

別売のスイッチプレートを使用してレイアウトを変更する方法について説明します。

<details>
<summary>《《《 詳しい説明 》》》</summary>

#### キーボードをこれから組み立てる場合

1. ビルドガイドに沿って、[組み立て前の確認](#組み立て前の確認)までおこないます。

1. 組み立てを開始する前に、変更するレイアウトに合ったファームウェアに書き換えます。
  →[資料：ファームウェアの書き込み方法](#資料ファームウェアの書き込み方法)を参考

1. [組み立て手順](#組み立て手順)に沿って組み立てます。

#### 組み立て済みの状態から、別のレイアウトに変更する場合

1. 変更するレイアウトに合ったファームウェアに書き換えます。
  →[資料：ファームウェアの書き込み方法](#資料ファームウェアの書き込み方法)を参考

1. ボトムプレートまたはケースを取り外します。

1. スイッチを取り外し、基板とスイッチプレートを分離します。

1. （LEDを使用する場合）LEDの配線経路ジャンパを変更します。
  レイアウトに合わせて、ジャンパを変更します。
  'Full'に変更した場合は、はんだを取り除いて、隣同士のパッドがつながらないようにします。

1. （LEDを使用する場合）LEDを追加で取り付け、または余分なLEDを取り外します。
  `FW`から`Full`に変更して取り付け箇所が増える場合は、LEDを追加で取り付けます。

  その逆に、`Full`から`FW`に変更して取り付け箇所が減る場合は、未使用のLEDを取り外します。

1. Kailh Choc用ソケットを取り付けます。
  `FW`から`Full`に変更する場合など、スイッチが増える場合は、ソケットを追加で取り付けます。
  スイッチが減る場合は、未使用のソケットは取り付けたままでかまいません。（取り外してもかまいません）

1. ロータリーエンコーダを取り付け、または取り外します。
  使用するレイアウトに合わせて、ロータリーエンコーダを取り付け、または取り外します。

1. [スイッチプレートにスペーサーシートを貼り付ける](#スイッチプレートにスペーサーシートを貼り付ける)以降の手順をおこなって組み立てます。

</details>

### 資料：Raspberry Pi PICOによる動作（実験的機能）

Raspberry Pi PICOを使用したDIYの実験的機能について説明します。

<details>
<summary>《《《 詳しい説明 》》》</summary>

DIYの実験的機能として、Raspberry Pi PICO（以下、PICOと呼びます）を使用して、キーボードを動作させることができます。

#### できること

- キーマトリクスを駆動して、キーボードとして使用する
- LEDを点灯させる（16個までの点灯を確認済み）

#### できるかもしれないこと

以下は、動作未確認の項目です。

- すべてのLEDの点灯（USBの消費電力に注意が必要）
- EEPROMや、その他のI2C接続された機器との通信
- 未割り当てのGPIOピンの使用

#### 使用時の注意

- GH60型，Poker型ケースには、（たぶん）取り付けできません。  
  取り付けられたとしても、ケーブルの取り回しを工夫する必要があります。

#### 接続図

PICOの接続図は以下の通り。

Pi PICO wiring

#### 取り付け方法

1. 基板裏側の中央上部へ、ピンヘッダなどを使ってPi PICOを取り付けます。

    Pi PICO 取り付け箇所  
    Pi PICO 取り付け箇所と、電源供給元ジャンパの位置

    ピンヘッダやピンソケット、コンスルーなどがスイッチ用ソケットと干渉しないように、  
    高さ：2mm以上  
    幅：2.5mm以下  
    のものを使用します。

    Pi PICOを取り付けた状態  
    Pi PICOを取り付けた状態

    なお、基板とスイッチプレートの間隔が1mmしかないため、コンスルーが奥まで刺さり切らない場合があります。  
    ピンヘッダやピンソケットは、基板へはんだ付けした後に飛び出したピンをニッパーなどでカットして1mm以下にします。

1. LEDとEEPROMへの電源供給元ジャンパを、`PICO VBUS`へ切り替えます。

    `JP3:Device Power`：LED, EEPROMへの電源供給元

    | ジャンパ設定 | LEDの電源供給元 | 備考 |
    | :-: | :-- | :-- |
    | PICO VBUS | PICOのVBUS ||
    | USB | 基板に接続したUSBのVCC | オンボードのMCU、ATmega32u4使用時のデフォルト設定|
    | オープン | 接続なし | PICO使用時に、LEDやEEPROMへ電源供給したくない場合 |

1. （オプション）必要に応じて、I2Cプルアップ抵抗への接続を切り替えます。

    `JP1`,`JP2`：I2Cプルアップ抵抗（4.7KΩ）への接続

    | ジャンパ設定 | I2Cプルアップ抵抗への接続 | 備考 |
    | :-: | :-- | :-- |
    | ブリッジ | プルアップ抵抗へ接続 | オンボードのMCU、ATmega32u4使用時のデフォルト設定|
    | オープン | 接続なし ||

1. （オプション）ボトムプレートの一部を切り離します。

    ボトムプレートと組み合わせる場合は、プレート中央部を切り離します。  
    左右につながっている4箇所をニッパーなどでカットしてから、マウスバイト（点線部分）に沿って折り曲げると切り離せます。  
    切り離した部分が尖っているため、やすりなどを使って滑らかにします。

    ボトムプレートの一部を切り離した状態  
    ボトムプレートの一部を切り離した状態

#### ファームウェア

ファームウェアに[PRK Firmware](https://github.com/picoruby/prk_firmware)を使用して、動作を確認済みです。

- 全キーの入力
- LED点灯（16個まで）

動作確認に使用したファームウェアはこちら：[keymap.rb](../Firmware/prk_nora/keymap.rb)

</details>

### サービスマニュアル

基板の準備やファームウェアの書き込みなど、出荷前の作業メモです。

<details>
<summary>《《《 詳しい説明 》》》</summary>

#### パーツリスト

| 部品名 | 個数 | 備考 |
| :---- | :-----: | :---- |
| USBコネクタ<br>USB4085-GF-A | 1 ||
| ESD<br>PRTR5V0U2X | 1 | SMTAしなかった場合 |
| FUSE<br>0ZCJ0050AF2E | 1 | SMTAしなかった場合 |
| リセットスイッチ<br>RS-187R05A2-DSMTRT | 1 ||

#### 基板セットアップ

1. 部品取り付け

    1. 基板裏側からUSBコネクタを取り付ける

        テスターでピン接続、ショートしないことを確認する。
        USBコネクタ接続図  
        USBコネクタ接続図

    1. （オプション）基板裏側`D10`へESDを取り付ける

        基板に描かれた取り付け方法を参考

    1. （オプション）基板裏側`F1`へFUSEを取り付ける

        方向なし

    1. リセットスイッチを取り付ける

        方向なし

1. ジャンパ

    1. I2Cプルアップ抵抗への接続をジャンパする。  
      `JP1`と`JP2`の2箇所

    1. デバイス電源をジャンパする  

      `JP3: Device Power` → `USB`

      `JP3: Device Power`付近の、`Device Power`と`GND`が導通しないことをテスターで確認。

      `ICSP`ピンの`+5V`と`GND`が導通しないことをテスターで確認。

1. ファームウェア書き込み

    1. QMK Toolboxを起動してファームウェアを開く

    1. 基板をPC/Macへ接続

      QMK Toolboxに、デバイスの接続メッセージが表示されることを確認。

    1. 基板のリセットスイッチを押す

      QMK Toolboxに、デバイスの切断と接続のメッセージが表示されることを確認。

    1. `Flash`で書き込む

    1. Remapに接続 → EEPROMの初期化に1分ほどかかる

    1. Remapで全キーのパッドを確認する

</details>

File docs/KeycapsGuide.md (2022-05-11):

# 資料：Nora用キーキャップ選び方ガイド

Noraの各レイアウトに対応するChoc V1用キーキャップと、使用感などをまとめました。

Choc V1用キーキャップのうち、”Choc用キーピッチ対応”として販売されているキーキャップは、大きな問題なく取り付けることができます。（2022年4月現在）

*隣同士のキーが少し当たる場合は、ソケットを傾かないように取り付けたり、キーキャップの成形バリをカッターなどで取り除くと問題なく使用できます。*

## キーキャップ対応表

凡例  
◎：完全対応，○：対応，△：キーキャップを追加すればOK，×：取り付け不可

| 商品名 | Full | FW | RE | コメント |
| :---- | :---: | :---: | :---: | :---- |
Kailhロープロ刻印<br>セット | ○ | ◎ | ◎ | - 刻印あり<br>- バックライトLED対応 透過タイプ<br>- 低価格<br><br>Fullレイアウトでは1.5uのキーが足りないため、最下行の中央には1.25uまたは1uを取り付けるか、1.5uの単品キーを1個追加します。<br>スペースキー用にKailhロープロ無刻印などの単品キーを追加すると、見た目が良くなります。 |
| Kailhロープロ無刻印<br>(黒, 白, 無塗装）<br>単品 | ◎ | ◎ | ◎ | - 刻印なし<br><br>同じKailhロープロの刻印ありと組み合わせても、無刻印を単体で使用してもどちらも良い感じの見た目になります。<br>無塗装は少しクリーム色っぽい乳白半透明のような感じで、バックライトが綺麗に光ります。 |
| Kailhロープロ無刻印<br>（クリア）<br> 単品 | × | × | × | クリアは形状が異なるため、取り付けできません。 |
| MBK Legend‡ Glow<br> セット | ◎ | ◎ | ◎ | - 刻印あり<br>- バックライトLED対応 透過タイプ<br><br>少し高価ですが、1uと1.5uのブランクキーが豊富に付属しているのが嬉しいです。<br>スイッチへの抜き差しが少しきついかも。 |
| MBK 1u, 1.5u<br>単品 | ◎ | ◎ | ◎ | - 刻印なし<br><br>黒と白に加え、カラー版も販売されるようになりました。<br>白いキーは染色に適しており、オリジナルの色に染めることもできます。 |
| Gravity Keycaps<br>セット | △ | △ | △ | - 刻印なし<br><br>Choc V1用キーキャップとしては唯一（？）の、キーの位置に合わせて個別のキー形状が与えられたキーキャップ。<br><br>40キー程度のキーボード用として作られているため、Noraで使用するには多くのキーが足りません。<br>MBKの黒色とのマッチングが良好なので、これと組み合わせるとよいでしょう。 |
| WRK<br>セット | × | × | × | MX用の19.05*19.05mmピッチを基準に作られているため、取り付けできません。 |
| MCC-profile POM Choc keycap 1u<br>単品 | △ | △ | △ | - 刻印なし<br><br>POM素材がとてもスベスベで、汚れがつかず、ずっと真っ白なまま使えるのも嬉しいです。<br><br>1uサイズしかラインナップされていないため、1.5uは他のキーキャップを使用します。<br>MBKの白がMCCに近い白色ですが、MBKはキーバックライトを透過しません。<br>バックライトを使う場合は、Kailhロープロ無刻印の無塗装と組み合わせるのがおすすめです。 |

## キーキャップ取り付け例

各種キーキャップの取り付け例です。  
試作版の写真も含まれます。

- Kailhロープロ刻印

    

    

- MBK Legend‡ Glow

    

- MBK 単品

    

- Gravity Keycaps + MBK単品

    

- MCC-profile POM + Kailh無刻印（無塗装）

    

## 参考：Noraのキーピッチ

NoraはChoc用キーキャップのキーピッチよりも横方向がほんの少し狭くなった 17 × 17.8594mmのキーピッチになっています。（[基板上の寸法図](../assets/BuildGuide_DN0032/PCB_key_pitch.png)）

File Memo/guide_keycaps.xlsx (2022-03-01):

凡例
◎：完全対応，○：対応，△：他のキーキャップが必要，×：取り付け不可
Layout | Full | FW | RE | 備考
Kailh low profile | ○* | ◎ | ○* | FullとREレイアウトでは、最下行の中央は1.25uまたは1uとなります。 Kailhロープロ無刻印やMBKの1.5uを2個追加してスペースキーとして使うと、すべてぴったり収まります。
Kailhロープロ無刻印（黒, 白, 無塗装） | ◎ | ◎ | ◎
Kailhロープロ無刻印（クリア） | × | × | × | クリアのみ形状が異なりキーのサイズが少し大きいため、取り付けできません。
MBK（単品売り） | ◎ | ◎ | ◎
MBK Legend Glow | ◎ | ◎ | ◎ | 貴重なChoc用レジェンド付きキーキャップ（その2）。 豊富な1.5uキーキャップには、スペースキー用コンベックス2個も用意されているのが嬉しい。 `=+`や`-_`キーがなかったりするが、他のキーで代用すればOK。 スイッチへの抜き差しがきつく、取り外すときにスイッチが分解されることが多い。
Gravity Keycaps | △ | △ | △
MCC-profile POM Choc keycap | △ | △ | △ | 1uしかラインナップされていないため、1.5uは他のキーキャップを使用します。 MBKの白がMCCに近い白色をしていますが、MBKはキーバックライトを透過しません。 バックライトを使う場合はKailhロープロ無刻印がおすすめですが、キー自体の色がMCCほど白くないため、ライトを消すと色の違いが気になるかもしれません。常時点灯なら問題ありません。
WRK | × | × | × | MX用の19.05*19.05mmピッチを基準に作られているため、取り付けできません。
そのた？

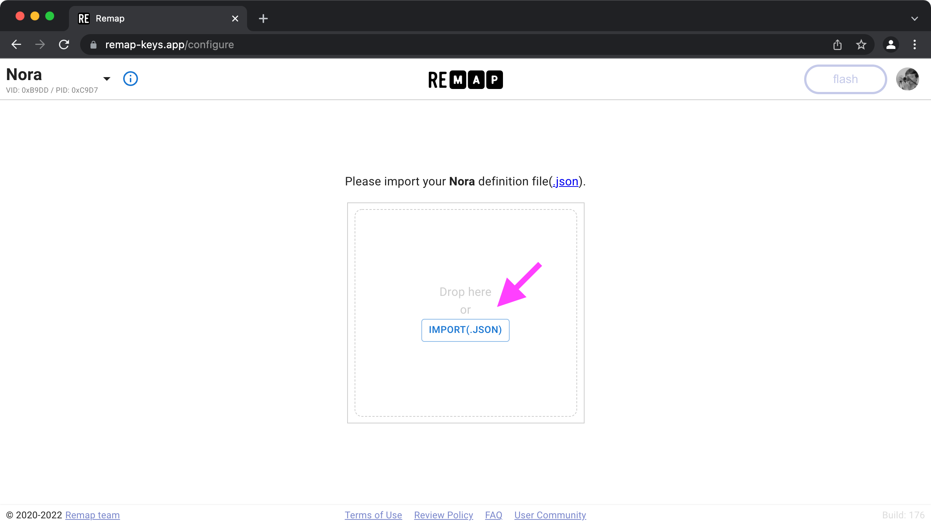
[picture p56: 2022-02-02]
assets/BuildGuide_DN0032/Remap_import.png

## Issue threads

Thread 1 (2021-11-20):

FULL hotswap socket support

jpskenn, 2021-11-20:
このキーボードに限らず、「スイッチを気軽に交換したい」というユーザーの声がある。

v.0.1ではソケット実装の手間を省き、ソケット代をケチるため、直接はんだ付けすることにした。

レイアウトがひとつだけなので、ほとんどが、そのままソケットに置き換え可能。
左シフト2u／1u+1uは、上下反転で対応可能。

問題が一つあり、左端の列は、South Facing（LEDが上、ソケットが下）にすると、基板からソケットの端子がはみ出す可能性がある。
実際のはみ出し量を、v.0.1の現物で確認してから、今後の方針を決める。

jpskenn, 2021-11-24:
KiCad上ではみ出し量を計測。

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
左端の列、ソケット端子のはみ出しは約0.5mm。
そのままでもケースにはギリギリ干渉しないと思われる。

ソケット端子はみ出しだ懸念されるのは3キー。

jpskenn, 2021-11-24:
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
MCUにATmega32u4-AUを使う場合、2ソケットが干渉。
ATmega32u4-MUにしても、1ソケットが干渉。（-MUを最下行に単独配置すればOK）

ResetSWに1ソケット干渉。

jpskenn, 2021-11-24:
ResetSWは、最悪、ケース裏側の窓から外れてもしゃーない

jpskenn, 2021-11-24:
ケースネジ穴部分とソケットの干渉は、ほぼなし。
中央下のネジ穴とパッドが近いため、パッドは少し削った方がよい。

jpskenn, 2021-12-04:
実機を作ってみて、直はんだするのは、スイッチ交換が不可能になるのとほぼ同じくらいのインパクトがある。
Mill-Maxソケットはキット化が面倒、かつ金額がきびしいのでやりたくない。
というわけで、Kailhソケット化で決定。

左端はソケット端子部がとびだすが、ソケットの強度的に半分ハンダでは無理っぽいため、逆向きとかで対応。
LEDは1行目だけのつもり。

左上：LEDが逆になるが、North Facing。
MCUまわり：North Facingとかも含めて、なんとか入れる。
左シフトまわり：左端から、北・南・北で並べる。
左下：北

Closed 2021-12-10.

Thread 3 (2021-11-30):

Full RGB LED backlight

jpskenn, 2021-11-30:

jpskenn, 2021-12-06:
LSFTの2u / 1u + 1uのところについて

両方のパターンにLEDつけると、ジャンパで経路切り替えが必要になる。

1+1だけにつけとけば十分かな。
デメリットは？

jpskenn, 2021-12-06:
最低でもR1（現在）＋R5

jpskenn, 2021-12-08:
MCUとCrystalまわりが狭くて配置が厳しい。

jpskenn, 2021-12-09:
Decided to apply R1 and R5 only.
R1とR5だけに決定。

WS2812C-2020を使ったとしても、MCUまわりがきつすぎなので。

jpskenn, 2021-12-10:
R5に配置するLEDは15個。
2uは2個、他は1個

jpskenn, 2021-12-10:
R5への配置
2uに2個配置しようとしたが、スタビ穴にかぶらない位置へ配置すると、スイッチに隠れてLEDが見えなくなる。
透明ハウジングのスイッチなら問題ないが、そうでない場合に残念な感じになる。
→2uへも1個だけの配置とする。
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

Closed 2021-12-10.

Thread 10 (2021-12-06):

Shorten right side frame over screw hole on SW plate

jpskenn, 2021-12-06:
ネジ止めするとき、ドライバーがフレームに当たるので、スイッチプレートの、右のネジ穴に重なるフレームをもう少し短くする。

Closed 2021-12-12.

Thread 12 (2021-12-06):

Move logo to PCB front side

jpskenn, 2021-12-06:

jpskenn, 2021-12-08:
PCB front side will be covered by switch and switch plate, then logo will be hidden.
Logo should be shown after build.

Keep logo back side.

Closed 2021-12-08.

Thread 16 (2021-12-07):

PICO

jpskenn, 2021-12-07:
PICO用コンスルーの高さは、Kailhソケット使用時でも2mm高でぎりぎり使用可能。

どうせPICO穴をあけたボトムプレートと組み合わせるしかないので？（ロープロケースに入る？ケーブル取り回しは？）
2.5mm高のものでもかまわない。

jpskenn, 2021-12-07:
PICO穴をボトムプレートにあけても、USBケーブルのコネクタ部がストレートタイプだと刺せない。
L字タイプが必要。

jpskenn, 2021-12-12:
PICO対応ボトムプレート（L字コネクタ必要）を作る？

jpskenn, 2021-12-16:
- PICO対応ボトムプレート
  PICOのところをマウスバイトとかで切り離せるように。使わないならそのままでよい。
- I2C、LED電源ソースのジャンパを、PICOの切り欠きのところへ配置
  ボトムプレートを外さなくてもPICO対応作業ができるように

jpskenn, 2021-12-19:
DN0030の設計で、
https://github.com/jpskenn/Nora/issues/16#issuecomment-995785778
を盛り込んだので、ひとまずクローズする。

Closed 2021-12-19.

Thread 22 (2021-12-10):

Wide Layout

jpskenn, 2021-12-10:
1800風はNarrowレイアウトであり、狭ピッチでさらに手を近づけている。
左右の手がハの字になる角度が急になり、ハの先端が閉じ、下端が開く感じになっている。

JonesのWideレイアウトの真ん中に1列追加するようにして、Wideレイアウトを試したい。

jpskenn, 2021-12-13:
中央部分をテンキーにするのもあり。
中央部分にキーを配置せず、MCUを置いて、全キーLEDにするのもあり。

jpskenn, 2021-12-14:
WIP
http://www.keyboard-layout-editor.com/#/gists/f8d08df6aa77dcdd6d3cb7350a545df7

jpskenn, 2021-12-19:
https://github.com/jpskenn/Nora/tree/v03_wide

Closed 2021-12-19.

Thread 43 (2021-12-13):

South-facing left edge switches

jpskenn, 2021-12-13:
左端のスイッチを正方向に向ける。
LEDをスイッチ上側で光らせる。

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
ソケットの端子は基板外形にぴったりくらいなので、いける。

パッドのはがれが心配なので、ai03氏のパッド剥がれ防止ソケットパッドを参考に補強する。

jpskenn, 2021-12-13:
この強化型フットプリントでいく。
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

ソケット装着はこんな具合。
パッドが狭い気がするので、マスクを上下にもう少し広げたい。
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

Closed 2021-12-14.

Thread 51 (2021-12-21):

Any idea to know LED connection order

jpskenn, 2021-12-21:
シルクに、LEDの繋がってる感じがわかる何か。
できれば、LEDの向きも、もっと、わかるもの。

jpskenn, 2021-12-26:
LEDごとに何かつけなくても、一応、番号がふってあるので、問題ない。

代わりに、LED installのジャンパに、FULL 71個、Simple 25個とか書いたり、接続を線で描く（25個のときは”＝"みたいなの？）

jpskenn, 2022-01-09:
基板裏側の全面ロゴをやめたため、LED番号が全て見えるようになったため、問題は解消。

Closed 2022-01-09.

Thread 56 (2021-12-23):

Add height to "T" and "Y"

jpskenn, 2021-12-23:
TとYが打鍵しにくい。
MBK、Kailhロープロファイルキーキャップの平面的なプロファイルに起因している？
TとYだけPCBを2段にするとかしてなんとかなる？

PとQも同様？

jpskenn, 2022-01-09:
[Gravity Keycaps](https://shop.dailycraft.jp/products/gravity_keycaps)（使ったのはLowタイプ）によって、キーキャップの高さによる打鍵のしにくさは解消した。

もっと安価に同様の効果を得るため、MBKキーキャップを2段重ね（1個は足を折る）にするテストをおこないたい。

jpskenn, 2022-01-13:
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
2枚重ねのテストを仕込み中

jpskenn, 2022-01-13:
2段重ねを装着。
TとYは格段に打鍵しやすくなった。
しかし、人差し指をT,Yへ移動するときにキーの角にちょくちょく引っかかるため、トータルでは打鍵しにくくなってしまう。
特にMBKはキーの角が高めのため、引っかかりやすい。
ここを斜めにカットできれば、マシになると思われる。

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

jpskenn, 2022-01-14:
手前と手前の角を削ったところ、指の引っかかりが大きく減少し、常用できるくらいの操作感になった。
横側を削っていないので、横からの引っ掛かりが残っている。
横も削れば、かなり良い具合になりそう。
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

jpskenn, 2022-01-29:
Kialhロープロキャップでは、2段重ねにしないとつらくなるような遠さを感じない。
MBKが、凹んでる＆エッジがきつめなのが良くないようだ。

Kailhロープロキャップは、フラットなボトムでも気にならない感じに使えるので、
3Dな発展は、そこまで求めなくなってきた。

jpskenn, 2022-05-11:
TとYの話から逸れるが、Gravity Keycaps（Lowタイプ）使用時に1行目のMBKが相対的に低くなってしまうため、1行目のMBKを2段重ねにした。
1行目と2行目の高さがそろうのと、1行目が元々遠く感じるのを2段にして緩和できているところが良い。
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

2022年4月上旬施工

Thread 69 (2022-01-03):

Useless center keys on FW.

jpskenn, 2022-01-03:
センターのテンキー部分について、

- ホームポジションから手を動かしたくない
- 手の角度がきつくなって打鍵しにくい

という欠点があり、存在意義をあまり感じない。

センターを無くす方向で、レイアウトを再考する。

jpskenn, 2022-01-03:
レイアウト案
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
http://www.keyboard-layout-editor.com/#/gists/f8d08df6aa77dcdd6d3cb7350a545df7

jpskenn, 2022-01-03:
HHKB US 60キー
HHKB JP 69キー（カーソルあり、変換キーなどもあって多い）

jpskenn, 2022-01-03:
最下行、外側へ0.25u移動した場合、右下ネジ穴とR-SPCのソケットパッドが干渉する。
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

0.125uにしても干渉してしまうため、最下行は移動するのをやめる

jpskenn, 2022-01-03:
#73

Closed 2022-01-03.

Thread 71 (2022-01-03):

Add Rotary Encoder?

jpskenn, 2022-01-03:

jpskenn, 2022-01-03:
R3の記号キーを左右1個ずつ取り除けば、直径約35mmのノブを取付可能。

このあたり
https://www.monotaro.com/g/04257348/
https://www.monotaro.com/g/04254332/

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

jpskenn, 2022-01-03:
必要な作業

- レイアウト決め（2キー取り除く？）
- 回路
- フットプリント配置
- SWプレート穴
  MXに比べ、基板とSWプレートの間隔が狭いので、エンコーダ本体の飛び出し量が増える。
  これをノブでカバーできるか？

jpskenn, 2022-01-03:
中央REに加え、MXの1uソケットも配置したい。
アルチザン置き場的に。

Closed 2022-01-08.

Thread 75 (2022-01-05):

Implement what you need / use

jpskenn, 2022-01-05:
必要なものだけ設計に含める。
必要なものを最優先して、邪魔にならないなら、入れておいても良い。

REはとりあえずフットプリントを置いておく。
SWプレートは、とりあえず通常のものだけ用意して、裏面にRE用のカットラインをつけとく程度のサポート。

jpskenn, 2022-01-08:
96a1490268e90dcc7749c3e2bd22d1eaf610c679

Closed 2022-01-08.

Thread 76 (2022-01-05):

Tight? SW plate

jpskenn, 2022-01-05:
Choc Redをはめるときにきつい。
DN0030がきつい？

Closed 2022-01-09.

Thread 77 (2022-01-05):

Interference left center bottom spacer and SW socket.

jpskenn, 2022-01-05:
ボトムプレートと基板をつなぐスペーサーとソケットが干渉する。

jpskenn, 2022-01-05:
DN0031では、最下行を左に1.25uずらしたので干渉しない。

Closed 2022-01-05.

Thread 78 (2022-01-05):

Soldering issue will happen at left side enforced SW socket pad

jpskenn, 2022-01-05:
左端の2キーで、ソケットが基板端にかかるところ。

ソケットのプラ部分が入る穴がPTHなので、パッドに予備はんだしたとき、穴の中にはんだが入ってきてソケット差し込めないことがあった。

Closed 2022-01-07.

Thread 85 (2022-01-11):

FW-PCB: Add jumper to skip LEDs with FW+RE layout

jpskenn, 2022-01-11:
FW+REのとき、FWとLEDの経路が変わるので、R3に配置されてるL38とL39をスキップする必要がある。

~~また、FWとFW+REでどこをジャンパしたら良いかわかるようなシルクを追加する。~~
→ #86 へ移動

Closed 2022-01-11.

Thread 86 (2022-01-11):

FW-PCB: Add silk to know where to jumper skipping LEDs.

jpskenn, 2022-01-11:
LEDスキップのジャンパで、FWとFW+REレイアウトで、どこをジャンパしたら良いかわかるようなシルクを追加する。

jpskenn, 2022-01-11:
https://github.com/jpskenn/Nora/commit/03953d60d01459d0aca47a087b8713041e3d4288

Closed 2022-01-11.

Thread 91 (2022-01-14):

Idea: Layering PCB to make 3D rows

jpskenn, 2022-01-14:
PCBを重ねることで、行ごとに高さの違いを作り出し、簡易的な3Dキーボードを作る。
MBKやKailh ロープロファイルキーキャップのような、行ごとに高さの違いのない平面的なキーキャップでは、”T”と”Y”の打鍵がやりにくい。

jpskenn, 2022-01-15:
R2,4,5、USB、MCUなどをGH60互換サイズの親基板として、これをケースなどに組み付ける。

R1とR3は子基板として、1行*7列か1行*6列くらいの細長いもの。
子基板と親基板は、3ピンくらいのZigZagピンヘッダを何箇所か作ってはんだ付け。
このピンヘッダはすべてGNDで、適当にはんだづけしてもOKな感じ。
スイッチ端子を端面スルーホールに出しておいて、親基板のパッドへはんだ付けして回路を接続。
端面スルーホールは、EdgeCutsにPTHを半分乗せればOK。
製造は別料金できっちりやるか、そのままでなんとなくやるか。

jpskenn, 2022-01-15:
親基板に穴を開けて、裏側と表側に子基板を貼り付ける方法は、キーの高さを抑えられて良い。
しかし、R1とR3に穴をあけたとき、R2との間隔が1ｍｍ程度になる箇所があるため、製造ではじかれる可能性が高い。

よって、R3、USB、MCUを親基板として、これに他の行を重ねることとする。
親基板には、表側に貼り付ける子基板のスイッチ穴（中央と左右の2ピン）、大きめの端子穴（はんだ付けする）、もしかしたらLED穴を大きめに、をあけておく。

jpskenn, 2022-01-15:
R3をベース ±0 として
- R2 +1.6mm （R1-R2にまたがる1.6mm子基板）
- R1 +3.2mm （R1-R2子基板に、1.6mmのR1子基板を重ねる）
- R4 ＋1.6ｍｍ
- R5 ±0 or ＋1.6ｍｍ（親指は上げないほうがいいかも？）

jpskenn, 2022-01-16:
親基板
子基板にスイッチを取り付けできるよう、
- スイッチ中央穴（元のサイズ）
- 左右2ピン穴（元のサイズ）
- スイッチ端子穴（ソケット穴2個をつなぐ）
- LED穴（LEDを入れられるように大きめの四角）

jpskenn, 2022-01-16:
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
6ピンのジグザグをスイッチとスイッチの間に配置して、親基板と接続。

jpskenn, 2022-01-17:
行ごとに高さを揃えるのではなく、同じ行でも必要な箇所だけ高くして、ちょっとだけ高くするところも設けたい。
例：
R2全体ではなく、
TAB, Q, Rを1段高く、
Tと内側の記号[を2段高く、
W, EはR3と同じ高さ。

jpskenn, 2022-01-17:
子基板の重ね方を工夫して、2〜3パターンくらいの組み合わせを作れたらいい。

jpskenn, 2022-01-17:
実現は難しそうだが、キーの角が当たるのを避けるため、子基板を親基板に対して水平でなく、斜めに設置する。
片側にピンヘッダのプラを挟むとか。

jpskenn, 2022-01-17:
3Dにするのが目的なのでサブになるが、
SWプレートというかユーザーから見える天面を用意したい。

jpskenn, 2022-01-19:
親基板と子基板の接続

### 物理的な固定方向

### 電気的な接続

- 2.54mmのピンヘッダを端面スルーホールとして使用
- 1x02ピンヘッダに合わせて、5.2ｍｍ幅のパッドを親基板に用意。
- ピンヘッダは1x02（1行2列）サイズだが、`R1-R2 1層目` `R1-R2 2層目`には1x01で配置。
  ピンヘッダをつけない方はパッドにして、1層目と2層目を接続

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

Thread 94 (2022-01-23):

DN0031-PCB: Loose LED hole

jpskenn, 2022-01-23:
前回のDN0030でLED穴がきつかったことへの対策で、穴を大きめにしたが、すこし大きすぎたようだ。
縦方向を少し狭めて、LEDを取り付けるときに傾きにくくする。

jpskenn, 2022-01-28:
34c78068df3317a4ec00476f524578912194e55c

Closed 2022-01-28.

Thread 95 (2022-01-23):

DN0031-SW-Plate: Smaller RE hole

jpskenn, 2022-01-23:
スイッチプレート、ロータリーエンコーダの穴が少し大きめなので、もうちょい小さめにしたい。
大きいと、小さめのノブを使ったときに、穴が見えてしまって残念なので。

jpskenn, 2022-01-29:
https://github.com/jpskenn/Nora/commit/7e7b950a1bde68d7a5e5eb0aa947cdb3457f1e5e

縦をちょっとだけ小さくした。
これでノブ直径22ｍｍくらいから使える。

Closed 2022-01-29.

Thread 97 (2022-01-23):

DN0031-PCB: Skipping LED

jpskenn, 2022-01-23:
スキップするLEDを取り付けないことを示す点線が、いまいちわかりにくい。

jpskenn, 2022-01-28:
わかりにくさは残っているが、ジャンパとスキップの番号をどこかに書くことでお茶を濁す。

Closed 2022-01-28.

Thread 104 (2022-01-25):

DN0031: Test speaker

jpskenn, 2022-01-25:
スピーカー、何かおかしいのか？

jpskenn, 2022-02-11:
[001db48160ea7dc721a6f5666a35d90749e5387d](https://github.com/jpskenn/qmk_firmware/commit/001db48160ea7dc721a6f5666a35d90749e5387d)
RGB Matrix, RGB Lightを無効にして、オーディオの動作を確認した。

Closed 2022-02-11.

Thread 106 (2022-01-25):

DN0031-Doc: Kailh low profile cap is ...

jpskenn, 2022-01-25:
ソケットの傾き、低頭ネジの上などの条件が重なると、Kailhロープロキャップは干渉しやすい。
~ドキュメントへ、もうちょい書いておく。~

DN0031のFWでKailhロープロキャップを使ってみて、MBKよりも打鍵しやすいことがわかった。
そのため、
「
取付の補償はできかねるが、
ソケットが傾かないように気をつけて取り付けたり、
キー同士が当たるところを少し削れば使えますよ
」
というニュアンスの注意書きにする。

jpskenn, 2022-02-06:
c8ea5d24d19e7b5424473cbdb8dbfeb35c5a89d2

Closed 2022-02-06.

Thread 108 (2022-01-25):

DN0031-PCB: Add "No switch" silk to front side

jpskenn, 2022-01-25:
基板おもて側、REで取り付けないスイッチに斜線いれる（裏と合わせる）
最下段は斜線いれて、さらに”RE→○”の文字を追加。

jpskenn, 2022-01-28:
作業が面倒なのもあるが…

そもそも、
スイッチプレートを介して基板へスイッチを取り付けるので、
REで取り付けないスイッチは、スイッチプレートで覆われて見えなくなっている。

スイッチを塗らずに、枠だけにしておけば十分。

Closed 2022-01-28.

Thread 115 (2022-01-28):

DN0031-PCB: Add LED Jumper and skip table to PCB back side

jpskenn, 2022-01-28:
基板裏側に、LEDのジャンパと、取り付けないLEDの表を載せる。
FWと+REについて。

jpskenn, 2022-01-28:
関連 #97

jpskenn, 2022-01-28:
LEDスキップについては省略。
ビルドガイドにまかせる。

Closed 2022-01-28.

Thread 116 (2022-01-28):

DN0031-Doc: RE leg clearance

jpskenn, 2022-01-28:
REの足が、基板裏とボトムプレートの間で接触しないかテスト。

jpskenn, 2022-01-29:
実測で3mmに達していないため、OK。
ビルドガイドに、ちょい注意書きを追加する。

jpskenn, 2022-01-29:
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

PEC12Rの一部の機種は、足が4.7mmとかなので、注意書きしておく。

jpskenn, 2022-02-06:
b73a2df53d559a3e1e73bf5e30fd87384d2f6500

Closed 2022-02-06.

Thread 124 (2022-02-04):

DN0031: Less DIY things

jpskenn, 2022-02-04:
基板とスイッチプレートの間にフォームを入れたり、スイッチをいじったりといったことは、自キにちょっと詳しくなった人の間ではそこそこ行われている。
しかし、大多数（＝Twitterのキーボードなリストに入っていない＝完成ツイートとか、ほぼしない）はそこまでやっていない感触。

DIY的なギミックを搭載することに頭を使うよりは、ほかのことをする。
（自分がやりたいことは別）

jpskenn, 2022-02-11:
すでに組み込んであるスピーカーとかPICOとかは残しておく。
これ以外には特に追加するものもないが、ビルドガイドの`参考`のところへ少し書くだけで、あまりアピールしなくてよい。

Closed 2022-02-11.

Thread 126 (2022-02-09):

DN0031-PCB: Change `FW` and `RE` silk to small icon

jpskenn, 2022-02-09:
シルクで`FW`と`RE`を書いているところを、アイコンにする。

- `FW`：白く塗った横長の長方形の中に、黒文字で`FW`
- `RE`：白く塗った横長の丸角の長方形の中に、黒文字で`RE`

黒文字は、シルク塗らないってこと。

jpskenn, 2022-02-09:
NOのアイコンつけたけど、見た目がうるさいので消す。
ソケットの枠も消す
LEDを取り付けないことを示すために、何か良い表現を考える。

jpskenn, 2022-02-09:
LEDだけNOつける？

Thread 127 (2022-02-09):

DN0032-QMK: Default layers

jpskenn, 2022-02-09:
デフォルトのレイヤー構成は次のとおり。
特に、*日本語配列*と*Windows用Mod*をメインに据える。

1. Base: 日本語、Win用Mod
2. Base: 英語、Win用Mod
3. Base: 英語、SemiErgo、Win用Mod
4. Lower
5. Raise
6. Func
7. Adjust

jpskenn, 2022-04-09:
EEPROMに余裕があることと、
ファームウェアの改変なしにさまざまな状況に対応できるようにしておくと便利そうなので、
レイヤー数を7から10へ拡大する。

LEDインジケータは、色を細かく設定しても見分けがつきにくいため、無色のレイヤーを用意しておく。
これにより、インジケータなしで使いたいという場合に対応する。
（QMKでインジケータをOFFにするキーコードは用意するが、これはすべてのインジケータを無効化するものである）

1. Base: 日本語、Win用Mod、LED無色
1. Base: 英語、Win用Mod、LED青
1. Base: 英語、SemiErgo、Win用Mod、LED黄色
1. Lower、LED緑
1. Raise、LEDシアン
1. Func、LED白
1. 予備1、LED無色
1. 予備2、LED無色
1. 予備3、LED無色
1. Adjust、LED赤

これ以外に、CAPSで左LEDマゼンタ。

jpskenn, 2022-04-09:
FullとFWレイアウトの対応完了
2d78d9490de0694e9c9a7bcb2808bcdcb731bd18

jpskenn, 2022-04-10:
REレイアウトの対応完了
https://github.com/jpskenn/qmk_firmware/commit/c7542b5204f8141aea38aef31a1f742b93fc2224

基本的なところは完了したのでクローズする

Closed 2022-04-10.

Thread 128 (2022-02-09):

DN0032-QMK: Move `FNx` keycodes to KB level

jpskenn, 2022-02-09:
v031試作版で、viaとvia_reに入れておいた`FNx`キーコードの機能を、
今後はKBレベルに移動して、コードを1箇所にまとめる。

jpskenn, 2022-02-11:
versionとインジケータON/OFFは移動しても良いが、
デフォルトレイヤーのEEPROMあり切り替えは、外へ出しにくい。

jpskenn, 2022-04-10:
QMKの、2022年2月のBreaking Changeで、FNxキーコードがCoreから削除された。
https://docs.qmk.fm/#/ChangeLog/20220226
https://github.com/qmk/qmk_firmware/pull/16025

そのため、KC_FN0とかが使えなくなってしまったため、他の方法を検討する必要がある。

jpskenn, 2022-04-10:
> QMKの、2022年2月のBreaking Changeで、FNxキーコードがCoreから削除された。 https://docs.qmk.fm/#/ChangeLog/20220226 [qmk/qmk_firmware#16025](https://github.com/qmk/qmk_firmware/pull/16025)
>
> そのため、KC_FN0とかが使えなくなってしまったため、他の方法を検討する必要がある。

対応した
https://github.com/jpskenn/qmk_firmware/commit/a8e6980d92612d88011ac5fba1cec31aa3875244

jpskenn, 2022-04-10:
KBレベルへの移動については、分量が少ないため見送り

Closed 2022-04-10.

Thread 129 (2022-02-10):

DN0031-SWplate: Order to alternative PCB fab

jpskenn, 2022-02-10:
JLCPCBでスイッチプレートに追加料金がかかるのがつらいので、他の業者をあたってみる。
- 値段
  基本料金はJLCPCBより高くても、追加料金なしで安ければよい）
- 色味
  基板はJLCPCBで作るが、その色に合うか？

基板は青で作る予定。
スイッチプレートは、基本的に青。
もしくは黒かも？

jpskenn, 2022-02-13:
他社発注向け、JLCJLCJLCなし版を作る

jpskenn, 2022-02-13:
作った。ecbc4cb555a4784a66d24a5220261153aeeeec39

jpskenn, 2022-02-13:
ALLPCBへ発注した。

到着後、
- 基板の色味
- 製造番号のプリント位置（発注時に裏面にしてとのお願いはした）
- その他、品質など
をチェック予定。

jpskenn, 2022-03-06:
ALLPCBのプレートの印象。
- 色味はJLCPCBと同系統で問題ない
- 注文時のコメントに書いたが、オーダー番号は裏面に印刷されたのでよし。
- 追加料金なし

これでOKとする。

Closed 2022-03-06.

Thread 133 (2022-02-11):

DN0031-SWPlate: FULL layout

jpskenn, 2022-02-11:
フルキーのレイアウトも用意する？
https://twitter.com/illness072/status/1491963852136742913

jpskenn, 2022-02-11:
変更、追加作業

- ハード
  - プレート作る（FWとかからの流用）
  - 基板は、ほぼそのまま。センターの枠なしソケットを、枠ありにするとか。
- ドキュメント整備
- ソフト
  - QMK。だいたいできてる
  - ~Remap。レイアウト追加。~ →すでにJSONに登録済み。

jpskenn, 2022-02-11:
問題というか、気持ち的なところで、
「FULLレイアウト作っても、自分はFULLを使わないだろう」
という点。
DN0030でセンターのキーをまったく使っていなかったので。

jpskenn, 2022-02-11:
e3f69c1e32efd6c93909ec89233b51bb5e333343

Closed 2022-02-11.

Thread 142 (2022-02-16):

DN0032-QMK: Add function to toggle base layer indicator.

jpskenn, 2022-02-16:
ベースレイヤーのインジケータだけON/OFFする機能。
Base1は消灯してあるが、2、3がエフェクトと別の色で嫌なとき用。

jpskenn, 2022-02-17:
https://github.com/jpskenn/qmk_firmware/commit/dd40408b2c45eafd9dde50fb6da4b9c0b222aa1f

Closed 2022-02-17.

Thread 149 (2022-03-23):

DN0032-QMK: Test startup delay for LED

jpskenn, 2022-03-23:
LEDチラつきに、ディレイが効果あるか試す。

jpskenn, 2022-04-07:
keyboard_pre_init_kbで
500ms
1000ms
のwaitを試したが、USBケーブル接続時のLEDチラつきには効果なし。

jpskenn, 2022-04-07:
現時点では影響が低いため、ペンディングとする。

jpskenn, 2022-04-18:
キーボード起動後、keyboard_post_init_kbにて、

1. EEPROMへの書き込みなしで、LEDを黒色にセット（＝消灯）
2. 200msのwait
3. EEPROMからLEDのモードを読み込み直す（＝電源が切れる前のエフェクトで点灯、もしくは電源が切れる前に消灯だったときは消灯）

という処理をおこなって、対応。

https://github.com/jpskenn/qmk_firmware/commit/618294937842d9f5aaca3dd98d9bb4103af2316d

Closed 2022-04-18.

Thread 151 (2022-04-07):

DN0032-PCB: Test PICO w/ATmega onboard

jpskenn, 2022-04-07:

jpskenn, 2022-04-07:
ATmegaがオンボードについた状態で、PICOつけてテスト。
ジャンパ、LEDについても。

jpskenn, 2022-04-14:
PICOテスト完了。
PRK Firmware
5868129a6229ab5db8c033501526897bb459105e

- ATmegaオンボードで電源ジャンパをPICO VBUSへ切り替えて、PICOで入力OK。
  →ATmegaは動いていない（オンボードUSBにケーブル挿しても動作せず。期待通り）

- LEDは1行目の16個で点灯を確認
  ファームウェアでキーボード起動時のLEDの明るさを下げられない（どうやるのかわからん）ため、全部つけると消費電力がやばそうな気がした。

- PCBに取り付けるピンヘッダとスイッチソケットのクリアランスがシビア
  2.5mm幅のピンヘッダ（またはピンソケット）ならOKなので、これでよし

Closed 2022-04-14.

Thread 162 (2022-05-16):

DN0033-PCB: Add bypass route to LED on L-SPC and R-SPC

jpskenn, 2022-05-16:
左右スペース部分のLEDに、迂回ルート（FWとかREで未使用LEDを飛ばすやつ）を用意する。
- 左右スペースのスイッチを上下間違えて取り付けようとして、LEDをパッドごとやってしまったときの救済
- スペースキーに透過レジェンドがないから、LEDを仕込みたくない
といった場合に対応する。

これをやるとインジケータLEDのindexが変わる。
というか、元々インジケータとして想定していた場所がなくなる。
→ファームウェアの対応も必要
→インジケータを、元々、別の場所にしておく？

Closed 2022-05-16.

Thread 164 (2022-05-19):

DN0033-SW_Plate: White plate.

jpskenn, 2022-05-19:
ホワイトのシートを貼ったスイッチプレートが、なかなか良い。
参考
https://twitter.com/HajimeOhyake/status/1527255864184217600

ケースに入れないと、プレートだけホワイトにすると浮いてしまうので、全部ホワイトにするか？
そうすると、PCBのLED反射用シルクを消さないといけない。

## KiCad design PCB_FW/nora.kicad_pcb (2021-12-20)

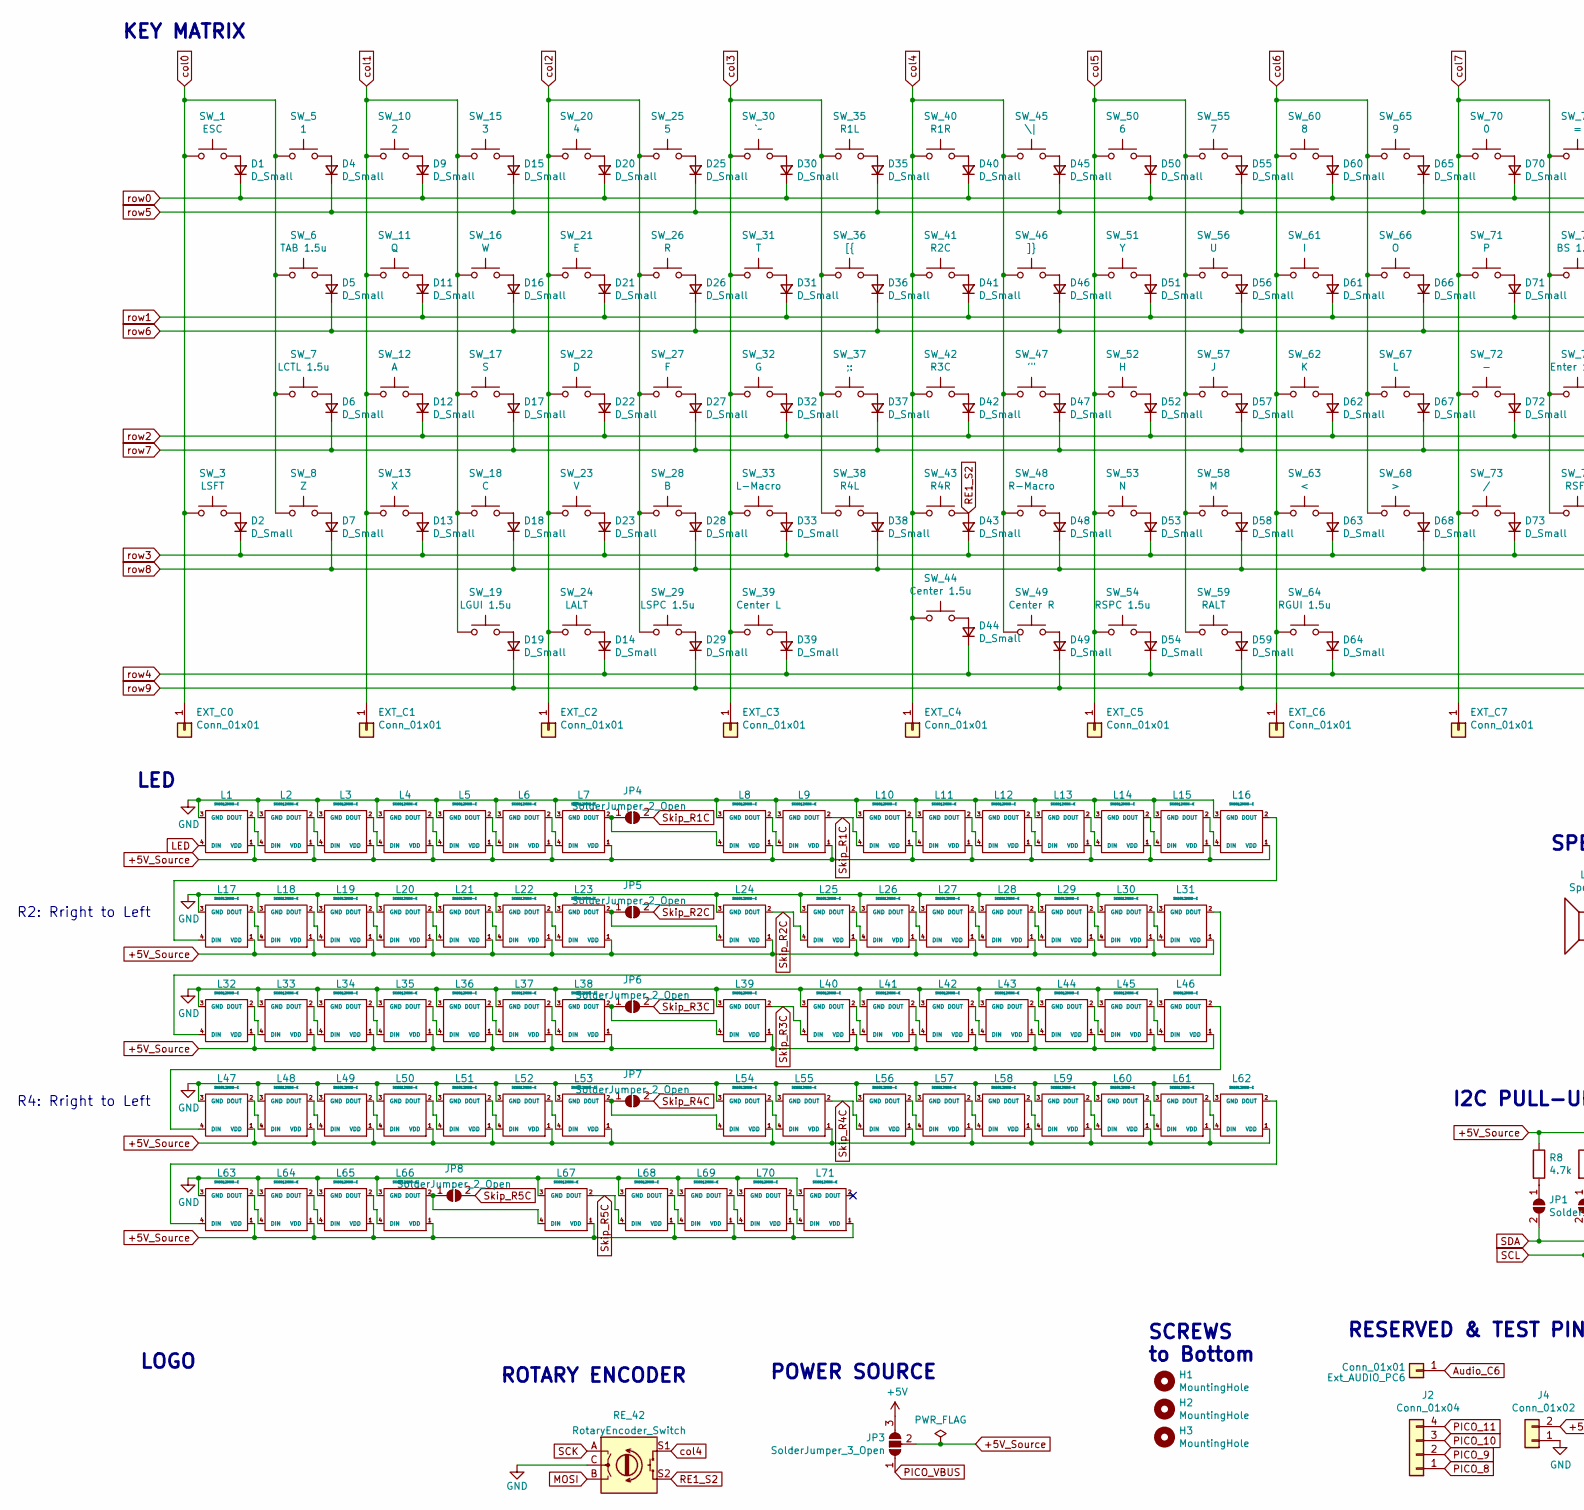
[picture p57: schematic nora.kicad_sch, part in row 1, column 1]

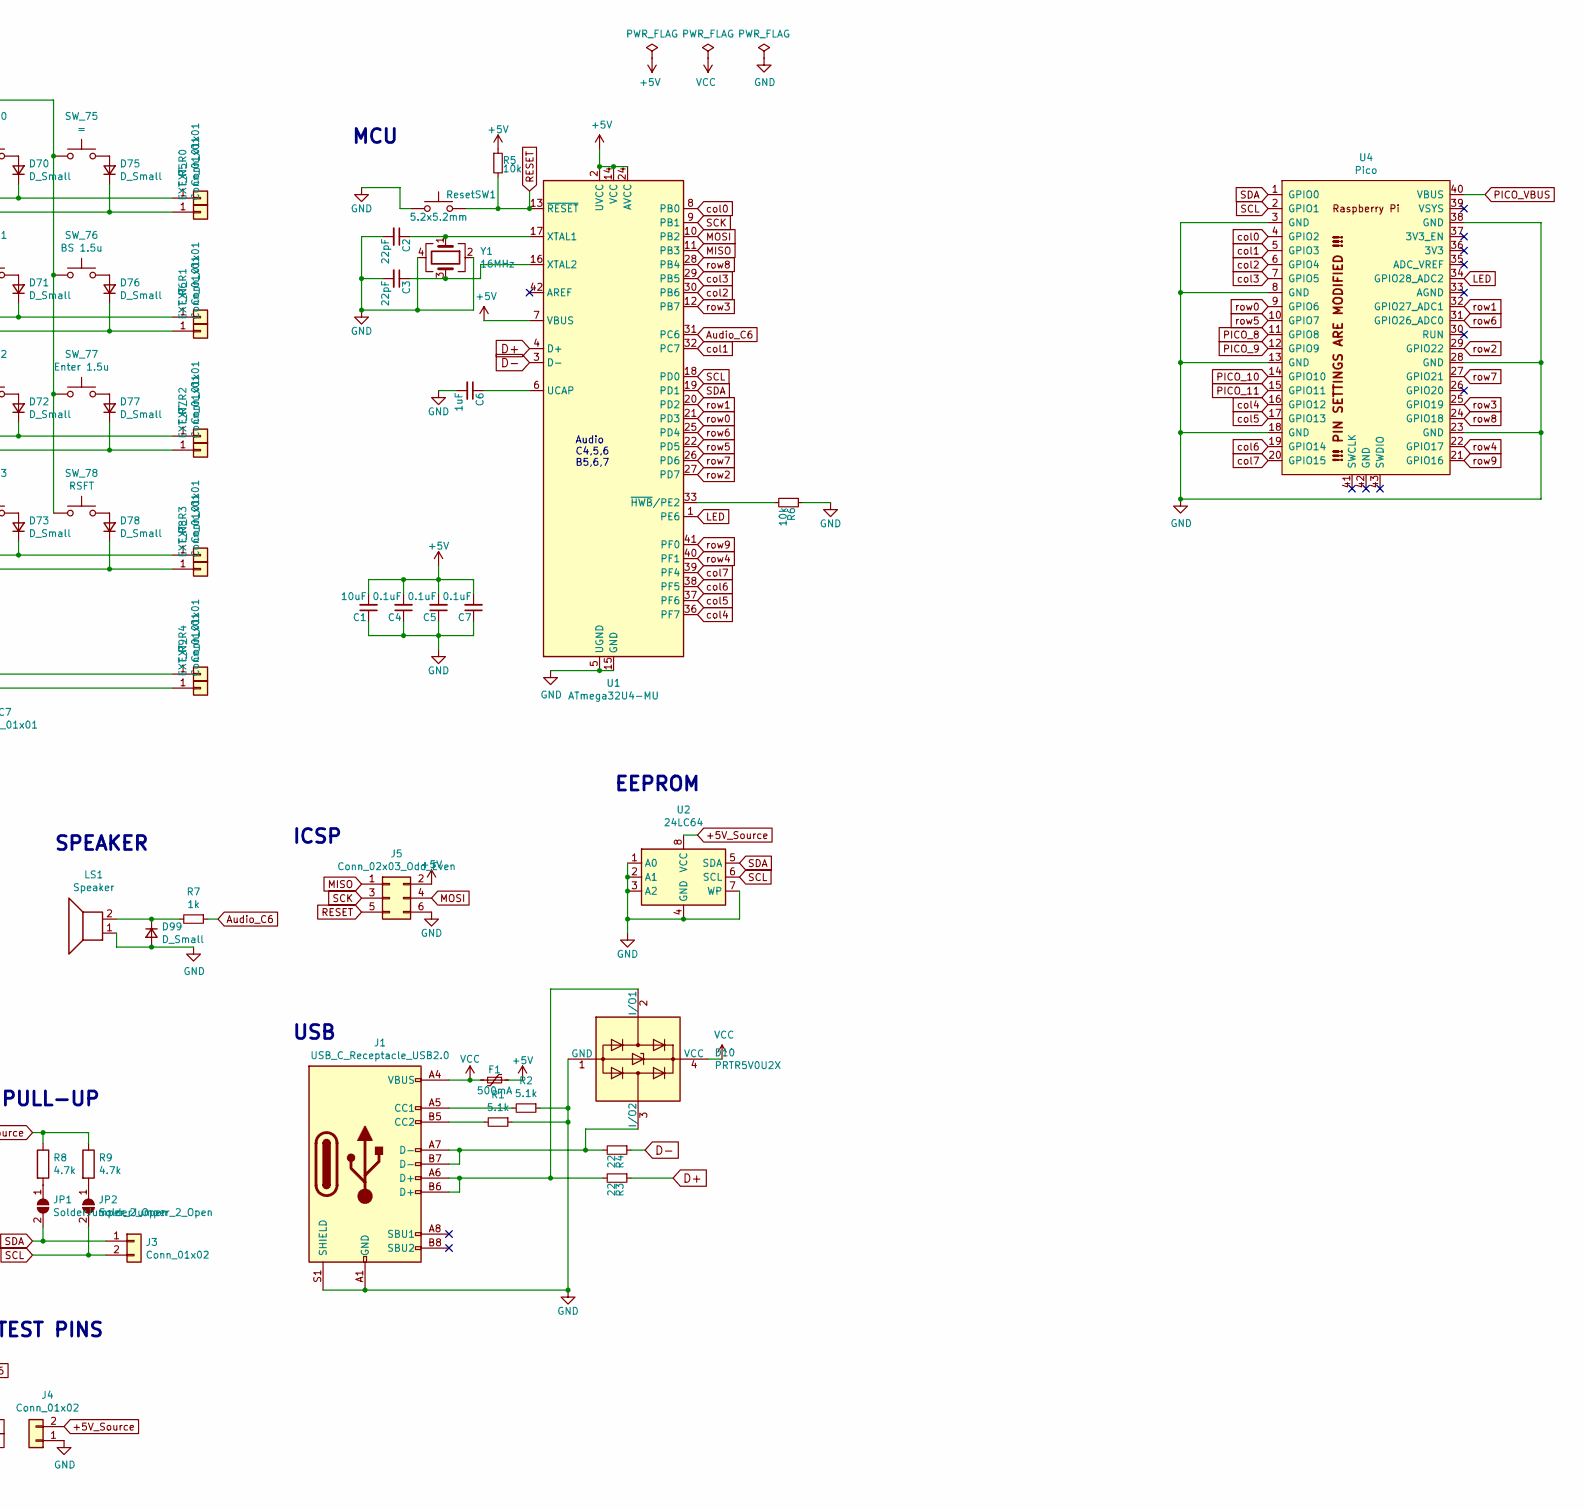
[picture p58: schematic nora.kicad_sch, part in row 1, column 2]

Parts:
C1: 10uF; C_0805_2012Metric_Pad1.18x1.45mm_HandSolder; LCSC C2922480
C2, C3: 22pF; C_0805_2012Metric_Pad1.18x1.45mm_HandSolder; LCSC C1804
C4, C5, C7: 0.1uF; C_0805_2012Metric_Pad1.18x1.45mm_HandSolder; LCSC C49678
C6: 1uF; C_0805_2012Metric_Pad1.18x1.45mm_HandSolder; LCSC C28323
D1, D2, D4, D5, D6, D7, D9, D11, D12, D13, D14, D15, D16, D17, D18, D19, D20, D21, D22, D23, D25, D26, D27, D28, D29, D30, D31, D32, D33, D35, D36, D37, D38, D39, D40, D41, D42, D43, D44, D45, D46, D47, D48, D49, D50, D51, D52, D53, D54, D55, D56, D57, D58, D59, D60, D61, D62, D63, D64, D65, D66, D67, D68, D70, D71, D72, D73, D75, D76, D77, D78, D99: D_Small; D_SOD-123-Pretty_No_Reference; LCSC C81598
D10: PRTR5V0U2X; SOT-143; LCSC C78442
EXT_C0, EXT_C1, EXT_C2, EXT_C3, EXT_C4, EXT_C5, EXT_C6, EXT_C7: Conn_01x01; TestPoint_THTPad_D1.5mm_Drill0.7mm
EXT_R0, EXT_R1, EXT_R2, EXT_R3, EXT_R4, EXT_R5, EXT_R6, EXT_R7, EXT_R8, EXT_R9: Conn_01x01; TestPoint_THTPad_D1.5mm_Drill0.7mm
Ext_AUDIO_PC6: Conn_01x01; TestPoint_THTPad_D1.0mm_Drill0.5mm
F1: 500mA; Fuse_1206_3216Metric_Pad1.42x1.75mm_HandSolder; LCSC C70076
H1, H2, H3: MountingHole; MountingHole_2.2mm_M2
J1: USB_C_Receptacle_USB2.0; USB_C_Receptacle_GCT_USB4085
J2: Conn_01x04; PinHeader_1x04_P2.54mm_Vertical
J3, J4: Conn_01x02; PinHeader_1x02_P2.54mm_Vertical
J5: Conn_02x03_Odd_Even; PinHeader_2x03_P2.54mm_Vertical
JP1, JP2, JP4, JP5, JP6, JP7, JP8: SolderJumper_2_Open; SolderJumper-2_P1.3mm_Open_RoundedPad1.0x1.5mm
JP3: SolderJumper_3_Open; SolderJumper-3_P1.3mm_Open_RoundedPad1.0x1.5mm
L1, L2, L3, L4, L5, L6, L7, L8, L9, L10, L11, L12, L13, L14, L15, L16, L17, L18, L19, L20, L21, L22, L23, L24, L25, L26, L27, L28, L29, L30, L31, L32, L33, L34, L35, L36, L37, L38, L39, L40, L41, L42, L43, L44, L45, L46, L47, L48, L49, L50, L51, L52, L53, L54, L55, L56, L57, L58, L59, L60, L61, L62, L63, L64, L65, L66, L67, L68, L69, L70, L71: SK6812MINI-E; YS-SK6812MINI-E_large_hole_with_small_pad
LS1: Speaker; Buzzer_Murata_PKMCS0909E4000-R1
R1, R2: 5.1k; R_0805_2012Metric_Pad1.20x1.40mm_HandSolder; LCSC C27834
R3, R4: 22; R_0805_2012Metric_Pad1.20x1.40mm_HandSolder; LCSC C17561
R5, R6: 10k; R_0805_2012Metric_Pad1.20x1.40mm_HandSolder; LCSC C17414
R7: 1k; R_0805_2012Metric_Pad1.20x1.40mm_HandSolder; LCSC C17513
R8, R9: 4.7k; R_0805_2012Metric_Pad1.20x1.40mm_HandSolder; LCSC C17673
RE_42: RotaryEncoder_Switch; RotaryEncoder_Alps_EC11E-Switch_Vertical_H20mm
ResetSW1: 5.2x5.2mm; SW_SPST_TL3342
SW_1: ESC; Kailh-PG1350-1u-MBK-WithKeyName-Socket-ForLeftEdge-1.8mm-ho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
SW_3: LSFT; Kailh-PG1350-1u-MBK-WithKeyName-Socket-ForLeftEdge-1.8mm-ho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
SW_5: 1; Kailh-PG1350-1u-MBK-WithKeyName-Socket-1.8mm-hole-reflection
SW_6: TAB 1.5u; Kailh-PG1350-1.5u-MBK-WithKeyName-Socket-1.8mm-hole-reflect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
SW_7: LCTL 1.5u; Kailh-PG1350-1.5u-MBK-WithKeyName-Socket-1.8mm-hole-reflect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
SW_8: Z; Kailh-PG1350-1u-MBK-WithKeyName-Socket-1.8mm-hole-reflection
SW_10: 2; Kailh-PG1350-1u-MBK-WithKeyName-Socket-1.8mm-hole-reflection
SW_11: Q; Kailh-PG1350-1u-MBK-WithKeyName-Socket-1.8mm-hole-reflection
SW_12: A; Kailh-PG1350-1u-MBK-WithKeyName-Socket-1.8mm-hole-reflection
SW_13: X; Kailh-PG1350-1u-MBK-WithKeyName-Socket-1.8mm-hole-reflection
SW_15: 3; Kailh-PG1350-1u-MBK-WithKeyName-Socket-1.8mm-hole-reflection
SW_16: W; Kailh-PG1350-1u-MBK-WithKeyName-Socket-1.8mm-hole-reflection
SW_17: S; Kailh-PG1350-1u-MBK-WithKeyName-Socket-1.8mm-hole-reflection
SW_18: C; Kailh-PG1350-1u-MBK-WithKeyName-Socket-1.8mm-hole-reflection
SW_19: LGUI 1.5u; Kailh-PG1350-1.5u-MBK-WithKeyName-Socket-1.8mm-hole-reflect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
SW_20: 4; Kailh-PG1350-1u-MBK-WithKeyName-Socket-1.8mm-hole-reflection
SW_21: E; Kailh-PG1350-1u-MBK-WithKeyName-Socket-1.8mm-hole-reflection
SW_22: D; Kailh-PG1350-1u-MBK-WithKeyName-Socket-1.8mm-hole-reflection
SW_23: V; Kailh-PG1350-1u-MBK-WithKeyName-Socket-1.8mm-hole-reflection
SW_24: LALT; Kailh-PG1350-1u-MBK-WithKeyName-Socket-1.8mm-hole-reflection
SW_25: 5; Kailh-PG1350-1u-MBK-WithKeyName-Socket-1.8mm-hole-reflection
SW_26: R; Kailh-PG1350-1u-MBK-WithKeyName-Socket-1.8mm-hole-reflection
SW_27: F; Kailh-PG1350-1u-MBK-WithKeyName-Socket-1.8mm-hole-reflection
SW_28: B; Kailh-PG1350-1u-MBK-WithKeyName-Socket-1.8mm-hole-reflection
SW_29: LSPC 1.5u; Kailh-PG1350-1.5u-MBK-WithKeyName-Socket-1.8mm-hole-reflect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
SW_30: `~; Kailh-PG1350-1u-MBK-WithKeyName-Socket-1.8mm-hole-reflection
SW_31: T; Kailh-PG1350-1u-MBK-WithKeyName-Socket-1.8mm-hole-reflection
SW_32: G; Kailh-PG1350-1u-MBK-WithKeyName-Socket-1.8mm-hole-reflection
SW_33: L-Macro; Kailh-PG1350-1u-MBK-WithKeyName-Socket-1.8mm-hole-reflection
SW_35: R1L; Kailh-PG1350-1u-MBK-WithKeyName-Socket-1.8mm-hole-reflectio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
SW_36: [{; Kailh-PG1350-1u-MBK-WithKeyName-Socket-1.8mm-hole-reflection
SW_37: ;:; Kailh-PG1350-1u-MBK-WithKeyName-Socket-1.8mm-hole-reflection
SW_38: R4L; Kailh-PG1350-1u-MBK-WithKeyName-Socket-1.8mm-hole-reflectio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
SW_39: Center L; Kailh-PG1350-1u-MBK-WithKeyName-Socket-1.8mm-hole-reflection
SW_40: R1R; Kailh-PG1350-1u-MBK-WithKeyName-Socket-1.8mm-hole-reflectio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
SW_41: R2C; Kailh-PG1350-1u-MBK-WithKeyName-Socket-1.8mm-hole-reflectio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
SW_42: R3C; Kailh-PG1350-1u-MBK-WithKeyName-Socket-1.8mm-hole-reflectio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
SW_43: R4R; Kailh-PG1350-1u-MBK-WithKeyName-Socket-1.8mm-hole-reflectio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
SW_44: Center 1.5u; Kailh-PG1350-1.5u-MBK-WithKeyName-Socket-1.8mm-hole-reflect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
SW_45: \|; Kailh-PG1350-1u-MBK-WithKeyName-Socket-1.8mm-hole-reflection
SW_46: ]}; Kailh-PG1350-1u-MBK-WithKeyName-Socket-1.8mm-hole-reflection
SW_47: '"; Kailh-PG1350-1u-MBK-WithKeyName-Socket-1.8mm-hole-reflection
SW_48: R-Macro; Kailh-PG1350-1u-MBK-WithKeyName-Socket-1.8mm-hole-reflection
SW_49: Center R; Kailh-PG1350-1u-MBK-WithKeyName-Socket-1.8mm-hole-reflection
SW_50: 6; Kailh-PG1350-1u-MBK-WithKeyName-Socket-1.8mm-hole-reflection
SW_51: Y; Kailh-PG1350-1u-MBK-WithKeyName-Socket-1.8mm-hole-reflection
SW_52: H; Kailh-PG1350-1u-MBK-WithKeyName-Socket-1.8mm-hole-reflection
SW_53: N; Kailh-PG1350-1u-MBK-WithKeyName-Socket-1.8mm-hole-reflection
SW_54: RSPC 1.5u; Kailh-PG1350-1.5u-MBK-WithKeyName-Socket-1.8mm-hole-reflect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
SW_55: 7; Kailh-PG1350-1u-MBK-WithKeyName-Socket-1.8mm-hole-reflection
SW_56: U; Kailh-PG1350-1u-MBK-WithKeyName-Socket-1.8mm-hole-reflection
SW_57: J; Kailh-PG1350-1u-MBK-WithKeyName-Socket-1.8mm-hole-reflection
SW_58: M; Kailh-PG1350-1u-MBK-WithKeyName-Socket-1.8mm-hole-reflection
SW_59: RALT; Kailh-PG1350-1u-MBK-WithKeyName-Socket-1.8mm-hole-reflection
SW_60: 8; Kailh-PG1350-1u-MBK-WithKeyName-Socket-1.8mm-hole-reflection
SW_61: I; Kailh-PG1350-1u-MBK-WithKeyName-Socket-1.8mm-hole-reflection
SW_62: K; Kailh-PG1350-1u-MBK-WithKeyName-Socket-1.8mm-hole-reflection
SW_63: <; Kailh-PG1350-1u-MBK-WithKeyName-Socket-1.8mm-hole-reflection
SW_64: RGUI 1.5u; Kailh-PG1350-1.5u-MBK-WithKeyName-Socket-1.8mm-hole-reflect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
SW_65: 9; Kailh-PG1350-1u-MBK-WithKeyName-Socket-1.8mm-hole-reflection
SW_66: O; Kailh-PG1350-1u-MBK-WithKeyName-Socket-1.8mm-hole-reflection
SW_67: L; Kailh-PG1350-1u-MBK-WithKeyName-Socket-1.8mm-hole-reflection
SW_68: >; Kailh-PG1350-1u-MBK-WithKeyName-Socket-1.8mm-hole-reflection
SW_70: 0; Kailh-PG1350-1u-MBK-WithKeyName-Socket-1.8mm-hole-reflection
SW_71: P; Kailh-PG1350-1u-MBK-WithKeyName-Socket-1.8mm-hole-reflection
SW_72: -; Kailh-PG1350-1u-MBK-WithKeyName-Socket-1.8mm-hole-reflection
SW_73: /; Kailh-PG1350-1u-MBK-WithKeyName-Socket-1.8mm-hole-reflection
SW_75: =; Kailh-PG1350-1u-MBK-WithKeyName-Socket-1.8mm-hole-reflection
SW_76: BS 1.5u; Kailh-PG1350-1.5u-MBK-WithKeyName-Socket-1.8mm-hole-reflect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
SW_77: Enter 1.5u; Kailh-PG1350-1.5u-MBK-WithKeyName-Socket-1.8mm-hole-reflect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
SW_78: RSFT; Kailh-PG1350-1u-MBK-WithKeyName-Socket-1.8mm-hole-reflection
U1: ATmega32U4-MU; QFN-44-1EP_7x7mm_P0.5mm_EP5.15x5.15mm; LCSC C45874
U2: 24LC64; SO-8_3.9x4.9mm_P1.27mm; LCSC C79988
U4: Pico; RPi_Pico_TH_no_NPTH_SWD_less_Silk_NoCrtYd
Y1: 16MHz; Crystal_SMD_3225-4Pin_3.2x2.5mm_HandSoldering; LCSC C13738

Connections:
+5V: C1.2, C4.2, C5.2, C7.2, F1.1, J5.2, JP3.3 (B), R5.1, U1.2 (UVCC), U1.7 (VBUS), U1.14 (VCC), U1.24 (AVCC), U1.34 (VCC), U1.44 (AVCC)
+5V_Source: J4.2, JP3.2 (C), L1.1 (VDD), L2.1 (VDD), L3.1 (VDD), L4.1 (VDD), L5.1 (VDD), L6.1 (VDD), L7.1 (VDD), L8.1 (VDD), L9.1 (VDD), L10.1 (VDD), L11.1 (VDD), L12.1 (VDD), L13.1 (VDD), L14.1 (VDD), L15.1 (VDD), L16.1 (VDD), L17.1 (VDD), L18.1 (VDD), L19.1 (VDD), L20.1 (VDD), L21.1 (VDD), L22.1 (VDD), L23.1 (VDD), L24.1 (VDD), L25.1 (VDD), L26.1 (VDD), L27.1 (VDD), L28.1 (VDD), L29.1 (VDD), L30.1 (VDD), L31.1 (VDD), L32.1 (VDD), L33.1 (VDD), L34.1 (VDD), L35.1 (VDD), L36.1 (VDD), L37.1 (VDD), L38.1 (VDD), L39.1 (VDD), L40.1 (VDD), L41.1 (VDD), L42.1 (VDD), L43.1 (VDD), L44.1 (VDD), L45.1 (VDD), L46.1 (VDD), L47.1 (VDD), L48.1 (VDD), L49.1 (VDD), L50.1 (VDD), L51.1 (VDD), L52.1 (VDD), L53.1 (VDD), L54.1 (VDD), L55.1 (VDD), L56.1 (VDD), L57.1 (VDD), L58.1 (VDD), L59.1 (VDD), L60.1 (VDD), L61.1 (VDD), L62.1 (VDD), L63.1 (VDD), L64.1 (VDD), L65.1 (VDD), L66.1 (VDD), L67.1 (VDD), L68.1 (VDD), L69.1 (VDD), L70.1 (VDD), L71.1 (VDD), R8.1, R9.1, U2.8 (VCC)
D+: R3.1, U1.4 (D+)
D-: R4.1, U1.3 (D-)
GND: C1.1, C2.2, C3.2, C4.1, C5.1, C6.2, C7.1, D10.1 (GND), D99.2 (A), J1.A1 (GND), J1.A12 (GND), J1.B1 (GND), J1.B12 (GND), J1.S1 (SHIELD), J4.1, J5.6, L1.3 (GND), L2.3 (GND), L3.3 (GND), L4.3 (GND), L5.3 (GND), L6.3 (GND), L7.3 (GND), L8.3 (GND), L9.3 (GND), L10.3 (GND), L11.3 (GND), L12.3 (GND), L13.3 (GND), L14.3 (GND), L15.3 (GND), L16.3 (GND), L17.3 (GND), L18.3 (GND), L19.3 (GND), L20.3 (GND), L21.3 (GND), L22.3 (GND), L23.3 (GND), L24.3 (GND), L25.3 (GND), L26.3 (GND), L27.3 (GND), L28.3 (GND), L29.3 (GND), L30.3 (GND), L31.3 (GND), L32.3 (GND), L33.3 (GND), L34.3 (GND), L35.3 (GND), L36.3 (GND), L37.3 (GND), L38.3 (GND), L39.3 (GND), L40.3 (GND), L41.3 (GND), L42.3 (GND), L43.3 (GND), L44.3 (GND), L45.3 (GND), L46.3 (GND), L47.3 (GND), L48.3 (GND), L49.3 (GND), L50.3 (GND), L51.3 (GND), L52.3 (GND), L53.3 (GND), L54.3 (GND), L55.3 (GND), L56.3 (GND), L57.3 (GND), L58.3 (GND), L59.3 (GND), L60.3 (GND), L61.3 (GND), L62.3 (GND), L63.3 (GND), L64.3 (GND), L65.3 (GND), L66.3 (GND), L67.3 (GND), L68.3 (GND), L69.3 (GND), L70.3 (GND), L71.3 (GND), LS1.1, R1.1, R2.1, R6.1, RE_42.C, ResetSW1.1, U1.5 (UGND), U1.15 (GND), U1.23 (GND), U1.35 (GND), U1.43 (GND), U1.45 (GND), U2.1 (A0), U2.2 (A1), U2.3 (A2), U2.4 (GND), U2.7 (WP), U4.3 (GND), U4.8 (GND), U4.13 (GND), U4.18 (GND), U4.23 (GND), U4.28 (GND), U4.38 (GND), Y1.2, Y1.4
LED: L1.4 (DIN), U1.1 (PE6), U4.34 (GPIO28_ADC2)
LEDtoR5: JP4.3, L62.2 (DOUT), L63.4 (DIN)
MISO: J5.1, U1.11 (PB3)
MOSI: J5.4, RE_42.B, U1.10 (PB2)
unnamed: C2.1, U1.17 (XTAL1), Y1.1
unnamed: C3.1, U1.16 (XTAL2), Y1.3
unnamed: C6.1, U1.6 (UCAP)
unnamed: D1.2 (A), SW_1.2
unnamed: D2.2 (A), SW_3.2
unnamed: D4.2 (A), SW_5.2
unnamed: D5.2 (A), SW_6.2
unnamed: D6.2 (A), SW_7.2
unnamed: D7.2 (A), SW_8.2
unnamed: D9.2 (A), SW_10.2
unnamed: D10.2 (I/O1), J1.A6 (D+), J1.B6 (D+), R3.2
unnamed: D10.3 (I/O2), J1.A7 (D-), J1.B7 (D-), R4.2
unnamed: D11.2 (A), SW_11.2
unnamed: D12.2 (A), SW_12.2
unnamed: D13.2 (A), SW_13.2
unnamed: D14.2 (A), SW_24.2
unnamed: D15.2 (A), SW_15.2
unnamed: D16.2 (A), SW_16.2
unnamed: D17.2 (A), SW_17.2
unnamed: D18.2 (A), SW_18.2
unnamed: D19.2 (A), SW_19.2
unnamed: D20.2 (A), SW_20.2
unnamed: D21.2 (A), SW_21.2
unnamed: D22.2 (A), SW_22.2
unnamed: D23.2 (A), SW_23.2
unnamed: D25.2 (A), SW_25.2
unnamed: D26.2 (A), SW_26.2
unnamed: D27.2 (A), SW_27.2
unnamed: D28.2 (A), SW_28.2
unnamed: D29.2 (A), SW_29.2
unnamed: D30.2 (A), SW_30.2
unnamed: D31.2 (A), SW_31.2
unnamed: D32.2 (A), SW_32.2
unnamed: D33.2 (A), SW_33.2
unnamed: D35.2 (A), SW_35.2
unnamed: D36.2 (A), SW_36.2
unnamed: D37.2 (A), SW_37.2
unnamed: D38.2 (A), SW_38.2
unnamed: D39.2 (A), SW_39.2
unnamed: D40.2 (A), SW_40.2
unnamed: D41.2 (A), SW_41.2
unnamed: D42.2 (A), SW_42.2
unnamed: D43.2 (A), RE_42.S2, SW_43.2
unnamed: D45.2 (A), SW_45.2
unnamed: D46.2 (A), SW_46.2
unnamed: D47.2 (A), SW_47.2
unnamed: D48.2 (A), SW_48.2
unnamed: D49.2 (A), SW_49.2
unnamed: D50.2 (A), SW_50.2
unnamed: D51.2 (A), SW_51.2
unnamed: D52.2 (A), SW_52.2
unnamed: D53.2 (A), SW_53.2
unnamed: D54.2 (A), SW_54.2
unnamed: D55.2 (A), SW_55.2
unnamed: D56.2 (A), SW_56.2
unnamed: D57.2 (A), SW_57.2
unnamed: D58.2 (A), SW_58.2
unnamed: D59.2 (A), SW_59.2
unnamed: D60.2 (A), SW_60.2
unnamed: D61.2 (A), SW_61.2
unnamed: D62.2 (A), SW_62.2
unnamed: D63.2 (A), SW_63.2
unnamed: D64.2 (A), SW_64.2
unnamed: D65.2 (A), SW_65.2
unnamed: D66.2 (A), SW_66.2
unnamed: D67.2 (A), SW_67.2
unnamed: D68.2 (A), SW_68.2
unnamed: D70.2 (A), SW_70.2
unnamed: D71.2 (A), SW_71.2
unnamed: D72.2 (A), SW_72.2
unnamed: D73.2 (A), SW_73.2
unnamed 80: D44.2 (A), SW_44.2; also elsewhere on the board
unnamed: D75.2 (A), SW_75.2
unnamed: D76.2 (A), SW_76.2
unnamed: D77.2 (A), SW_77.2
unnamed: D78.2 (A), SW_78.2
unnamed: D99.1 (K), LS1.2, R7.2
unnamed: J1.A5 (CC1), R2.2
unnamed: J1.B5 (CC2), R1.2
unnamed: JP1.1 (A), R8.2
unnamed: JP2.1 (A), R9.2
unnamed: L1.2 (DOUT), L2.4 (DIN)
unnamed: L2.2 (DOUT), L3.4 (DIN)
unnamed: L3.2 (DOUT), L4.4 (DIN)
unnamed: L4.2 (DOUT), L5.4 (DIN)
unnamed: L5.2 (DOUT), L6.4 (DIN)
unnamed: L6.2 (DOUT), L7.4 (DIN)
unnamed: L8.2 (DOUT), L9.4 (DIN)
unnamed: L10.2 (DOUT), L11.4 (DIN)
unnamed: L11.2 (DOUT), L12.4 (DIN)
unnamed: L12.2 (DOUT), L13.4 (DIN)
unnamed: L13.2 (DOUT), L14.4 (DIN)
unnamed: L14.2 (DOUT), L15.4 (DIN)
unnamed: L15.2 (DOUT), L16.4 (DIN)
unnamed: L17.2 (DOUT), L18.4 (DIN)
unnamed: L18.2 (DOUT), L19.4 (DIN)
unnamed: L19.2 (DOUT), L20.4 (DIN)
unnamed: L20.2 (DOUT), L21.4 (DIN)
unnamed: L21.2 (DOUT), L22.4 (DIN)
unnamed: L22.2 (DOUT), L23.4 (DIN)
unnamed: JP5.1 (A), L23.2 (DOUT), L24.4 (DIN)
unnamed: JP5.2 (B), L24.2 (DOUT), L25.4 (DIN)
unnamed: L25.2 (DOUT), L26.4 (DIN)
unnamed: L26.2 (DOUT), L27.4 (DIN)
unnamed: L27.2 (DOUT), L28.4 (DIN)
unnamed: L28.2 (DOUT), L29.4 (DIN)
unnamed: L29.2 (DOUT), L30.4 (DIN)
unnamed: L30.2 (DOUT), L31.4 (DIN)
unnamed: L31.2 (DOUT), L32.4 (DIN)
unnamed: L32.2 (DOUT), L33.4 (DIN)
unnamed: L33.2 (DOUT), L34.4 (DIN)
unnamed: L34.2 (DOUT), L35.4 (DIN)
unnamed: L35.2 (DOUT), L36.4 (DIN)
unnamed: L36.2 (DOUT), L37.4 (DIN)
unnamed: L37.2 (DOUT), L38.4 (DIN)
unnamed: JP6.1 (A), L38.2 (DOUT), L39.4 (DIN)
unnamed: JP6.2 (B), L39.2 (DOUT), L40.4 (DIN)
unnamed: L40.2 (DOUT), L41.4 (DIN)
unnamed: L41.2 (DOUT), L42.4 (DIN)
unnamed: L42.2 (DOUT), L43.4 (DIN)
unnamed: L43.2 (DOUT), L44.4 (DIN)
unnamed: L44.2 (DOUT), L45.4 (DIN)
unnamed: L45.2 (DOUT), L46.4 (DIN)
unnamed: L46.2 (DOUT), L47.4 (DIN)
unnamed: L47.2 (DOUT), L48.4 (DIN)
unnamed: L48.2 (DOUT), L49.4 (DIN)
unnamed: L49.2 (DOUT), L50.4 (DIN)
unnamed: L50.2 (DOUT), L51.4 (DIN)
unnamed: L51.2 (DOUT), L52.4 (DIN)
unnamed: L52.2 (DOUT), L53.4 (DIN)
unnamed: JP7.1 (A), L53.2 (DOUT), L54.4 (DIN)
unnamed: L54.2 (DOUT), L55.4 (DIN)
unnamed: JP7.2 (B), L55.2 (DOUT), L56.4 (DIN)
unnamed: L56.2 (DOUT), L57.4 (DIN)
unnamed: L57.2 (DOUT), L58.4 (DIN)
unnamed: L58.2 (DOUT), L59.4 (DIN)
unnamed: L59.2 (DOUT), L60.4 (DIN)
unnamed: L60.2 (DOUT), L61.4 (DIN)
unnamed: L61.2 (DOUT), L62.4 (DIN)
unnamed: L63.2 (DOUT), L64.4 (DIN)
unnamed: L64.2 (DOUT), L65.4 (DIN)
unnamed: L65.2 (DOUT), L66.4 (DIN)
unnamed: JP8.1 (A), L66.2 (DOUT), L67.4 (DIN)
unnamed: JP8.2 (B), L67.2 (DOUT), L68.4 (DIN)
unnamed: L68.2 (DOUT), L69.4 (DIN)
unnamed: L69.2 (DOUT), L70.4 (DIN)
unnamed: L70.2 (DOUT), L71.4 (DIN)
unnamed: R6.2, U1.33 (~HWB/PE2)
PICO_8: J2.1, U4.11 (GPIO8)
PICO_9: J2.2, U4.12 (GPIO9)
PICO_10: J2.3, U4.14 (GPIO10)
PICO_11: J2.4, U4.15 (GPIO11)
PICO_VBUS: JP3.1 (A), U4.40 (VBUS)
RESET: J5.5, R5.2, ResetSW1.2, U1.13 (~RESET)
Reserve_pin: Ext_AUDIO_PC6.1, R7.1, U1.31 (PC6); also elsewhere on the board
SCK: J5.3, RE_42.A, U1.9 (PB1)
SCL: J3.2, JP2.2 (B), U1.18 (PD0), U2.6 (SCL), U4.2 (GPIO1)
SDA: J3.1, JP1.2 (B), U1.19 (PD1), U2.5 (SDA), U4.1 (GPIO0)
VCC: D10.4 (VCC), F1.2, J1.A4 (VBUS), J1.A9 (VBUS), J1.B4 (VBUS), J1.B9 (VBUS)
col0: EXT_C0.1, SW_1.1, SW_3.1, SW_5.1, SW_6.1, SW_7.1, SW_8.1, U1.8 (PB0), U4.4 (GPIO2)
col1: EXT_C1.1, SW_10.1, SW_11.1, SW_12.1, SW_13.1, SW_15.1, SW_16.1, SW_17.1, SW_18.1, SW_19.1, U1.32 (PC7), U4.5 (GPIO3)
col2: EXT_C2.1, SW_20.1, SW_21.1, SW_22.1, SW_23.1, SW_24.1, SW_25.1, SW_26.1, SW_27.1, SW_28.1, SW_29.1, U1.30 (PB6), U4.6 (GPIO4)
col3: EXT_C3.1, SW_30.1, SW_31.1, SW_32.1, SW_33.1, SW_35.1, SW_36.1, SW_37.1, SW_38.1, SW_39.1, U1.29 (PB5), U4.7 (GPIO5)
col4: EXT_C4.1, RE_42.S1, SW_40.1, SW_41.1, SW_42.1, SW_43.1, SW_44.1, SW_45.1, SW_46.1, SW_47.1, SW_48.1, SW_49.1, U1.36 (PF7), U4.16 (GPIO12)
col5: EXT_C5.1, SW_50.1, SW_51.1, SW_52.1, SW_53.1, SW_54.1, SW_55.1, SW_56.1, SW_57.1, SW_58.1, SW_59.1, U1.37 (PF6), U4.17 (GPIO13)
col6: EXT_C6.1, SW_60.1, SW_61.1, SW_62.1, SW_63.1, SW_64.1, SW_65.1, SW_66.1, SW_67.1, SW_68.1, U1.38 (PF5), U4.19 (GPIO14)
col7: EXT_C7.1, SW_70.1, SW_71.1, SW_72.1, SW_73.1, SW_75.1, SW_76.1, SW_77.1, SW_78.1, U1.39 (PF4), U4.20 (GPIO15)
row0: D1.1 (K), D9.1 (K), D20.1 (K), D30.1 (K), D40.1 (K), D50.1 (K), D60.1 (K), D70.1 (K), EXT_R0.1, U1.21 (PD3), U4.9 (GPIO6)
row1: D11.1 (K), D21.1 (K), D31.1 (K), D41.1 (K), D51.1 (K), D61.1 (K), D71.1 (K), EXT_R1.1, U1.20 (PD2), U4.32 (GPIO27_ADC1)
row2: D12.1 (K), D22.1 (K), D32.1 (K), D42.1 (K), D52.1 (K), D62.1 (K), D72.1 (K), EXT_R2.1, U1.27 (PD7), U4.29 (GPIO22)
row3: D2.1 (K), D13.1 (K), D23.1 (K), D33.1 (K), D43.1 (K), D53.1 (K), D63.1 (K), D73.1 (K), EXT_R3.1, U1.12 (PB7), U4.25 (GPIO19)
row5: D4.1 (K), D15.1 (K), D25.1 (K), D35.1 (K), D45.1 (K), D55.1 (K), D65.1 (K), D75.1 (K), EXT_R5.1, U1.22 (PD5), U4.10 (GPIO7)
row6: D5.1 (K), D16.1 (K), D26.1 (K), D36.1 (K), D46.1 (K), D56.1 (K), D66.1 (K), D76.1 (K), EXT_R6.1, U1.25 (PD4), U4.31 (GPIO26_ADC0)
row7: D6.1 (K), D17.1 (K), D27.1 (K), D37.1 (K), D47.1 (K), D57.1 (K), D67.1 (K), D77.1 (K), EXT_R7.1, U1.26 (PD6), U4.27 (GPIO21)
row8: D7.1 (K), D18.1 (K), D28.1 (K), D38.1 (K), D48.1 (K), D58.1 (K), D68.1 (K), D78.1 (K), EXT_R8.1, U1.28 (PB4), U4.24 (GPIO18)

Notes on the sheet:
KEY MATRIX
ICSP
RESERVED & TEST PINS
R2: Rright to Left
SCREWS to Bottom
SPEAKER
POWER SOURCE
LED
Audio C4,5,6 B5,6,7
LOGO
USB
MCU
ROTARY ENCODER
R4: Rright to Left
I2C PULL-UP
EEPROM

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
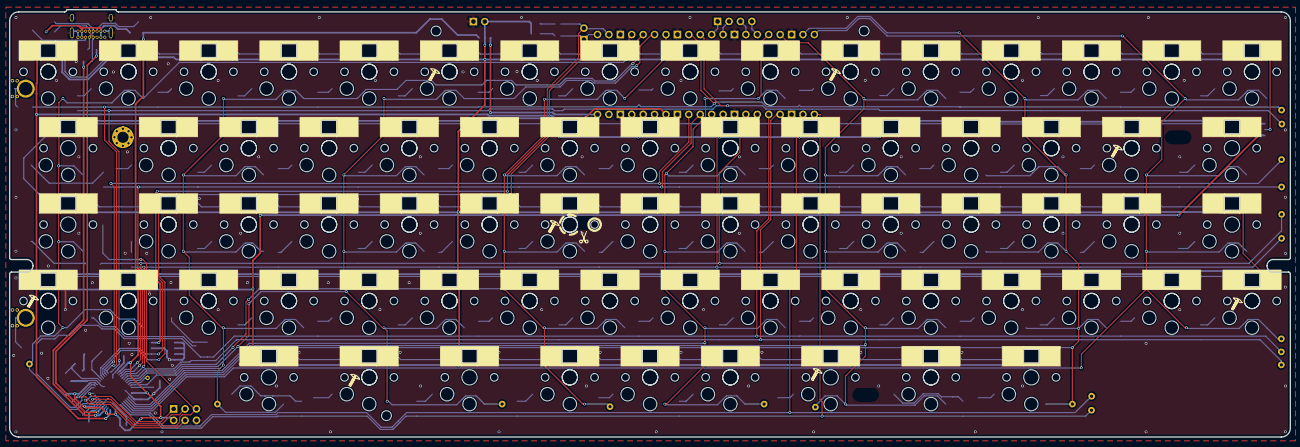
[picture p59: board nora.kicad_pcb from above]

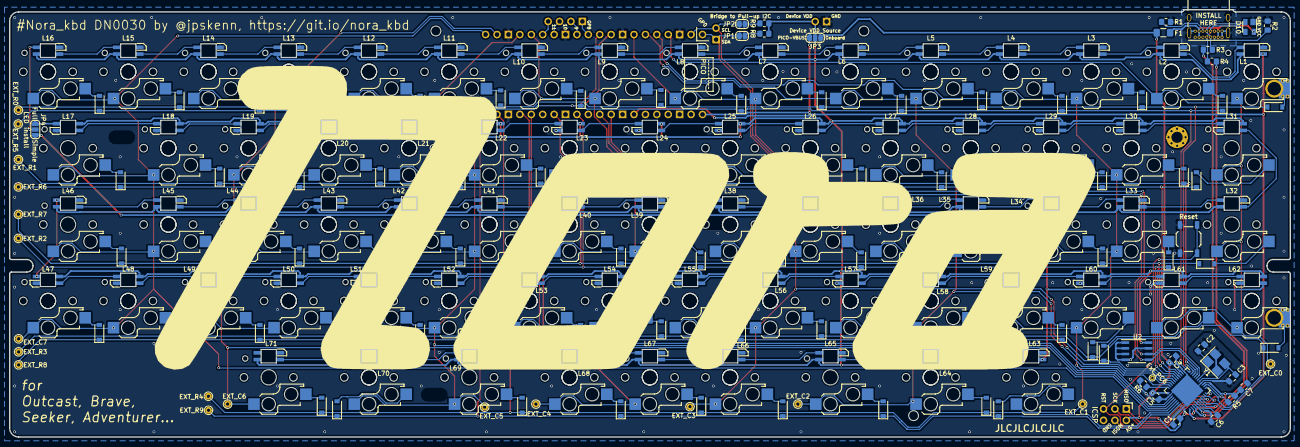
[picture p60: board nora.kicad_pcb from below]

Board: 2 copper layers, 285.0 x 95.1 mm, 266 parts (192 on the bottom side), 189 nets.

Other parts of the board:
D74: D_Small; D_SOD-123-Pretty_No_Reference
Ext_PC6: Conn_01x01; TestPoint_THTPad_D1.0mm_Drill0.5mm

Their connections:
unnamed 80: D74.2; also elsewhere on the board
Reserve_pin: Ext_PC6.1; also elsewhere on the board

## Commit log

2021-11-13 Jonesからコピーして、PCBを作り始めた
    [Jones-2018-12-25-18-22-20.sch, choc_in_60.kicad_pcb, choc_in_60.sch]
2021-11-14 配線途中
    [choc_in_60.kicad_pcb, choc_in_60.sch]
2021-11-15 ファイル名変更と配線途中
    [nora.kicad_pcb, nora.sch]
2021-11-16 配線つなぎ終わりだけど、つないだだけ状態
    [nora.kicad_pcb, nora.sch]
2021-11-17 ロゴ追加
    [nora.kicad_pcb, nora.sch]
2021-11-17 GNDベタをひとまず作成。細かいところはまだ
    [nora.kicad_pcb]
2021-11-17 GNDベタ、細かいところまで完了。
    [nora.kicad_pcb]
2021-11-17 ロゴ調整
    [nora.kicad_pcb]
2021-11-17 不要ガイドライン削除
    [nora.kicad_pcb]
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2021-11-18 メモ追加
    [memo.xlsx.xlsx]
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2021-11-18 スイッチプレートのKiCadデータをJonesから流用
    [keyplate.kicad_pcb, keyplate.sch]
2021-11-18 スイッチのMill-Maxソケット対応
    [nora.kicad_pcb, nora.sch]
2021-11-19 Mill-Maxソケットの半田付け練習用を追加
    [nora.kicad_pcb, nora.sch]
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2021-11-19 プレートの外形を基板に作成
    [keyplate.kicad_pcb, plate.dxf]
2021-11-20 たいして内容が無いため削除
    [memo.xlsx.xlsx]
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2021-11-20 SWプレートにパターンを追加
    [keyplate.kicad_pcb]
2021-11-20 基板とSWプレートの製造データを用意
    [keyplate-B_Cu.gbl, keyplate-B_Mask.gbs, keyplate-B_Paste.gbp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]
2021-11-20 発注関連のファイルを移動
    [nora_BOM.csv]
2021-11-20 PICO対応
    [nora-B_Cu.gbl, nora-B_Fab.gbr, nora-B_Mask.gbs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]
2021-11-20 LED電源ソースの選択ジャンパにシルク追加
    [nora-B_Cu.gbl, nora-B_Fab.gbr, nora-B_Mask.gbs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]
2021-11-21 USBコネクタの3Dモデルを追加
    [nora.kicad_pcb]
2021-11-21 LEDの3Dモデルを追加
    [LED_SK6812MINI-E.step, nora.kicad_pcb]
2021-11-21 Choc v1の3Dモデルを追加
    [nora.kicad_pcb]
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2021-11-25 章構成修正
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2021-12-01 ピンヘッダの3Dモデルを削除
    [nora.kicad_pcb]
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2021-12-03 リンク修正
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2021-12-04 キーピッチのメモを追加
    [nora.kicad_pcb]
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2021-12-05 画像リンク修正
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2021-12-05 誤記修正、PICO用ファームウェアについて追記
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2021-12-08 Remove ATmega32u4-AU
    Just remove only.
    Wireing is not modified.
    It should be modified by other Issue, like changing SW footprint.
    [nora.kicad_pcb, nora.sch]
2021-12-08 FULL hotswap socket support Fixes #1
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2021-12-08 WIP パーツ配置
    [nora.kicad_pcb, nora.sch]
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2021-12-09 WIP パーツ配置。Dの配置と配線に取り掛かる。
    [nora.kicad_pcb]
2021-12-09 WIP パーツ配置。Dの配置一旦完了。EEPROM配置中。
    [nora.kicad_pcb]
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2021-12-09 WIP パーツ配置。EEPROM配置中。
    [nora.kicad_pcb]
2021-12-10 WIP EEPROM、I2C、とりあえず完了
    [nora.kicad_pcb, nora.sch]
2021-12-10 WIP 怪しそうなところを配線中
    [nora.kicad_pcb, nora.sch]
2021-12-10 ソケット化と、関連するパーツの配置と配線に目処が立つ#1
    FULL hotswap socket support
    Fixes #1
    [nora.kicad_pcb, nora.sch]
2021-12-10 Full RGB LED backlight Fixes #3
2021-12-10 WIP 回路図へLED追加。とりあえずPCBへ配置
    [nora.kicad_pcb, nora.sch]
2021-12-10 R5へのLED配置、配線完了#3 Full RGB LED backlight Fixes #3
    [nora.kicad_pcb]
2021-12-10 パスコンを、なるべくMCUに近づける Fixes #25
2021-12-10 パスコンとRを入れ替えて、パスコンをMCUに近づけた#25
    [nora.kicad_pcb]
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2021-12-10 中央、右上のネジ穴にかぶるスイッチにシルクを追加#14
    [nora.kicad_pcb]
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2021-12-11 URL added.#20
    [nora.kicad_pcb]
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2021-12-11 Update and Change version information.#18#21
    [keyplate.kicad_pcb, nora.kicad_pcb, nora.sch]
2021-12-11 WIP 配線
    [nora.kicad_pcb]
2021-12-11 WIP シルク重なり対応
    [nora.kicad_pcb]
2021-12-11 WIP ロゴ配置調整中
    H61.3ｍｍ
    [nora.kicad_pcb]
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2021-12-11 ロゴ配置
    [nora.kicad_pcb]
2021-12-11 ロゴ配置完了, Renew logo on PCB #11
    [nora.kicad_pcb, nora.sch]
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2021-12-11 シルク位置調整#13
    [nora.kicad_pcb]
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2021-12-12 LED光を反射するペイントを追加#32
    [nora.kicad_pcb, nora.sch]
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2021-12-12 配線からネジ穴を離した#15
    [nora.kicad_pcb]
2021-12-12 VIA穴追加, via holes #30
    [nora.kicad_pcb]
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2021-12-12 カーソル”上”へLED追加#35
    [nora.kicad_pcb, nora.sch]
2021-12-12 Shorten right side frame over screw hole on SW plate Fixes #10
2021-12-12 右のネジ穴にかかるフレームを1mm短縮#10
    KiCadにインポートすると線を引き直す手間がかかるため、
    既存のデータで1mm短縮した。
    [keyplate.kicad_pcb, plate.dxf]
2021-12-12 小さな指標を追加#5
    [keyplate.kicad_pcb]
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2021-12-12 貼り付け箇所を描画した#6
    [keyplate.kicad_pcb]
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2021-12-12 ネジにかぶるスイッチに、ネジアイコンを表示#39
    [nora.kicad_pcb]
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2021-12-13 イラストパターン更新#8 ネジの上のスイッチ指標修正#5
    [keyplate.kicad_pcb]
2021-12-13 製造ファイル準備
    [keyplate-B_Cu.gbl, keyplate-B_Mask.gbs, keyplate-B_Paste.gbp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]
2021-12-13 WIP パッド強化したフットプリントを作成中
    [nora.kicad_pcb]
2021-12-14 パッド強化したフットプリントに変更し、LEDを上側にもってきた
    [nora.kicad_pcb, nora.sch]
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2021-12-14 上下反転アイコンを追加した#44
    [nora.kicad_pcb]
2021-12-14 シルク位置、パーツ位置調整
    [nora.kicad_pcb]
2021-12-16 remove unused screw access hole from SW plate #46
    [keyplate.kicad_pcb]
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2021-12-16 PICO時、EEPROMの電源をPICO-VBUSからとる#47#16
    [nora.kicad_pcb, nora.sch]
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2021-12-16 WIP Jonesからボトムプレートを持ってきて、PICO穴をあけてる
    [Nora_plate_bottom.kicad_pcb, Nora_plate_bottom.sch]
2021-12-17 切り取り可能なプレートが必要だが、一旦ここまでとする。
    [Nora_plate_bottom.kicad_pcb]
2021-12-17 WIP マトリクス再編成、スイッチ配置
    [nora.kicad_pcb, nora.sch]
2021-12-18 WIP 配線途中
    [nora.kicad_pcb, nora.sch]
2021-12-18 WIP VIA打ち始め
    [nora.kicad_pcb]
2021-12-18 WIP 配線引き終わり
    [nora.kicad_pcb]
2021-12-18 WIP ダイオードに3Dモデル追加
    [nora.kicad_pcb]
2021-12-18 WIP PCOひとまず完了
    [nora.kicad_pcb, nora.sch]
2021-12-18 WIP 不要表示物削除
    [nora.kicad_pcb]
2021-12-18 WIP 表示レイヤーを変更
    [nora.kicad_pcb]
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2021-12-18 プレート作成
    [keyplate-B_Cu.gbl, keyplate-B_Mask.gbs, keyplate-B_Paste.gbp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]
2021-12-18 WIP ボトムプレートに切り取りをつけようとしている
    [Nora_plate_bottom.kicad_pcb]
2021-12-18 WIP ボトムプレートに切り取りをつけ、さらに改造中
    [Nora_plate_bottom.kicad_pcb]
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2021-12-19 シルク位置ずれ修正
    [nora.kicad_pcb]
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2021-12-30 WIP DRCエラーなどに対処中
    LEDとSWのフットプリントで、シルク欠けに対応するものへ変更中。
    LEDは上下反転するため、SWのクリックバー穴の処理をどうするか？
    [nora.kicad_sch]
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2022-01-01 サイズ記載ミス修正
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2022-01-02 Expand LED hole #63
    製造の状況によってLED穴がきついことがあるため、余裕を持った穴サイズへ拡大。
    [nora.kicad_sch]
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2022-01-02 Enlarge SW sub-hole? #68
    1.7mmから1.8mmへ、5ピンの穴サイズを拡大
    [nora.kicad_sch]
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2022-01-03 move LED reflection silk from LED to SW footprint #74
    [nora.kicad_sch]
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2022-01-07 LEDのパッドが短くなっていたのを修正
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2022-01-08 #76 Tight? SW plate
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2022-01-10 ロータリーエンコーダが接続されるマトリクス行を変更
    物理的にREが配置される場所に合わせた行へ修正。
    [nora.kicad_sch]
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2022-01-11 FW-PCB: Add jumper to skip LEDs with FW+RE layout #85
    [nora.kicad_sch]
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2022-01-11 ゴム足マーキングを変更 #83
    - 上（奥）の中央、PICOの切り取りより手前に追加
    - 上、PICOの切り取りの左右を、実線から点線に変更
    [Nora_plate_bottom.kicad_pcb]
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2022-01-12 ケース固定まで修正
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2022-01-12 REノブのサイズ指標円の中心が、REの中心とずれていたのを修正
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2022-01-28 REとFWで異なるソケットの配置をわかりやすくした #109
    最下段中央REのソケット
    斜線パターン
    RE→○
    R3中央REのソケット
    クロスパターン
    RE→×
    [nora.kicad_sch]
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2022-01-29 C1のパーツ番号を変更 #96
    同じ部品だと思うのだが、以前の番号のものはExtend Partsになっている。
    [nora.kicad_sch]
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2022-01-31 軽微な表現修正
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2022-02-05 リンク間違い修正
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2022-02-13 キャプション間違いを修正
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2022-03-15 体裁修正、メモ追加
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2022-04-14 キーマップ修正
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2022-04-19 手順を修正
    ファームウェアの書き換えを、
    ”キーボード”として組み上げてから行うことも想定。
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2022-04-22 スペーサー必要数の間違いを修正
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2022-05-09 リンクミス、キャプション修正
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2022-05-09 ファイル名Typo修正
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2022-05-11 キャプション修正
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2022-05-12 重複した説明を修正
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
